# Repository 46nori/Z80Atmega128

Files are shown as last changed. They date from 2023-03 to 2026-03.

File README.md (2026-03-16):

# Z80ATmega128

[日本語版READMEはこちら](./README-ja.md)

## Overview

This project aims to build a Z80A system and run CP/M-80 natively on it.

You might be wondering why I chose the Z80 today. Well, it happened to be discovered in my collection of electronic components after being tucked away for 30 years. Moreover, it's an original Zilog Z80A from the NMOS process era, likely manufactured around 1980!  

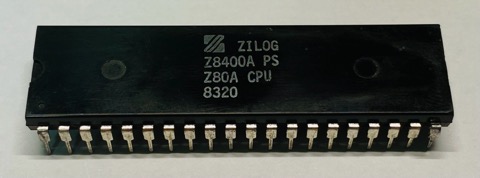
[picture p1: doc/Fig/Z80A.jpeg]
z80a
  

However, rather than simply replicating a single-board microcontroller system from the 1980s, I've decided to take a different approach. Reproducing such a system lacks novelty and excitement, not to mention the difficulty of sourcing the necessary parts.

Hence, I've devised the following design principles:

1. A hybrid configuration utilizing both [Z80A](https://www.zilog.com/docs/z80/um0080.pdf) and [ATmega128-16AU](https://www.microchip.com/en-us/product/ATmega128) (AVR) microcontrollers.
2. I won't be using ROM; instead, a 64KB SRAM will be shared between the Z80A and AVR. AVR will manage the placement of the Z80's bootstrap code.
3. AVR firmware will handle the Z80 hardware I/O and interrupt cycles completely. **Any Z80's I/O devices can, in principle, be described by software!**
4. Design circuits using components that are as easy to procure as possible. (As of 2023, mainly in the Japanese electronic parts market.)

## Achievements

* CP/M 2.2 works directly on the Z80 processor.
* The system can boot CP/M from a microSD card containing the CP/M image file.
* CP/M 3 (Non-banked memory version) works as well.
* You can enjoy playing the text adventure game ZORK I, II and III !
* The printed circuit board (PCB) is available.
* Demo Video  
  video (https://youtu.be/2_RJPk65XRE)

## Contents

```text
.
├── avr                      AVR firmware
├── z80                      Z80 software
│   ├── cpm22                CP/M-80 Ver2.2
│   │   ├── bios               BIOS
│   │   ├── sys                CPM.SYS(CCP/BDOS) and cpm.ihx(IPL+CCP/BDOS+BIOS)
│   │   └── image              CP/M 2.2 Disk image
│   └── cpm3                 CP/M 3 (CP/M Plus)
│       └── image              CP/M 3 Disk image
├── doc
│   ├── Hardware/            Hardware documents
│   ├── Software/            Software documents
│   └── README.md            Table of contents
└── schematics
    └── KiCad
        ├── *.kicad_sch      Schematic diagram
        └── *.kicad_pcb      PCB diagram
```

* [Document](doc/README.md)
  * [Z80ATmega128 Board Setup Guide](doc/SetupGuide_en.md)
  * [Hardware design document](doc/Hardware/Design.md)
* [Development log](doc/Diary.md)

## Required tools

* [Microchip Studio](https://www.microchip.com/en-us/tools-resources/develop/microchip-studio) for AVR v7.0 or later is required to build avr/.
* [AVRISP mkII](https://www.microchip.com/en-us/development-tool/ATAVRISP2) is required to program software(avr/) into ATmega128.
* Schematics and PCB are designed by [KiCad](https://www.kicad.org/) v7.0.
* [ASxxxx Cross Assemblers](https://shop-pdp.net/ashtml/asxxxx.php) to build the CP/M BIOS in z80/.
* [cpmtools](https://github.com/lipro-cpm4l/cpmtools) for creating CP/M disk images.

## Prototype

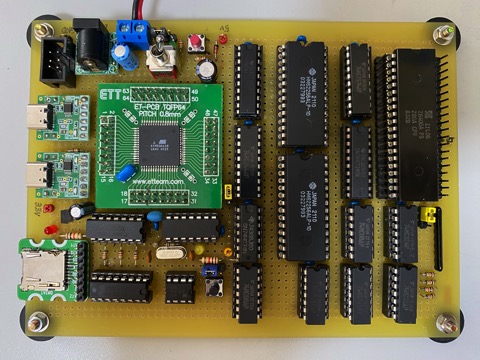
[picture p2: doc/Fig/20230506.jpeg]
prototype
  

## PCB

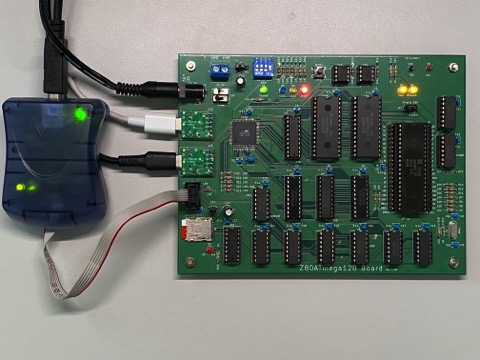
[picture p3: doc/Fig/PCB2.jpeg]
pcb2
    
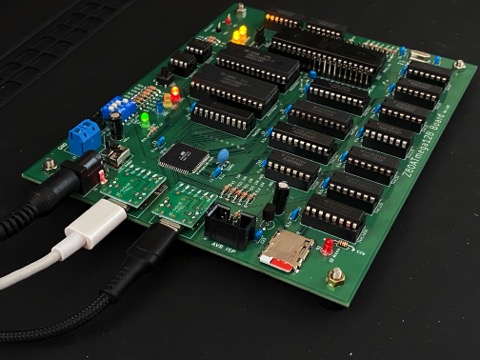
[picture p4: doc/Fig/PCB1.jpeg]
pcb1
    

## Schematic diagram

sch1
sch2
sch3
sch4

## License

GPLv3

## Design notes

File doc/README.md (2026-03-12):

# Documents

## User's Guide

- Z80ATmega128 Board Setup Guide ([English](./SetupGuide_en.md) / [Japanese](./SetupGuide.md))
- How to make CP/M2.2 disk image ([English](./DiskImage-CPM22.md) / [Japanese](./DiskImage-CPM22-ja.md))
- How to make CP/M3 (CP/M Plus) disk image ([English](../z80/cpm3/image/README.md) / [Japanese](../z80/cpm3/image/README-ja.md))
- ATmega128 Tiny Monitor Command Reference ([English](./Software/AVRTinyMonitor.md))

## Hardware Specifications

- Z80ATmega128 Board Hardware Specification ([Japanese](./Hardware/Design.md))
- Hardware Release Note ([English](./Hardware/HW-ReleaseNote.md) / [Japanese](./Hardware/HW-ReleaseNote-ja.md))

## Software Specifications

- Emulated external I/O device specification ([English](./Software/EmulatedDeviceSpec.md) / [Japanese](./Software/EmulatedDeviceSpec.md#port-japanese))
- CCP/M 2.2 BIOS design Spacification ([English](./Software/BIOSDesignSpec.md) / [Japanese](./Software/BIOSDesignSpec-ja.md))

## Design Memo

- CP/M DISK Parameters ([Japanese](./Software/DiskParameters.md))
- PCB Design memo of KiCad ([Japanese](./Hardware/PCB/KiCad-PCB.md))

## Developement Log (Japanese)

- [Summary of progress](./Progress.md)
- [2023/02/25 - 2023/07/04](./Diary.md)
- [2023/07/07 - 2023/10/22](./Diary2.md)
- [2023/10/23 - 2023/12/28](./Diary3.md)
- [2024/01/15 -](./Diary4.md)

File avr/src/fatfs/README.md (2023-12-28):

# FatFs - Generic FAT Filesystem Module
- http://elm-chan.org/fsw/ff/

## FatFs R0.15 w/patch3
- [ff15.zip](http://elm-chan.org/fsw/ff/arc/ff15.zip)
- [Patches](http://elm-chan.org/fsw/ff/patches.html)

## FatFs sample
Imported `mmc_avr.h` and `mmc_avr_spi.c` from [ffsample.zip](http://elm-chan.org/fsw/ff/ffsample.zip).

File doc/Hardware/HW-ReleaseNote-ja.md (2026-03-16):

# Hardware Release Note

----

## Rev 1.00

- Initial Release
- Errata
  - [Front Plane](./PCB/PCB1.0-FP-Errata.pdf)
    - Pattern cut 7
  - [Back Plane](./PCB/PCB1.0-BP-Errata.pdf)
    - Pattern cut 1
    - Patch 6

----

## Rev 2.00

### Schematics

- Z80ATmega128.kicad_sch
  - ATmega128に設定したラベルが、Z80のラベル`/WR`,`/RD`と衝突しており、PCB上で意図しない接続が発生していたため、以下のようにラベル名を変更。

    | PIN | Rev1.00| Rev2.00 |
    |:---:|--------|---------|
    |  33 |  /WR   | /AVR_WR |
    |  34 |  /RD   | /AVR_RD |
    |  43 |  ALE   | AVR_ALE |

- ExtIO_sch.kicad_sch
  - LED1/2/3のドライブ用素子(74HC32)の入力を10Kでプルアップ
  - /HALT,/BUSACKのドライブ用素子(74HC04, 74HC125)の入力を10Kでプルアップ
  - リセット時やATmega128のファームウェアが動作していないときの入力が不安定になるのを修正

### PCB

- R1(10K)の位置を変更。AVRICPの6pinボックスヘッダとのクリアランスが取れていなかったため。
- POWER Switch(2回路3接点トグルスイッチ)のランドピッチが間違っていたのを修正。
- USBシリアル変換基板(AE-CH340E-TYPEC)のFootprintを変更し、ピン配置を逆転させた。Rev1.00では変換基板を裏返しに設置していた。
- Errata
  - U18, U19のUARTのシルクが間違っている。
    - [誤]

      ```text
       o   o   o   o   o   o
          RX  TX  5V      GND
      ```

    - [正]

      ```text
       o   o   o   o   o   o
      GND     5V  TX  RX
      ```

----

## Rev 2.10

### PCB

- Rev 2.00のErrataの修正
- DIP SWの説明
  - SW3をSD CardのWrite Protectに割り当て
- 一部シルクを白抜き表示に変更

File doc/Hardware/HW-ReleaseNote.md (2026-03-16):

# Hardware Release Note

----

## Rev 1.00

- Initial Release
- Errata
  - [Front Plane](./PCB/PCB1.0-FP-Errata.pdf)
    - Pattern cut 7
  - [Back Plane](./PCB/PCB1.0-BP-Errata.pdf)
    - Pattern cut 1
    - Patch 6

----

## Rev 2.00

### Schematics

- Z80ATmega128.kicad_sch
  - The local labels `/WR`, `/RD` for ATmega128 conflicted with the Z80's `/WR`, `/RD`, causing unintended connections on the PCB, so the label name was changed as shown below.

    | PIN | Rev1.00| Rev2.00 |
    |:---:|--------|---------|
    |  33 |  /WR   | /AVR_WR |
    |  34 |  /RD   | /AVR_RD |
    |  43 |  ALE   | AVR_ALE |

- ExtIO_sch.kicad_sch
  - Pull up with 10K the input of 74HC32 for driving LED1/2/3.
  - Pull up with 10K the input of 74HC04 and 74HC125 for driving  LED /HALT and /BUSACK.
  - Fixed input being unstable at reset or when ATmega128 firmware is not running

### PCB

- Changed the position of R1(10K), because there are no space between the 6-pin box header of AVRICP and R1.
- Modified the land pitch of POWER Switch (2-circuit 3-contact toggle switch).
- Changed the footprint of USB serial converter board (AE-CH340E-TPPEC) and reversed the pin assignment.
- Errata
  - The silk printing of U18 and U19 are incorrect.
    - [Incorrect]

      ```text
       o   o   o   o   o   o
          RX  TX  5V      GND
      ```

    - [Correct]

      ```text
       o   o   o   o   o   o
      GND     5V  TX  RX
      ```

----

## Rev 2.10

### PCB

- Fixed Rev 2.00 Errata.
- Description of DIP SW.
  - Assigned SW3 to SD Card Write Protect.
- Changed some silk to white outline.

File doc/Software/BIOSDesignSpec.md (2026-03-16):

# CP/M BIOS Design Specification

## Overview

- 62KB BIOS
- Written in Z80 mnemonic
- Mode2 interrupt
- CON: is supported. LST:, PUN: and RDR: are not supported.
- DISK I/O
  - 5 drives (A: to E:) is supported.
  - Blocking and Deblocking is suppotred.

## Boot Sequence

AVR firmware behaves as below at power-on reset.

1. CP/M boot sequence is triggered if DIPSW-1 is ON and the microSD Card is mounted.
2. Read EntryAddress and Length from EEPROM. (1)
3. Set `JP EntryAddress` to 0x0000 of SRAM. (2)
4. Copy BIOS on EEPROM to EntryAddress. (3)
5. Resaet Z80.
6. Start TinyMonitor.

Z80 launches CP/M as follows:

1. Start BIOS.
2. BIOS BOOT routine requests DISK READ to AVR in order to download CCP+BDOS from EntryAddress.  
   AVR reads CCP+BDOS from Track 0 on the microSD Card and copies it to SRAM.
3. BIOS BOOT routine launches CCP.

boot

## BOOT and WBOOT

Both routine loads CP/M(CCP+BDOS) from A: using the DISK READ routine. If loading was a failure, then halt the system. The difference between BOOT and WBOOT is as follows.

### BOOT

- Called only at power-on reset.
- Z80 interrupt settings, Emulated I/O device initialization.
- Set initial drive to A:.
- Start CCP from CCP+3.

### WBOOT

- Restore the drive previously being utilized.
- Start CCP from CCP+0.

## DISK I/O

The logical tracks and sectors specified by BDOS are converted into absolute sector numbers. The definition of absolute sector is as follows.
`TRK` and `SEC` shall be set in advance with the BIOS calls `SETTRK` and `SETSEC`, respectively. Also, `SPT` is a value defined by DPB (Disk Parameter Block).

- Logical track number: `TRK`
- Logical sector number: `SCT`
- Number of sectors per logical track: `SPT`
- Absolute sector number: `AS` = TRK * SPT + SCT

A 512-byte buffer (`DMABUF`) is reserved on SRAM for data sharing with AVR and is used exclusively by `READ` and `WRITE` BIOS calls. Since the logical sector length of CP/M is 128 bytes, it supports Blocking/Deblocking for four sectors, that is, Blocking Factor=4.

### READ

When a READ request is received, it checks whether the specified sector exists in `DMABUF`.
If it exists, copy that sector to `DMA_ADRS`.
If it does not exist, request AVR to read 512 bytes. Copy the first 128 bytes (1 sector) to `DMA_ADRS`. The remaining three sectors are saved as a read-ahead cache.

### WRITE

Emulated DISK I/O on AVR allows writing to a disk image file by specifying an arbitrary address and data length. However, microSD cards require writing in 512-byte units from 512-byte sector boundaries, so if the boundaries do not match or the data length is not a multiple of 512, Read/Modify/Write is required.
This causes a noticeable write performance reduction, so the BIOS manages the timing of buffers and buffer flushes (write requests to AVR) to write 512 bytes from the 512-byte boundary as much as possible.

When a WRITE request is received, the data is copied to the `IDX` location defined below.

- Location of stored buffer: IDX = AS % 4

  ```text
        +----------+
  IDX=0 | 128bytes |
        +----------+
  IDX=1 | 128bytes |
        +----------+
  IDX=2 | 128bytes |
        +----------+
  IDX=3 | 128bytes |
        +----------+
  ```

If this is **the first** WRITE request after flushing the buffer, also remember `IDX` and `image file write destination address`. This will be used during the next buffer flush.

The caller of the WRITE request sets the following Deblocking Code in the C register.

- C = 0: deferred write
- C = 1: nondeferred write
- C = 2: deferred write to the first sector of a new data block

If any or both of the following conditions are met, flush the buffer. Otherwise, increment the number of cached sectors (0-3) and return.

- C=1
- IDX=3

When flushing the buffer, write `the number of cached sectors x 128 bytes` from the stored `IDX` to the `image file write destination address`.

### SELDSK

Emulated DISK I/O switches the accessed disk image to that of the specified drive.

### SETTRK

Just save the logical track number in `CURRENT_TRACK_NO`. It will be used in the next READ/WRITE.

### SETSEC

Just save the logical sector number in `CURRENT_SECTOR_NO`. It will be used in the next READ/WRITE.

### SERDMA

Just save the data transfer address in `DMA_ADRS`. It will be used in the next READ/WRITE.

### SECTRN

It is not supported since interleave is unnecessary for accessing microSD Cards.

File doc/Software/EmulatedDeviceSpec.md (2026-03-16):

# Emulated external I/O device specification

## Port (English)

| Port | Direction | Function | Value |
| ---- | --- | --- | --- |
| 0x00 | IN | Input single character from Console | Input character |
| 0x00 | OUT | Undefined | |
| 0x01 | IN | Get Console Input Buffer status | Unread characters count in Buffer |
| 0x01 | OUT | Undefined | |
| 0x02 | IN | Get Console Input Buffer size | Buffer size |
| 0x02 | OUT | Flush Console Input Buffer | |
| 0x03 | IN | Get Console input interrupt level | Interrupt level |
| 0x03 | OUT | Set Console input interrupt level | 0-127: Mode2 INT level<br>Other: No interrupt |
| 0x04 | IN | Undefined | |
| 0x04 | OUT | Undefined | |
| 0x05 | IN | Undefined | |
| 0x05 | OUT | Output single character to Console | Output character |
| 0x06 | IN | Get Console Output Buffer status | Remaining character count in Buffer  |
| 0x06 | OUT | Undefined | |
| 0x07 | IN | Get Console output Buffer size | Buffer size |
| 0x07 | OUT | Flush Console Output Buffer | |
| 0x08 | IN | Get Console Output interrupt level | Interrupt level |
| 0x08 | OUT | Set Console Output interrupt level | 0-127: Mode2 INT level<br>Other: No interrupt |
| 0x09 | IN | Undefined | |
| 0x09 | OUT | Undefined | |
| 0x0a | IN | Get selected DISK | Currently selected DISK number |
| 0x0a | OUT | Get Selected DISK status | 0: Success / 1: Error |
| 0x0b | IN | Get DISK WRITE Position | Physical WRITE position and reset sequencer |
| 0x0b | OUT | Set DISK WRITE Position | Physical WRITE position |
| 0x0c | IN | Get DISK WRITE Buffer address | Buffer address and reset sequencer |
| 0x0c | OUT | Set DISK WRITE Buffer address | Buffer address |
| 0x0d | IN | Get DISK WRITE Buffer length | Data length and reset sequencer |
| 0x0d | OUT | Set DISK WRITE Buffer length | Data length |
| 0x0e | IN | Get DISK WRITE status | Bit 0: Completed(0) / Writing(1)<br>Bit 1: Success(0) / Error(1) |
| 0x0e | OUT | Execute DISK WRITE | |
| 0x0f | IN | Get DISK WRITE interrupt level | Interrupt level |
| 0x0f | OUT | Set DISK WRITE interrupt level | 0-127: Mode2 INT level<br>Other: No interrupt |
| 0x10 | IN | Get DISK WRITE Position | Physical READ position and reset sequencer |
| 0x10 | OUT | Set DISK WRITE Position | Physical READ position |
| 0x11 | IN | Get DISK READ Buffer address | Buffer addreess and reset sequencer  |
| 0x11 | OUT | Set DISK READ Buffer address | Buffer addreess |
| 0x12 | IN | Get DISK READ Buffer length | Data length and reset sequencer |
| 0x12 | OUT | Set DISK READ Buffer length | Data length |
| 0x13 | IN | Get DISK READ status | Bit 0: Completed(0) / Reading(1)<br>Bit 1: Success(0) / Error(1) |
| 0x13 | OUT | Execute DISK READ | 0-127: Mode2 INT level<br>Other: No interrupt |
| 0x14 | IN | Get DISK READ interrupt level | Interrupt level |
| 0x14 | OUT | Set DISK READ interrupt level | 0-127: Mode2 INT level<br>Other: No interrupt |
| 0x15 | IN | Undefined | |
| 0x15 | OUT | Undefined | |
| 0x16 | IN | Undefined | |
| 0x16 | OUT | Undefined | |
| 0x17 | IN | Undefined | |
| 0x17 | OUT | Undefined | |
| 0x18 | IN | Undefined | |
| 0x18 | OUT | Undefined | |
| 0x19 | IN | Undefined | |
| 0x19 | OUT | Undefined | |
| 0x1a | IN | Undefined | |
| 0x1a | OUT | Undefined | |
| 0x1b | IN | Undefined | |
| 0x1b | OUT | Undefined | |
| 0x1c | IN | Undefined | |
| 0x1c | OUT | Undefined | |
| 0x1d | IN | Get interrupt level for resumption from the breakpoint | Interrupt level |
| 0x1d | OUT | Set interrupt level for resumption from the breakpoint | 0-127: Mode2 INT level<br>Other: No interrupt |
| 0x1e | IN | Reset sequencer | Reset sequencer and wait 1st byte |
| 0x1e | OUT | Send debug info | Send debug info(breakpoint, registers and stack data) |
| 0x1f | IN | Get LED Status | bit 0: LED0 OFF(0) / ON(1)<br>bit 1: LED1 OFF(0) / ON(1)<br>bit 2: LED2 OFF(0) / ON(1) |
| 0x1f | OUT | Set LED | bit 0: LED0 OFF(0) / ON(1)<br>bit 1: LED1 OFF(0) / ON(1)<br>bit 2: LED2 OFF(0) / ON(1) |

From 0x20 onwards, it becomes a shadow area for 0x00-0x1f.

---

## Port (Japanese)

|Port|Direction|Function|Value|
|:----|:----|:----|:----|
|0x00|IN |コンソール1文字入力|入力文字|
|0x00|OUT|未定義||
|0x01|IN |コンソール入力バッファステータス取得|未入力文字数|
|0x01|OUT|未定義||
|0x02|IN |コンソールバッファサイズ取得|バッファサイズ|
|0x02|OUT|コンソール入力バッファフラッシュ||
|0x03|IN |コンソール入力割り込みレベル取得|割り込みレベル|
|0x03|OUT|コンソール入力割り込みレベル設定|0-127: Mode2割り込みレベル<br>それ以外: 割り込み禁止|
|0x04|IN |未定義||
|0x04|OUT|未定義||
|0x05|IN |未定義||
|0x05|OUT|コンソール1文字出力|出力文字|
|0x06|IN |コンソール出力バッファステータス取得|未出力文字数|
|0x06|OUT|未定義||
|0x07|IN |コンソール出力バッファサイズ取得|バッファサイズ|
|0x07|OUT|コンソール出力バッファフラッシュ||
|0x08|IN |コンソール出力エンプティ割り込みレベル設定|0-127: Mode2割り込みレベル<br>それ以外: 割り込み禁止|
|0x08|OUT|コンソール出力エンプティ割り込みレベル取得|割り込みレベル|
|0x09|IN |未定義||
|0x09|OUT|未定義||
|0x0a|IN|DISK選択ステータス|成功(0) / エラー(1)|
|0x0a|OUT|DISK選択|0-15: DISK番号|
|0x0b|IN|DISKライト物理位置参照・シーケンサーリセット|ライト位置|
|0x0b|OUT|DISKライト物理位置指定|ライト位置|
|0x0c|IN|DISKライトバッファアドレス参照・シーケンサーリセット|バッファアドレス|
|0x0c|OUT|DISKライトバッファアドレス設定|バッファアドレス|
|0x0d|IN|DISKライトバッファ長参照・シーケンサーリセット|長さ|
|0x0d|OUT|DISKライトバッファ長設定|長さ|
|0x0e|IN|DISKライトステータス|Bit0: 完了(0) / ライト中(1)<br>Bit1: 成功(0) / エラー(1)|
|0x0e|OUT|DISKライト実行||
|0x0f|IN |DISKライト完了割り込みレベル設定|0-127: Mode2割り込みレベル<br>それ以外: 割り込み禁止|
|0x0f|OUT|DISKライト完了割り込みレベル取得|割り込みレベル|
|0x10|IN|DISKリード物理位置参照・シーケンサーリセット|リード位置|
|0x10|OUT|DISKリード物理位置指定|リード位置|
|0x11|IN|DISKリードバッファアドレス参照・シーケンサーリセット|バッファアドレス|
|0x11|OUT|DISKリードバッファアドレス設定|バッファアドレス|
|0x12|IN|DISKリードバッファ長参照・シーケンサーリセット|長さ|
|0x12|OUT|DISKリードバッファ長設定|長さ|
|0x13|IN|DISKリードステータス|Bit0: 完了(0) / リード中(1)<br>Bit1: 成功(0) / エラー(1)|
|0x13|OUT|DISKリード実行||
|0x14|IN |DISKリード完了割り込みレベル取得|割り込みレベル|
|0x14|OUT|DISKリード完了割り込みレベル設定|0-127: Mode2割り込みレベル<br>それ以外: 割り込み禁止|
|0x15|IN |未定義||
|0x15|OUT|未定義||
|0x16|IN |未定義||
|0x16|OUT|未定義||
|0x17|IN |未定義||
|0x17|OUT|未定義||
|0x18|IN |未定義||
|0x18|OUT|未定義||
|0x19|IN |未定義||
|0x19|OUT|未定義||
|0x1a|IN |未定義||
|0x1a|OUT|未定義||
|0x1b|IN |未定義||
|0x1b|OUT|未定義||
|0x1c|IN |未定義||
|0x1c|OUT|未定義||
|0x1d|IN|ブレークポイント復帰割り込みレベル取得|割り込みレベル|
|0x1d|OUT|ブレークポイント復帰割り込みレベル設定|0-127: Mode2割り込みレベル<br>それ以外: 割り込み禁止|
|0x1e|IN|デバッグ情報通知シーケンスリセット|シーケンサーをリセットする。|
|0x1e|OUT|デバッグ情報通知|デバッグ情報(ブレークアドレス/Z80レジスタ/スタックデータ)の通知。デバッグ領域の値を逆順に送る。|
|0x1f|IN |LED点灯状態取得| bit 0: LED0 OFF(0) / ON(1)<br>bit 1: LED1 OFF(0) / ON(1)<br>bit 2: LED2 OFF(0) / ON(1) |
|0x1f|OUT|LED点灯設定| bit 0: LED0 OFF(0) / ON(1)<br>bit 1: LED1 OFF(0) / ON(1)<br>bit 2: LED2 OFF(0) / ON(1) |

- 0x20以降は0x00-0x1fのシャドウエリアとなる。
- 複数バイトが設定できるPORTはシーケンサーを持つ。値をセットする前にシーケンサーをリセットすること。

## Console I/O

### Console Input

AVRはUART1の入力をリングバッファに値を保存しており、Z80からの1文字入力要求があると、このバッファから値を返す。
割り込み設定を行うことで、リングバッファに文字がキューイングされると同時にZ80に割り込みをかけることができる。

- PORT 0x00 コンソール1文字入力
  - **[IN]** バッファリングされている文字を返す。バッファが空の場合は0x00を返す。
- PORT 0x01 コンソール入力バッファステータス取得
  - **[IN]** 入力バッファに残っている文字数を返す。
- PORT 0x02 コンソールバッファサイズ取得
  - **[IN]** 入力バッファのサイズを返す。
- PORT 0x02 コンソール入力バッファフラッシュ
  - **[OUT]** 入力バッファを空にする。
- PORT 0x03 コンソール入力割り込み設定
  - **[OUT]** コンソール入力発生時にZ80にMode2割り込みをかけることができる。0-127を設定するとそのレベルでの割り込みが発生する。128-255に設定すると割り込みは発生しない。デフォルト値は128。
  - **[IN]** 現在の割り込みレベルの値を返す。

### Console Output

- PORT 0x05 コンソール1文字出力
  - **[OUT]** 文字する出力をセットする。
- PORT 0x06 コンソール出力バッファステータス取得
  - **[IN]** まだ出力されずバッファに残っている文字数を返す。
- PORT 0x07
  - **[IN]** 出力バッファのサイズを返す。
  - **[OUT]** 出力バッファを空にする。
- PORT 0x08 コンソール出力割り込み設定
  - **[OUT]** 出力バッファが以下の状態になった時にZ80にMode2割り込みをかけることができる。0-127を設定するとそのレベルでの割り込みが発生する。128-255に設定すると割り込みは発生しない。デフォルト値は128。
    - 未出力データ数が出力バッファサイズの1/2に達した
    - 未出力データ数が出力バッファサイズの1/4に達した
    - 未出力データ数が0になった
  - **[IN]** 現在の割り込みレベルの値を返す。

## DISK I/O

### DISK選択

- PORT 0x0a DISK選択
  - **[IN]** DISK選択結果　成功(0) / エラー(1)
  - **[OUT]** DISK番号(0-15)を選択しアクセス可能にする。指定したDISK番号のイメージファイルDISKxx.IMG (xxはDISK番号)があらかじめ存在していること。

### DISK WRITE

- PORT 0x0b
  - **[IN]** DISKライト位置参照・シーケンサーリセット
  - **[OUT]** DISKライト位置を指定する。Highアドレスの値から4バイト書き込む。
- PORT 0x0c
  - **[IN]** DISKライトバッファアドレス参照・シーケンサーリセット
  - **[OUT]** DISKライトバッファアドレスを指定する。Highアドレスから2バイト書き込む。
- PORT 0x0d
  - **[IN]** DISKライトバッファ長参照・シーケンサーリセット
  - **[OUT]** DISKライトバッファ長を指定する。Highアドレスから2バイト書き込む。
- PORT 0x0e
  - **[OUT]** DISKライト実行
  - **[IN]** DISKライト状態を返す。
    - Bit0: 完了(0) / 実行中(1)
    - Bit1: 成功(0) / エラー(1)
- PORT 0x0f　DISKライト完了割り込み設定
  - **[OUT]** DISKライト完了時にZ80にMode2割り込みをかけることができる。0-127を設定するとそのレベルでの割り込みが発生する。128-255に設定すると割り込みは発生しない。デフォルト値は128。

### DISK READ

- PORT 0x10
  - **[OUT]** DISKリード位置を指定する。Highアドレスから4バイト書き込む。
  - **[IN]** DISKリード位置参照・シーケンサーリセット
- PORT 0x11
  - **[OUT]** DISKリードバッファアドレスを指定する。Highアドレスから2バイト書き込む。
  - **[IN]** DISKリードバッファアドレス参照・シーケンサーリセット
- PORT 0x12
  - **[OUT]** DISKリードバッファ長を指定する。Highアドレスから2バイト書き込む。
  - **[IN]** DISKリードバッファ長参照・シーケンサーリセット
- PORT 0x13
  - **[OUT]** DISKリード実行
  - **[IN]** DISKリード状態を返す。
    - Bit0: 完了(0) / 実行中(1)
    - Bit1: 成功(0) / エラー(1)
- PORT 0x14 DISKリード完了割り込み設定
  - **[OUT]** DISKリード完了時にZ80にMode2割り込みをかけることができる。0-127を設定するとそのレベルでの割り込みが発生する。128-255に設定すると割り込みは発生しない。デフォルト値は128。
  - **[IN]** 現在の割り込みレベルの値を返す。

DISK READ/WRITEの起動はOUT命令の割り込みハンドラで受理される。その起動イベントをREQとする。この割り込みハンドラ内では外部SRAMへのアクセスができないため、SD Cardのアクセスは実行しない。(外部SRAMのアクセスには/BUSREQを有効にする必要があるが、割り込みサイクルでの処理は両立できない。) SD CardへのアクセスおよびSRAMとのデータ転送は、10msの周期割り込みハンドラ内で行う。ここではREAD/WRITE用のステートマシンが順番に実行される。READとWRITEは同時に実行されることはない。

rd.DOINGおよびwr.DOINGでSD CardのアクセスとSRAMとのデータ転送が行われる。エラーでも正常終了でもIDLEに戻る(DONEイベント)。
リードライト要求は、IDLEおよびREJECTED状態で受理される。

- イベント

    |Event| READ          | WRITE          |
    |-----|---------------|----------------|
    | REQ | READ実行(0x13) | WRITE実行(0x0e)|
    | DONE| READ完了       | WRITE完了      |
    | INT | 周期割り込み    | 周期割り込み     |

- 状態

    |State     | READ                    | WRITE 　　　　　　　　　　　|
    |----------|-------------------------|-------------------------|
    |IDLE      | READ要求待ち。           | WRITE要求待ち。            |
    |REQUESTING| READ実行待ち。           | WRITE実行待ち。            |
    |DOING     | READ実行中。             | WRITE実行中。             |
    |REJECTED  | 要求拒否。次のREAD要求待ち。| 要求拒否。次のWRITE要求待ち。|

- ステートチャート

    ```mermaid
    stateDiagram-v2
        state READ {
            [*]            --> rd.IDLE
            rd.IDLE　      --> rd.REQUESTING: REQ
            rd.IDLE　      --> rd.IDLE: INT
            rd.REQUESTING  --> rd.DOING : INT
            rd.REQUESTING  --> rd.REJECTED : REQ
            rd.REQUESTING  --> rd.REQUESTING : INT
            rd.DOING       --> rd.REJECTED : REQ
            rd.DOING       --> rd.DOING : INT
            rd.DOING       --> rd.IDLE : DONE
            rd.REJECTED    --> rd.REJECTED : INT
            rd.REJECTED    --> rd.DOING : REQ
        }

        state WRITE {
            [*]         --> wr.IDLE
            wr.IDLE        --> wr.REQUESTING: REQ
            wr.IDLE　      --> wr.IDLE: INT
            wr.REQUESTING  --> wr.DOING : INT
            wr.REQUESTING  --> wr.REJECTED : REQ
            wr.REQUESTING  --> wr.REQUESTING : INT
            wr.DOING       --> wr.REJECTED : REQ
            wr.DOING       --> wr.DOING : INT
            wr.DOING       --> wr.IDLE : DONE
            wr.REJECTED    --> wr.REJECTED : INT
            wr.REJECTED    --> wr.DOING : REQ
        }
    ```

## Debug

Z80のデバッグを支援する機能。

以下のようなステップで、ブレークポイント機能を実現できる。
Z80側の実装例は[CP/M 2.2のBIOS](../../z80/cpm22/bios/bios.asm)の`DEBUGGER:`を参照。

1. ブレークポイントの設定: Z80のメモリ空間上でブレークさせたいアドレスに、AVRから0xff(RST7)を書き込んでおく。
2. ブレークポイントに到達すると、RST7割り込みが発生する。割り込みハンドラではデバッグ情報を退避し、Debugポートにそれらを転送する。Z80はHALT命令で実行を停止しておく。
3. AVRは受け取ったデバッグ情報を表示する。
4. AVRで以前の命令をブレークポイントに書き戻し、外部割り込み(INT4)を与えることで実行を継続できる。

デバッグ情報は以下の順に0x1eに出力すること。

1.  ブレークポイントアドレス (High)
2.  ブレークポイントアドレス (Low)
3.  レジスタ SP (High)
4.  レジスタ SP (Low)
5.  レジスタ IY (High)
6.  レジスタ IY (Low)
7.  レジスタ IX (High)
8.  レジスタ IX (Low)
9.  レジスタ I
10. レジスタ H
11. レジスタ L
12. レジスタ D
13. レジスタ E
14. レジスタ B
15. レジスタ C
16. レジスタ A
17. レジスタ F
18. レジスタ A'
19. レジスタ F'
20. レジスタ H'
21. レジスタ L'
22. レジスタ D'
23. レジスタ E'
24. レジスタ B'
25. レジスタ C'
26. SP + 0 のアドレスの値
27. SP + 1 のアドレスの値
28. SP + 2 のアドレスの値
29. SP + 3 のアドレスの値
30. SP + 4 のアドレスの値
31. SP + 5 のアドレスの値

- Port 0x1d
  - **[IN]** ブレークポイント復帰割り込みレベル取得
  - **[OUT]** ブレークポイント復帰割り込みレベル設定
- Port 0x1e
  - **[IN]** デバッグ情報通知シーケンスリセット
  - **[OUT]** デバッグ情報(ブレークアドレス/Z80レジスタ/スタックデータ)の通知。デバッグ領域の値を逆順に送る。

## LED

LEDの点灯制御。0x1fに出力した下位3bitのLED設定は、AVRで10msごとにサンプル・反映される。

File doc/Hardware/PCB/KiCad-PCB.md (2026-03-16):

# KiCadによるPCBの製作

## 全体の流れ

### 1. 回路図の作成

1. 回路図エディタで回路を作成。
2. `ツール > 回路図をアノテーション`で部品のリファレンス番号をリセットする。
3. `検査 > エレクトリカル ルール チェッカー(ERC)`でエラーがないことを確認する。
4. `ツール > フットプリントを割り当て`で、部品のフットプリントをすべて定義する。

### 2. PCBの作成

1. 回路図エディタの`ツール > 回路図から基板を更新`でPCBを生成。フットプリントが不足している場合は定義する。
2. PCBエディタの`検査 > デザインルール チェッカー(DRC)`でエラーがないことを確認する。
3. 部品の位置決め
   - フットプリントを配置する。
   - おおよその位置が決まったら基板外形を決め、以後は、この中に収まるように作業する。
4. 基板設定
5. ベタの設定
   - In2.CuをVCCに、F.CU, In1.Cu, B.CuをGNDベタに設定する。
6. 手配線
   - 電源、パスコンなど自動配線だと支障があるものは手配線する。ロックしておくと良い。
   - シルクの文字の調整
7. 自動配線
   - Freeroutingのプラグインを使用。
   - それなりに賢く配線してくれるが、気に食わないところは手配線で直す。
8. DRCで確認。問題があれば4,5, 6に戻る。
    - 基本、これを何度も繰り返す。
    - 回路図の修正が必要になることもある。この場合は基板への反映を忘れないこと。
9. GNDビア打ち
    - 配線が完成し、もう大修正を行わないことが前提。
    - GNDの貫通ビアを打ってGNDのインピーダンスを下げる。

### 3. 基板メーカーへの発注

1. `ファイル > 製造用出力 > ガーバー` : ガーバーデータ出力
2. `ファイル > 製造用出力 > ドリル出力` : ドリルデータ出力
3. 1, 2を.zipで固めてPCBメーカーに発注

## はじめにやっておくこと

### 自動配線の設定

- `プラグイン&コンテンツ マネージャー`でFreeroutingプラグインをインストールする。

### ユーザーグリッドの設定

- 0.1mmのグリッドを定義しておく。基板外形やネジ位置などmm指定したい場合、この設定に切り替えると作業がしやすい。
- フットプリントや配線作業ではmilに切り替えて作業する。

## 各種設定の詳細

### 基板の設定

`ファイル > 基板の設定`

- `物理スタックアップ`
  - `導体レイヤー`で4層基板に設定
  - 使用するレイヤー

    | レイヤー      | 用途         |
    | ------------ | ----------- |
    | F.Cu         | 表面 配線     |
    | In1.Cu       | ベタ配線(GND) |
    | In2.Cu       | ベタ配線(VCC) |
    | B.Cu         | 裏面 配線     |
    | F.Silkscreed | 表面シルク    |
    | B.Silkscreed | 裏面シルク    |
    | Edge.Cuts    | 基板の外形定義 |
    | User.Drawings| 基板の外形寸法 |

- `デザインルール＞制約`
  - 最小クリアランス: 0.1524 (6mil)
  - 最小配線幅: 0.2mm
  - 最小アニューラ幅: 0.2mm
  - 最小ビア直径: 0.4mm
  - 導体から穴のクリアランス: 0.25mm
  - 導体から基板端クリアランス: 1mm
  - 最小スルーホール: 0.3mm
  - 穴から穴へのクリアランス: 0.25mm
  - 最小サーマルリーフスポーク数: 1  
    デフォルトは2。ベタのGND接続がスポーク1本で繋がってしまう場合が結構あり、以下のエラーが発生する。

    ```text
    エラー: ゾーンへのサーマルリーフ接続が不完全...塗りつぶし方法の制約 最小スポーク数: 2; 現状1)
    ```

### 基板外形の設定

- Edge.Cutsレイヤに基板の外形を描く。
- ネジ穴の配置
  - 銅箔付きのM3のPadを選択 `MountingHole_3mm_M3_ISO7380_Pad`
  - 周辺の領域をキープアウトに設定し、VCCレイヤーでベタ塗りを禁止する。

### ベタの設定

- 設定
  `配置 > 塗りつぶしゾーンを追加`で、ベタを設定する領域を指定する。複数のレイヤーがまとめて指定できるので、ベタGNDの設定はこれが便利。
- 除外
  - `ルールアウト(キープアウト)を追加`で、ベタを設定しない領域を指定できる。
- 一時的な削除
  - DRCをかけるとデフォルトでベタを生成してくれるが、配線や目視チェックで邪魔になるので、一時的にベタを着したい場合がある。
  - `編集 > 全てのゾーンの塗りつぶしを削除`で消える。

### パスコンの配線

- パスコンからICのVCCに直接接続しないと意味がない。しかしVCCのベタを設定すると勝手に配線されてしまう。これを避けるため、ICのVCC端子周辺にベータのキープアウトエリアを配置する。ICのVCC端子は表面または裏面層でパスコンに接続する。

### 配線のやり直し

- 自動配線をやり直したい場合がある。配線を全消しすることもできるが、手配線は残したい。`編集>広域削除`で削除したいものを選択する。残しておきたい要素はロックをかけ、それ以外のものを削除するようにすると手戻りを減らせる。

### GNDビア

- 10mm程度の間隔で打つ
- 基板端にぐるっと等間隔に打つ
- 島になっているところはアンテナになるので、端に打って解放端の島にしない。
- まんべんなく打つ

### ティアドロップ

- `ツール > ティアドロップの追加`
- KiCad V7から入った機能。ビアやランドの付け根に涙のようなランドが付加される。

### 製造データ

- ドリルの原点の設定
  - `配置 > ドリル/配置ファイルの原点`で、基板左下に原点をセットする。
- ガーバー出力
  - `ドリル/配置ファイルの原点を使用`にチェックする。
- ドリル出力
  - `ドリル単位`を`mm`にする。

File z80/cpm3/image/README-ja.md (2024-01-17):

# CP/M 3 on Z80ATmega128 Board
## 概要
CP/M 3はCP/M 2.2から起動させることができる。  
ただしZ80ATmega128 Boardは64KBのメモリしかないため、Non bank memory版CP/M 3として動作する。このドキュメントでは、その仕組みと必要なファイルの生成方法、および起動方法について説明する。

### 起動の仕組み
システムディスク(A:)のイメージはCP/M2.2と同等で、ディレクトリには以下のファイルが存在することを前提としている。
- CPM3.SYS : CP/M 3のBDOSとBIOS
- CPMLDR.COM : CPM3.SYSのLOADER
- CCP.COM : トランジェントコマンド化されたCP/M 3のCCP
```
        +------------+
Track 0 | CPM2.SYS   |
        |------------|
Track 1 |    ...     |
        | CPMLDR.COM |
  ...   | CPM3.SYS   |
        | CCP.COM    |
        |    ...     |
        +------------+
```
起動は以下の手順
1. `z80/cpm2`で構築したCP/M2.2でシステム起動。
2. コマンドラインから`CPMLDR.COM`を実行。
3. `CPM3.SYS`がロード・実行される。ここからCP/M 3の世界に移行。
4. `CCP.COM`がロード・実行される。

`CPMLDR.COM`と`CPM3.SYS`は、CP/M 2.2上でアセンブル、リンクして生成する。(生成方法は後述。)  
以下のメモリマップになるように構成されている。
### メモリマップ
```
       CP/M 2.2           CP/M 3
0000H +--------+         +--------+
0100H |--------|         |--------|
      |  TPA   |         |  TPA   |  
      | (55K)  |         | (52K)  |
      |        |   D000H |--------|
DC00H |--------|         |        |
      |  CCP   |         | BDOS3  |
      | (800H) |         | (1D00H)|
E400H |--------|         |        |
      | BODS2  |   ED00H |--------|
      | (800H) |         | BIOS3  |
      |        |         | (400H) |
F200H |--------| - - - - |--------|
      | BIOS2  |         | BIOS2  |
      | (E00H) |         | (E00H) |
FFFFH +--------+ - - - - +--------+
```
BIOS3は、CP/M 2.2のBIOS2をそのまま使用する。

## イメージの作成方法
1. `z80/cpm3/image`で`make`を実行。  
    `DISK00.IMG`が生成される。CP/M2.2の起動DISKになっており、CP/M 3を生成するのに必要なファイル群と、CP/M 3のトランジェントコマンドが含まれる。(ただしSUBMIT.COMは2.2のものなので注意)
2. `DISK00.IMG`をmicroSD Cardにコピーしシステムを起動する。
3. CP/M 2.2が立ち上がる。
4. バッチファイル`GEN.SUB`を実行すると、`CPMLDR.COM`と`CPM3.SYS`が生成される。  
   `GENCPM.COM`でパラメータ入力を促されるので以下の通り入力。(パラメータの詳細は[こちら](#gencpmcomによるcpm3sysの構成))
    ```
    A>submit gen

    Reload CCP+BDOS.

    A>RMAC LDRBIOS
    CP/M RMAC ASSEM 1.1
    0084
    006H USE FACTOR
    END OF ASSEMBLY

    Reload CCP+BDOS.

    A>LINK CPMLDR,SCB,LDRBIOS
    LINK 1.3

    @CIVEC   FE22   @COVEC   FE24   @AIVEC   FE26   @AOVEC   FE28
    @LOVEC   FE2A   @BNKBF   FE35   @CRDMA   FE3C   @CRDSK   FE3E
    @FX      FE43   @RESEL   FE41   @VINFO   FE3F   @USRCD   FE44
    @ERMDE   FE4B   @DATE    FE58   @HOUR    FE5A   @MIN     FE5B
    @SEC     FE5C   @MXTPA   FE62

    ABSOLUTE     0000
    CODE SIZE    0BEA (0100-0CE9)
    DATA SIZE    0084 (0CEA-0D6D)
    COMMON SIZE  0000
    USE FACTOR     23

    Reload CCP+BDOS.

    A>RMAC GBIOS
    CP/M RMAC ASSEM 1.1
    0144
    006H USE FACTOR
    END OF ASSEMBLY

    Reload CCP+BDOS.

    A>LINK BIOS3[OS]=GBIOS,SCB
    LINK 1.3

    @CIVEC   FE22   @COVEC   FE24   @AOVEC   FE28   @LOVEC   FE2A
    @BNKBF   FE35   @CRDMA   FE3C   @CRDSK   FE3E   @FX      FE43
    @RESEL   FE41   @VINFO   FE3F   @USRCD   FE44   @ERMDE   FE4B
    @DATE    FE58   @HOUR    FE5A   @MIN     FE5B   @SEC     FE5C
    @MXTPA   FE62   @AIVEC   FE26

    ABSOLUTE     0000
    CODE SIZE    01D3 (0000-01D2)
    DATA SIZE    0144 (01D3-0316)
    COMMON SIZE  0000
    USE FACTOR     05

    Reload CCP+BDOS.

    A>GENCPM

    CP/M 3.0 System Generation
    Copyright (C) 1982, Digital Research

    Default entries are shown in (parens).
    Default base is Hex, precede entry with # for decimal

    Create a new GENCPM.DAT file (N) ?

    Display Load Map at Cold Boot (Y) ?

    Number of console columns (#80) ?
    Number of lines in console page (#24) ?
    Backspace echoes erased character (N) ?
    Rubout echoes erased character (Y) ?

    Initial default drive (A:) ?

    Top page of memory (FF) ? F0
    Bank switched memory (Y) ? N

    Double allocation vectors (Y) ?

    Accept new system definition (Y) ?

    BIOS3    SPR  ED00H  0400H
    BDOS3    SPR  CE00H  1F00H

    *** CP/M 3.0 SYSTEM GENERATION DONE ***
    ```

## CP/M 3の起動方法
```
A>cpmldr

CP/M V3.0 Loader
Copyright (C) 1982, Digital Research

 BIOS3    SPR  EE00  0400
 BDOS3    SPR  D100  1D00

 52K TPA

A>
```

-----
## 詳細
`CPMLDR.COM`と`CPM3.SYS`の生成は、Makefileにより自動化されているが、ここではその詳細を解説する。

### CPMLDR.COMの生成
* LDRBIOS.ASM の変更  
  [メモリマップ](#メモリマップ)の構成になるよう`bios`のみ変更する。(元の値は`0e900h`)  
  `CPMLDR.COM`は`CPM3.SYS`をロードするためだけに使われるので、`drives`は2のままで構わない。
  ```
  drives	equ	2		;number of drives supported
  bios	equ	0f200h		;address of your bios
  ```

* LDRBIOS.RELの生成
   ```
  C>rmac ldrbios.asm
  CP/M RMAC ASSEM 1.1
  0084
  006H USE FACTOR
  END OF ASSEMBLY
  ```

* CPMLDR.COMの生成  
  `LDRBIOS.REL`から`CPMLDR.COM`を生成する。  
  `CPMLDR.REL`と`SCB.REL`はCP/M 3で提供される。
    ```
    C>link cpmldr,scb,ldrbios
    LINK 1.3

    @CIVEC   FE22   @COVEC   FE24   @AIVEC   FE26   @AOVEC   FE28
    @LOVEC   FE2A   @BNKBF   FE35   @CRDMA   FE3C   @CRDSK   FE3E
    @FX      FE43   @RESEL   FE41   @VINFO   FE3F   @USRCD   FE44
    @ERMDE   FE4B   @DATE    FE58   @HOUR    FE5A   @MIN     FE5B
    @SEC     FE5C   @MXTPA   FE62

    ABSOLUTE     0000
    CODE SIZE    0BEA (0100-0CE9)
    DATA SIZE    0084 (0CEA-0D6D)
    COMMON SIZE  0000
    USE FACTOR     23
    ```

### CPM3.SYSの生成
`GENCPM.COM`を使用して生成する。以下のファイルが必要。
- `BDOS3.SPR` : CP/M 3で提供される
- `BIOS3.REL` : このステップで生成する

#### `BIOS3.REL`の生成
1. GBIOS.ASMの修正  
  62K CP/M 2.2のBIOSをそのまま使用する。BIOS2の先頭アドレスは`F200H`である。([メモリマップ](#メモリマップ)参照)  
  また5台のドライブ(A:-E:)をサポートしている。  
  たまたま同じ設定なので修正不要のはずだが、もしも異なっている場合は以下のように設定する。
    ```
    drives	equ	5		;number of drives supported
    bios	equ	0f200h		;address of your bios
    ```
2. アセンブル
    ```
    C>rmac gbios
    CP/M RMAC ASSEM 1.1
    0144
    006H USE FACTOR
    END OF ASSEMBLY
    ```
3. リンク  
  `SCB.REL`はCP/M 3で提供されるものをそのまま使用する。
    ```
    C>link bios3[os]=gbios,scb
    LINK 1.3

    @CIVEC   FE22   @COVEC   FE24   @AOVEC   FE28   @LOVEC   FE2A
    @BNKBF   FE35   @CRDMA   FE3C   @CRDSK   FE3E   @FX      FE43
    @RESEL   FE41   @VINFO   FE3F   @USRCD   FE44   @ERMDE   FE4B
    @DATE    FE58   @HOUR    FE5A   @MIN     FE5B   @SEC     FE5C
    @MXTPA   FE62   @AIVEC   FE26

    ABSOLUTE     0000
    CODE SIZE    01D3 (0000-01D2)
    DATA SIZE    0144 (01D3-0316)
    COMMON SIZE  0000
    USE FACTOR     05
    ```

#### GENCPM.COMによるCPM3.SYSの構成
[メモリマップ](#メモリマップ)に合うように、`GENCPM.COM`のパラメータを以下のように設定する。  
Top page of memoryは512byte単位でしか指定できない。
```
C>gencpm

CP/M 3.0 System Generation
Copyright (C) 1982, Digital Research

Default entries are shown in (parens).
Default base is Hex, precede entry with # for decimal

Create a new GENCPM.DAT file (N) ?         設定を保存するか?

Display Load Map at Cold Boot (Y) ?

Number of console columns (#80) ?          コンソールの設定
Number of lines in console page (#24) ?
Backspace echoes erased character (N) ?
Rubout echoes erased character (Y) ?

Initial default drive (A:) ?               デフォルトドライブ

Top page of memory (FF) ? F0               メモリアロケーション(512byte単位)
Bank switched memory (Y) ? N               Non bank memory

Accept new system definition (Y) ?

 BIOS3    SPR  ED00H  0400H
 BDOS3    SPR  D000H  1D00H

*** CP/M 3.0 SYSTEM GENERATION DONE ***
```

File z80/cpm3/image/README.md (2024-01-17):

# CP/M 3 on Z80ATmega128 Board
## Overview
It is able to make CP/M 3 work on CP/M 2.2 system.
However, due to its limited 64KB of memory, it works as the non-bank memory version of CP/M 3. This document provides an explanation of its operation, instructions on generating the required files, and guidance on initiating the system.

### How it works
It is assumed that the image of the system disk (A:) is equivalent to CP/M2.2, and that the following files exist in the directory.
- `CPM3.SYS` : CP/M 3 BDOS and BIOS
- `CPMLDR.COM` : CPM3.SYS Loader
- `CCP.COM` : CCP as a Transient command
```
        +------------+
Track 0 | CPM2.SYS   |
        |------------|
Track 1 |    ...     |
        | CPMLDR.COM |
  ...   | CPM3.SYS   |
        | CCP.COM    |
        |    ...     |
        +------------+
```
Initiation steps for CP/M 3
1. Boot CP/M2.2 built according with `z80/cpm2`.
2. Execute `CPMLDR.COM` from the command line.
3. `CPM3.SYS` is loaded and executed. (From here, CP/M 3 is working.)
4. `CCP.COM` is loaded and executed.

`CPMLDR.COM` and `CPM3.SYS` are generated on the CP/M 2.2 system. (The procedure is explained later.)  
The memory map is configured as shown below.
### Memory Map
```
       CP/M 2.2           CP/M 3
0000H +--------+         +--------+
0100H |--------|         |--------|
      |  TPA   |         |  TPA   |  
      | (55K)  |         | (52K)  |
      |        |   D000H |--------|
DC00H |--------|         |        |
      |  CCP   |         | BDOS3  |
      | (800H) |         | (1D00H)|
E400H |--------|         |        |
      | BODS2  |   ED00H |--------|
      | (800H) |         | BIOS3  |
      |        |         | (400H) |
F200H |--------| - - - - |--------|
      | BIOS2  |         | BIOS2  |
      | (E00H) |         | (E00H) |
FFFFH +--------+ - - - - +--------+
```
BIOS3 reuses BIOS2 of CP/M 2.2 as is.

## How to create a DISK image
1. Execute `make` on `z80/cpm3/image`.
     `DISK00.IMG` will be generated. This system disk for CP/M 2.2 includes the files necessary to generate CP/M 3 and the CP/M 3 transient commands. (However, please note that SUBMIT.COM is of CP/M 2.2's, not CP/M 3's.)
2. Copy `DISK00.IMG` to the microSD Card and boot the system.
3. CP/M 2.2 starts up.
4. Execute batch file `GEN.SUB` so that  `CPMLDR.COM` and `CP/M3.SYS` are generated.
    You will be prompted to enter parameters on `GENCPM.COM`, so enter them as follows.(See [here](#gencpmcomによるcpm3sysの構成) in details of parametrs)
    ```
    A>submit gen

    Reload CCP+BDOS.

    A>RMAC LDRBIOS
    CP/M RMAC ASSEM 1.1
    0084
    006H USE FACTOR
    END OF ASSEMBLY

    Reload CCP+BDOS.

    A>LINK CPMLDR,SCB,LDRBIOS
    LINK 1.3

    @CIVEC   FE22   @COVEC   FE24   @AIVEC   FE26   @AOVEC   FE28
    @LOVEC   FE2A   @BNKBF   FE35   @CRDMA   FE3C   @CRDSK   FE3E
    @FX      FE43   @RESEL   FE41   @VINFO   FE3F   @USRCD   FE44
    @ERMDE   FE4B   @DATE    FE58   @HOUR    FE5A   @MIN     FE5B
    @SEC     FE5C   @MXTPA   FE62

    ABSOLUTE     0000
    CODE SIZE    0BEA (0100-0CE9)
    DATA SIZE    0084 (0CEA-0D6D)
    COMMON SIZE  0000
    USE FACTOR     23

    Reload CCP+BDOS.

    A>RMAC GBIOS
    CP/M RMAC ASSEM 1.1
    0144
    006H USE FACTOR
    END OF ASSEMBLY

    Reload CCP+BDOS.

    A>LINK BIOS3[OS]=GBIOS,SCB
    LINK 1.3

    @CIVEC   FE22   @COVEC   FE24   @AOVEC   FE28   @LOVEC   FE2A
    @BNKBF   FE35   @CRDMA   FE3C   @CRDSK   FE3E   @FX      FE43
    @RESEL   FE41   @VINFO   FE3F   @USRCD   FE44   @ERMDE   FE4B
    @DATE    FE58   @HOUR    FE5A   @MIN     FE5B   @SEC     FE5C
    @MXTPA   FE62   @AIVEC   FE26

    ABSOLUTE     0000
    CODE SIZE    01D3 (0000-01D2)
    DATA SIZE    0144 (01D3-0316)
    COMMON SIZE  0000
    USE FACTOR     05

    Reload CCP+BDOS.

    A>GENCPM

    CP/M 3.0 System Generation
    Copyright (C) 1982, Digital Research

    Default entries are shown in (parens).
    Default base is Hex, precede entry with # for decimal

    Create a new GENCPM.DAT file (N) ?

    Display Load Map at Cold Boot (Y) ?

    Number of console columns (#80) ?
    Number of lines in console page (#24) ?
    Backspace echoes erased character (N) ?
    Rubout echoes erased character (Y) ?

    Initial default drive (A:) ?

    Top page of memory (FF) ? F0
    Bank switched memory (Y) ? N

    Double allocation vectors (Y) ?

    Accept new system definition (Y) ?

    BIOS3    SPR  ED00H  0400H
    BDOS3    SPR  CE00H  1F00H

    *** CP/M 3.0 SYSTEM GENERATION DONE ***
    ```

## How to launch CP/M 3
```
A>cpmldr

CP/M V3.0 Loader
Copyright (C) 1982, Digital Research

 BIOS3    SPR  EE00  0400
 BDOS3    SPR  D100  1D00

 52K TPA

A>
```

-----
## Technical detail
The generation of `CPMLDR.COM` and `CPM3.SYS` is automated by Makefile, but we will explain the details here.

### How to generate CPMLDR.COM
* Modify LDRBIOS.ASM   
  Modify `bios` to have the configuration of [Memory Map](#memory-map). (Original value is `0e900h`)
   `CPMLDR.COM` is used only to load `CPM3.SYS`, so `drives` can be left at 2.
  ```
  drives	equ	2		;number of drives supported
  bios	equ	0f200h		;address of your bios
  ```

* Generate LDRBIOS.REL  
   ```
  C>rmac ldrbios.asm
  CP/M RMAC ASSEM 1.1
  0084
  006H USE FACTOR
  END OF ASSEMBLY
  ```

* Generate CPMLDR.COM    
  Generate `CPMLDR.COM` from `LDRBIOS.REL`.  
  `CPMLDR.REL` and `SCB.REL` are provided with CP/M 3.
    ```
    C>link cpmldr,scb,ldrbios
    LINK 1.3

    @CIVEC   FE22   @COVEC   FE24   @AIVEC   FE26   @AOVEC   FE28
    @LOVEC   FE2A   @BNKBF   FE35   @CRDMA   FE3C   @CRDSK   FE3E
    @FX      FE43   @RESEL   FE41   @VINFO   FE3F   @USRCD   FE44
    @ERMDE   FE4B   @DATE    FE58   @HOUR    FE5A   @MIN     FE5B
    @SEC     FE5C   @MXTPA   FE62

    ABSOLUTE     0000
    CODE SIZE    0BEA (0100-0CE9)
    DATA SIZE    0084 (0CEA-0D6D)
    COMMON SIZE  0000
    USE FACTOR     23
    ```

### How to generate CPM3.SYS
Generate using `GENCPM.COM`. The following files are required.
- `BDOS3.SPR` : Provided by CP/M 3
- `BIOS3.REL` : Generated in this step

#### Generate `BIOS3.REL`
1. Modify GBIOS.ASM  
  Modify the file for reusing 62K CP/M 2.2 BIOS as is. The start address of BIOS2 is `F200H`. (Refer to [Memory Map](#memory-map))  
  5 drives (A:-E:) are supported.  
  Since the settings happen to be the same, there should be no need to modify them, but if they are different, set them as follows.
    ```
    drives	equ	5		;number of drives supported
    bios	equ	0f200h		;address of your bios
    ```
2. Assembling  
    ```
    C>rmac gbios
    CP/M RMAC ASSEM 1.1
    0144
    006H USE FACTOR
    END OF ASSEMBLY
    ```
3. Linking  
   `SCB.REL` is provided by CP/M 3.    
   ```
    C>link bios3[os]=gbios,scb
    LINK 1.3

    @CIVEC   FE22   @COVEC   FE24   @AOVEC   FE28   @LOVEC   FE2A
    @BNKBF   FE35   @CRDMA   FE3C   @CRDSK   FE3E   @FX      FE43
    @RESEL   FE41   @VINFO   FE3F   @USRCD   FE44   @ERMDE   FE4B
    @DATE    FE58   @HOUR    FE5A   @MIN     FE5B   @SEC     FE5C
    @MXTPA   FE62   @AIVEC   FE26

    ABSOLUTE     0000
    CODE SIZE    01D3 (0000-01D2)
    DATA SIZE    0144 (01D3-0316)
    COMMON SIZE  0000
    USE FACTOR     05
    ```

#### Generate CPM3.SYS using GENCPM.COM
Set the parameters of `GENCPM.COM` as follows to match the [Memory Map](#memory-map).
The top page of memory can only be specified in units of 512 bytes.
```
C>gencpm

CP/M 3.0 System Generation
Copyright (C) 1982, Digital Research

Default entries are shown in (parens).
Default base is Hex, precede entry with # for decimal

Create a new GENCPM.DAT file (N) ?         Preserve settings?

Display Load Map at Cold Boot (Y) ?

Number of console columns (#80) ?          Console settings
Number of lines in console page (#24) ?
Backspace echoes erased character (N) ?
Rubout echoes erased character (Y) ?

Initial default drive (A:) ?               

Top page of memory (FF) ? F0               Memory allocation (512byte units)
Bank switched memory (Y) ? N               Non bank memory

Accept new system definition (Y) ?

 BIOS3    SPR  ED00H  0400H
 BDOS3    SPR  D000H  1D00H

*** CP/M 3.0 SYSTEM GENERATION DONE ***
```

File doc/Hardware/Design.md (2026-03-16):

# Z80ATmega128 Board

## ハードウェア

- Z80A 4MHz (以下Z80)
- 共有メモリ 64KB (256Kbit SRAM x 2)
- AVR ATmega128-16AU 16MHz (以下AVR)
  - Z80のI/Oサブシステムとして使用
  - 2CH シリアルインターフェース
  - SPI接続のmicroSD Cardインターフェース

## 基本方針

- Z80上でプログラムをネイティブ動作させる。CP/M 2.2が動作するのが目標。
- SRAMをAVRとZ80で共有する。
- ROMは使用しない。Z80のブートストラップコードは、AVRが事前にSRAM上に配置する。
- SRAM以外のZ80の周辺I/OデバイスはAVRでエミュレートする。
- DISK I/OはmicroSDカードでエミュレートする。

## 電源

外部から5Vを供給する。
microSD Cardインターフェースは、5Vから三端子レギュレータで生成した3.3Vを使用する。それ以外はすべて5Vで動作する。

## CPUクロック

### Z80 clock

Z80Aのクロック規定は以下。

 |$\phi$||Min|Max|
 |-|-|-|-|
 |Lowレベル|$V_{ILC}$|$0.3V$|$0.45V$|
 |Highレベル|$V_{IHC}$|$V_{CC}-0.6=4.4V$|$V_{CC}+0.3=5.3V$|
 |周期|$t_C$|$250ns$|$t_{W(\phi H)}+t_{W(\phi L)}+t_r+t_f$|
 |Highパルス幅|$t_{W(\phi H)}$|$110ns$||
 |Lowパルス幅|$t_{W(\phi L)}$|$110ns$|$2000ns$|
 |立ち上がり, 立ち下がり|$t_r$, $t_f$||$30ns$|

8MHzのコルピッツ発振回路をD-FF(74HC74)で2分周したDuty 50%の $\phi=4MHz$のクロックが供給される。  
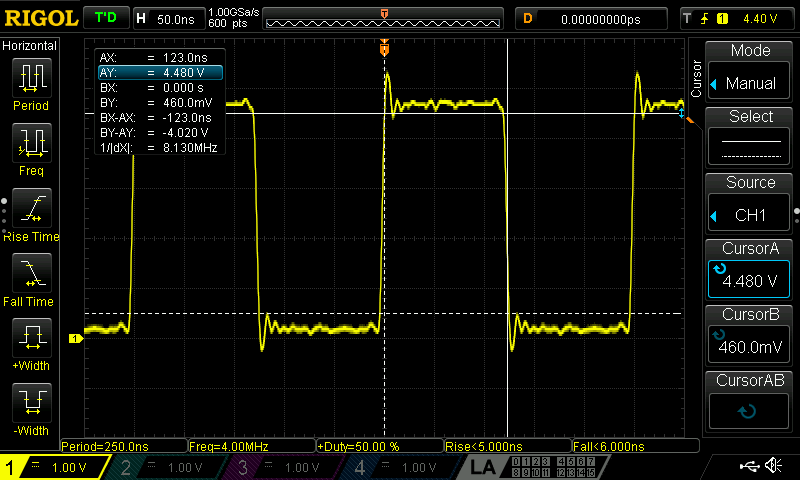
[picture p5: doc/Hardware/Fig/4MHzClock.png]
4MHz Masterclock
  

### AVR clock

セラミック振動子で16MHzのクロックを供給する。  
有効にするには以下のFuse設定が必要。

- CKSEL0, SUT1-0  
  - 外部セラミック振動子、低速上昇電源
  - CKSEL0=1, SUT1-0=00 : リセットからの付加遅延時間65ms
- CKSEL3-1
  - 外部セラミック振動子を使用するので値は111

詳細は[Fuse Bits](#fuse-bits)を参照。

## リセット回路

以下をサポートする。

- パワーオンリセット、リセットボタンによるマニュアルリセット。AVR、Z80の両方に適用される。
- ISPによるAVRのリプログラム時に駆動されるリセット。AVRのみに適用される。
- AVRのGPIO操作によるZ80のリセット。

Z80にはROMがないため、リセット時、SRAMの0番地にはブートストラップコードが存在している必要がある。このコードの配置はAVRが行う。パワーオンおよびマニュアルリセット時に、Z80をAVRよりも遅れて起動させるため、Z80にはAVRよりも長いリセット信号を与えている。
/RESETがLowの時、Z80の制御信号を含むバスは無効(ハイインピーダンス)になるので、AVRはバスを占有できる。この期間を利用してブートストラップコードを配置する。ただし/BUSACKはプルアップされているのでHighになってしまいバスが解放されない。このため/BUSACKはそのまま使わずに、/RESETとANDを取ってから使用するようにしている。

回路簡略化のため、パワーオンリセットと、マニュアルリセットを同時にサポート可能な[DS1232N](https://akizukidenshi.com/catalog/g/gI-15313/)を利用している。生成するリセットパルスは250ms(min)で、AVRはこれをそのまま使用し、Z80はカスケード接続で得られる500ms(min)のパルスを使用する。AVRは250msの時間差の中でペリフェラルのセットアップとZ80のプログラムの配置を終わらせる。
実際にはこの時間差はFuse bitのCKSEL0, SUT1,0の設定で変化することに注意。リセットからの付加遅延時間が設定できるからである。例えばCKSEL0=1, SUT01=00なら遅延時間は65msでなので、時間差は185msになる。([Fuse Bits](#fuse-bits)参照)
ブートストラップコードの転送には時間がかかるので、実際には0番地にHALT命令を書き込んで起動直後はHALT状態にさせ、コードをゆっくり書き込んでAVRからリセットをかけるのが現実的である。

ちなみに、リセット直後/BUSRQをにする方法は使えない。その状態でもZ80は0番地の命令をフェッチ、実行してからバスを解放する。命令は不定なのでシステムの動作に影響を与えてしまう可能性がある。Z80の起動タイミングをAVRより確実に遅らせるためには、/RESETをLowに保持したまま起動を止めておく必要がある。

DS1232Nにはウォッチドックタイマー機能があり、OFFすることができない。150ms毎に/STにパルスを投入しないとリセットパルスが生成されてしまうため、Z80用の4HMzのクロック信号を入力している。

ISPによるリプログラム時には、AVRのリセット信号が駆動される。RX0,TX0,SCKを共用しているため、スリーステートゲートでリセット信号を使って排他制御を行っている。ISPのリセット信号はプルアップが必要。ただし[ISP接続時のReset Lineのプルアップ抵抗の制限](https://onlinedocs.microchip.com/pr/GUID-BEB648AA-8539-418A-9EFB-118BDC9DC77B-en-US-1/index.html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)により、4.7K以上にする必要がある。10Kでプルアップしている。

## Z80出力信号のプルアップ

本回路は全て $V_{cc}=5V$ で動作させている。Z80はTTL出力なので、CMOS標準ロジックIC入力のHレベルと合致しない。Z80からCOMSへの入力信号には基本プルアップが必要である。

| I/O |Level |  TTL |  CMOS (@5.0V) |
| --- | ---- | -----| --- |
| In  | High | >2.0 |  >0.35 (=0.7x5.0) |
| In  | Low  | <0.8 |  <1.0  (=0.2x5.0) |
| Out | High | >2.4 |  >4.2  (=5.0-0.8) |
| Out | Low  | <0.4 |  <0.4 |

AVRがバスマスタのとき、/BUSACKはLowになり、Z80のほぼ全ての入出力信号はハイインピーダンスになる。/RD, /WR, /MREQ, /IORQ, /M1, /BUSACKは標準ロジックICに接続されており、入力が不定にならないようプルアップが必要である。

## DMA

SRAMはZ80とAVRで共有されている。AVRがSRAMアクセス、すなわちDMA(Direct Memory Access)を行う場合、バスの排他制御が必要になる。本回路では、Z80の/BUSRQと/BUSACKでそれを実現している。  
AVRがDMAを行う場合、Z80に対し/BUSRQをLowにして使用権を要求する。Z80は/BUSACKをLowにすることでバスの使用権をAVRに明け渡したことを知らせる。このときZ80の入出力信号はハイインピーダンスになる。AVRはバスの使用が完了したら/BUSRQをHighにし、バスの使用権をZ80に戻す。

本回路では、Z80からAVRへのI/Oサイクル、およびAVRからZ80への割り込み要求で、AVRに割り込みを発生させる。AVRの割り込みハンドラ内では/BUSRQの要求をしてはならない。これはZ80のI/Oサイクル中、あるいは割り込みサイクル中は、AVRはSRAMにアクセスできないことを意味する。
Z80は現在実行中のマシンサイクルが終了するタイミングで/BUSRQを受け付ける。つまり、割り込みハンドラ内で自動挿入される/WAITをリセットして現在のマシンサイクルが完了させる前に/BUSRQを要求すると、永久に受け付けられずにデッドロックに陥る。

## バスの排他制御

AVRはDMAだけでなくI/Oデバイスのエミュレーションも行うため、Z80とバス信号が競合しないよう排他が必要である。

### データバス

74HCT574と74HCT245によりAVRとZ80のデータバスの排他を行う。Z80、SRAMはTTLレベルのため、74LSまたは入力がTTLトレラントな74HCTを使用する。

AVRがDMAを行う場合、すなわちZ80の/BUSACK=Lowの期間は、Z80の制御信号はハイインピーダンスになる。これらはプルアップされているため、74HCT574と74HCT245の/OE=Highとなり、データバスはZ80から切り離される。

Z80のI/O READと割り込み時は、それぞれI/Oデータと割り込みベクターのラッチが必要なため、74HCT574を使用する。ラッチのタイミングは、WAIT生成回路の生成する/WAIT信号の立ち上がりである。

Z80のメモリアクセス時は、74HCT245のゲートが開くので、Z80とSRAMのデータバスが直結する。AVR側のPortAはハイインピーダンスにしておかなければならない。



### アドレスバス

下位アドレス(A0-7)は、74AC573で排他制御を行う。
AVRがDMAを行う場合は/OE=/BUSACK=Lowなので74AC573のゲートが開き、そのラッチ出力がSRAMの下位アドレスに直結する。このときZ80のアドレスバスはハイインピーダンスである。
一方、Z80がバス使用中は、ゲートが閉じ74AC573の出力はハイインピーダンスとなる。
Z80のI/Oアクセスで、AVRはI/OアドレスのリードするためにPortFを使用する。PortFは通常はハイインピーダンスにセットされている。INT0(/IORD), INT1(/IOWR)による割り込みがAVRにかかると、割り込みハンドラ内で入力にセットしてアドレスのリードし、再びハイインピーダンスに戻す。

上位アドレス(A8-15)は、74HC244で排他制御を行う。
AVRがDMAを行う場合は/OE1=/OE2=/BUSACK=Lowなので74HC244のゲートが開き、PortC出力とSRAMの上位アドレスが直結する。このときZ80のアドレスバスはハイインピーダンスである。
一方、Z80がバス使用中は、ゲートが閉じ74HC244の出力はハイインピーダンスとなる。



## Z80のI/Oアクセス

Z80のI/O空間はAVRがソフトウェアエミュレーションする。  
I/Oサイクルが発生すると、AVRに外部割り込みをかける。同時にWAIT生成回路によってZ80のI/Oサイクルにウエイトを強制的に挿入する。AVRは割り込みハンドラでI/Oデータの入出力を行い、WAIT生成回路をリセットすることでZ80のI/Oサイクルを完了させる。

### WAIT生成回路

Z80のI/Oサイクルでは/IOREQがアクティブになってから2.5クロック程度で、また割り込みサイクルでは1.5クロック程度で、アドレスバスとデータバスのアクセスを完了させる必要がある。
I/Oサイクルでは1つのTw\* が、割り込みサイクルでは2つのTw* が自動的に挿入される。しかし、AVRのソフトウェア処理でを完結させるには不十分なので、ハードウェア的に追加のTwを挿入してAVRでの処理時間を確保する。

/WAITは、I/Oサイクル(/IORQ=Low)、または割り込みサイクル(/IORQ=Lowかつ/M1=Low)を検出したら、次のマスタークロックの立ち上がりでLowになる。
AVRが/RELWAITに5ns以上のLowパルスを出力し、D-FFをリセットするまでこれは保持される。

## Z80のI/O WRITE

AVRには/IOWRによるINT1割り込みが発生する。割り込みハンドラでは以下の処理を行う。

1. PortFでアドレスバス(A0-A7)の値(I/Oアドレス)をリードする。(PortFは入力にセットされている前提。)
2. PortAを入力にセットする。
3. PortAからI/Oデータをリードする。
4. PortAをハイインピーダンスにセットする。
5. /RELWAITにLowパルスを出力する。

割り込み発生時には、74HC244はZ80→AVR方向の出力が有効なので、アドレスもデータもリード可能な状態になっている。5.で/WAITが解除されると、Z80のI/Oサイクルが完了する。


## Z80のI/O READ

AVRには/IORDによるINT0割り込みが発生する。割り込みハンドラでは以下の処理を行う。

1. PortFでアドレスバス(A0-A7)の値(I/Oアドレス)をリードする。(PortFは入力にセットされている前提。)
2. PortAを出力にセットする。
3. PortAにI/Oデータをライトする。
4. /RELWAITにLowパルスを出力する。
5. PortAをハイインピーダンスにセットする。

4.でWAIT生成回路がリセットされると、/WAITの立ち上がりで、74HCT574が3.のデータをラッチする。このデータはZ80のT3サイクルの立ち下がりでリードされる。/IORDがLowの期間は74HCT574の/OEが有効なため、PORTAへのデータ出力の前後のデータがバスに乗ってしまうが、Z80はラッチされたデータを読むので問題はない。　　

5.でPoartAをハイインピーダンスにするタイミングはデータラッチ以後であることが必要。このため割り込みハンドラ内で適切な時間調整が必要になるかもしれない。

データのラッチは/WAITの立ち上がりで行われる。次にTwステートの立ち下がりで/WAIT=Highがセンスされ、T3ステートが始まる。このT3の立ち下がりでラッチデータをリードされる。ワーストのタイミングは、Twの立ち下がり、/WAITの立ち上がり、ラッチがほぼ同時の場合。つまりTw立ち下がりからT3の立ち下がりまでの時間で、これはちょうど1クロック分。以下の合計が250ns以内であればよい。 $t_{pLH} < 200ns$ を満たせば十分なので、74HCT574を使用している。

- /WAITの立ち上がりからラッチまでの遅延: $t_{pLH}$
- /RDのセットアップ時間 : $T_{s\bar{\phi}(D)} = 50ns$

| $t_{pHL}$| typ  | max | 電圧/温度 |
| --- | ---- | ----- | ---  |
| 74HCT574 | 17ns |  30ns | 4.5V/25℃  |
| 74AC574  |  5ns | 9.5ns | 5V/25℃  |



## Z80への割り込み

Z80のすべての割り込みモード(NMI, Mode 0/1/2)をサポートする。ただし、Mode 0では1バイト命令(オペコードのみ)しか送信できない。

Z80の割り込みサイクルでも、WAIT生成回路が強制ウエイトを挿入する。/IORQはTw* の立ち下がりと同時にLowになる。これはI/Oサイクルのときよりも半クロック遅く、/WAIT生成のラッチタイミングまでのマージンは125nsしかないが、以下の合計がこれに収まっているため問題ない。

- /IORQの $t_{DL\bar{\phi}(IR)}=85ns$
- /WAIT生成回路のD-FF前のORゲート(74HC32)の $t_{pHL}=18ns$

AVRからZ80に割り込みをかける手順は以下。

1. /XINTにLowを出力し、Z80に割り込みをかける。Low出力はキープしたまま。理由は後述。
2. /INTRQでAVRにINT4割り込みがかかるので、割り込みハンドラ内で以下を実行。
3. /XINTをHighに戻す。
4. PORTAに割り込みベクターを出力する。
5. /RELWAITにLowパルスを出力する。

1.で/XINT(PD4)をLowのままにする理由は以下。  
Z80が/INT=Lowを認識するのは実行中の命令の最終ステートの立ち上がり。したがってWAITを考慮したZ80最大命令長程度のパルス幅が必要になる。だが本回路ではZ80のIN/OUT命令で強制WAITが挿入され、その解除時間はAVRの割り込みハンドラの実行時間に依存するため、命令終了のタイミングが自明でない。このため/XINTはLowのままにしておき、AVRに割り込みが確実にかかった後、すなわち割り込みハンドラの中でHighに戻す。Z80は割り込みサイクル中に/INTを見ないので問題ない。

Z80が/INTを認識して割り込みサイクルに入ると、/IORQと/M1がLowになり74HCT574のゲートが開く。同時にAVRに割り込みがかかる。/WAIT生成回路によりZ80には強制ウエイトがかかっている。割り込みハンドラ内で割り込みベクターを出力し、/RELWAITをで強制ウェイトを解除すると、74HCT574が/WAITの立ち上がりで割り込みベクターをラッチする。Z80はT3の立ち上がりで割り込みベクターをリードする。

ラッチ動作は割り込みサイクルの最終のTwの立ち下がりで行われるのがワーストケース。下記の合計が125ns以内ならば問題ない。

- 74HCT574の $t_{pHL}/t_{pHL} = 44ns$
- Z80の $t_{s\phi(D)} > 35ns$



### Mode2割り込みの動作例

割り込みレベル0x10の場合  

1. Z80の/INT(図中のINT)が/XINTによって生成される。これが認識されるのは現在実行中の命令(1番目の/M1のサイクル)の最終ステート。2番目の/M1=Lowから割り込みサイクルが開始する。/INTはAVRのINT4 ISR(割り込みハンドラ)の中で解除される。  
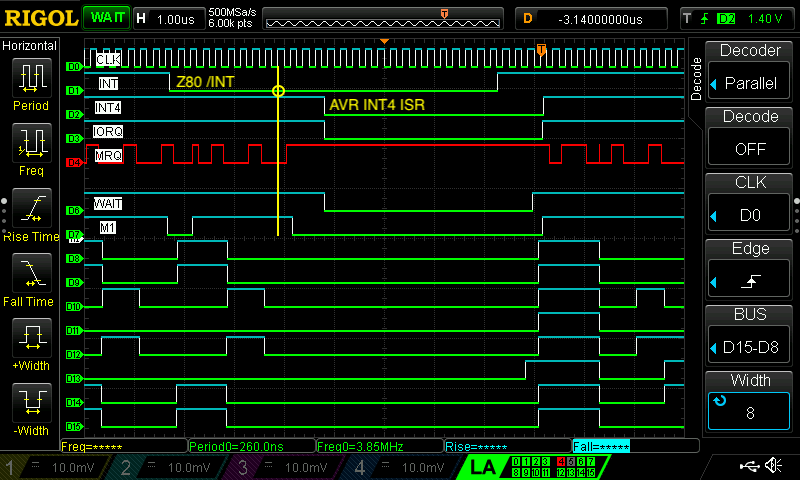
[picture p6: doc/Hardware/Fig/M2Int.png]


2. こちらはAVRのINT4 ISR終了後に引き続き実行される割り込みサイクルの様子。/WAITの立ち上がりでラッチされた割り込みベクタ(0x20)が、/IORQ直前のステートの立ち上がりでフェッチされる。割り込みレベルが0x10の場合、ベクタとして出力する値は左1ビットシフトした0x20にしなければならないことに注意。次に現在のPCの上位バイト、下位バイトがスタックに保存される。これはRETI命令での戻り先。引き続き0x20のISRのアドレスを、ベクタテーブルから下位、上位の順に取得する。この例では、割り込みレベル0x10用ISRの先頭アドレスである0x2070がPCにセットされ、実行される。  
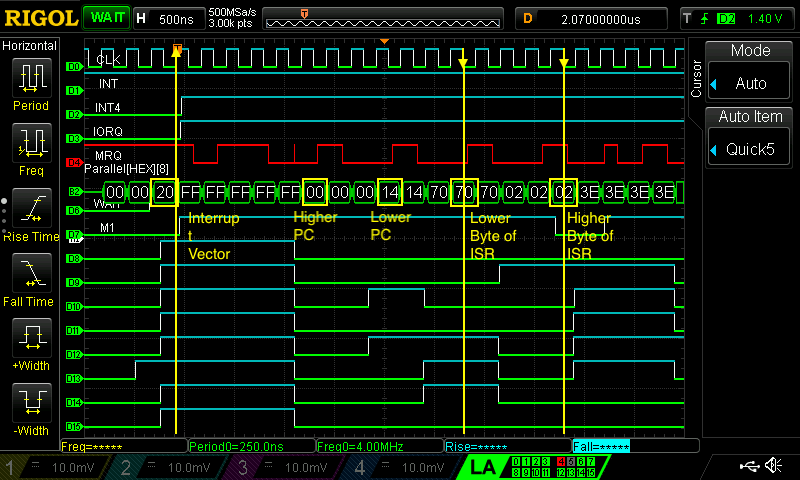
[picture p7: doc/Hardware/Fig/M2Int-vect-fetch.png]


## Z80とSRAMのインターフェース

Z80のメモリアクセスで一番厳しいタイミングはM1サイクルなので、このリードタイミングついて評価すれば十分。

M1サイクルでのデータはT3の立ち上がりでリードされる。このため以下のタイミングを満たすSRAMが必要となる。  

- $t_{OE} < 375ns - (t_{DL\bar{\phi}(RD)} + t_{S\bar{\phi}(D)}) = 245ns$
- $t_{AA} < 500ns - (t_{D(AD)} + t_{S\bar{\phi}(D)}) = 355ns$

HM62256は最も遅い品種でも $t_{OE}=70ns$, $t_{AA}=150ns$ なので、どれを使用しても問題ない。



- (1) Z80AのT1の立ち上がりからアドレスが確定するまでの最大時間 : $t_{D(AD)} = 110ns$
- (2) Z80Aの/MREQ,/RDの立ち下がりのどちらか遅い方(/RD) : $t_{DL\bar{\phi}(RD)} = 95ns$
- (3) Z80Aのデータのセットアップ時間 : $t_{S\bar{\phi}(D)} = 35ns$
- (4) SRAMの/OEからDataが出力されるまでの最大時間 : $t_{OE}$
- (5) SRAMのアドレスアクセス時間 : $t_{AA}$

### READ (M1サイクル)

- 0番地での無限ループの観測例

  ```text
  0000 C3 00 00      [10]    4     jp 0x0000
  ```

  - OE, WE, CS: SRAMの/OE, /WE, /CS
  - AB, CE: 74HCT245のA->B, CE
  

### WRITE

- 0x1234番地に0x55をライトの観測例

  ```text
  0000 3E 55         [ 7]    4     LD A, 0x55
  0002 32 34 12      [13]    5     LD (0x1234), A
  0005 76            [ 4]    6     HALT
  ```

  - OE, WE, CS: SRAMの/OE, /WE, /CS
  - AB, CE: 74HCT245のA->B, CE
  

## AVRとSRAMのインターフェース

AVRのPortA(PA0-7)は、SRAMのアドレスバスの下位8bitおよび、データバスに接続される。PortC(PC0-7)はアドレスバスの上位8bitに接続されている。



### XMEMインターフェース

AVRのXMEMインターフェースにる外部メモリアクセスでは、PortAを下位アドレスとデータアクセスで共有する。例えばライトでは下位アドレス(A0-7)、データの順に出力されるので、トランスペアレントラッチ(74AC573)で下位アドレス(A0-7)を保持しておく必要がある。ラッチはALE(PG2)の立ち下がりで行う。

AVRのアドレスA0-7のタイミング特性は、ALEの立ち下がりに対し以下となっている。

- セットアップ時間 : $t_{AVLL} = 0.5 * t_{CLCL} - 10 = 21.25ns$
- ホールド時間 : $t_{LLAX,ST} = 5ns$
- $t_{CLCL} = 1/16MHz = 62.5ns$

ラッチのホールド時間 $t_h < t_{LLAX,ST}$ を満たす必要があるが、74HC573では間に合わないので、高速な74AC573を使用する。アドレス(A0-7)はラッチの伝播遅延時間 $t_{pHL} = 10ns$ 分だけ遅れて出力される。

- 74AC573 @ 5.0V/25℃

  |                | min  |  typ  |  max  |
  | -------------- | ---- | ----- | ----- |
  | $t_{pHL}$ (D-Q)|      | 4.5ns |  10ns |
  | $t_s$          |  4ns |       |       |
  | $t_h$          |  4ns |       |       |

- 74HC573 @ 4.5V/25℃

  |                | min  |  typ  |  max  |
  | -------------- | ---- | ----- | ----- |
  | $t_{pHL}$ (D-Q)|      | 14ns  |  22ns |
  | $t_s$          | 10ns |       |       |
  | $t_h$          |  5ns |       |       |

/WR (PG0), /RD (PG1)は、Z80との排他用スリーステートバッファ(74HC125)を通るため、伝播遅延時間 $t_{pHL} = 18ns$ だけ遅れて出力される。

- 74HC125 @ 4.5V/25℃

  |                    | typ  | max  |
  | ------------------ | ---- | ---- |
  | $t_{pHL}, t_{pLH}$ | 11ns | 18ns |

### READ

SRAMのアクセスタイムにより、AVR側のWAIT設定の考慮が必要となる。

WAITを0/1/2で変化させた結果が以下。  
$t_{LLRL}$には74HC125の伝播遅延時間 $t_{pHL}=18ns$(max)が、 $t_{AA}$には74AC573の伝播遅延時間 $t_{pHL}=10ns$(max) 追加されることに注意。

- $t_{LLRL} = 0.5 * t_{CLCL} - 15 ＋ 18 = 34.25ns$
- $t_{DVRH} = 40ns$
- $t_{pHL} = 10ns$ (74AC573の伝播遅延時間)

- 0 WAITの場合
  - $t_{RLRH} = 1.0 * t_{CLCL} - 10 = 52.5ns$
  - $t_{AA} < t_{LLRL} + t_{RLRH} - t_{DVRH} - t_{pHL} = 36.75ns$
  - $t_{OE} < t_{RLDV} = 1.0 * t_{CLCL} - 50 = 12.5ns $

- 1 WAITの場合
  - $t_{RLRH} = 2.0 * t_{CLCL} - 10 = 115ns$
  - $t_{AA} < t_{LLRL} + t_{RLRH} - t_{DVRH} - t_{pHL} = 96.25ns$
  - $t_{OE} < t_{RLDV} = 2.0 * t_{CLCL} - 50 = 75ns$

- 2 WAITの場合
  - $t_{RLRH} = 3.0 * t_{CLCL} - 10 = 177.5ns$
  - $t_{AA} < t_{LLRL} + t_{RLRH} - t_{DVRH} - t_{pHL} = 161.75ns$
  - $t_{OE} < t_{RLDV} = 3.0 * t_{CLCL} - 50 = 137.5ns$

$t_{AA}$と $t_{OE}$を満たすSRAMを選択し、それに応じたXMEMインターフェースのWAIT設定を行う必要がある。  
以下にSRAM(HM62256)の品種と必要なWAITの関係を示す。

| | $t_{AA}$ | $t_{OE}$ | WAIT |
| --- | ---| --- | ---- |
| HM62256B-5  | 55ns  | 30ns | 1  |
| HM62256B-7  | 70ns  | 40ns | 1  |
| HM62256B-8  | 85ns  | 45ns | 1  |
| HM62256A-8  | 85ns  | 45ns | 1  |
| HM62256A-10 | 100ns  | 50ns | 2  |
| HM62256A-12 | 120ns  | 60ns | 2  |
| HM62256A-15 | 150ns  | 70ns | 2  |

以下はアドレス0x12をREADした時の結果。  
  AVR-SRAM-READ-Cycle

### WRITE

WRITEはタイミングに余裕があり、どの型番の組み合わせでも問題ない。SRAMの型番はREADのタイミング制約に合わせて決めればよい。

参考までに計算結果とWAITの関係を以下に示す。

- 1 WAITの場合
  - データのセットアップ時間 : $t_{DW} < t_{WHDX} = 2.0 * t_{CLCL} = 125ns$
  - データのホールド時間 : $t_{DH} < t_{WHDX} = 1.0 * t_{CLCL} - 15 = 52.5ns$
  - /WEのパルス幅 : $t_{WP} < t_{WLWH} = 2.0 * t_{CLCL} - 10 = 115.5ns$

- 2 WAITの場合
  - データのセットアップ時間 : $t_{DW} < t_{WHDX} = 3.0 * t_{CLCL} = 187.5ns$
  - データのホールド時間 : $t_{DH} < t_{WHDX} = 1.0 * t_{CLCL} - 15 = 52.5ns$
  - /WEのパルス幅 : $t_{WP} < t_{WLWH} = 3.0 * t_{CLCL} - 10 = 177.5ns$

| | $t_{DW}$ | $t_{DH}$ | $t_{WP}$ |
| --- | ---| --- | --- |
| HM62256B-5  | 25ns  | 0ns | 35ns |
| HM62256B-7  | 30ns  | 0ns | 50ns |
| HM62256B-8  | 35ns  | 0ns | 55ns |
| HM62256A-8  | 40ns  | 0ns | 55ns |
| HM62256A-10 | 40ns  | 0ns | 60ns |
| HM62256A-12 | 50ns  | 0ns | 70ns |
| HM62256A-15 | 60ns  | 0ns | 90ns |

以下はアドレス0x12に0x34をWRITEした時の結果。  
  AVR-SRAM-WRITE-Cycle

## AVRの設定

### Fuse Bits

- Extended Fuse Byte  

    |       | bit | Value |                         |
    |-------|-----|-------|-------------------------|
    | M103C |  1  |   1   |ATmega103互換モードを解除|
    | WDTON |  0  |   1   |WDT有効                  |

- Fuse High Byte

    |           | bit | Value |                              |
    |-----------|-----|-------|------------------------------|
    | OCDEN     |  7  |   1   |OFF                           |
    | JTAGEN    |  6  |   1   |JTAG OFF                      |
    | SPIEN     |  5  |   0   |SPIプログラム許可             |
    | CKOPT     |  4  |   0   |外部接続のセラロック16MHz     |
    | EESAVE    |  3  |   0   |チップ消去からEEPROMを保護    |
    | BOOTSZ1-0 | 2-1 |   00  |ブートローダー 4K             |
    | BOOTRST   |  0  |   1   |リセット時はユーザーアプリを実行|

    CP/M BIOSをEEPROMに書き込んでいる場合、AVR側のファームウェア書き換え時のチップ消去でBIOSが消えてしまうのを防ぐため、EESAVEを有効にしている。

- Fuse Low Byte

    |          | bit | Value |                       |
    |----------|-----|-------|-----------------------|
    | BODLEVEL |  7  |  0    |BOD検出電圧=4.0V       |
    | BODEN    |  6  |  0    |BOD有効                |
    | SUT1-0   | 5-4 |  00   |[AVR clock](#avr-clock)|
    | CKSEL3-1 | 3-1 |  111  |[AVR clock](#avr-clock)|
    | CKSEL0   |  0  |  1    |[AVR clock](#avr-clock)|

    [AVRの電圧が下がるとEEPROMのデータが壊れる問題](https://microchip.my.site.com/s/article/Prevent-EEPROM-corruption)の回避のためBODを有効にする。
    BODLEVELはデフォルト2.7Vだが、4.0Vでリセット状態に遷移するように変更する。

最終的な値は以下となる。  
値の変更はMicrochip StudioのDevice ProgrammingメニューからISP経由で行える。

| |  Value  |(Default)|
|---|---|---|
| Extended Fuse Byte |  0xFF | (0xFD)  |
| Fuse High Byte |  0xC1 | (0x99)  |
| Fuse Low  Byte |  0x0F | (0xE1)  |

### IO Port

#### PortA

PA0-7はデフォルトでハイインピーダンスにセットしておく。

- AVRがDMAを行うとき  
  XMEMインターフェースを有効にすることで出力にセットされる。下位アドレス(A0-7)出力、およびデータ(D0-7)出力として使用される。DMAが完了したらハイインピーダンスに戻す。
- Z80のI/O READのとき  
  AVRに/INT0割り込みがかかるので、割り込みハンドラ内で出力にセットし、I/Oデータをライトする。完了したらハイインピーダンスに戻す。
- Z80のI/O WRITEのとき  
  AVRに/INT1割り込みがかかるので、割り込みハンドラ内で入力にセットし、I/Oデータをリードする。完了したらハイインピーダンスに戻す。

#### PortB

- PB0 (/SS)  
  汎用SPIの/SSとして使用する。microSD Cardの/CSに接続する。
- PB1 (SCK)  
  SPI Programming InterfaceのSCK、および汎用SPIのSCKとして使用する。両者は74HC125のスリーステートゲートで排他制御される。ISPの/RSTがLowの時以外は汎用SPIのSCKが選択される。
- PB2 (MOSI)  
  汎用SPIのMOSIとして使用する。microSD CardのCMDに接続する。
- PB3 (MISO)  
  汎用SPIのMISOとして使用する。microSD CardのDATに接続する。
- PB4  
  常に入力にセットする。LowでmicroSD Cardが挿入されている。
- PB5  
  常に出力にセットする。初期値はHighにセットする。Z80への/RESETパルス生成用。
- PB6  
  常に出力にセットする。初期値はHighにセットする。Z80への/NMI割り込みパルス生成用。
- PB7  
  常に入力にセットする。Z80の/HALT信号のモニタ用。

#### PortC

PC0-7は常に出力にセットしておく。  
AVRがDMAを行うとき、XMEMインターフェース機能により上位アドレス(A8-15)出力として使用される。

#### PortD

- PD0 (/INT0)  
  Z80のI/O READ要求時のAVRへの割り込み信号。
- PD1 (/INT1)  
  Z80のI/O WRITE要求時のAVRへの割り込み信号。
- PD2 (RXD1)  
  UART CH1受信として使用
- PD3 (TXD1)  
  UART CH1送信として使用
- PD4  
  常に出力にセットする。初期値はHighにセットする。  
  Z80への/INT出力。Lowパルス生成でZ80に割り込みをかける。
- PD5  
  常に出力にセットする。初期値はHighにセットする。  
  /WAIT生成回路のリセット用。Lowパルス生成で/WAIT信号が解除される。
- PD6  
  常に出力にセットする。初期値はHighにセットする。  
  Z80への/BUSRQ出力。DMA要求時にLowレベルにホールドする。DMA完了時にはHighレベルに戻す。
- PD7  
  常に入力にセットする。  
  Z80の/BASACKをモニタ可能。

#### PortE

- PE0 (RXD0/MOSI)  
  UART CH0受信、およびSPI Programming InterfaceのMOSIとして使用する。両者は74HC125のスリーステートゲートで排他制御される。リセット信号がHighの時にはRXD0が選択される。
- PE1 (TXD0/MISO)  
  UART CH0送信、およびSPI Programming InterfaceのMOSIとして使用する。両者は74HC125のスリーステートゲートで排他制御される。リセット信号がHighの時にはTXD0が選択される。
- PE2
  常に入力にセットする。DIP SW3に接続されている。
- PE3
  常に入力にセットする。DIP SW4に接続されている。
- PE4 (/INT4)  
  PD4出力でZ80へ割り込み要求をかけると、Z80の割り込みサイクルにより生成されるAVRへの割り込み信号。この割り込みハンドラの中で、Z80に対し割り込みベクタを与える。
- PE5
  常に出力にセットする。LED1に接続されている。
- PE6
  常に出力にセットする。LED2に接続されている。
- PE7
  常に出力にセットする。LED3に接続されている。

#### PortF

- PF0-7  
  常に入力にセットする。Z80のI/Oアクセス時にI/Oアドレスをリードするために使用する。

#### PortG

- PG0  
  XMEMインターフェース有効時、SRAMの/WR信号として機能する。  
  XMEMインターフェース無効時は、High出力にセットする。  
- PG1  
  XMEMインターフェース有効時、SRAMの/RD信号として機能する。  
  XMEMインターフェース無効時は、High出力にセットする。  
- PG2  
  XMEMインターフェース有効時、74AC573のアドレスラッチ信号として機能する。  
  XMEMインターフェース無効時は、Low出力にセットする。  
- PG3  
  常に入力にセットする。DIP SW1に接続されている。  
- PG4  
  常に入力にセットする。DIP SW2に接続されている。

### XMEMインターフェース

SRAMアクセスのためにXMEMインターフェースを有効にするには、MCUCRのSRE(bit 7)をセットする。  
XMEMインターフェースを無効にしたら、Z80側バスとの衝突を防ぐためPORTAをハイインピーダンスにすること。これを保証するため、XMCRBのXMBK(bit 7)は0にセットされている必要がある。

#### SRAMのWAIT設定

XMCRAとMCUCRの設定で制御する。
外部メモリの全領域に対し、一括で1 or 2 WAIT設定を行うには以下のように設定する。

- WAIT設定  

  | Register |  bit      | 1 WAIT | 2 WAIT |
  |----------|-----------|--------|--------|
  | MCUCR    | SRW10 (6) |    1   |    0   |
  | XMCRA    | SRW11 (1) |    0   |    1   |

- 領域設定 (0x1100 - 0xFFFF)  

  | Register |  bit      | Value |
  |----------|-----------|-------|
  | XMCRA    | SLR0  (4) |   0   |
  | XMCRA    | SLR1  (5) |   0   |
  | XMCRA    | SLR2  (6) |   0   |

XMEMインターフェースでは外部RAM空間を2つに分けて、それぞれ異なるWAIT設定を行うことも可能である。本回路では2個の256bit SRAMを使用するので、32KBごとに領域を分割する場合の設定方法を以下に示す。

- WAIT設定  

  | Register |  bit      | 1 WAIT | 2 WAIT |                       |
  |----------|-----------|--------|--------|-----------------------|
  | MCUCR    | SRW10 (6) |    1   |    0   |上位領域(0x8000-0xFFFF)|
  | XMCRA    | SRW11 (1) |    0   |    1   |上位領域(0x8000-0xFFFF)|
  | XMCRA    | SRW00 (2) |    1   |    0   |下位領域(0x1100-0x7FFF)|
  | XMCRA    | SRW01 (3) |    0   |    1   |下位領域(0x1100-0x7FFF)|

- 領域設定　（0x1100 - 0x7FFF / 0x8000 - 0xFFFF）  
  
  | Register |  bit      | Value |
  |----------|-----------|-------|
  | XMCRA    | SLR0  (4) |   0   |
  | XMCRA    | SLR1  (5) |   0   |
  | XMCRA    | SLR2  (6) |   1   |

#### 0x0000-0x10FFのアドレス空間へのアクセス

Z80はリセット時に0番地からプログラムを実行するため、AVRはSRAMの0x0000にブートストラップコードを配置しておかなければならない。しかしAVRではSRAMは内部メモリの直後に配置されるので、0x0000-0x10FFの空間に直接アクセスすることができない。この問題は、SRAMのアドレス空間を狭めることで発生するシャドウ効果を利用した間接的なメモリアクセスで回避できる。

XMEMインターフェース有効時、PortCはアドレスバスの上位8bitにマップされるが、XMCRBのXMM0/1/2の設定で一部のピンをGPIOとして解放することが可能である。例えばPortCの上位3bitをGPIOとして強制的に0出力させることで、SRAMの0x0000-0x1FFFをAVRの0x2000-0x3FFFにマップできる。(サンプルコードは[データシート](https://ww1.microchip.com/downloads/en/DeviceDoc/doc2467.pdf)の"Using all 64 Kbyte Locations of External Memory"を参照。)

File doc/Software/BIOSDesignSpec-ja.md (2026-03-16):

# CP/M BIOS Design Specification

## Overview

- 62KB BIOS
- Z80ニーモニックで記述
- Mode2 割り込みを使用
- CON: をサポート。 LST:, PUN:, RDR: は未サポート。
- DISK I/O
  - 5 ドライブ (A: to E:) をサポート
  - Blocking and Deblocking をサポート

## Boot Sequence

AVRファームウェアは電源ONおよびリセット時に以下を実行する。

1. DIPSW-1がON、かつmicroSD CardがマウントできたらCP/Mモードで起動する。
2. EEPROMの0番地から`EntryAddress`と`Length`をリードする。 (1)
3. SRAMの0x0000番地に`JP EntryAddress`命令を書き込む。 (2)
4. EEPROM内のBIOSを`EntryAddress`に`Length`分コピーする。 (3)
5. Z80をリセットし、CP/Mを起動。
6. TinyMonitorを起動。

Z80はCP/Mを以下のように起動する。

1. 0番地のJP命令によりBIOSが起動される。
2. CCP+BDOSを`EntryAddress`にロードするために、BIOS BOOTルーチンがAVRにDISK READを要求する。  
   AVRは CCP+BDOS を microSD Card上のディスクイメージファイルのTrack 0相当から読み出し、SRAMにコピーする。
3. BIOS BOOTルーチンがCCPを起動する。

boot

## BOOT and WBOOT

BOOTとWBOOTの違いは以下。

### BOOT

- パワーオン時のみ呼ばれる。
- Z80の割り込み設定、Emulated I/O deviceの初期化
- ドライブをA:に設定
- CCP+3番地にジャンプ

### WBOOT

- ドライブは直前まで使用していたものをセット。
- CCPの先頭にジャンプ

## DISK I/O

BDOSが指定する論理トラックと論理セクタを、絶対セクタ番号に変換して扱っている。絶対セクタの定義は以下。
`TRK`と`SEC`は、それぞれ`SETTRK`、`SETSEC`のBIOSコールで事前にセットされるものとする。
`SPT`はDPB(Disk Parameter Block)で定義される値である。詳細は[BIOSのソース](../../z80/cpm22/bios/bios.asm)と[こちら](./DiskParameters.md)を参照。

- 論理トラック番号 : `TRK`
- 論理セクタ番号 : `SCT`
- 論理トラックあたりのセクタ数 : `SPT`
- 絶対セクタ番号 : `AS` = TRK * SPT + SCT

AVRとのデータ共有用に、SRAM上に512bytesのバッファ(`DMABUF`)を確保しており、`READ`,`WRITE`のBIOSコールで排他使用する。CP/Mの論理セクタ長は128byteなので、4セクタ分、すなわちBlocking Factor=4のBlocking/Deblockingをサポートする。

### READ

READ要求を受けると、指定されたセクタが`DMABUF`に存在するかチェックする。
存在する場合は、そのセクタを`DMA_ADRS`にコピーする。
存在しない場合は、AVRに512bytesのリードを要求する。先頭128byte(1セクタ分)を`DMA_ADRS`にコピーする。残りの3セクタ分は先読みキャッシュとして保存しておく。

### WRITE

AVRのEmulated DISK I/Oは、任意のアドレスとデータ長を指定して、ディスクイメージファイルにWRITEすることができる。しかしmicroSD Cardは、512byteのセクタ境界から512byte単位でライトする必要があるため、境界が一致しなかったり、データ長が512の倍数にならない場合はRead/Modify/Writeが必要になる。
これは顕著なライト速度の低下を招くため、BIOSはなるべく512bytes境界から512bytesを書き込むように、バッファとバッファフラッシュ(AVRへのライト要求)のタイミングを管理する。

WRITE要求を受けると、以下で定義される`IDX`の位置にデータがコピーされる。

- 格納されるバッファの位置 : IDX = AS % 4

  ```text
        +----------+
  IDX=0 | 128bytes |
        +----------+
  IDX=1 | 128bytes |
        +----------+
  IDX=2 | 128bytes |
        +----------+
  IDX=3 | 128bytes |
        +----------+
  ```

これがバッファフラッシュ後の**初回の**WRITE要求であれば、あわせて`IDX`とイメージファイルの書き込み先アドレスを記憶しておく。これは次のバッファフラッシュ時に使用される。

WRITE要求元は、Cレジスタに以下のDeblocking Codeをセットする。

- C = 0: deferred write
- C = 1: nondeferred write
- C = 2: deferred write to the first sector of a new data block

もしも以下のいずれか、または両方条件を満たす場合はバッファフラッシュを行う。

- C = 1
- IDX = 3
それ以外は、キャッシュされているセクタ数(0-3)をインクリメントし、リターンする。

バッファフラッシュ時は、記憶している`IDX`から`キャッシュされているセクタ数x128byte分`を、`イメージファイルの書き込み先アドレス`にライトする。

### SELDSK

Emulated DISK I/Oは、アクセスするディスクイメージを指定されたドライブのものに切り替える。

### SETTRK

論理トラック番号を`CURRENT_TRACK_NO`に保存するだけ。次回のREAD/WRITEで使用される。

### SETSEC

論理セクタ番号を`CURRENT_SECTOR_NO`に保存するだけ。次回のREAD/WRITEで使用される。

### SERDMA

データの転送アドレスを`DMA_ADRS`に保存するだけ。次回のREAD/WRITEで使用される。

### SECTRN

microSD Cardではインターリーブが不要なため、未サポート。

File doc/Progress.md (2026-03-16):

# 進捗状況

- [x] ISP経由でのプログラムの書き込みができるか確認。
  - [x] AVRISP mkIIでデバイスの認識ができるか確認。 (2023/3/5)
  - [x] Fuse bitsの書き換え (2023/3/5)
  - [x] サンプルプログラムの焼き込みと動作確認。 (2023/3/5)
- [x] サンプルプログラムはGPIOをいじるものを作成する。
  - [x] GPIOの設定の調査 (2023/3/19)
  - [x] PORTの初期設定 (2023/3/29)
  - [x] クロック設定し、delay()が動くようにする。(2023/3/29)
- [x] UARTで文字入出力できるようにする。(2023/4/1)
- [x] 簡易モニタ作成
  - [x] メモリダンプ (2023/4/2)
  - [x] メモリセット (2023/4/2)
  - [x] XMODEM (2023/4/1)
- [x] データバス、アドレスバスの配線 (2023/4/9)
- [x] AVRの外部SRAMアクセス動作確認
  - [x] XMEMの設定 (2023/4/9)
  - [x] AVRからSRAMリードサイクルの確認 (2023/4/30)
  - [x] AVRからSRAMライトサイクルの確認 (2023/4/30)
- [x] Z80のSRAMアクセス動作確認
  - [x] Z80のM1サイクルの確認 (2023/5/1)
  - [x] Z80のメモリリードサイクルの確認 (2023/5/1)
  - [x] Z80のメモリライトサイクルの確認 (2023/5/1)
- [x] AVRの外部割り込み設定 (2023/5/6)
- [x] Z80 OUT命令用の割り込みハンドラ
  - [x] 簡易モニタから流し込んだZ80 OUT命令の実行 (2023/6/5)
  - [x] WAIT生成回路の動作確認 (2023/6/9)
  - [x] WAIT解除でZ80に処理が戻るか？ (2023/6/9)
- [x] Z80 IN命令用の割り込みハンドラ
  - [x] 簡易モニタから流し込んだZ80 IN命令の実行  (2023/6/17)
- [x] AVRからZ80への外部割り込みの動作確認
  - [x] NMI割り込み  (2023/6/12)
  - [x] モード2ベクタ割り込み  (2023/6/12)
  - [x] モード1割り込み (2023/7/2)
  - [x] モード0割り込み (2023/7/2)
- [x] 簡易モニタにクロスアセンブルしたZ80のコードを流し込めるようにする
  - [x] INTEL HEXデコーダの実装 (2023/6/18)
- [x] 汎用Z80 I/Oエミュレーションフレームワークの作成
  - [x] Z80 IN/OUT命令ハンドラの登録 (2023/7/1)
  - [x] モード2ベクタ割り込み発生API (2023/6/25)
- [x] 割り込みを使用したシリアルドライバ(Z80用)
  - [x] 非同期コンソールI/O  (2023/6/27)
    - [x] RX1からの割り込み駆動の入力バッファリングと文字取得API (2023/6/27)
    - [x] Z80への割り込み通知  (2023/6/27)
    - [x] 文字出力APIからのバッファリングとタイマ割り込み駆動のTX1出力 (2023/6/27)
  - [x] AVR→Z80→AVRのコンソールエコーバック確認 (2023/6/25)
- [x] SDカード
  - [x] ファイルシステム対応 (2023/6/27)
  - [x] CP/M DISK I/Oエミュレーション (2023/7/23)
    - [x] レコードライト
    - [x] レコードリード
- [x] Z80のIPL作成 (2023/7/8)
- [x] CP/MのBIOS作成 (2023/10/4)
  - [x] コンソールI/O
    - [x] 仮想コンソールデバイスへの繋ぎこみ (2023/7/8)
  - [x] CP/M起動確認 (DISK I/Oなし) (2023/7/11)
  - [x] DISK I/O
    - [x] DPH/DPBの設計 (2023/7/30)
    - [x] 仮想DISK Deviceへの繋ぎこみ (2023/7/23)
  - [x] CP/M起動確認 (DISK I/Oあり) (2023/8/9)
- [x] SD Cardイメージ
  - [x] イメージファイルの作成 (2023/8/2)
  - [x] CP/M CCP,BDOS/BIOSのイメージ転送
- [x] AVRからZ80ブートストラップコードの自動転送とZ80側の自律動作 (2023/10/7)
- [X] CP/M BIOSのライトのデブロッキング処理 (2023/10/21)

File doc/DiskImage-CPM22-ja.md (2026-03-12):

# CP/M DISK Imageの作成方法

## 概要

本システムでは、CP/MのディスクをmicroSD Cardでエミュレーションしている。ディスクイメージはmicroSD Card上のファイルとして管理されるため、複数のイメージファイルを置いておけば、それらは独立したディスクドライブとみなすことができる。

microSD Cardは**FAT32**でフォーマットされていること。

ディスクイメージファイルの命名規則

- DISKnn.IMG (nnは00-15で、ドライブA:-P:に対応する)

ドライブA:であるDISK00.IMGはCP/Mのシステム(CCP+BDOS)を含む必要がある。メモリの関係上、BIOSでは５ドライブまでしかサポートしていない。したがって実際に使えるのは00-04までである。

ディスクイメージは、BIOSのDPBの形式に合致していなければならない。cpmtoolsでディスクイメージを生成する際には`diskdefs`で定義した以下のフォーマットを指定する。

```text
diskdef sdcard
seclen 512
tracks 256
sectrk 64
blocksize 8192
maxdir 256
skew 0
boottrk 1
os 2.2
end
```

このフォーマットではboottrkで1トラックが予約されており、システムディスク(`IMAGE00.IMG`)では、CP/Mのシステム(CCP+BDOS)がここに格納される。

ATmega128側のファームウェアで利用しているSD Cardのアクセスライブラリは、すでに存在するファイルに対してしか書き込み操作ができない。このためイメージファイルは全データ(約8GB)が事前に生成されている必要がある。

## ディスクイメージファイルの生成方法

`z80/cpm22/image/Makefile`では以下のイメージ生成をサポートしている。

### CP/M2.2 システムディスク

[CP/M 2.2 BINARY](http://www.cpm.z80.de/download/cpm22-b.zip)
をベースに`DISK00.IMG`を生成する。

```bash
make
```

#### `z80/cpm22/sys/CPM.SYS`を使用する場合

[CP/M 2.2 ASM SOURCE](http://www.cpm.z80.de/download/cpm2-asm.zip)のソースコードをベースに構築した`CPM.SYS`を使用する場合、`z80/cpm22/image/Makefile`を以下のように変更する。

```make
CCPBDOS   = ../sys/CPM.SYS
#CCPBDOS  = $(CPM22_DIR)/CPM.SYS
```

### 空のディスクイメージ

`EMPTY.IMG`が生成されるので、`DISKnn.IMG`にコピーして使用するか、これをベースに新たなイメージを作成する。

```make
make empty
```

### ZORK I/II/III

```make
make zork
```

`ZORK.IMG`が生成されるので、`DISKnn.IMG`にコピーして使用する。

### 任意のディスクイメージ

#### cpmcpを使う方法

cpmtoolsの`cpmcp`を使用し、任意のファイルをディスクイメージ上に転送することで、任意のイメージを作成できる。

例えば[CP/M software Download site](#cpm-software-download-site)などにはたくさんのCP/Mのバイナリファイルが存在する。その中から必要なファイルをピックアップしてディスクイメージを作成することもできる。

以下の例では、`./tmp`の全ファイルを空のディスクイメージに転送し、`DISK01.IMG`として`B:`ドライブに割り当てる。

```bash
cpmcp -f sdcard EMPTY.IMG ./tmp/*.* 0:
cp EMPTY.IMG DISK01.IMG
```

#### シェルスクリプト mkimg.shを使う方法

[../z80/cpm22/image/mkimg.sh](../z80/cpm22/image/mkimg.sh)を使うと、`EMPTY.IMG`を使わなくても直接イメージの生成が可能。

- 使い方:

  ```bash
  Usage: mkimg.sh <fmt> <img> [files ...]
        <fmt>: format defined in /etc/cpmtools/diskdefs
        <img>: image file name
        [files ...]: CP/M files (optional)
  ```

- 実行例:
  
  ```bash
  $ ./mkimg.sh sdcard test.img tmp/zork/*.*
  1021+0 records in
  1021+0 records out
  8364032 bytes (8.4 MB, 8.0 MiB) copied, 0.149639 s, 55.9 MB/s
  0:
  file_id.diz
  zork1.com
  zork1.dat
  zork2.com
  zork2.dat
  zork3.com
  zork3.dat
  ```

## CP/M software Download site

- [The Unofficial CP/M Web site](http://www.cpm.z80.de/)
  - [CP/M binary](http://www.cpm.z80.de/binary.html)
  - [CP/M source](http://www.cpm.z80.de/source.html)
- [Commercial CP/M Software](http://www.retroarchive.org/cpm/)
  - [ZORK I/II/III](http://www.retroarchive.org/cpm/games/zork123_80.zip)

## トラブルシューティング

- **CP/Mが起動しない**
  - DISK00.IMGが存在しない。
  - DISK00.IMGにシステムが書き込まれていない。
    - DISK00.IMGには予約トラックにBDOS+CCPが書き込まれている必要がある。
    - EMPTY.IMGなどをベースにしたイメージファイルをDISK00.IMGにリネームしただけでは、起動ディスクにはらない。`make`で生成されるDISK00.IMGを利用すること。

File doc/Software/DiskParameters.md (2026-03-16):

# CP/M DISK Parameters

## 用語

CP/MのDISK I/Oにはさまざまな用語が出てきてややこしいので整理しておく。

#### CP/Mの構成要素

|用語  |正式名称 | 役割 |
|---|---|---|
| IPL  | Initila Program Loader | CP/Mの管理外なので実装方法は規定されないが、必要な情報をメモリ上にロードしBIOSを起動する。|
| BIOS | Basic I/O System | 物理ハードウェアを制御するAPIライブラリ。IPLから起動され、CCPを呼び出すことでCP/Mを起動する。以後、BDOSから渡される、パラメータ(論理ディスク、トラック、セクタ)を[DPB](#DPB)の内容に応じて物理トラック、セクタに変換し、実際にディスクの読み書き、およびコンソールI/Oの処理を行う。|
| CCP  | Console Command Processor | コンソール入力を解釈し、ビルトインコマンド、トランジェントコマンドを起動する。内部でBDOSを呼び出す。|
| BDOS | Basic Disk Operating System |CP/Mのコアライブラリ。CCPやトランジェントプログラムはBDOSをAPIとして呼び出す。<br>BDOSは論理ディスク番号、論理トラック番号、論理セクタ番号をパラメータとしてリード・ライト要求をBIOSに対して発行する。|

#### 物理ディスク

|用語 | |
|---|---|
|物理ディスク|実際の物理デバイス。特性は[DPB](#DPB)で定義される。 |
|物理トラック|物理ディスクのトラック。数は論理トラックと同じ。 |
|物理セクタ　|物理ディスクのセクタ。サイズは論理セクタサイズ(128バイト)の整数倍であること。|

#### 論理ディスク

|用語 | |  番号  |
|---|---|---|
|論理ディスク|CP/Mで扱う仮想的なディスク単位。16台まで管理可能。ドライブレターは A:〜P: |0-15 |
|論理トラック|論理ディスクのトラック。<br>[DPB](#DPB)のOFFが加算されているが、OFF分はBDOSからはアクセスされない。|0-65535|
|論理セクタ　|論理ディスクのセクタ。サイズは128バイト固定。 |0-65535|
|ブロック　　|論理ディスクに配置するデータを管理する最小単位。複数の論理セクタで構成される。1からシリーズに番号が振られる。サイズは1024/2048/4096/8192/16384バイトのいずれか。<br>小さなサイズのファイルは、ブロックサイズに切り上げて管理されるので無駄が多くなる。|1- |

#### ディレクトリ

CP/M-80には階層化ディレクトリ機能がなく、すべてのファイルはフラットに管理される。このためディレクトリという用語は、WindowsやLinuxなどとは異なり、全ファイルを管理する単一の領域を表す。

|用語 | | 値 |
|---|-----|----|
|ディレクトリ |ファイルの管理領域全体のこと。複数のディレクトリエントリで構成される。||
|ファイル |いわゆるファイルのこと。||
|ディレクトリエントリ|1つのファイルの管理領域。ファイル名、タイプ、ブロック番号などで構成される。32バイト。||
|論理レコード |ファイルを構成するデータの格納単位。128バイト固定。先頭からシーケンシャルな番号が振られる。|0-65535|

#### DPHとDPB

|用語 |正式名称 | |
|-----|---|---|
| DPH | DISK Parameter Header | BDOSのディスク管理領域。BDOSがBIOSのSELSDK (0x1b)で選択したディスクに対応したDPHの先頭アドレスを返す。論理ディスクごとに用意する必要がある。|
| DBP | DISK Parameter Block  | 物理ディスクの特性を定義する。|

## DPH(DISK Parameter Header)

DPHは論理ディスク1台に対して、1つ必要になる。下記で定義されるテーブルおよびバッファをBIOSが用意する。BIOSコール(0x1b)で、指定された論理ディスクのテーブル(DPH)の先頭アドレスを返す。

### テーブル

|パラメータ|Bytes|正式名称 ||
|:----:|:---:|---|---|
| XLT  |  2  | Translation Table | スキューテーブルのアドレス。スキュー[^1]が不要な場合は0をセットする。|
| SPA  |  6  | Scratch Pad Area  | BDOSのワークエリア |
| DIRB |  2  | Directory Buffer  | ディレクトリ、レコードの読み書きに使用するバッファのアドレス。 |
| DPB  |  2  | DISK Parameter Block |対応するDPBのアドレス。同一タイプのディスクの場合はDPBを共有できる。|
| CSV  |  2  | Check Vector | リムーバブルディスクの入れ替えを検知するための値を保持するためのバッファのアドレス。ディスクごとに必要。|
| ALV  |  2  | Allocation Vector | ディスク領域の使用状況を管理するビットマップのアドレス。ディスクごとに必要。|
[^1]:フロッピーディスクのように物理的に回転する媒体を読み書きする場合、物理セクタと論理セクタの対応ずらすことで平均アクセス速度を改善するテクニックをスキューと呼ぶ。物理動作の不要な媒体では不要なテクニック。

### バッファ

|パラメータ|Bytes| |
|:----:|:---:|---|
| XLT  | SPT | トラックあたりの、論理セクタと物理セクタのマッピングテーブル。スキューテーブルともいう。|
| DIRB | 128 | 固定値 |
| CSV  | CKS | [DPB](#DPB)のCKSを参照 |
| ALV  | DSM / 8 + 1 | [DPB](#DPB)のDSMから算出する。|

## DPB (Disk Parameter Block)

このテーブルの先頭アドレスが、DPHのDPBにセットされる。
|パラメータ|Bytes| |意味|
|:---:|:---:|---|---|
| SPT |  2  | Sector Per Track |論理トラックあたりの論理セクタ数。<br>物理セクタサイズが128でない場合は変換が必要。|
| BSH |  1  | Block SHift factor |ブロックサイズから決まる値。([BLS/BSH/BLM/EXMの関係](#BLS/BSH/BLM/EXMの関係)を参照)<br>BLS = 128 $\times$ $2^{BSH}$|
| BLM |  1  | BLock Mask |ブロックサイズから決まる値。([BLS/BSH/BLM/EXMの関係](#BLS/BSH/BLM/EXMの関係)を参照)<br>BLS = 128 $\times$ (BLM + 1)|
| EXM |  1  | EXtent Mask |ブロックサイズとDSMから決まる値。([BLS/BSH/BLM/EXMの関係](#BLS/BSH/BLM/EXMの関係)を参照)|
| DSM |  2  | Disk Size Max |総データブロック数 - 1|
| DRM |  2  | DiRectory entries Max |総ディレクトリエントリ数 - 1|
| AL0 |  1  | ALlocation vector for Directory |ディレクトリのアロケーションベクタ|
| AL1 |  1  | ALlocation vector for Directory |ディレクトリのアロケーションベクタ|
| CKS |  2  | ChecK vector Size |チェックベクタのサイズ|
| OFF |  2  | track OFFset |ディスクの先頭に配置される、CP/M管理外の予約トラック数。通常ここにはBDOS,CCP,BIOSなどが格納され、IPLで読み込まれてメモリに展開される。CP/Mが使用する論理ブロックはこのトラックの直後から始まる。|

### BLS/BSH/BLM/EXMの関係

|  BLS  | BSH | BLM | EXM | EXM |
|:-----:|:---:|:---:|:---:|:---:|
| | | | DSM $\le$ 255 | DSM $>$ 255 |
|  1024 |  3  | 7 | 0 | - |
|  2048 |  4  |  15 | 1 | 0 |
|  4096 |  5  |  31 | 3 | 1 |
|  8192 |  6  |  63 | 7 | 3 |
| 16384 |  7  | 127 | 15 | 7 |

### パラメータの算出方法

#### ユーザが決めるパラメータ

|パラメータ| | diskdef[^2] |
|:---:|---|---|
| BLS | ブロックサイズ | blocksize |
| TTN | 総トラック数 | tracks |
| SPT | トラックあたりのセクタ数 | sectrk $\times$ seclen / 128 |
| DRM | 総ディレクトリエントリ数 - 1 | maxdir - 1  |
| OFF | 予約トラック数 | boottrk |
| PSZ | 物理セクタサイズ(128の倍数) | seclen |

[^2]:参考までに[cpmtools](http://www.moria.de/~michael/cpmtools/)のmkfs.cpmで使用するdiskdefのパラメータとの対応関係も記載した。

#### 既定値と関係式

|パラメータ| 関係式 | |
|:----:|---|---|
| SSZ | 128 |論理セクタサイズ(固定値)  |
| BLS | (BLM + 1) $\times$ SSZ |ブロックサイズ(バイト) |
| DSZ | TTN $\times$ SPT $\times$ SSZ |総ディスクサイズ(バイト) |
| DSM | DSZ / BLS - 1 |総ブロック数 - 1 |
| BLM | BLS / SSZ - 1 |ブロックあたりの論理セクタ数 - 1|
|AL0,1| (DRM + 1) $\times$ 32 / BLS |MSBからセットするビット数|
| CKS | (DRM + 1) / 4 |リムーバブルディスクの場合|
| | 0 |ハードディスクの場合 |
| ALV | DSM / 8 + 1 |ALVテーブルサイズ(バイト)|

## 計算手順

1. BLS(ブロックサイズ)を決める。
2. BSH = 表からBLSに対応する値を求める。
3. BLM = 表からBLSに対応する値を求める。
4. DSM = TTN $\times$ SPT $\times$ SSZ / BLS - 1
5. EXM = 表からBLS, DSMに対応する値を求める。
6. AL0,AL1 = AL0のMSBから (DRM + 1) $\times$ 32 / BLS 分ビットをセットする。
7. CKS = HDDなら0, リムーバブルディスクなら(DRM + 1) / 4
8. ALV =  DSM / 8 + 1

### 計算例 (8GB SD Card)

|パラメータ| | |
|:---:|---|:----:|
| BLS |ブロックサイズ 　 | 8192 |
| TTN |総トラック数 　 |  256 |
| SPT |トラックあたりのセクタ数|  256 |
| DRM |総ファイル数 - 1 　|  255 |
| OFF |予約トラック数 　| 1 |

1. BLS = 8192
2. BSH = 6
3. BLM = 63
4. DSM = 256 $\times$ 256 $\times$ 128 / 8192 - 1 = 1023
5. EXM = 3
6. AL0, AL1 = 0x8000 <br>(255+1) $\times$ 32 / 8192 = 1 なのでAL0の最上位から1ビット分(0x8000)をセットする。
7. CKS = 0
8. ALV = 128

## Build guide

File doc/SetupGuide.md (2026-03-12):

# Z80ATmega128 Board Setup Guide

Z80Atmega128 Boardにファームウェアを焼き込み、CP/M2.2を単体動作させるまでの手順を以下に示す。

## 基板実装図

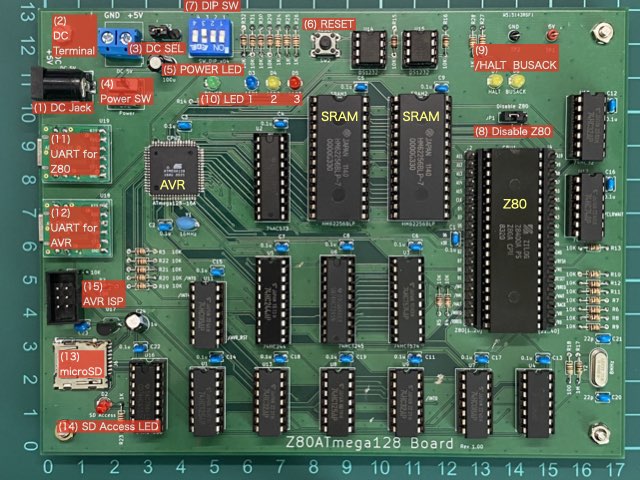
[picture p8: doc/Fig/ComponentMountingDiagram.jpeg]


| No.| | |
|:--:|---|---|
|(1) | DC Jack |+5V 外部電源(ACアダプタ用) |
|(2) | DC Terminal |+5V 外部電源ターミナル |
|(3) | DC Select |(1)/(2)切替用ジャンパーピン |
|(4) | POWER SW |外部電源SW |
|(5) | POWER LED |+5V通電時に点灯 |
|(6) | RESET |システムリセット |
|(7) | DIP SW |[詳細](#dip-sw) |
|(8) | Disable Z80 |Z80強制停止用ジャンパーピン<br>/BUSREQ=Lにする|
|(9) | /HALT BUSACK LED  |Z80 /HALT=L, /BUSACK=H で点灯 |
|(10)| LED 1 / 2 / 3 |[詳細](#led) |
|(11)| UART1 for Z80 |Z80用USB-Cシリアルインターフェース |
|(12)| UART0 for AVR |AVR用USB-Cシリアルインターフェース |
|(13)| microSD Card slot |microSDカードスロット |
|(14)| SD Access LED |microSDカードアクセス時に点灯 |
|(15)| AVR ISP Connector |AVRISP mkII接続用コネクタ |

### 電源

- 300mA以上の電流供給能力が必要。
- 5.5V以上の電圧は印加しないこと。過電圧保護は行なっていない。
- DCジャック、外部電源ターミナル、UART用USB-Cから給電できる。

### DIP SW

|  #  | 機能 | ON | OFF |
|:---:|---|---|---|
|  1  | CP/M mode | Enable | Disable  |
|  2  | UART baud rate |  19200 | 9600  |
|  3  | SD Write Protect | ReadOnly | Writable |
|  4  | SRAM Wait | 1 wait |  2 wait  |

- SW 1: CP/M BIOSがAVRのEEPROMに書き込まれている場合、ONにすることでCP/Mが起動する。
- SW 2: 接続する端末の通信速度にあわせる。
- SW 4: 外部SRAM(HM62256)のアクセスタイムが100nsよりも速い場合、ONにすることで1ウェイト動作になる。

### LED

|  #  | 色 | 状態 |
|:---:|----|---|
|  1  | 青 | microSDが未挿入、またはマウント失敗時に点灯 |
|  2  | 黄 | microSDがライトプロテクト状態で点灯 |
|  3  | 赤 | AVRのハートビート表示(2Hzで点滅) |

### 注意

- PCB Rev1.00　配線にバグがあるため、ハード改修の必要がある。
  - [表面](./Hardware/PCB/PCB1.0-FP-Errata.pdf) : パターンカット7箇所
  - [裏面](./Hardware/PCB/PCB1.0-BP-Errata.pdf) : パターンカット1箇所、パッチ配線6箇所
- PCB Rev2.00　U18, U19のUARTのシルクが間違っている。

## 1. 事前準備

- Windowsに[Microchip Studio](https://www.microchip.com/en-us/tools-resources/develop/microchip-studio)をインストールする。
  - Ver7.0.2594で動作確認
- [AVRISP mkII](https://www.microchip.com/en-us/development-tool/ATAVRISP2)を使えるようにしておく。
  - 純正品は製造中止なので、互換品でもかまわない。
  - ATmega128のFUSE設定とファームウェアの書き込みに使用する。
- シリアルインターフェースで送受信ができる端末(できれば2チャンネル分)を使えるようにしておく。
  - プロトコル: 9600 or 19200 baud, 8bit / non parity / 1stop bitの調歩同期通信
  - XMODEM: 128byte check sum 送信が行えること。
  - 端末ソフト: [TeraTerm](https://ttssh2.osdn.jp/index.html.en) (Windows)など
  - 通信速度はDIP SWの設定に合わせておく。

## 2. ファームウェアの書き込み

Z80ATmega128 Boardにファームウェアを焼き込み、モニタプログラムを動作させるまでの手順を説明する。  

### 2-1. AVRファームウェアのビルド

1. WindowsでMicrochip Studioを起動。
2. `File > Open > Project/Solution...` で、`avr/avr.atsln` を選択。
3. `Build > Build Solution` を実行。
4. エラーがないことを確認する。

### 2-2. ATmega128へのファームウェアの書き込み

1. Z80ATmega128 BoardのAVR ISPコネクタにAVRISP mkIIを接続し、電源を入れる。
2. Microchip Studioを起動。
3. `Tools > Device Programming`を選択。
4. 以下のように値をセットし`Apply`を実行。

   | 設定      | 値         |
   |-----------|------------|
   | Tool      | AVRISPmkII |
   | Device    | ATmega128  |
   | Interface | ISP        |

5. Deivce signatureの確認  
   `Read` を実行し、値が `0x1E9702` になればOK。  
   エラーになる場合は `Interface setting` を選択し、`ISP Clock` を変更してみる。  
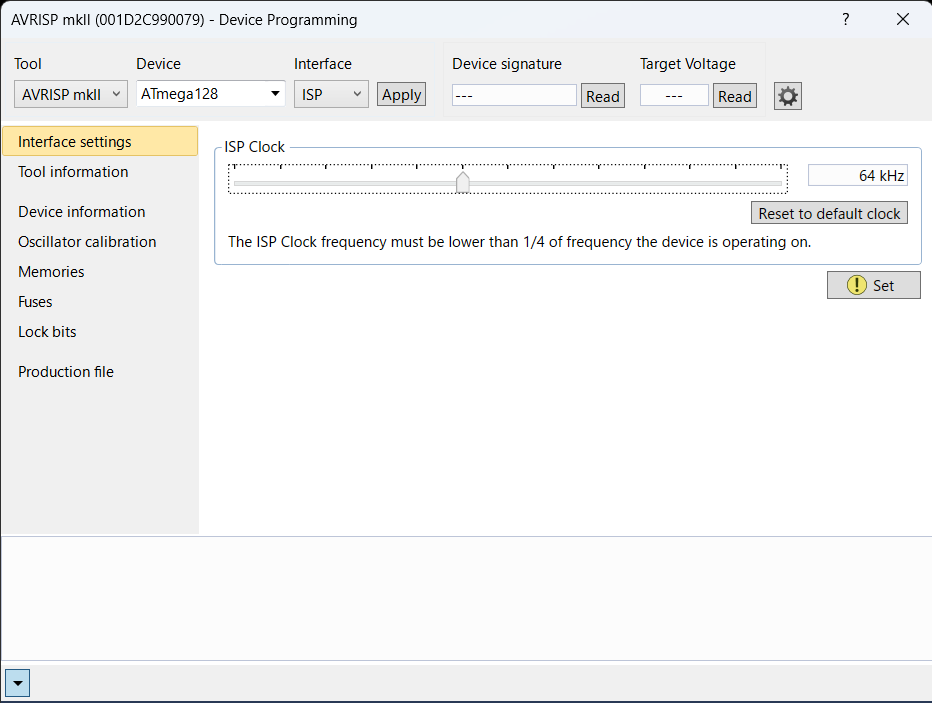
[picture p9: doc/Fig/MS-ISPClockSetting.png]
    

6. FUSEの設定  
   以下のようにセットする。(設定値の詳細は[こちら](Hardware/Design.md#fuse-bits))
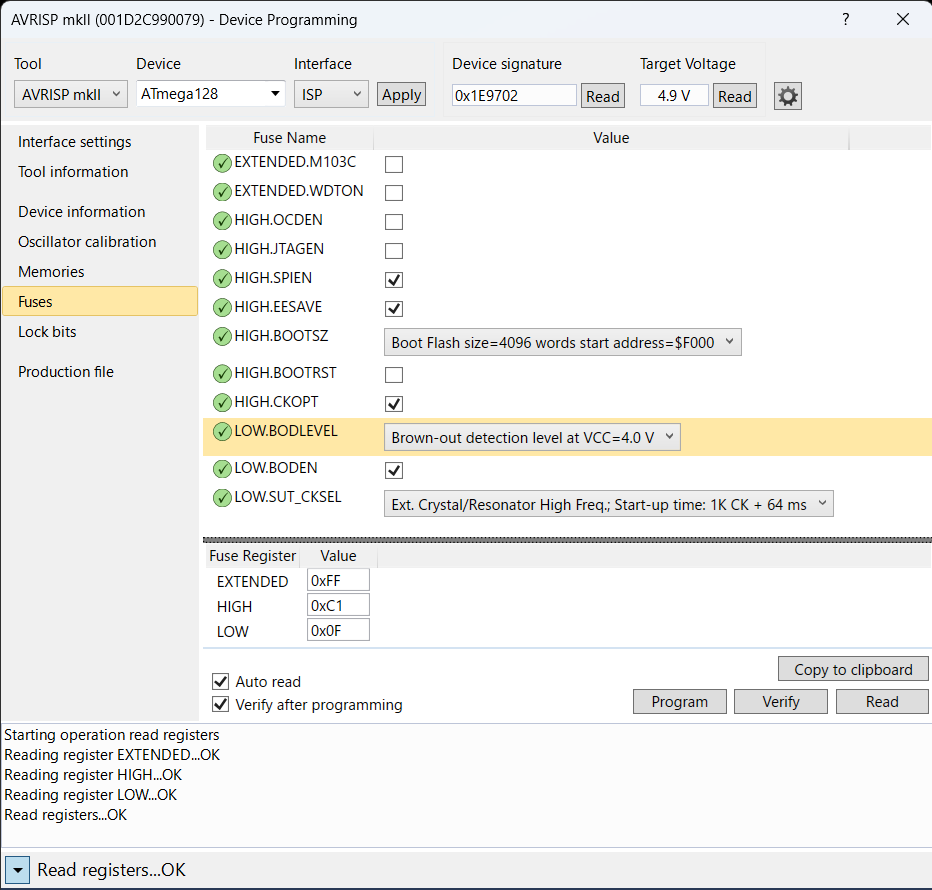
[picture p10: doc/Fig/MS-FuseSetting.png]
   

7. ファームウェアの書き込み  
   `Program` を実行。  
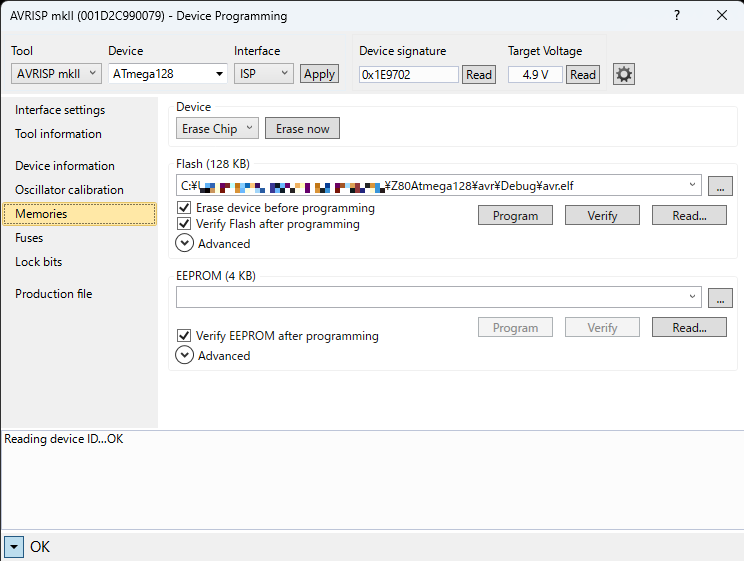
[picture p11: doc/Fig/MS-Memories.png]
   

### 2-3. 動作確認

1. DIP SW 1はOFFにし、CP/M起動を行ないようにする。
2. microSD Cardはまだセットしない。
3. AVR用シリアルインターフェースを端末ソフトに接続。
4. 電源ONまたはリセットボタン押下で、プロンプトが表示されることを確認。

    ```text
    ATmega128 Tiny Monitor
    >
    ```

5. メモリテスト

    ```text
    >test
    2000-2500
    write sum=7d80
    read  sum=7d80
    XMEM OK!
    ```

6. これでZ80ATmega128 Boardの動作確認が完了。

## 3. CP/Mの設定

Z80ATmega128 BoardでCP/M-80を動作させるための手順を説明する。  

なお、ライセンスの関係で本リポジトリにはCP/Mのソースもバイナリも置いていない。ここでは、[The Unofficial CP/M Web site](http://www.cpm.z80.de/)にある、[CP/M 2.2 BINARY](http://www.cpm.z80.de/download/cpm22-b.zip)を使用してCP/Mのディスクイメージを作成する。

### 3-1. ビルド環境の構築

BIOSのアセンブル、およびCP/Mのディスクイメージの作成はLinux環境で行う。
WindowsはWSL、macOSはVS Code + Dev Containerの環境がおすすめ。

#### Linux, WSL (Ubuntu22.04)の場合

1. 必要なツールのインストール

   ```bash
   sudo apt-get install -y wget git make unzip gcc
   ```

2. Z80のクロスアセンブラ(asxxxx)のインストール

   ```bash
   cd z80/toolchain
   make
   ```

3. cpmtoolsのインストール

   ```bash
   sudo apt-get install -y cpmtools
   ```

#### VS Code + Dev Containerの場合

**ツールのインストール**  

- [Docker Desktop](https://www.docker.com/products/docker-desktop/)
- [VS Code](https://azure.microsoft.com/ja-jp/products/visual-studio-code/)
- `Dev Containers`プラグイン

**起動方法**  

1. `Z80ATmega128/`でVS Codeを起動する
2. コマンドパレットを開き、`Dev Containers: Reopen in Container`でコンテナを起動する
3. VS Codeでターミナルを起動する。
   - `/z80`がマウントされているので、そこで作業を行う。
   - ファイルが見えない場合は、`Dev Containers: Rebuild Without Cache and Reopen in Container`でコンテナイメージをすると解消する場合がある。

### 3-2. CP/MディスクイメージとmicroSD Cardの作成

1. CP/Mディスクイメージの生成 (VSCode + Dev Container環境の場合)  
  `z80/cpm22/image` で `DISK00.IMG` を生成する。これがCP/Mのディスクイメージのバイナリファイル。

    ```bash
    vscode@Z80ATmega128:/z80/cpm22/image$ make
    mkdir -p ./tmp
    wget -P ./tmp http://www.cpm.z80.de/download/cpm22-b.zip
    --2023-10-10 16:04:18--  http://www.cpm.z80.de/download/cpm22-b.zip
    Resolving www.cpm.z80.de (www.cpm.z80.de)... 92.205.48.95, 2a00:1169:103:9b30::
    Connecting to www.cpm.z80.de (www.cpm.z80.de)|92.205.48.95|:80... connected.
    HTTP request sent, awaiting response... 200 OK
    Length: 42510 (42K) [application/zip]
    Saving to: ‘./tmp/cpm22-b.zip’

    cpm22-b.zip                  100%[============================================>]  41.51K   124KB/s    in 0.3s    

    2023-10-10 16:04:20 (124 KB/s) - ‘./tmp/cpm22-b.zip’ saved [42510/42510]

    unzip -o -d ./tmp ./tmp/cpm22-b.zip
    Archive:  ./tmp/cpm22-b.zip
    inflating: ./tmp/CPM.SYS           
    inflating: ./tmp/DDT.COM           
    inflating: ./tmp/PIP.COM           
    inflating: ./tmp/SUBMIT.COM        
    inflating: ./tmp/XSUB.COM          
    inflating: ./tmp/ED.COM            
    inflating: ./tmp/ASM.COM           
    inflating: ./tmp/LOAD.COM          
    inflating: ./tmp/STAT.COM          
    inflating: ./tmp/DUMP.COM          
    inflating: ./tmp/DUMP.ASM          
    inflating: ./tmp/BIOS.ASM          
    inflating: ./tmp/DEBLOCK.ASM       
    inflating: ./tmp/DISKDEF.LIB       
    inflating: ./tmp/DSKMAINT.COM      
    inflating: ./tmp/READ.ME           
    rm -f ./tmp/cpm22-b.zip
    mkfs.cpm -f sdcard -b ./tmp/CPM.SYS DISK00.IMG
    dd if=/dev/zero of=DISK00.IMG bs=8192 count=1021 oflag=append conv=notrunc
    1021+0 records in
    1021+0 records out
    8364032 bytes (8.4 MB, 8.0 MiB) copied, 0.139112 s, 60.1 MB/s
    cpmcp -f sdcard DISK00.IMG ./tmp/*.* 0:
    cpmls -f sdcard DISK00.IMG
    0:
    asm.com
    bios.asm
    cpm.sys
    ddt.com
    deblock.asm
    diskdef.lib
    dskmaint.com
    dump.asm
    dump.com
    ed.com
    load.com
    pip.com
    read.me
    stat.com
    submit.com
    xsub.com
    echo `wc -c < DISK00.IMG`
    8429568
    ```

2. microSD Cardの作成
   - **FAT32**でフォーマットする。
   - ルートディレクトリに `DISK00.IMG` をコピーする。これはシステムディスクで必ず存在する必要がある。
     - `00`はドライブA:に相当する。`4`(ドライブE:)まで指定可能。
     - 例えば `DISK00.IMG` を `DISK01.IMG` としてコピーし追加すれば、B:ドライブが見えるようになる。

### 3-3. CP/M自動起動のための設定

microSD CardからCP/Mが起動できるようにするための設定を行う。

1. BIOSのビルド (VSCode + Dev Container環境の場合)  
   `z80/cpm22/bios` で `bios.ihx` を生成する。これはIntel HEX formatのファイル。

    ```bash
    vscode@Z80ATmega128:/z80/cpm22/bios$ make bios.ihx
    asz80 -l -o  bios.asm
    
    aslink -i bios.ihx bios.rel
    
    ASlink >> -i
    ASlink >> bios.ihx
    ASlink >> bios.rel
    ```

2. EEPROMへのBIOSの書き込み
   1. AVR用のシリアルインターフェースを端末に接続。
   2. AVR Tiny Monitorの`xload`コマンドで、Intel HEXフォーマットのBIOSをSRAM上にバイナリ展開する。AVR用端末からXMODEMで `bios.ihx` を送信する。62K CP/M用BIOSなので、バイナリは0xf200から配置される。

        ```text
        >xload
        Start XMODEM within 90s...

        Received 2816 bytes.
        ```

   3. EEPROMにダウンロードしたBIOSイメージをATmega128のEEPROMの0番地に転送する。終了するまで少し時間がかかる。先頭4バイトにはBIOSの先頭アドレス(0xf200)と長さ(0x00b0)が書き込まれる。

        ```text
        >esave2 0 $f200 2816
        >
        ```

### 3-4. 動作確認

  1. AVR, Z80用のシリアルインターフェースを端末に接続。
  2. CP/Mイメージファイルを書き込んだmicroSD Cardをスロットに挿入する。
  3. DIP SW 1をON(CP/M起動モード), DIP SW 3をOFFにして、リセットボタンを押す。
  4. AVR側のシリアル端末には以下のプロンプトが表示される。  
     EEPROMに書き込まれたBIOSがSRAM上にコピーされ、BIOSがmicroSD Cardの予約トラックに書き込まれているCCP+BDOSを読み込んで、CP/Mを起動する。

     ```text
     === CP/M mode ===
     BIOS: 0xf200 - 0xfcff
     
     ATmega128 Tiny Monitor
     >
     ```

     Z80側のシリアル端末に以下が表示されれば成功。

     ```text
     62K CP/M-80 Ver2.2 on Z80ATmega128
     BIOS Copyright (C) 2023 by 46nori
     
     A>
     ```

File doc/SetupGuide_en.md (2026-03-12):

# Z80ATmega128 Board Setup Guide

The procedure for setting up the firmware on the Z80Atmega128 Board and booting CP/M2.2 is shown below.

## Component Mounting Diagram



| No.| | |
|:--:|---|---|
|(1) | DC Jack | +5V external power supply (for AC adapter) |
|(2) | DC Terminal | +5V external power supply terminal |
|(3) | DC Select | Jumper pin for selecting (1)/(2) |
|(4) | POWER SW | Power SW |
|(5) | POWER LED | Power LED indicator |
|(6) | RESET | System reset |
|(7) | DIP SW | [Detail](#dip-sw) |
|(8) | Disable Z80 | Jumper Pin for Z80 force suspend<br>/BUSREQ=L |
|(9) | /HALT BUSACK LED  | Z80/HALT=L,/BUSACK=H |
|(10)| LED 1 / 2 / 3 | [Detail](#led) |
|(11)| UART1 for Z80 | USB-C Serial Interface for Z80 |
|(12)| UART0 for AVR | USB-C Serial Interface for AVR |
|(13)| microSD Card slot | microSD card slot |
|(14)| SD Access LED | microSD card access LED indicator |
|(15)| AVRISP Connector  | AVRISPmkII connector |

### Power supply

- A current supply capacity of at least 300mA is necessary.
- Do not exceed 5.5V; there is no overvoltage protection circuit.
- Power can be provided through the DC Jack, External Power Terminal, or the USB-C for UART.

### DIP SW

|  #  | Function | ON | OFF |
|:---:|---|---|---|
|  1  | CP/M mode | Enable | Disable  |
|  2  | UART baud rate |  19200 | 9600  |
|  3  | SD Write Protect | ReadOnly | Writable |
|  4  | SRAM Wait | 1 wait |  2 wait  |

- SW1: If turned ON, CP/M will start automatically upon powering up, provided the BIOS has been written to the AVR EEPROM.
- SW2: Select baud rate to match the connected terminal.
- SW4: Tuen ON if SRAM(HM62256) access time is faster than 100ns.

### LED

|  #  | Color  | Status |
|:---:|---|---|
|  1  | Blue | microSD is not inserted / mount failure |
|  2  | Yellow | microSD is Write Protected |
|  3  | Red | AVR heartbeat (blinking at 2 Hz) |

### Notes

- PCB Rev1.00 has a bug in the wiring and needs to be fixed.
  - [Front Plane](./Hardware/PCB/PCB1.0-FP-Errata.pdf): 7 pattern cuts
  - [Back Plane](./Hardware/PCB/PCB1.0-BP-Errata.pdf): 1 pattern cut, 6 patch wires
- PCB Rev2.00, The silk printing of U18 and U19 are incorrect.

## 1. Preparation

- Install [Microchip Studio](https://www.microchip.com/en-us/tools-resources/develop/microchip-studio) on Windows.
  - Verified to work with version 7.0.2594.
- Ensure the [Microchip Studio](https://www.microchip.com/en-us/tools-resources/develop/microchip-studio) is ready for use.
  - Genuine device have been discontinued, so compatible alternatives are acceptable.
  - It will be used for configuring ATmega128's FUSE settings and firmware flashing.
- Prepare a terminal capable of serial communication (ideally, two channels).
  - Protocol: 9600 or 19200 baud, 8-bit / non-parity / 1-stop bit,  asynchronous
  - Set the baud rate to match the DIP switch configuration.
  - XMODEM with 128-byte checksum transmission should be supported.
  - Terminal software example: [TeraTerm](https://ttssh2.osdn.jp/index.html.en) (for Windows)

## 2. Flashing AVR Firmware

This section describes the steps to burn the firmware into the Z80ATmega128 Board and to run the monitor program.

### 2-1. Building AVR Firmware

1. Start Microchip Studio on Windows.
2. Choose `File > Open > Project/Solution ...`, select `avr/avr.atsln`.
3. Run `Build > Build Solution`.
4. Check for no error.

### 2-2. Flashing Firmware to ATmega128

1. Connect the AVRISP mkII to the AVRISP connector on the Z80ATmega128 Board and power it on.
2. Start Microchip Studio.
3. Choose `Tools > Device Programming`.
4. Set the values as follows and execute `Apply`:

   | Setting   | Value      |
   |-----------|------------|
   | Tool      | AVRISPmkII |
   | Device    | ATmega128  |
   | Interface | ISP        |

5. Check Deivce signature  
   `Read` and the check the value is `0x1E9702`.  
   If you get an error, select `Interface setting` and try changing `ISP Clock` lower.  
    

6. Configuring FUSE  
   Set as follows. (For details on the settings, see [here](./Hardware/Design.md#fuse-bits).)  
   

7. Flashing Firmware  
   Run `Program`.  
   

### 2-3. Functionality Test

1. Turn OFF the DIP SW1 to disable CP/M mode.
2. Do not insert the microSD Card into the slot.
3. Connect the serial interface for AVR to the terminal software.
4. Verified the prompt appears when the power is ON or the reset button is pressed.

    ```text
    ATmega128 Tiny Monitor
    >
    ```

5. Memory Test

    ```text
    >test
    2000-2500
    write sum=7d80
    read  sum=7d80
    XMEM OK!
    ```

6. This completes the test of the Z80ATmega128 Board.

## 3. CP/M settings

The procedure for operating the CP/M-80 on the Z80ATmega128 Board is described below.  

Due to licensing, neither the source nor the binary of the CP/M is provided in this repository. In this section, you will create a CP/M disk image using the [CP/M 2.2 BINARY](http://www.cpm.z80.de/download/cpm22-b.zip) located at [The Unofficial CP/M Web site](http://www.cpm.z80.de/).

### 3-1. Setup Build Environment

Linux is required for BIOS build and the CP/M disk image generation.
WSL for Windows and VS Code + Dev Container environment for macOS are recommended.

#### Linux, WSL (Ubuntu22.04)

1. apt install

   ```bash
   sudo apt-get install -y wget git make unzip gcc
   ```

2. Install Z80 cross assembler(asxxxx)

   ```bash
   cd z80/toolchain
   make
   ```

3. Install cpmtools

   ```bash
   sudo apt-get install -y cpmtools
   ```

#### VS Code + Dev Container

**Install**  

- [Docker Desktop](https://www.docker.com/products/docker-desktop/)
- [VS Code](https://azure.microsoft.com/ja-jp/products/visual-studio-code/)
- `Dev Containers` extension

**How to start**  

1. Launch VS Code in the `Z80ATmega128/` directory.
2. Open the Command Palette and start the container with `Dev Containers: Reopen in Container`.
3. Open a terminal in VS Code.
   - `z80/` is mounted, so work there.
   - If files are not visible, try `Dev Containers: Rebuild Without Cache and Reopen in Container` to rebuild the container image.

### 3-2. Creating a CP/M Disk Image for microSD Card

1. Generating a CP/M Disk Image (VSCode + Dev Container Environment)  
  Generate `DISK00.IMG` with `z80/cpm22/image`, which is the CP/M disk image binary file.

    ```bash
    vscode@Z80ATmega128:/z80/cpm22/image$ make
    mkdir -p ./tmp
    wget -P ./tmp http://www.cpm.z80.de/download/cpm22-b.zip
    --2023-10-10 16:04:18--  http://www.cpm.z80.de/download/cpm22-b.zip
    Resolving www.cpm.z80.de (www.cpm.z80.de)... 92.205.48.95, 2a00:1169:103:9b30::
    Connecting to www.cpm.z80.de (www.cpm.z80.de)|92.205.48.95|:80... connected.
    HTTP request sent, awaiting response... 200 OK
    Length: 42510 (42K) [application/zip]
    Saving to: ‘./tmp/cpm22-b.zip’

    cpm22-b.zip                  100%[============================================>]  41.51K   124KB/s    in 0.3s    

    2023-10-10 16:04:20 (124 KB/s) - ‘./tmp/cpm22-b.zip’ saved [42510/42510]

    unzip -o -d ./tmp ./tmp/cpm22-b.zip
    Archive:  ./tmp/cpm22-b.zip
    inflating: ./tmp/CPM.SYS           
    inflating: ./tmp/DDT.COM           
    inflating: ./tmp/PIP.COM           
    inflating: ./tmp/SUBMIT.COM        
    inflating: ./tmp/XSUB.COM          
    inflating: ./tmp/ED.COM            
    inflating: ./tmp/ASM.COM           
    inflating: ./tmp/LOAD.COM          
    inflating: ./tmp/STAT.COM          
    inflating: ./tmp/DUMP.COM          
    inflating: ./tmp/DUMP.ASM          
    inflating: ./tmp/BIOS.ASM          
    inflating: ./tmp/DEBLOCK.ASM       
    inflating: ./tmp/DISKDEF.LIB       
    inflating: ./tmp/DSKMAINT.COM      
    inflating: ./tmp/READ.ME           
    rm -f ./tmp/cpm22-b.zip
    mkfs.cpm -f sdcard -b ./tmp/CPM.SYS DISK00.IMG
    dd if=/dev/zero of=DISK00.IMG bs=8192 count=1021 oflag=append conv=notrunc
    1021+0 records in
    1021+0 records out
    8364032 bytes (8.4 MB, 8.0 MiB) copied, 0.139112 s, 60.1 MB/s
    cpmcp -f sdcard DISK00.IMG ./tmp/*.* 0:
    cpmls -f sdcard DISK00.IMG
    0:
    asm.com
    bios.asm
    cpm.sys
    ddt.com
    deblock.asm
    diskdef.lib
    dskmaint.com
    dump.asm
    dump.com
    ed.com
    load.com
    pip.com
    read.me
    stat.com
    submit.com
    xsub.com
    echo `wc -c < DISK00.IMG`
    8429568
    ```

2. Creating a microSD Card
   - Format the microSD card as **FAT32**.
   - Copy `DISK00.IMG`` to the root directory. This is a mandatory step because it is the system disk.
   - `00` corresponds to drive A:. You can specify drives up to `4`(E:).
   - For instance, if you copy `DISK00.IMG` as `DISK01.IMG`, drive B: will become visible.

### 3-3. Configuration for automatic CP/M startup

Configure settings to enable CP/M startup from the microSD Card when power on.

1. Build CP/M BIOS (VSCode + Dev Container environment)  
   Generate `bios.ihx` with `z80/cpm22/bios`. This is an Intel HEX format file.

    ```bash
    vscode@Z80ATmega128:/z80/cpm22/bios$ make bios.ihx
    asz80 -l -o  bios.asm
    
    aslink -i bios.ihx bios.rel
    
    ASlink >> -i
    ASlink >> bios.ihx
    ASlink >> bios.rel
    ```

2. Flashing BIOS to EEPROM
   1. Connect the AVR serial interface to the terminal.
   2. Utilize the AVR Tiny Monitor's xload command to deploy the BIOS in Intel HEX format to SRAM. Transmit `bios.ihx` by the XMODEM protocol using terminal software. As the BIOS is designed for a 62K CP/M, the binaries should be loaded starting from address 0xf200.

        ```text
        >xload
        Start XMODEM within 90s...

        Received 2816 bytes.
        ```

   3. Transfer the downloaded BIOS image to address 0 of the ATmega128's EEPROM. This process may take some time to complete. The first 4 bytes of the EEPROM contain the BIOS's starting address (0xf200) and its length (0x00b0).

        ```text
        >esave2 0 $f200 2816
        >
        ```

### 3-4. Functionality Test

  1. Connect the AVR and Z80 serial interfaces to the terminal.
  2. Insert a microSD card with the CP/M image file into the slot.
  3. Turn on DIP switch SW1 (CP/M start mode), turn off SW3, and press the RESET button.
  4. The AVR serial terminal will display the following prompt. The BIOS is copied from the EEPROM to SRAM, after which the BIOS reads the CCP+BDOS from the reserved track on the microSD card and initiates CP/M.

     ```text
     === CP/M mode ===
     BIOS: 0xf200 - 0xfcff
     
     ATmega128 Tiny Monitor
     >
     ```

     If the following is displayed on the Z80 serial terminal, it is successful.

     ```text
     62K CP/M-80 Ver2.2 on Z80ATmega128
     BIOS Copyright (C) 2023 by 46nori
     
     A>
     ```

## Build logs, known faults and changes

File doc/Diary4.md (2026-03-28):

#

## [以前の日記](Diary3.md)

## 2024/1/15

些細なドキュメントのバグを修正。

## 2024/1/21

CP/MのDISKイメージを操作する[cpmtools](http://www.moria.de/~michael/cpmtools/)、DISKのフォーマットが`/etc/cpmtools/diskdefs`に定義されているものしか指定できず不便。ドキュメントを読んでも任意の`diskdefs`を指定する方法がなさそうなので、いっちょ修正してやろうかとソースを読み始めた。

cpmfs.c

```c
  if ((fp=fopen("diskdefs","r"))==(FILE*)0 && (fp=fopen(DISKDEFS,"r"))==(FILE*)0)
  {
    fprintf(stderr,"%s: Neither `diskdefs' nor `" DISKDEFS "' could be opened.\n",cmd);
    exit(1);
  }
```

なんだ、カレントディレクトリに自分好みの`diskdefs`を置いとけばいいのか...。  
ということで、[Issue#13](https://github.com/46nori/Z80Atmega128/issues/13)を修正した。

## 2024/1/23

**「入門/実習/応用 CP/M」 村瀬康治 著 アスキー出版局**
この3部作は定番の参考書だった。だが1981,1982年の出版なので、もはや入手は難しい。ところが[INTERNET ARCHIVE](https://archive.org/details/cp-m-ascii-series)に収録されているのをたまたま発見した。ありがたや。

## 2024/4/20

あぁ、ついにZ80がディスコンに...。

- [Z84C00 End of Life/last Time Buy Notification](https://www.mouser.com/PCN/Littelfuse_PCN_Z84C00.pdf)
- [The legendary Zilog Z80 CPU is being discontinued after nearly 50 years](https://www.techspot.com/news/102684-zilog-discontinuing-z80-microprocessor-after-almost-50-years.html)

## 2024/8/25

CP/Mを再配布していものかはっきりしなかったので、CP/M本体は[The Unofficial CP/M Web site](http://www.cpm.z80.de/)から、オンデマンドでコピーしてビルドするようにしている。

しかし、本プロジェクト開始のわずか約半年前(2022/7/9)にClarifyされ、実はライセンス問題は解決してたことに気づいた。

- [CP/M's open-source status clarified after 21 years](https://www.theregister.com/2022/07/15/cpm_open_source/)
- [License agreement for the CP/M material presented on this site](http://www.cpm.z80.de/license.html)

## 2026/3/12

CP/M上で動くZORKを、AIで自律攻略することを思いついた。
以下のような構成で、MCPサーバー経由でZ80ATmega128を制御できるようにし、GitHub CopilotのAIエージェントがゲームを攻略させる。

```text
GitHub Copilot → MCP Server → Z80ATmega128
```

ということで、まずはシリアル経由でMCPサーバーを作った。  
GitHub: [mcp-serial-bridge](https://github.com/46nori/mcp-serial-bridge)

VSCodeのチャットからプロンプトを読み込ませ、チャットでプロンプトを読み込ませて指示を行う。

```text
#file:prompt_zork1.md を読んで、ゲームの攻略を開始してください。
```

LLMの種類によってかなり動きが異なる。

コンテキストサイズ、能力面からClaude Opus 4.6を試してみたが、プラムアムライセンスを三倍消費するくせに、シリアルデータをうまく取り込むことからおぼつかなかった。Claude Sonnet 4.6の方がだいぶましだった。GPT-5 miniは、いちいち指示待ちで、自律動作には程遠い。GPT-5.4が一番バランスがとれている印象。

### 攻略の様子

Zork攻略 (https://youtu.be/9ECWXsUKDJA)

LLMモデルがGPT-5.4のときの攻略の様子。  
最終的にCP/M側がハングアップしてしまった。(T_T)

### プロンプト: prompt_zork1.md

```text
# Zorkの自律攻略

あなたはテキストアドベンチャーゲーム「Zork I」を攻略する自律プレイヤーです。人間の力を借りずに、ゲームと対話しながら自力で攻略してください。

## ゲームの起動

MCPサーバー(mcp-serial-bridge)を使用し、シリアルポートに接続されているCP/Mマシンを遠隔操作します。

1. ポートの一覧を取得して、適切なポートに 19200bps で接続してください。
2. "DIR"コマンドでファイル一覧を取得します。十分なタイムアウトを設定し、プロンプト'>'を待つようにしてください。
3. ファイル一覧が取得できたら、"ZORK1"を実行し、ゲームを起動します。十分なタイムアウトを設定し、プロンプト'>'を待つようにしてください。
4. ゲームが起動したら、以下の指針に従い、ゲームの攻略を開始してください。

## 目的

世界を探索し、アイテムを収集し、パズルを解き、可能な限りスコアを最大化してください。
あなたには現在のゲーム状態の要約が与えられます。
その情報をもとに状況を分析し、次に実行するコマンドを決定してください。

## 重要な行動方針

1. 新しい場所やオブジェクトを発見する探索行動を優先する
2. 見えているオブジェクトには積極的にインタラクションする
3. 同じ行動を繰り返して進展がない場合は別の行動を選択する
4. 新しい出口がある場合は移動を試す
5. アイテムは可能なら取得する
6. 無意味なコマンドの繰り返しを避ける
7.人間のインタラクションを求めない。自律的に行動を繰り返す。

## コマンド制約

出力するコマンドは必ずZorkの有効なコマンド形式にしてください。
使用可能なコマンド例:
look
inventory
north
south
east
west
up
down
open <object>
take <object>
drop <object>
read <object>
attack <target>
enter <location>

## 思考プロセス

以下の手順で考えてください。
1. 現在の状況を短く分析する
2. 可能な行動候補を3つ考える
3. その中から最も有望な行動を選択する

## 行動選択のルール
- 同じコマンドが直近2回実行され進展がない場合は選ばない
- 新しい場所や情報が得られる可能性の高い行動を優先する
- 可能なら未探索の出口を試す
- 見えているオブジェクトには優先的に行動する

## 出力フォーマット（必ずこの形式で出力すること）

Thought:
現在の状況の簡潔な分析

Candidate Actions:
1. <候補コマンド>
2. <候補コマンド>
3. <候補コマンド>

Best Action:
<選択したコマンド>

Command:
<実行するコマンド>

## 追加ルール

- 出力するコマンドは必ず1つだけにする
- コマンドは短く簡潔にする
- 無効なコマンドを作らない
- 同じ行動の無限ループを避ける

```

## 2026/3/16

電源への12V印加による故障解析のメモ。

### 症状

- AE-CH340E-TYPECは死亡
- AVR側は生きているっぽい。
- AVR側モニタの`test`コマンドによるメモリテストは正常
- `reset 0`でHALT LEDが点灯しないので、Z80側のグルーロジックはどこか壊れている可能性あり。

### 切り分け手順

1. **リセット信号**
   - 故障範囲：リセットIC
   - 前提：Z80側のメモリI/Oのロジックが無傷
   - 確認方法：U15を外す。「reset 0の実行後、トグルスイッチの電源を素早くOFF/ON」 でHALTのLEDが光れば故障している。
     1. AVRからSRAMにHALT命令が書き込まれる。
     2. Z80電源レベルでリセットが掛かる。
     3. メモリの電荷が抜ける前にHALT命令をフェッチして実行、/HALT信号がアクティブになる。
   - 対応：リセットIC交換 U14,U15(DS1232)

2. **クロック信号**
   - 故障範囲：クロック回路
   - 前提：
   - 確認方法：Z80のクロックに4MHzが来ていれば問題なし。
   - 対応：U4(74HC04), U12(74HC74)の交換

3. **/WAIT信号**
   - 故障範囲：/WAIT信号生成回路
   - 確認方法：Z80の/WAIT入力がLowか？Highなら問題なし。
   - 対応：/WAIT生成回路周りを交換 U10(74HC32), U13(74HC32), U7(74HC08), U12(74HC74)

4. **制御ロジック**
   - 故障範囲：Z80側のメモリ, I/O制御ロジックIC
   - 確認方法：なし
   - 対応：U3,4,6〜12の交換

5. **バストランシーバ**
   - 故障範囲：Z80とAVRのメモリ排他を行うバストランシーバ
   - 前提：制御ロジックは生きている
   - 確認方法：なし
   - 対応：U3(74HCT574), U6(74HCT245)の交換

### 反省点

- VCC(+5V)はレギュレータで生成する。あるいは過電圧保護回路を追加する。
- VCC(+5V) → AE-CH340E-TYPECのVCC間にショットキーバリアを挿入し、VCCからの逆流による破壊を防ぐ。

### 改善点

- AE-CH340E-TYPECを切り離して直接RX/TXをプローブできるピンを追加しておく。
- HM62256はTTL互換だがプロセスはCMOSなので、74HCT574は74HC574でも問題ないはず。
- CMOS版Z80Aを使用するなら、74HCT245は74HC245でも問題ないはず。

## 2026/3/23

- 2026/3/12のハングアップの調査を探るために、Claude Opus 4.6を使ってコードレビューを行い、修正計画を作成した。プルリクエストとしてPR#19〜#32 を登録。

## 2026/3/24

- 動作確認用ブランチ `bugfix/BUG_working` で動作確認を実施。PR#19〜#31をマージした。

- `DISK00.IMG`の生成で以下のエラーが発生した。

   ```bash
   vscode@Z80ATmega128:/z80/cpm22/image$ make
   mkfs.cpm -f sdcard -b ./tmp/cpm22/CPM.SYS DISK00.IMG
   ' in line 9nvalid OS type `2.2
   make: *** [Makefile:41: DISK00.IMG] Error 1
   ```

  - 原因は`diskdefs`の改行コードが`CRLF`でパースに失敗するから。**Windows環境**での問題。
  - [Issue #33](https://github.com/46nori/Z80Atmega128/issues/33)を登録した。

## 2026/3/24

故障した基板の修理を行なった。
- **Z80, HM62256(SRAM)は完全死亡で交換。**
- **ATmega128は半死状態で交換。** AVR側モニタは動いていたが、Z80側のシリアルが壊れていた。
  - Fuseの書き換え、ファームの書き込み、EEPROMにCP/M BIOSの書き込みを実施。
- DS1232や74AC573は生きていた。
- **その他の74系標準ロジックは念の為交換。**
- レギュレータで3.3Vを供給している74HC4030やSDカード周りは問題なし。

ATmega128はQFPなので交換が大変。自動はんだ吸取機はないよりマシ程度であまり使い物にならない。
グラインダでチップの足を削ったが、一歩間違うと基板に致命的なダメージを与えるのでやめた方が良い。
さらにハンダこてでピンを温めながら力をかけてはぎとった。うまく行ったがこれは運みたいなもの。やはりヒードガンが欲しい。

## 2026/3/28

- 3/23から対応していた[バグ修正計画1](./bugfix/BugFixPlan1.md)の内容は動作確認用ブランチ `bugfix/BUG_working` にマージ済み。
- 特に問題なさそうなので、developブランチにマージし一旦完了。

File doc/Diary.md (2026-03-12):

# 開発日記

2022年の年末あたりにパーツ箱からZ80を発掘したことをきっかけに妄想を始める。冗談半分で回路図を描き始めたが、ガチで取り組んでみる気になったので、日記をつけながら進めることにした。

## ポリシー

- 面白そうだと思ったらやる。
- 納得するまでやる。
- 過程を楽しむ。
- ツラくなったら休む。

## 2023/2/25

- 回路は大体固まったので、検証用プロトタイプの仮組み検討を開始。
- KiCadの基板ツールで部品配置を検討しようとしたものの、配線が複雑すぎて気が散るので、実際の基板と部品を眺めながら感覚で配置を決定。
- 基板は手元にあった秋月の[片面ガラス・ユニバーサル基板Ａタイプ2.54mmピッチ(155x114mm)](https://akizukidenshi.com/catalog/g/gP-04708/)を使用。かなり詰め込まないと部品が乗り切らない。  
 
- 回路図にない[USBシリアル変換モジュール](https://akizukidenshi.com/catalog/g/gK-14745/)は、秋月電子のモジュール。この基板の外で信号変換するのが不便なので載せることにした。あとで回路図に反映せねば。でもKiCadの部品を追加定義しないといけないので面倒。誰か作って公開してないかな。

## 2023/2/26

- まずはAVRを動作させないことには話にならないので、以下の配線を行う。
  - ATmega128は64pinのTQFPなので、ピッチ変換基板への取り付け。
  - 電源
  - リセット回路
  - クロック回路
  - ISP接続コネクタ
- ICソケットなどの大物部品も仮配置してみた。固定しておかないと忘れそうなので、落ちない程度にハンダで仮留め。  
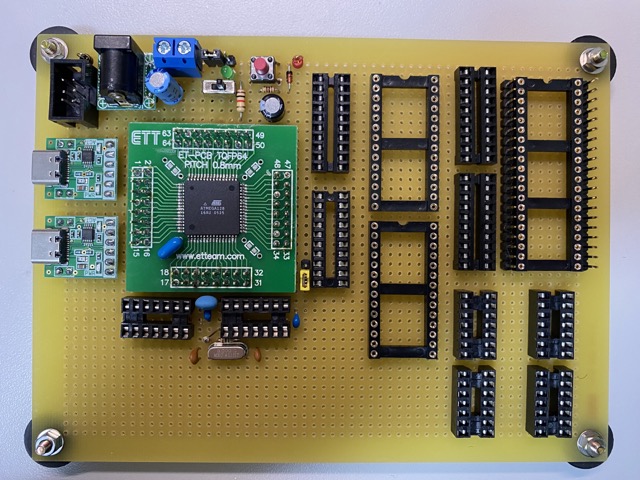
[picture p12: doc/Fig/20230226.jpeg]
  
- [実装手順](Progress.md)を書いてみた。

## 2023/2/27

- ISPまわりの配線を行っていると、微妙に74HC125や74HC04のゲートが間に挟まってることに気づく。CMOSなので未使用ゲートの入力放置はNG。ラッチアップ起こして最悪壊れる。なにこれ、もう配線しないとダメなヤツじゃん。
- ということで、AVR/Z80間の制御信号の接続、Z80のクロック回路、WAIT回路あたりの、標準ロジックを使った部分を全部配線した。これでSRAMとバスバッファ、トランシーバー以外のICを載せてデバッグできるようになった。
- ちなみにアドレスバスとデータバスについては迂闊に手を出せない。配線量が膨大なので中断すると絶対に訳がわからなくなる。やり切る時間を確保し覚悟を決めて臨まなければならない。配線面は線材でモリモリになるだろうし、あとで大きな修正が必要になったら悲惨。
- ということで、AVR側の基本動作が確認でき、簡易モニタが動いてデバッグ可能になるまで結線作業は封印しておくことにする。

## 2023/3/4

- 注文していたaitendoの[マイクロSDソケットwith基板 DM3AT-2P](https://www.aitendo.com/product/16641)と3.3Vの3端子レギュレータが届いたので、基板に搭載した。SDカード周りだけは3.3Vなので74HC4050で信号変換している。何の理由で買ったかさっぱり覚えていないのだけど、たまたま手元に持っていた。
- 実際にCP/Mが動くまではSDカードは必要ないので、確認はかなり先になるはずだけど、配線するとモチベーション上がるな。  
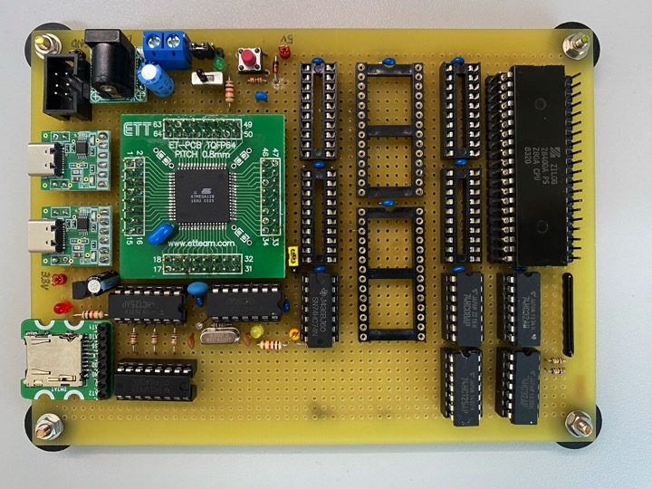
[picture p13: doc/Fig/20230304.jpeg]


## 2023/3/5

- 今日から実際にATmega128を動かしながら、ハードの動作確認を始める。
- まずはデバッグ用SWを流し込むため、SW開発環境の準備を行う。Windowsに[Microchip Studio](https://www.microchip.com/en-us/tools-resources/develop/microchip-studio)をインストールし、[AVRISP mkII](https://www.microchip.com/en-us/development-tool/ATAVRISP2)の接続の準備をする。適当にATmega128A用のProjectを作り環境を構築。
- Microchip Studio上でAVRISP mkIIが認識できたらプロトタイプ基板のコネクタに接続する。LEDが緑に点灯すれば問題ない。が、赤点滅に。RESET回路の配線が間違っていたので改修した。
- 次にAtmega103互換モードの解除とクロック設定を変更しないといけないのでFuse bitを書き換える。成功すれば、ISPの結線確認とSWの流し込みの準備ができたことになる。
- 書き換え実行でエラーも出ず、電源OFF後も書き込み値が残っているので問題なさそう。

## 2023/3/12

- 最近プライベートで使用するPCはもっぱらM2 Macbook Airになっている。爆速、ファンレスでバッテリー持ちが良く、場所を選ばず使用できる。仕事部屋に篭って作業してると家族の印象が悪いので、こいつで開発できると理想的。
- KiCadはMacOSに対応しているのでOK。問題はMicrochip Studioだ。対応がIntelのWindowsのみ。なんとかならないかと思ってた矢先、Paralles Desktop 18のニュースを思い出した。ARM版Windows11の動作環境としてマイクロソフトが公式に認めたとのこと。
- 早速お試し版をインストールしてみた。Windows自体はストレスなく動く。アクティベートなしにWindows11 Proの使用継続が認められているのも素敵。Microchip Studioもエミューレーションで動作するし、そこそこ早い。だがAVRISPmkIIがどうしても認識しない。それっぽいドライバを探してみるもインストールでエラーが出る。ちょうど確定申告でUSB接続のパソリを使いたかったので試してみたが、これも認識せず。デバイスドライバはネイティブ版が必要らしく、鬼門のようだ。
- ということで、MacでのSW開発は諦めることにした。ビルドは問題ないしシミュレータも動くので条件を選べば使えるのかもしれないが、やはり実機接続できないのは辛い。

## 2023/3/18

- 正式なAVR側のSWを書き始める。Microchip Studioを起動し、AVR 8-bit X8C application projectを作成。
  1. File>New>Projectを選択。
  2. 左のペインで"C/C++"を選択。
  3. 右のペインで"GCC Executable Project"を選択。
  4. Name, Location, Solution nameは適宜設定。
  5. Device Selectionでは"ATmega128A"を選択する。
- 便利そうなのでASF(Atmel Software Fundation)で提供されるモジュールも選択してみた。
  1. ASF>ASF Wizardを選択。
  2. 初回はBoard Selection Wizardが Pop upするので、"User Board template - megaAVR"を選択。
  3. テンプレートに従ってソースファイルが生成される。
  4. Available Modulesからモジュール選択ができるので、以下を選択すると、ソースファイルが追加される。
     - Delay routines (service)
     - Interrupt management (Common API) (service)
     - IOPORT - General purpose I/O service (service)  

- まずはGPIOの初期設定と単純なピン操作の実装から始める。
- Z80のBUSACKの状態をモニタするLEDを利用してみる。GPIOでBUSACKをアクティブにすると、Z80がBUSACKをLowにするのでLEDが消灯するはず。
- ASFのPORTIOライブラリのサンプルを真似して書いてみたが、全然動かんぞ。本当にSWの焼き込みできているのか？

## 2023/3/19

- IOPORTモジュールの機能で、PORT E, PORT F, PORT Gを指定するとコンパイルエラーが出るので、ソースを追ってみた。ASFの実装は、各ポートのPINレジスタを以下の構造体のベースアドレスにセットし、構造体メンバとしてアクセスする。つまりPIN/DDR/PORTのアドレスが連続している前提。

  ```c
  /* I/O Ports */
  typedef struct PORT_struct {
    volatile uint8_t PINCRL;         /* I/O Port PIN DATA READ ONLY */
    volatile uint8_t DIR;            /* I/O Port Data Direction Set */
    volatile uint8_t PORTDATA;       /* I/O Port DATA register */
  } PORT_t;
  ```

- 一方、PORT E,F,Gのレジスタマップを見ると、PORT Fは明らかに不連続になっている。PORTE,Gも連続しているものの、PORT A,B,C,Dとはアドレスが離れている。データシートをよく見ると、PORT E,F,Gは拡張I/Oレジスタ領域に存在する。どうもASFでサポートされるのはPORT A,B,C,Dだけのようだ。
- 釈然としないが、よく使うのはPORTDなので、まぁ良しとするか。

## 2023/3/26

- とりあえずPORT A,B,C,DだけIOPORTモジュールで操作するコードを試しているが、まだ動かない。
- ライブラリのコードを追ってみると、PORTA/B/C/Dのベースアドレスのマクロ定義がおかしいようなのでパッチを当ててみた。

## 2023/3/29

- いろいろハマっているASFのIOPORTモジュール、あきらめて削除した。動きが謎だし、生成されたアセンブリコードも無駄が多かったので。従来のマクロを使った方法でも問題ないので、こっちに切り替える。ソースの可読性や移植性は良いのかもしれないが、明らかにPORT E,F,Gに対応できていないので、一貫性のあるコードは書けないし、一品ものなので移植性はそもそも問題にならない。
- delay()が動くように調整する。クロックの設定のマクロ定義の方法がいまいちわからない。とりあえずオシロでパルス幅を測定したら、まぁまぁ期待通りの時間になっているのは確認できた。usオーダーだと誤差が多いな。
- F_CPUの値が16000000にならないので、後々時間計算で面倒なことになりそうだが、今は目を瞑って先に進むことにする。
- いまのところASFの印象悪い。

## 2023/3/31

- XMEMインターフェースのレジスタ設定をあまりよく読んでいなかったので、ATmega128のデータシートを熟読する。
- 大体理解できたので、レジスタ設定を途中まで書いたが、簡易モニタ動かすのが先だなと思って中断した。先にUARTの設定をやってしまおう。

## 2023/4/1

- USARTの入出力の動作確認を行う。リードライト共にC言語で2行で書けてしまう。8bit、非同期、ノンパリティ、1ストップビット、9600baudの設定で、CH0/1ともに動作テスト完了。瞬殺！
- ATmega128依存の低レベル入出力関数群を作成。割り込みを使用しないポーリング方式なので簡単に書ける。
- プロトタイプ基板には、回路図に記載していない秋月の[USBシリアル変換モジュール](https://akizukidenshi.com/catalog/g/gK-14745/)を2CH分搭載した。USB-CでPCのTera Termと接続して確認。
- UARTで文字が出せるようになったので、C標準ライブラリに似せたコンソール入出力関数群 x_putchar(), x_getchar(), x_puts(), x_gets()を作成。これでデバッグがダントツに楽になる。シンボル衝突を避けるために関数名には'x_'のプリフィックスをつけている。割り込みはまだ手をつけていないので、Bufferd I/Oは未サポート。
- XMODEMでタイムアウト付きの1文字入力が必要になるので、getchar_tout()という独自の関数を作成。割り込みは使わず一定時間ウエイトしながら入力をポーリングする。9600baudだとms単位のウエイトは長すぎるためdelay_us()を使用している。しかしus単位だと積算誤差が非常に大きくなってしまうので、タイムアウト値は実測して調整が必要。
- いずれZ80のコードを流し込むのに必要になるので、XMODEM送受信の関数を作成。本当はもっと後でもいいのでだけど、気が向いたので。コンソール入出力関数と組み合わせてなんとなく動いたことを確認。XMODEMは45年も前の化石みたいなプロトコルだけど、TeratermやPuTTYでもサポートされているし、こういう用途だとまだまだ現役で使えるな。
- 次に簡易モニタプログラムの雛形を作成。コマンド名とそのそのハンドラ(関数ポインタ)のペアのテーブルを用意しておき、以下のメカニズムでコマンド処理するという、至極簡単なもの。
  1. 1行入力を空白文字でトークン分割し、配列にトークンのポインタを格納。
  2. 配列の先頭要素の値でコマンド名をlookupし、マッチしたハンドラを呼び出す。
- バイト書き込み、読み込みコマンドを書き殴って今日は終了。たぶんちゃんとは動かない。
- まともにCのコードを書くのは5年ぶりくらいだけど、だいぶ勘が取り戻せた。10代の頃にマスターした言語は、体に刷り込まれている感じ。

## 2023/4/2

- gets()は簡単にバッファオーバフローして危険なので、get_s() に乗り換えることにした。バックスペース処理や、不要な文字コードを無視する処理も追加。これでモニタの入力部分がそれっぽく動くようになった。昔から疑問なんだけどgets()のバッファ溢れなんてほとんど自明なのに、何でこんな変な仕様にしたんだ？
- ヘキサダンプは比較的綺麗に書けたと思う。バイト書き込み、読み込みのデバッグもして、最低限のモニタプログラム完成。
- ヘキサダンプとバイト読み込みは、パラメータなしでもアドレスオートインクリメントで表示できるようにした。パラメータなしでも次を表示してくれるので地味に便利。
- XMODEMを使ったバイナリ転送もサポートした。
- 自前のコンソール入出力関数群は xconsoleio.[ch] に分離した。
- この2日で作った機能はハードウェアデバッグには必須。毎回書くのは無駄なので、切り出して再利用可能な形にまとめよう。

## 2023/4/3

- 簡易モニタとXMODEMのリファクタリング。
- XMODEMをxmodem.[ch]に分離した。こいつも再利用可能な部品にしよう。
- SRAM接続の確認ができる環境になってきたので、XMEMインターフェースの設定まわりを実装するか。
- ところで内蔵FlashROMと外部SRAMのアドレスってどういう関係なんだっけ？データシート確認しないと。

## 2023/4/4

- 思い出した。AVRはハーバードアーキテクチャなのだった。つまり内蔵FlashROMとRAMはアドレス空間が独立してるってことだ。簡易モニタのメモリアクセスコマンドは、RAM空間しか考慮していなかった。まぁそれでもいいのだけれど、なんか悔しいのでメモリダンプコマンドだけはFlashROMにも対応させた。
- ちなみにROM空間とRAM空間ではアクセスは命令が異なる。ROM空間へのバイトアクセスは効率が悪いため、メモリダンプの1行分16バイトをRAMに転送後、表示するように書き換えた。メモリ転送はmemcpy_P()を使用。FlashROMアクセスのためのマクロや関数を使用するには<avr/io.h>と<avr/pgmspace.h>をインクルードする必要がある。
- [この記事](https://garretlab.web.fc2.com/arduino.cc/docs/learn/programming/memory-guide/)を参考に内蔵SRAMの残量表示のコマンドを追加した。AVRベースのArduino用のコードだがたぶん使えるだろう。
- なんか寄り道してしまったな。。明日こそはXMEMインターフェース対応をやろう。

## 2023/4/5

- 内蔵RAMのメモリダンプを眺めていたら、helpコマンドの文字列リテラルがあるのに気づいた。const指定しているのになぜ？と思ったが、よく考えたらハーバードアーキテクチャなのでFlashROMにはインストラクションしか配置されない。つまりリテラルはたった4KBしかない貴重な内蔵SRAMに配置されてしまうのだ。くっそー、ハーバードアーキテクチャめんどくせーなー。。
- AVRではこんな感じでリテラルを強制的にFlashROMに配置し、使うときだけSRAMにコピーするテクニックがあるようだ。この辺のセコさは組み込みならでは。

    ```c
    #include <avr/io.h>
    #include <avr/pgmspace.h>
    const char foo[] PROGMEM = "hogehoge"; 
    a = pgm_read_byte(&foo[i]);
    ```

- やっとXMEMを整理した。こんな感じで外部SRAMの全領域にアクセスできるようになるはず。
  - 0x0000-0x10ffまでの4352bytesはATmega128の内蔵メモリが割り当てられており、外部SRAMの同エリアにはAVR側から直接アクセスできない。この領域にアクセスするためには、以下のように設定する。
    - アドレスバスの上位バイトに割り当てられているPORTCの上位数ビットをIOポートに切り替え、強制的に0をセットすることで外部SRAMのアドレス空間を狭める。
    - 無効化された空間は、外部SRAMの0番地からのシャドウとしてマップされる。内蔵SRAMは 0x0000-0x10ff なので、ここが隠れる 0x2000 以降をシャドウに割り当てる。XMCRBのXMM2/1/0を0/1/1にセットすればよい。
    - これでAVR側からは0x2000-0x30ffにアクセスすることで、外部SRAMの0x0000-0x10ffを間接的に触れるようになった。(データシートによると、この状態で0x3100-0x3fffのアクセスは非推奨なので触らないようにする。)
  - 簡易モニタでは、Z80との共有メモリ前提での操作が多いはず。外部SRAM主体の操作にして、内蔵メモリのアクセスは別コマンドを割り当てた方が使い勝手が良さそうだ。

## 2023/4/7

- 簡易モニタのhelpコマンドの文字列リテラルを配列で定義し、FlashROMに配置させるように変更した。内蔵RAMが320byteも節約できた！
- XMEMの検討結果に基づき外部SRAMのダンプ機能も実装した。メモリ境界をまたぐ際のシャドウの切り替え処理が面倒。プロトタイプ基板の外部RAM周りの結線を行っていないので、ちゃんと動いているのかは不明。
- デバッグの準備も整ったし、いよいよバスライン結線作業の封印を解くか。。。

## 2023/4/8

- バスラインの結線作業を今週末でやり切ることに決心した。
- AVR、Z80, SRAM2個、これらの間にアイソレート用の3ステートバッファやトランシーバが挟まる。結線量を計算してみると、上位アドレス40本、下位アドレス48本、データバス48本。延べ136本。(泣)
- 上位アドレス、下位アドレスの順にアドレスラインを結線を完了。ぶっ通しで6時間かかった。作業順序はこれで正解だったと思う。明日はデータバスに着手予定。
- しかし老眼が進行していて半田付けが辛い。ヘッドルーペ買おうかな。

## 2023/4/9

- データバスの結線作業も完了した。結線のチェックを一通り行い、全ICを装着して電源投入。一応起動することは確認できた。  
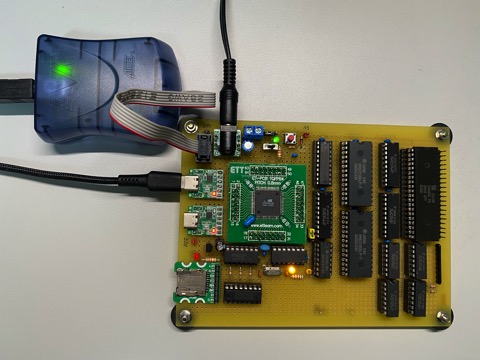
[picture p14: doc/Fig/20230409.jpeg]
  
- 回路を一部更新。NMI割り込みでコールされる0x66番地はCP/Mではシステムエリア内だし、/HALTを使うようなプログラムも書くことはないと考えていたが、Z80の動作確認やハードのデバッグに使えそうなので、余っているPORTB6,7に接続することにした。
- 外部SRAMへのバイト読み書きコマンドを簡易モニタに追加し、外部SRAMの動作確認を開始。
- なぜか外部SRAMのダンプがハングアップする。SRAMアクセス時にはZ80からバスアクセス権を取得するために/BUSREQをアクティブにし、/BUSACKがLowになるのをポーリングする。が、これが反応していない。明日以降オシロでZ80側の信号を確認してみるか。GPIOの初期化部を変更したので、バグ仕込んで単に読み取れなくなっているだけかもしれない。
- 0x1100-0xFFFFまでアクセスする場合も、DMAモードに切り替えないといけないことに気づいた。この対応も入れねば。
  
## 2023/4/10

- バスラインの配線してから、AVRISPmk II経由でのファーム書き換えに失敗するようになったのだが、理由がわからん。時々成功するのでタチが悪い。
  - シリアルモニタ用UART CH0のUSB-Cコネクタを外すと成功率が上がる気がする。でもダメな時は徹底してダメ。
  - Microchip Studioの設定(Tools>Device Programming>Interface Settings)で、AVRISP mkIIの通信速度を16.1KHzあたりまで落としても改善されない。
  - AVRISPのSCK(3pin)と、SD Card用のSPIのCLK(11pin)の衝突防止用3ステートバッファの信号の引き回しが長いので直結してみたが、症状変わらず。ロジアナでSCK/MSIO/MSIOをモニタして見るが特に問題はなさそう。
- 他にもZ80の4MHzクロックが生成されたりされなかったりと謎の動きも観測。バスラインの配線以降、全体的に何かがおかしい。

## 2023/4/11

- Z80のクロックの問題、74HC74のクロック分周回路の配線間違いが原因だった。/Sと/RをGNDに接続していたため出力が不定になっていた。/RをVccに接続し直して解決。たまたま条件が揃ったときだけクロック出力されていたのかもしれない。
- /BUSACKも正しく返るようになった。Z80にクロックがきちんと供給されていなかったのが原因だった模様。
- 相変わらずAVRISPmk IIの調子が悪い。故障を疑い、ATmega328の載った別の回路で試してみるとCPU情報がちゃんと取れる。やはりプロトタイプのハード問題か。
- 簡易モニタが立ち上がらない場合があるので、リセットボタンや電源の連続OFF/ONしてみる。シリアル出力が少し出てハングアップしたり、暴走気味に文字が出力し続けたりと不安定。AVR側のプログラムのバグの可能性もあるが、起動後にHW的な外乱が入ってるようにも思える。
- パワーオンリセット、マニュアルリセット、ISPのリセットの信号をちゃんと分離したほうが良いのかも。
- ISPコネクタをプログラムの時のみ接続するようにしたら、エラーが出なくなった(気がする)。挿抜でヘッダケーブルが壊れないか心配だ。
- XMEMインターフェースの動作確認を始める。簡易モニタから外部SRAMへのアクセスコマンドを発行し、ロジアナで、/RD, ALE、アドレスバスの下位8bitを観察した。/BACK=Lowの期間に何かしているようだが、なぜか/RDがアクティブにならない。アドレスもおかしい気がする。

## 2023/4/12

- シリアルに簡易モニターのプロンプトが出たり出なかったり。やはりリセット回路に問題があるのかなぁ。今日は頭を冷やすことにした。

## 2023/4/13

- リセット回路を眺めてたら雑に見えてきたので、以下のように修正することにした。
  - ISP書き込み不具合の原因がISP /RSTの取り回しにあるのではないかと考え、他の信号と分離することにした。具体的にはパワーオン/マニュアルリセット信号とISP /RSTを分離し、ANDをとってからAVRのRESETに入力するように変更。
  - ISP /RSTがZ80のRESETをトリガしないように変更。
  - パワーオン/マニュアルリセット信号を安定させるため、CR積分回路の出力をシュミットトリガで受けるように変更。
- AND1個とシュミットトリガインバータ2個が必要なので、74HC132を使うことにした。手元に在庫がないのでを秋月に発注。動作確認は届いてから。
- 回路図を更新したが1枚に収まらなくなってしまった。リセット回路とSD Cardインターフェースは階層シートで分離した。[こういうビデオ](https://www.youtube.com/watch?v=HxMtFFiYV-E)があるのはとてもありがたい。
- KiCad 7.0がリリースされていたのに気づいた。Apple Siliconにネイティブ対応されてたので早速バージョンアップしたが、速度的な体感差はないような。

## 2023/4/14

- 今日は回路図を眺めただけ。よーわからん。寝た。

## 2023/4/15

- リセット回路、ブレッドボードの試作で波形観察して問題なさそうなので変更した。
- AVISPImk IIの接続すると橙点灯エラーに。/RSTへのプルアップ抵抗の接続忘れが原因だった。10Kを接続して解消。[マニュアル](https://ww1.microchip.com/downloads/en/DeviceDoc/Atmel-42093-AVR-ISP-mkII_UserGuide.pdf)によると、4.7K以下にしてはいけない。
- SCKのプルアップが必要な場合は820Ω以上にしろと書いてある。この信号はSD CardインターフェースのSPIクロックと共用で、10Kでプルダウンされている。一応外しておいた。あとでまた検証せねば。
- 依然としてISPリプログラムが不安定。リセット信号の問題ではないのかなぁ。
- ところでリセット回路のCR積分回路のコンデンサが1uFだと遅延時間が短すぎて、パワーオン時に電源が安定しているか不安なので、47uFに変更した。ちょっと長すぎるかもしれないが500msくらいのLowパルス保証されるようになった。本当は22uFあたりがちょうどよさそうだが、あいにく手元にない。
- 秋月で[DS1232N](https://akizukidenshi.com/catalog/g/gI-15313/)というリセットIC(60円)を購入しておいたのでこちらも試してみた。外付け部品はスイッチと抵抗1本だけ。パワーオン/マニュアルリセット両対応で、安定して700msのパルスが生成される。ただウォッチドックタイマーがOFFできないので、定期的に信号を入れてやらないとリセットが発動してしまう。これは4MHzクロックをぶちこんでおいた。部品点数少ないし、こっちに変更しようかなぁ。
- AVR、Z80にもリセットがかかっているはずなのだが、まだ何か動きがおかしい。特にZ80が不安定。なんか嫌な感じにハマったな。

## 2023/4/16

- 昨晩はZ80のリセット入力が発振しているようだったが、今日測定してみると問題ない。
- ISPは少し安定した気がする。リセットラインを分離した効果はありそう。今までは機嫌が良くなるまで赤点灯が解除されなかったが、Tools>Tools>Device ProgrammingでApplyを押せば緑点灯するようになった。
- それでもDevice Signatureの取得、FlashROMのEraseなどでエラーは出まくる。しかし一度安定すると問題なくリプログラムできるようになる。そのトリガがよくわからない。
- 簡易モニタの動作不安定はまた別。リセット後に起動しなかったり、ハングアップしたり、コマンド入力していないのでリターン入力でメモリダンプが起動したり。機嫌よく動いたと思っても外部メモリにアクセスでハングしたり。インストラクションとデータは内蔵のFlashとSRAMにあるので実行に影響があるとは思えないのだが。

## 2023/4/17

- ダメ元でZ80を止めAVRだけを動作させてみた。ジャンパピンを追加し、/BUSRQをGNDに落とす。すると簡易モニタが安定して起動するようになった。ISPのエラーも嘘のように消えた。Deive signatureの読み込みもリプログラムも問題ない！
- だが釈然としない。/BUSRQがHighのときは、Z80は裏で暴走しまくってるのでバスは滅茶苦茶なのだが、どんな状態であれ影響を受けないよう設計したつもりなので、AVR側が不安定になるはずないのだけれど。。どこかにバグがあるのかなぁ。
- AVRのリプログラムが安定して動くようになったので、以下の簡易モニタのバグを直した。これでやっと外部SRAMのデバッグができるようになった。
  - 単にリターンを入力したときdumpコマンドが実行されてしまう問題。入力がヌルの場合はトークン数が0になるが、exec_command()でこのチェックを行わずにコマンド評価をしていた。
  - 外部SRAMのR/Wコマンドがシャドウエリアをアクセスしない問題。内蔵SRAM境界の計算にマクロINTERNAL_RAM_SIZE(0x1100)ではなく、EXTERNAL_RAM_SIZE(0x10000)を使用していたのが原因。
- (備忘録) 4/15に外したSD CardインターフェースのSCKのプルダウン抵抗、元に戻しても問題ないか確認する。

## 2023/4/19

- SD CardインターフェースのSCKのプルダウン抵抗を無効にしていたが、ISPのリプログラムに影響なさそうだったので元に戻した。
- 外部SRAMのREADを行うと、アドレスの下位8bitがデータとして読めてくる？つまり0x00-0xffの連続値が繰り返し現れる。SRAMの信号を確認すると、XMEMインターフェースの/WR(PG0)と/RD(PG1)が逆に接続されており、リードで/OEがアクティブになっていなかった。改修を最小限にするため回路図の3ステートゲートの入れ替えおよび、PG0とPG1の接続を変更。
- これでREAD値がランダムになった。念の為ロジアナでPA0-PA8をモニタしてみると、まだおかしい。PA1がHighに張り付いているように見える。明日以降、配線をチェックすることにする。

## 2023/4/20

- 寝る前に30分くらいいじってみた。
- PA1がHighに張り付く問題、アホみたいな測定ミスだった。間違えて隣のVcc(52pin)をプローブしていた。(泣)
- バイト単位でWRITE/READすると動いている？インクリメント値,0x55, 0xaa, 0x00, 0xffを書き込み、リードしてチェックサム比較したが正しい？昨日から何も変えていないぞ。でもdumpするとまたインクリメント値しか出てこなくなった。
- 電源OFFで実験していたのが原因か？
- PA3(bit3)がHighにならない。アドレスもデータも。
- ロジアナの観測では、ライトは正しい信号が出ている。
- リードの問題か？

## 2023/4/21

- 使用しているデジタルオシロ(RIGOL DS1104Z Plus)のファームウェアが2022/5/30にリリースされていたので更新した。バージョンが 00.04.04 SP4 から 00.04.05 SP2 になった。手順がどこにもなかったが、downloadしたzipを展開し、DS1000ZUpdate.GELをコピーした、USBメモリをスロットに突っ込んだら認識した。更新終了後、再起動しないとバージョン番号は反映されないようだ。

## 2023/4/22

- 外部SRAMのリードの問題「アドレス下位8bitがデータとして読めてくる。」の解析を始める。
- XMEMインターフェースでは下位アドレスとデータが時分割共有されるので、PA0-7, ALE, /WR, /RDをロジアナでモニタした。
  - ライトは問題なさそう。ALEの立ち下がりでアドレスは正しく出ている。/WRの立ち上がりでのデータも期待値が出ている。
  - リードは問題あり。ALE立ち下がりでのアドレスは正しく出ている。しかし/RDの立ち上がりでのバス波形が下位アドレスのまま関わらない。(つまり簡易モニタでの表示との辻褄は合っている。)
- 74HC574と74HC245のバスラインがPA0-7とハード的に接続されているため、切り分けのため両方とも外して測定するも変化なし。これでSRAMからデータが出力されていないのがほぼ確定。
- SRAMの上位下位を物理的に入れ替えたが変化なし。チップ不良ではなさそう。
- /RD(PG1)とSRAMの/OEの接続は問題なし。
- アドレスA15をSRAMの/CSに接続しているので観測対象の下位32KB側は常にLowになる。測定結果も問題なし。
- /OE(/RD)の立ち下がり時点でアドレスは確定している。よってタイミング的に問題になりそうなのは、/OEの立ち下がりからデータが出力されるまでの時間が十分に確保されているかどうか。使用しているHM62256BLP-7のスペックだと $T_{OE}=40ns$ (max)。/RDパルス幅(/OEの立ち下がりから/RDの立ち上がり)の実測値は70ns程度あるので問題ない。1 WAITで動作させているが、2 WAITにしても変化なし。
- ソフトのシャドウ設定に問題があったので修正。AVRのXMEM関連のレジスタ設定も、何度も見直した。さらにデータシートのサンプルプログラム相当で動かしてみるも、状況変わらず。
- うーむ、、さっぱりわからんなぁ。。。別のSRAMと交換して実験してみるか？

## 2023/4/26

- おかしな現象1

  ```text
  >r
  $0000 (2000): 00
  >w 0 $55
  >r 0
  $0000 (2000): 55
  >w 1 $23
  >r
  ```

  1. リセット直後。
  2. 外部SRAMの0番地をリードする。\$0が読めた。
  3. 外部SRAMの0番地に\$55を書き込む。そこをリードする。\$55が読めた！
  4. 外部SRAMの1番地に\$23を書き込む。そこをリードする。ハングアップ。同時に/BUSACK がHighになる。リセットボタンが効かない。

- おかしな現象2

  ```text
  >w 0 $55
  >r 1
  $0000 (2000): ca
  >r 0
  $0000 (2000): 55
  >r 1
  ```

  1. リセット直後。
  2. 外部SRAMの0番地に\$55を書き込む。
  3. 外部SRAMの1番地をリードする。\$caが読めた！何の値か知らんけど。
  4. 外部SRAMの0番地をリードする。\$55が読めた！  
     2.で別アドレスを挟んでいるので、0番地のデータ残骸を見ているということはない。またALE=Low後にD8-15が0→\$55に変化しているので、SRAMからデータが出力されたと解釈できる。だが/RDの立ち下がりよりも前にデータが\$55に変化しているのが気になる。SRAMは先に/CS(D6)=Lowになっているので、データは/RD(/OE)=Low以後に出力がされるはずだからだ。
     
  5. 外部SRAMの1番地をリードする。ハングアップ。同時に/BUSACKがHighになる。リセットボタンが効かない。

## 2023/4/29

- HM62256BLP-7をHM62256ALP-10に載せ替えたが変化なし。
- Z80側のデータバス分離用の74HC574, 245だが、Z80もSRAMもTTLレベルなので入力がTTLトレラントな74HCTにしないとまずい。回路図を修正した。
- 手元に在庫がないので、千石電商に発注した。数少ないHCTの品揃えの中に両方ともあったのは幸運なのか、まだ需要があるからなのか。
  
## 2023/4/30

- 外部SRAMのリード問題解決。**原因は/RDの接触不良** だった(泣)。ロジアナでプローブしていた箇所は問題なかったが、その先の接触が不安定だった。早期に/RDまわりの配線を徹底的に見直さなかったのかが悔やまれる。
- 0x12番地へのWRITE/READ動作確認

  ```text
  >w $12 $34
  >r $12
  $0012 (2012): 34
  ```

  - ライト  
    
  - リード  
    
- AVRの起動時に、Z80を止めるために以下を実行するようにした。
  - AVRの割り込み禁止。
  - /BUSREQをLowにしてDMAモードにする。
  - 0番地にHALT命令(0x76)をセットし、HALT状態にする。
  - Z80にリセットをかける。
- Z80の/RESETのHigh後、1.5us程度で/HALTがアクティブになるのをロジアナで確認済み。命令のフェッチはできているようだ。
- 動作確認
  - Z80の/HALT信号は、AVRのPORTB(0x36番地)のPB7でモニタできる。

    ```text
    >ri $36
    $0036: 61
    ```

    MSBが0なのでHALT状態になっている。
  - 0番地で無限ループするプログラムでHALTが解除されているか確認する。

    ```text
    C3 00 00    ; jp 0
    ```

    簡易モニタで0番地から上記を書き込んでリセットする。

    ```text
    >w 0 $c3
    >w 1 0
    >w 2 0
    >reset
    >ri $36
    $0036: e1
    ```

    MSBが1なのでHALTは解除されている。
  - ということで、Z80側のプログラムを送り込んで動作確認を開始できるようになった。

## 2023/5/1

- せんごくネット通販から74HCT574と245が届いたので載せ替え。土曜日の深夜に発注して月曜日の午前中に届くなんてえらい。(日曜日定休日だと思ってんだけど。)
- Z80のリセット直後のM1サイクルを観測。/RDの立ち上がり直前のCLKの立ち上がりで0x76(HALT命令)がフェッチできている。Z80のデータバスを直接観測している。  
  
- 0番地での無限ループの実行状態。  
  
- 以上よりメモリリードは問題ない(はず)。
- USB-Cを接続していると、電源が入りっぱなしなので、結線を変更した。回路図も秋月電子の[USBシリアル変換モジュール](https://akizukidenshi.com/catalog/g/gK-14745/)への接続を想定したコネクタに変更。

## 2023/5/2

- パーツ全載せで動かしているので、安定化電源で消費電力を測定してみた。目視で最大294mA。USB-Aでは最大2.5W、5Vなので500mAまで取れるので、USB給電でも問題ない。使用している秋月電子の[USBシリアル変換モジュール](https://akizukidenshi.com/catalog/g/gK-14745/)は350mAでリミットがかかるがまだ少し余裕がある。  
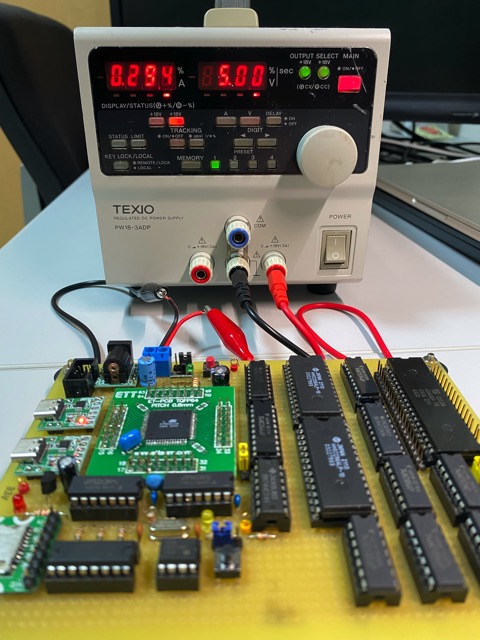
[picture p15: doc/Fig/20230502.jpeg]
  
- プロト基板に追加した回路とKiCadの回路図に少し乖離が出てきたので、忘れないように更新した。冗長な部分もあるが、動作確認完了後に最適化することにし、今はデバッグで混乱しないようにする。
  - 秋月電子の[USBシリアル変換モジュール](https://akizukidenshi.com/catalog/g/gK-14745/)のシンボルを作成し回路図に反映。
  - リセットIC(DS1232N)のシンボルを作成し、リセット回路に追加。
  - +3.3V系の電源回路はSD Card Interfaceに移動。
- ハンドアセンブルが面倒なので、Z80のアセンブラ[ASZ80](https://shop-pdp.net/ashtml/asz80.htm)を使用することにした。[ここ](https://shop-pdp.net/ashtml/asxget.php)からDownloadできる。マルチプラットフォーム対応だがとりあえずWindows版でお試し。
- 次は以下のコードでZ80メモリライトを確認する。AVRの簡易モニタから0x1234に0x55が書かれていればOK。
  - 0番地のHALT命令を0(NOP)で上書きし、resetコマンド1番地以降を実行する。resetコマンドごとに信号をモニタする。

    ```text
                               1     .AREA   CODE(ABS)
    0000                       2     .ORG    0x0000
                               3
    0000 76            [ 4]    4     HALT
    0001 3E 55         [ 7]    5     LD A, 0x55
    0003 32 34 12      [13]    6     LD (0x1234), A
    0006 76            [ 4]    7     HALT
    ```

  - ロジアナの接続

    ```text
    PIN    Z80       SRAM      74HCT245
    D0:    CLK(6)  
    D1:              /OE(22)
    D2:              /WE(27)
    D3:              /CS(20)
    D4:                       AB(1)
    D5:                       CE(19)
    D6:    /BREQ(25)
    D7:    /BACK(23)
           AVR(=SRAMのデータバス)
    D8-15: PA0(51)-PA7(44)
    ```

- reset後に、SRAMの/WEがトリガされずハングアップする。

## 2023/5/3

- 動作が不安定。
  - 0x1234に0x55が書き込まれているのが観測できたこともある。
  - 0x0000に0x76(HALT)が書き込まれず、全メモリが0に見えるときもある。
  - リセットが効かない場合がある。Z80はOK。AVRにリセットがかからないことがあるっぽい。
  - リセット信号自体が出てこないときもある。
  - どこかに接触不良があるかもしれない。AVR側のハンダを舐め直した方がいいかも。
- ASFのDelay routinesを削除した。いい加減delay()のウエイトの不正確さが許容できなくなってきた。また中身のない関数が定義されビルド時のワーニングが出るため。ますますASFの存在意義が見出せない。今後は_delay_xx()マクロを使用する。
  - util/delay.hを使用するためには、F_CPUマクロを定義するかビルドオプションで渡す必要がある。user_board.hで#defineするようにした。

    ```text
    #define 16000000UL
    #include <util/delay.h>
    ```

## 2023/5/4

- Z80のメモリライトの問題、SRAMの/WEがアクティブにならないのが原因。/WRと/MREQのOR出力(74HC32 pin3)と、74HC125の入力(pin 2)の接続不良だった。ハンダ不良を改修し、上位下位両方のSRAM空間(0x1234, 0x8034)にZ80からライトして期待値が得られるようになった。  

- なぜか電源OFFでもクロックが出力されているのに気づいた。よく見るとLEDも微かに点灯している。どこかがショートしているということだ。不安定の原因はこれか？
- ATmega128のTQFP-64パッケージのピン、変換基板のピンヘッダのハンダを舐め直したが治らず。

## 2023/5/5

- USB-Cが接続されていると電源が落ち切らない問題。[USBシリアル変換モジュール](https://akizukidenshi.com/catalog/g/gK-14745/)はUSB側から常に給電されるので、本体の電源がOFFでもRXD, TXDには電圧がかかっている。このため接続されている74HC125とAVR側から電流が漏れてしまうようだ。
- 回路の致命的なバグに気づいた。SRAMの/CSをアドレスバスのA15で選択していたが、/CSがLowだとSRAMのデータバスがハイインピーダンスにならないのでZ80のI/Oサイクルと競合してしまう。AVRの外部メモリアクセスとZ80のメモリサイクルの時のみ/CSをアクティブにする必要がある。
  - $/CS = /RD \cdot /WR \cdot /MREQ$とし、SRAMの上位・下位の選択をA15で行うような回路を追加した。ブレッドボードで確認した限りは良さそう。
  - ORゲートが1つ足りないので、I/Oアドレスを制約していたものを利用する。
  - ANDゲートも足りないので74HC08を追加する。  
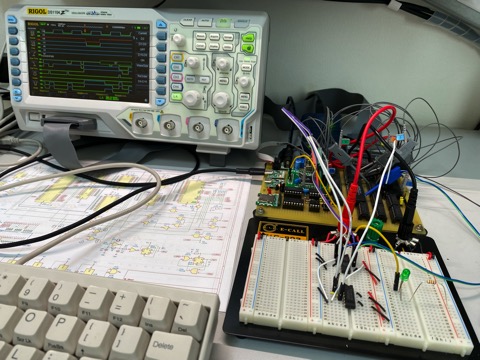
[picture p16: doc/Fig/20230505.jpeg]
  

## 2023/5/6

- 昨日のSRAMの/CS設定回路を組み込んだ。基板がてんこ盛りになってしまった。。。  
  
- 相変わらずAVR側が不安定。リセットをかけても簡易モニタが起動しない場合が頻発する。
  - ATmega128にリセット信号は入っている。
  - SWの暴走？ アセンブリレベルのコードが出力されている avr/Debug/avr.lss を調査した。
    - リセットと割り込みベクタテーブルは0番地から配置されている。
    - 0番地のリセットベクタのシンボルは__ctors_end。この中からmain()が呼ばれる。
    - main()→init_board()の先頭でcli()を実行しているので割り込みは禁止はできているはず。
  - 0番地からリセットと割り込みベクタを配置するには以下の設定が必要。が、デフォルトのままなので問題なし。
    - FUSE bit : BOOTRST = 0
    - MCUCR bit 1 : IVSEL = 0
- INT0, INT1, INT4の外部割り込みハンドラを定義し、その中でLED点灯(青、黄、赤)させるようにした。
  - 簡易モニタでメモリダンプ中にハングアップ。そのタイミングで点灯。
    - ダンプできているので冒頭のcli()の実行は確実。にもかかわらず割り込みがかかっているのは何故か？
    - 割り込みがかかる要因は？おそらくZ80が暴走してin/out命令が実行され、それがトリガになっている?
    - リセットかけても、LEDが消灯しない。main()の先頭で消灯しているので、リセット信号は20pinに入っている。しかしソフト的に再起動がかからないように見える。
  - 強制DMAモード(BREQ=Low/)でZ80を止めておくと、100%ではないが問題が改善される。
  - 割り込みハンドラを未定義にするとハングアップの確率は下がるような気がする。
  - 電源ON後にシリアルに出力されず、INT1割り込み(黄点灯)した。リセットが効かない。電源OFF/ONでも変わらず。
  - 以下の実行でLED全点灯。INT0,1,4すべての割り込みがかかるってどういうことだ？特にINT4は、AVR→Z80への外部割り込みの時にしか発生しないはず。

    ```text
                                    1     .AREA  CODE(ABS)
    0000                       2     .ORG  0x0000
    0000 3E 12         [ 7]    3     LD A, 0x12
    0002 D3 34         [11]    4     OUT (0x34), A
    0004 76            [ 4]    5     HALT
    ```

    - SRAMの/OE, /CSを観測すると、このコードでアクティブになる。

## 2023/5/8

- なぜかGoogleのサジェストで、Arduino互換機でISPの/RST入力にコンデンサを直列に入れないとスケッチの書き込みに失敗するという[記事](https://burariweb.info/electronic-work/atmega328p-sketch-wrinting.html)が現れた。行動を見張られてるようで気持ち悪い。が、リプログラムに失敗する理由かも。AVRISPmkIIの/RSTの信号だけでは不足で、一定時間内のHighレベルへの信号変化も必要ということらしい。[もう少し詳しい記事](http://kutsushita-neko.cocolog-nifty.com/blog/2013/09/arduino-e10d.html)も。

## 2023/5/13

- どう考えても割り込みハンドラが呼ばれる原因がわからないので、実機ではなくSimulatorで動作させてみた。結果、簡易モニタの入力待ちループで待機のまま。割り込みハンドラが実行されることはなかった。やはりハード的が関係しているのか。
- INT0,1,4のハード的な入力カットして確認してみるか？

## 2023/5/14

- ISPの/RSTに直列にコンデンサを入れる件、結論から言うとNG。AVRISPmkIIの橙点滅になる。元に戻した(涙)。

## 2023/5/28

- しばらく忙しかったのと、動作不安定でモチベだだ下がりだったのだが、気を取り直してデバッグ再開。
- AVRの起動不安定問題、/BREQ=GNDで起動すると症状が消えるので、Z80のリセット後の動作を考え直してみた。起動時に/BREQをLowにしてZ80を止めている隙に、AVRからSRAMにHALT命令を書き込んだつもりになっていたが、タイミング的には全然間に合っていなかった。
- Z80はリセット信号がHighになった後、2,3クロックでM1サイクルに入ってしまう。このとき/BREQがLowでもその命令は実行され、その後に/BACKを返して停止する。初回のM1サイクル前にAVRの動作を保証するためには、Z80のリセット信号をHighにするタイミングを十分に遅らせるしかない。
- 以下、Z80のリセット直後の挙動の観測結果。
  1. /BREQを強制的にGNDにしてリセットした場合。1命令フェッチ、実行後に/BACKを返している。  
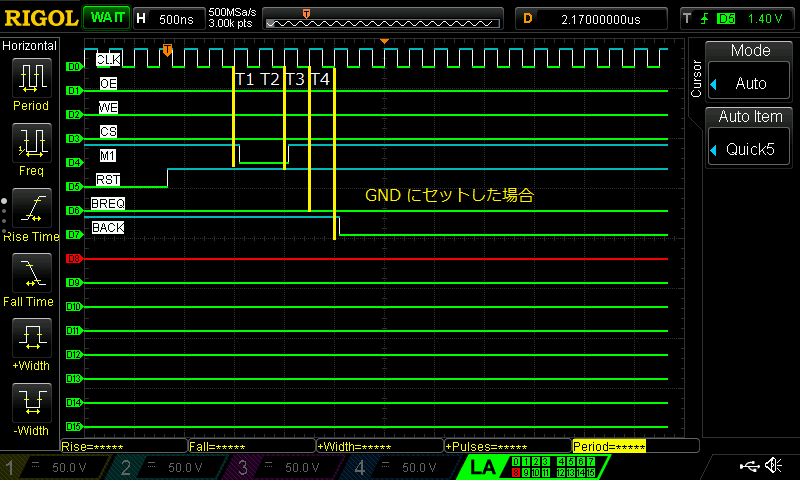
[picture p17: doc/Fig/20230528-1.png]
     
  2. /BREQをAVRのPD6に接続した場合。プルダウンはしているもののAVRの初期状態でバタつくのかLowになるまで時間がかかっている。1命令実行している。(7ステートの命令)  
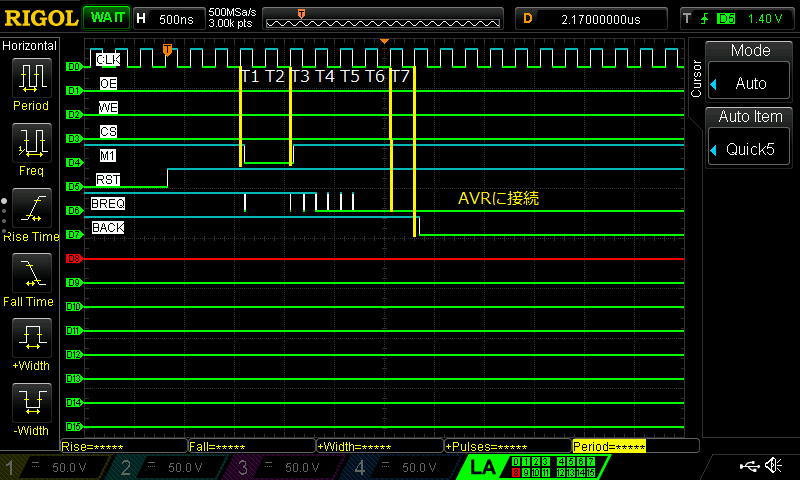
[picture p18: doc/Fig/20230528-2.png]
     
  3. 2.と同様だが、2命令実行してしまっている。(4ステートの命令x2)  
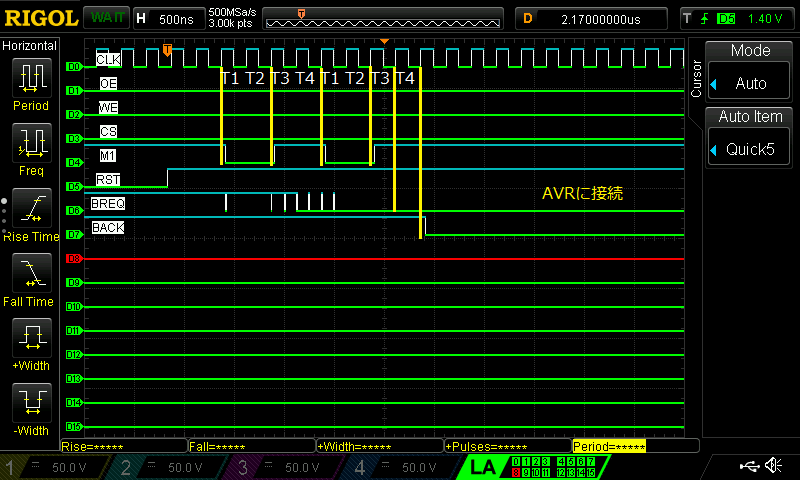
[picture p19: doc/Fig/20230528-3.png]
    

## 2023/6/3

- Z80のリセットをAVRより遅らせるための回路を検討した。リセットパルスを同時にLowにし、HighになるタイミングをZ80がAVRよりも十分後になるようにしたい。色々考えた挙句、[DS1232N](https://akizukidenshi.com/catalog/g/gI-15313/)をカスケード接続することにした。部品点数最小でコストも安く確実に動作するので。一般的な部品でないので秋月が売らなくなったら入手は絶望的かもしれないけど。(追記:DigiKeyやAliExpressなど探せば入手はできそう。値段はともかく。)
- ブレッドボードで実験してみた。
  - 1つ目のDS1232Nの/PBRSTにはManual Resetボタンを接続し、/RST出力をAVRのリセットに使用する。タイムチャートのCH1。
  - 2つ目のDS1232Nの/PBRSTには1つ目の/RST出力を接続し、/RST出力をZ80のリセットに使用する。タイムチャートのCH2。
  - スペック上の/RSTの最小値は250msだが実測では480ms。AVRが0番地に命令を書き込むには十分な時間。
  - **(2023/6/17追記)** Fuse bitのCKSEL0, SUT1,0で、リセットからの付加遅延時間が設定できる。CKSEL0=1, SUT01=00で運用しているため遅延時間は65msである。したがってAVR側のマージンはこの時間を差し引いた値になる。
    - Power ON リセット  
      
    - Manual リセット  
      
- 回路図を見直し、CR積分を使ったリセット回路は削除した。74HC132も不要になった。
- 改修したところ、確実にAVRの簡易モニタが起動するようになった。ISPのリプログラムも安定した。回路変更の効果はありそう。

## 2023/6/4

- ロジアナで全体の信号を確認しつつAVRの初期化コードを見直す。GPIOの初期化でPB5のZ80のリセット信号をLowにしていたのをやめ、DS1232Nのリセット信号に任せるようにしたら、安定して0番地にHALT命令が書き込まれ、Z80がHALTするようになった。起動時の不安定問題はこれで解消された。長かった。。。

- 結局、不安定な原因は以下だった。
  - 結線ミス  
    - クロック回路の74HC74の結線ミスによる発振不良
    - /RDの接触不良
  - リセット問題  
    Z80の実行前に、AVRがブートストラップコードを配置する時間が確保できず、Z80が暴走する。
  - WAIT問題  
    Z80が暴走状態でI/O命令を実行してしまう。/WAITが解除されないのでバスが握りっぱなしになり、AVRからSRAMをアクセスするとバスが衝突する。

- Z80のメモリライトの検証から再開。以下のコードで0x1234に0x55を書き込む。

  ```text
  .AREA   CODE(ABS)
  0000                       2     .ORG    0x0000
                             3
  0000 3E 55         [ 7]    4     LD A, 0x55
  0002 32 34 12      [13]    5     LD (0x1234), A
  0005 76            [ 4]    6     HALT
  ```

  簡易モニタの入力。
  問題なし。0xabが0x55に書き変わった。0xaaにしても正しく書き変わったので、全ビット問題なし。

  ```text
  >r $1234
  $1234 (1234): ab
  >w 0 $3e
  >w 1 $55
  >w 2 $32
  >w 3 $34
  >w 4 $12
  >w 5 $76
  >reset
  >r $1234
  $1234 (1234): 55
  ```

- これで、Z80からのSRAMリード・ライトの検証完了。明日以降、AVRの割り込みまわりを設定して、Z80のI/Oに対応させる。
  
## 2023/6/5

- 以下のプログラムでZ80のOUT命令の確認を行う。/IOWR(= $/IOREQ \cdot /WR$ )でINT1の外部割り込みが発生するはず。

  ```text
                             1     .AREA   CODE(ABS)
  0000                       2     .ORG    0x0000
                             3 
  0000 3E 12         [ 7]    4     LD A, 0x12
  0002 D3 34         [11]    5     OUT (0x34), A
  0004 76            [ 4]    6     HALT
  ```

  簡易モニタの入力。

  ```text
  >w 0 $3E
  >w 1 $12
  >w 2 $D3
  >w 3 $34
  >w 4 $76
  >reset
  ```

- /IOWR(= $/IOREQ \cdot /WR$ )=Lowの次のクロックの立ち上がりで/WAITがトリガされている。WAIT生成回路は正しく動作しているようだ。データバスにも0x12が出ているので期待動作になっている。  
  
- まだAVR側のINT1の割り込みハンドラの動作確認ができていない。このためWAITが解除ができず、Z80はデータバスを握ったままWAITしている。この状態ではAVRからのメモリアクセスも正しく動かない。とっとと割り込みハンドラを実装しないことには先に進めない。

## 2023/6/6

- なぜか外部割り込みがかからない。PD0,PD1,PE4へのハード的な接続は問題ない。  
  トリガ条件と割り込みマスクくらいしか設定項目がないのだが。

  ```c
  EICRA = 0b10101010;　　　　　　　　　　　　　// Falling edge sense
  EICRB = 0b10101010;　　　　　　　　　　　　　// Falling edge sense
  EIMSK = _BV(INT0)|_BV(INT1)|_BV(INT4);　 // Enable INT0,1 and 4
  ```

  ```c
  ISR(INT0_vect) {}
  ISR(INT1_vect) {}
  ISR(INT4_vect) {}
  ```

- 理由がさっぱりわからないのでタイマーによる周期割り込みを実装してみた。
  8bitのTimer0を使用。CTCモードのコンペアマッチで10ms毎に割り込みかける。クロック入力はF_CPU(16MHz)を1024分周している。sei()するだけでハンドラが呼び出された。

  ```c
  OCR0  = 10 * F_CPU/1024000UL;           // 1024/16MHz x Count (every 10msec)
  TCCR0 = _BV(WGM01)|                     // CTC mode
          _BV(CS02)|_BV(CS01)|_BV(CS00);　// start with 1/1024 pre-scaler
  TIFR |= _BV(OCF0);                      // Interrupt every compare match
  TIMSK|= _BV(OCIE0);                     // Enable interrupt
  ```

  ```c
  ISR(TIMER0_COMP_vect) {
  }
  ```

  割り込みプログラミングのスタイルは間違っていないようだ。やはり外部割り込みの設定が何か足りないのか。

## 2023/6/7

- 以下のプログラムを実行したら、なぜかINT1割り込みがかかった!　が、理由が不明。
  IN命令だから $/IORD=/IOREQ \cdot /RD$ になるはずで、INT0が発生するのが筋だ。

  ```text
                             1     .AREA  CODE(ABS)
  0000                       2     .ORG  0x0000
  0000 DB 34         [11]    3     IN A, (0x34)
  0002 76            [ 4]    4     HALT
  ```

## 2023/6/8

- 信号を取り直してみた。  
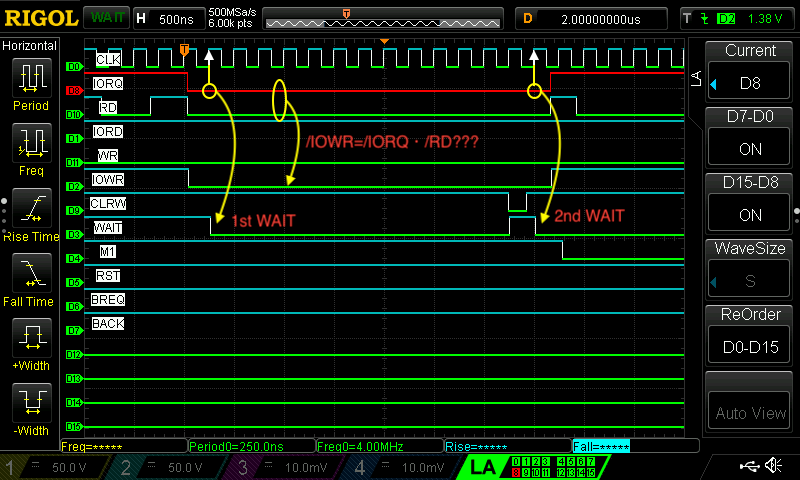
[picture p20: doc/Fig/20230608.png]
  
  以下の問題発見。
  1. /IORD, /IOWRが逆転している。
  2. WAIT回路の不具合。1st WAITは想定通り。2nd WAITが想定外。
     - 現在の/WAIT出力と/IOREQのORを取ったものを最終的な/WAITとすればよさそう。/IOREQがHighになるまでヒゲが残るが認識されないので良いだろう。しかし、、もう余分なORゲートがないんだよな。

## 2023/6/9

- /IORD, /IOWRの逆転問題、原因は単純な結線ミス。AVRのINT0(PD0), INT1(PD1)の接続があべこべだった。
- 2nd WAIT問題は、74HC32を1つ追加して対処。リセット回路の見直しで不要になった74HC132の跡地を再利用した。
- 以下のIN/OUTを繰り返すプログラムで動作検証した。

  ```text
                             1     .AREA   CODE(ABS)
  0000                       2     .ORG    0x0000
                             3 
  0000                       4 loop:
  0000 DB 34         [11]    5     IN A, (0x34)
  0002 D3 34         [11]    6     OUT (0x34), A
  0004 C3 00 00      [10]    7     JP loop
  ```

  直った！  
    
- だが、AVRの簡易モニターの動作がおかくなってしまった。↑のプログラムを走らせると暴走する？割り込み処理のバグか？3歩進んで2歩下がった感じだなぁ。

## 2023/6/11

- 何も変えずに6/9のプログラムを走らせたら、なぜか/WRがLowに張り付く。だがしばらく動かしていると正常に戻っている。どの状態でも簡易モニタは暴走するので、これが原因というわけではなさそう。  
    
- パワーオンリセットだとHALTが書き込まれるが、マニュアルリセットだと書き込まれない現象がある。

## 2023/6/12

- 昨日の問題はとりあえず横に置いておいて、Z80の外部割り込みの確認。

  ```text
                             1     .AREA  CODE(ABS)
  0000                       2     .ORG  0x0000
                             3 
  0000 31 00 02      [10]    4     LD SP, 0x200
  0003 3E 01         [ 7]    5     LD A, 0x01
  0005 ED 47         [ 9]    6     LD I, A
  0007 ED 5E         [ 8]    7     IM 2
  0009 FB            [ 4]    8     EI
  000A 76            [ 4]    9     HALT
                            10 
  000B                      11 int0:
  000B ED 4D         [14]   12     RETI
                            13 
  0100                      14     .ORG 0x0100
  0100 0B 00                15     .DW  int0
  ```

  Z80の/INTのパルス幅は80ns以上あれば良いはずだが、今は1usと長めに取っている。/IOREQと/M1がLowになり、Z80の割り込みサイクルになっている。AVRにはINT4割り込みがかかっており、割り込みベクタの出力、CLRWのLowパルスで/WAIT解除と、I/O READと同様の処理が実行されている。期待通りに動いているようだ。  
    

## 2023/6/14

- 6/9の簡易モニタが暴走する件、Z80のIN命令発行がトリがになっているようだ。OUT命令だけ無限ループさせたときは問題ない。
- 考察
  - IN命令に対するAVRのINT0割り込みハンドラはちょっとタイミングがシビアなので注意が必要。PortAにI/Oデータを出力したら、/CLRWAITを駆動して/WAITを解除する。このタイミングで出力データは74HCT574にラッチされる。これが読み取られるのがT3の立ち下がり。~~読み取りの時にはPortAがハイインピーダンスになっていないとバスが衝突する。~~ しかし、/WAITの立ち上がりからT3の立ち下がりまでは最悪で1クロック=250nsしかない。
  - INT0割り込みハンドラの出口ではこんなことをやる必要があるが、~~(*)部の合計<250nsじゃないとまずいってことだ。~~

    ```c
    ISR(INT0_vect) {
      ...
      PORTA = データ出力
      ---ここからがクリティカルセクション---
      PORTD &= ~_BV(PORTD5);  // /CLRWAIT=low
      (*) asm("NOP");         // このあたりで/WAITが立ち上がり、データをラッチ。
      (*) DDRA  = 0x00;       // PortAをHigh-Zに。
      (*) PORTA = 0xff;       // PortAを入力に。
      ---ここまでをT3の立ち下がりまでにやらないといけない。---
      PORTD != _BV(PORTD5);   // /CLRWAIT=High
    }
    ```

    明日以降、このプログラムで実測してみる。

    ```text
                               1     .AREA  CODE(ABS)
    0000                       2     .ORG  0x0000
    0000 DB 34         [11]    3     IN A, (0x34)
    0002 76            [ 4]    4     HALT
    ```

## 2023/6/16

- 2023/6/15の考察の間違いに気づいた。
- /WAITの立ち上がりでデータは74HC574にラッチされている。PortAに接続されていない74HCT574の出力側からZ80は値を読むので何の問題もない。
- もちろん、Z80が次にデータバスにアクセスするまでには、PortAはハイインピーダンスになっていなければならない。それはいつか？次のM1サイクル中のT2の立ち上がりでの命令フェッチまでだ。つまりZ80が/WAIT=Highをセンスしてから3.5クロック後。したがって、`(*)` 部の合計 < 250 * 3.5 = 875ns でよい。時間的には十分余裕がある。
- うーん、だとするとAVRが暴走する理由は何だ？
- この単発動作だと問題ない(ように見える)。

  ```text
                             1     .AREA  CODE(ABS)
  0000                       2     .ORG  0x0000
  0000 DB 34         [11]    3     IN A, (0x34)
  0002 76            [ 4]    4     HALT
  ```

- 連続動作だと暴走する。

  ```text
                             1     .AREA   CODE(ABS)
  0000                       2     .ORG    0x0000
                             3 
  0000                       4 loop:
  0000 DB 34         [11]    5     IN A, (0x34)
  0002 C3 00 00      [10]    6     JP loop
  ```

## 2023/6/17

- 念のため単発動作で観測してみた。
  1. 74HCT574は/WAITの立ち上がりでが0ｘ55をラッチする。セットアップタイム $t_{SU}=18$ ns(min)、ホールドタイム $t_H=5$ ns(min)ともに問題なさげ。
  2. その直後にAVRはPortAをハイインピーダンスにしている。Z80のM1サイクル前までに余裕で間に合っている。
  3. Z80はT3の立ち下がりで74HCT574のQ1-Q7側から0x55を読み出す。

  タイミング的におかしなところは見当たらない。  
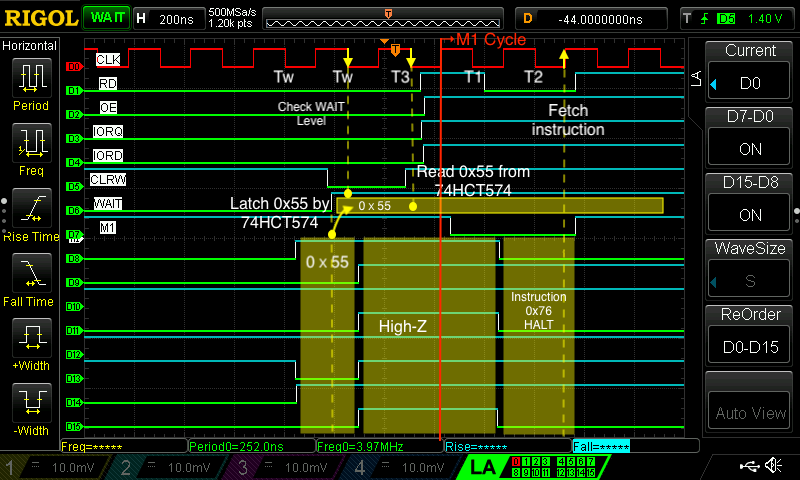
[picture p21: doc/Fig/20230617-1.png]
    

- AVRの暴走の原因、さっぱりわからず目を閉じて途方に暮れていた。するとなぜか突然Fuse bitが気になり出した。現在の設定は以下。
  - EXTEND: 0xFF
  - HIGH: 0xD1
  - LOW: 0xCF
- よくみるとHIGH byteのCKOPTが0になっている。これはAVRのクロック設定で、16MHzセラロック接続の場合は1にしないといけないはず。
- 試しに1に変更すると暴走しなくなった? 0に戻すと暴走する。確かに有意差がある。これが原因か！  
  連続動作でも問題が出なくなった。直ったようだ。  
  
- しかし、こういうひらめきはどこから来るのだろう。なぜFuseに思い至った理由が自分でもさっぱりわからない。試行錯誤の果てに斜め上から解決方法が降ってきた経験は初めてではないが、これは単に自分の洞察力が足りないだけなのか、あるいは悩み抜く過程で脳内に湧き起こるモノなのか。

- **Z80→AVRの疎通実験**
  - Z80はOUT命令でポート番号1に'Hello'を送信する。AVRはINT1の割り込みハンドラでそれを受け取り、UART1に出力する。  
  - Z80のプログラム

    ```text
                                1     .AREA   CODE(ABS)
     0000                       2     .ORG    0x0000
                                3 
     0000 06 05         [ 7]    4     LD B, 5
     0002 0E 01         [ 7]    5     LD C, 1
     0004 21 0A 00      [10]    6     LD HL, str
     0007 ED B3         [21]    7     OTIR
     0009 76            [ 4]    8     HALT
                                9 
     000A                      10 str:
     000A 48                   11     .DB "H"
     000B 65                   12     .DB "e"
     000C 6C                   13     .DB "l"
     000D 6C                   14     .DB "l"
     000E 6F                   15     .DB "o"
    ```

    以下を簡易モニタから入力。

    ```text
    w 0 $06
    w 1 $05
    w 2 $0E
    w 3 $01
    w 4 $21
    w 5 $0A
    w 6 $00
    w 7 $ED
    w 8 $B3
    w 9 $76
    w $a $48
    w $b $65
    w $c $6C
    w $d $6C
    w $e $6F 
    reset
    ```

  - **動いた！**

    ```text
    Hello
    ```

- **これでAVRでZ80のI/Oをエミュレーションできる環境が整った！**
- 直近のTODOは以下。
  1. クロスアセンブルしたZ80のコードを送れるように、INTEL HEX/バイナリ変換プログラムを作る。
  2. 任意のポートのIN/OUT命令に対応したハンドラを扱える枠組みを作る。
  3. これを使って、USART1のコンソールI/Oを作る。
  4. まずはエコーバックできるようにする。
       - [AVR] RX1から1文字入力
       - [AVR] Z80に割り込みで通知(まずはNMI)
       - [Z80] IN命令で入力文字を受信
         - [AVR] INT1ハンドラで文字を送信
       - [Z80] OUT命令で文字を送信
       - [AVR] INT0ハンドラで文字を受信
       - [AVR] TX1に文字出力
  5. コンソールのBuffered I/O化。割り込みハンドラでBlocking I/Oを使うのはレイテンシがデカすぎて辛いので。

## 2023/6/18

- INTEL HEX/バイナリ変換を簡易モニタに組み込んだ。コンソールからXMODEMでINTEL HEXファイルを転送すると、外部SRAMの所定のアドレスにプログラムが展開される。これで簡易モニタの1バイト書き込みコマンド(w)で、ちまちまとコードを入力する必要がなくなった。
- INTEL HEXのフォーマットはシンプルなので、メモリに展開された前提ならパーサーは楽勝で書ける。しかしAVRの内蔵SRAMはわずか4KBなので、その前提は置けない。ファイルはXMODEMで受信するので128byte毎にバッファリングするが、それでも繋ぎ目の処理は面倒。そこでパーサーはステートマシン形式にして、文字列ストリームを1文字ずつ突っ込むとバイナリ変換＆メモリへの書き込みを行う設計とした。
- 既に実装済みのXMODE受信と外部SRAMアクセスのコードと組み合わせ、やや無謀とは思いつつも、昨日の疎通実験のプログラムのHEXファイルをTeraTermからXMODEMで流し込んだところ、なんと一発で動いた！昨日から調子いいなー。
- これでZ80側のプログラムをバリバリ書けるようになった。

### ステートマシン

- 64KBのアドレス空間をサポートできれば十分なので、レコードタイプは00と01のみサポート。
- 参考: [INTEL HEX](https://ja.wikipedia.org/wiki/Intel_HEX)

ステートマシン

## 2023/6/19

- 本腰を入れてZ80のソフト開発を行うためのクロスアセンブル環境を構築した。
- Windows/Macで同じ使い勝手にしたいので、VSCode + Docker + Dev Containerにすることにした。([この記事](https://zenn.dev/harurow/articles/c903de5f479a57)を参考にした。)
- アセンブラは[ASxxxx Cross Assemblers](https://shop-pdp.net/ashtml/asxxxx.php)のasz80を使用する。wgetで[ソースコードのzip](https://shop-pdp.net/_ftp/asxxxx/asxs5p40.zip)をdownloadし、必要なコマンドだけコンパイルして取り出すMakefileを書いた。Dev Containerを使いたくない場合も考え、Dockerfileでは行わないことにした。

### Dev Containerの使い方

VS CodeにDev Containersプラグインをあらかじめインストールしておく。

1. Z80ATmega/の直下でVSCodeを起動する。
2. "コンテナで再度開く"というダイアログが出るので選択。  
   (初回はコンテナ構築が行われ、以後はそのコンテナが再利用される。)
3. 起動に成功すると、/z80以下がホストにマウントされる。
4. VSCodeでbashを開くと、そこでアセンブルできるようになる。

## 2023/6/20

- GitHubに間違ったアカウントで何度かコミットしてしまったことに気づいたので、禁じ手ではあるがコミット履歴を強制的に書き換えた。
  - 再発防止策？
    - 間違ったアカウントをブロックしてみた。これでコミットが抑止できるのかは試していない。
- Z80の開発環境まわりのリファクタリング
  - コンテナのベースイメージを`debian:11-slim`に変更した。
  - クロスアセンブラの生成方法や、test用のZ80コードのMakefileを修正。

### コミット履歴の強制変更手順

1. 最終的に強制pushされるので、 ローカルに変更が残っていない状態にしておく。
2. 以下をコマンドラインから入力。  

    ```bash
    git filter-branch --env-filter '
    if [ $GIT_AUTHOR_NAME = "変更したいアカウント名" ]
    then
        export GIT_AUTHOR_NAME="46nori"
        export GIT_AUTHOR_EMAIL="46nori@users.noreply.github.com"
        export GIT_COMMITTER_NAME="46nori"
        export GIT_COMMITTER_EMAIL="46nori@users.noreply.github.com"
    fi'
    ```

3. 以下のようなメッセージが出る。  

    ```bash
    WARNING: git-filter-branch has a glut of gotchas generating mangled history
      rewrites.  Hit Ctrl-C before proceeding to abort, then use an
      alternative filtering tool such as 'git filter-repo'
      (https://github.com/newren/git-filter-repo/) instead.  See the
      filter-branch manual page for more details; to squelch this warning,
      set FILTER_BRANCH_SQUELCH_WARNING=1.
    Proceeding with filter-branch...

    Rewrite 8f56cebc1c0230d5fbfc522531d0d64bbfbcd58a (1/73) (0 seconds passed, remaining 0 predicted)
    Rewrite d482d49add8ea6341497e7d7f006c71f0f99090b (2/73) (0 seconds passed, remaining 0 predicted)
    ...
    ...
    Rewrite 0be7c1b74f456dfd4dca7f6c257fb7cb10d0d623 (59/73) (2 seconds passed, remaining 0 predicted)    
    Ref 'refs/heads/main' was rewritten
    ```

4. コミットログを確認。変更したいアカウント名が消えていればOK。  

    ```bash
    git log --pretty=full
    ```

5. リモートに反映させる。GitHub DesktopならRepositoryメニューに`Force Push`が現れるのでこれを選択。(普段は`Push`)

   ```bash
   git push -f
   ```

6. ブランチ名を一旦変更して元に戻す。
   - GitHubでブランチの選択メニューを出し、View all branchesをクリック。鉛筆ボタンを押すとブランチ名が変更できる。`main` → `main2` → `main`のように変更する。

- 参考記事
  - [過去のコミットの Author と Committer 情報を書き換える](https://qiita.com/mokuo/items/f48ed7a3628fbb67692f)
  - [GitHubに意図しないアカウントでコミットしてしまった時の対処法](https://blog.yotiosoft.com/2021/12/07/GitHub%E3%81%AB%E6%84%8F%E5%9B%B3%E3%81%97%E3%81%AA%E3%81%84%E3%82%A2%E3%82%AB%E3%82%A6%E3%83%B3%E3%83%88%E3%81%A7%E3%82%B3%E3%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)

## 2023/6/23

- [ハードウェア仕様書の割り込み仕様](Hardware/Design.md#z80への割り込み)が間違っていたので訂正。
  - NMIはPB6から叩けるようなっている。
  - Z80に割り込みをかける際に、AVRは必ずデータバスに1バイト出力する。
    - Mode 0は、データを命令と解釈する。ただしハード的に2バイト以上の出力はサポートしていないので、厳密には複数バイト命令を送れるMode 0の仕様を満たせない。
    - Mode 1は、データを無視して0x38にジャンプする。
    - Mode 2は、データをベクタと解釈する。
  - 最終的にCP/Mを動かすことを考えると、0-0xffはシステムエリアなので、実質Mode2しか使えないのだけれど。
- パワーオン時の挙動がおかしいことがある。
  - AVRのコマンドプロンプトが出ない。
  - /BUSACK=Highで点灯する点灯するLEDが消えたまま。
  - AVRISP mkIIの電源OFFのままでISPコネクタを接続してると発症するようだ。ISPコネクタを抜くと直る。ISPの/RSTラインの問題か？プルアップしているのでLowにはならないはずなんだけどなぁ。。

## 2023/6/24

- Z80側の開発環境を検討した。
  - [ASxxxx](https://shop-pdp.net/ashtml/asxxxx.php) : アセンブラ
  - [sdcc](https://sdcc.sourceforge.net/) : Cコンパイラ
  - [z88dk](https://z88dk.org/site/) : Cコンパイラ + アセンブラ
  - 参考情報
    - [sdccとz88dkの比較](https://mixi.jp/view_diary.pl?id=1957001872&owner_id=358658)
    - [sdccによるクロスビルド](https://ashitani.jp/g850/docs/05_sdcc.html)
- 正直まだどれを使うか決めきれていない。が、とりあえず全部Dev Containerで使えるようにした。z88dkのビルドは[ここ](https://github.com/z88dk/z88dk/wiki/Docker-Usage)の情報と[Dockerfile](https://github.com/z88dk/z88dk/blob/master/z88dk.Dockerfile)を参考にした。

## 2023/6/25

- z88dk-z80asmは同一ソース内に複数のORGを許してくれない。ORGを分けたい時にはファイルを分けてアセンブル、リンクする必要がある。割り込み関連の確認時はベクタテーブルやエントリポイントを分けたいので、当面はasz80を使用した方が楽そうだ。
- 簡易モニタでihxファイルをロードすると、XMODEMで2ブロック以上転送できない問題を修正。INTEL HEXパーサーのチェックサム計算のバグだった。コマンド名をxloadに変更。
- XMODEMでバイナリを外部SRAMにダウンロードするbloadコマンドを追加した。
- **UART1を使ったAVR → Z80 → AVRのコンソールエコーバックが動いた！**
  - Z80側には[echoback.asm](https://github.com/46nori/Z80Atmega128/blob/main/z80/test/echoback.asm)をasz80でアセンブルした.ihxファイルを、簡易モニタのxloadコマンドでロードし、resetをかけておく。
  - UART1側のコンソールから1文字入力。
  - AVRはUART RX1の割り込みハンドラで1文字受信。グローバル変数(port_dat)に記憶後、Mode2のベクタ0でZ80に割り込み発行。
  - Z80はベクタ0の割り込みハンドラでポート0にIN命令発行。
    - AVRはINT0割り込みハンドラでport_datの値を返す。
  - Z80はその値をIN命令の結果として受信。
  - Z80はポート1にOUT命令でそれを出力。
  - AVRはINT1割り込みでその値をTX1に出力。
  - UART1側のコンソールに入力と同じ文字が表示される。

## 2023/6/27

- UART1のBuffered I/Oをサポートした。RX1側は受信と同時にZ80に割り込みをかけるので、緩衝材程度の役割。数バイトのバッファがあればよい。TX1側はZ80から受信したデータをINT1の割り込みハンドラでバッファリングするだけ。なるべく早く処理を終わらせる。バッファされたデータは、TIMER0の周期割り込みハンドラで空き時間にTX1に出力される。
- SD Cardまわりを調査していたら、Microchipが[Petit Fat FS](http://elm-chan.org/fsw/ff/00index_p.html)を使用したサンプルを提供しているのを発見。([これ](https://avr.jp/user/AN/PDF/AVR42776.pdf)とか[これ](https://ww1.microchip.com/downloads/en/Appnotes/Petit-Fat-File-System-00002799A.pdf)とか。)
  - デフォルト設定は、FAT16、Read/Write/Seek対応、ディレクトリ非対応。これでROM 3106bytes, RAM 43bytes。十分小さい。
  - ライセンスは[ここ](http://elm-chan.org/fsw/ff/pf/appnote.html)に記載がある。確認したが特に問題ない。Microchipもサンプルとして引用しているので安心。
- SD Cardはよく知らないし、面倒臭そうなので後回しの予定だったけど、勢いでやってみたら意外と簡単に移植できてしまった。まだいろいろ繋ぎ込みが必要だけど、**これでCP/MのBIOS作成に必要な大物部品は揃ったな。**

### Petit FAT File Systemの移植

- ソースの取得
  - [Atmel Start](https://start.atmel.com/)でBROWSE EXAMPLEボタン押し、Search boxに`AVR42776 Petit FatFs Example`を入力して検索。1件だけヒットするはず。
  - DOWNLOAD SELECTED EXAMPLEボタンでダウンロードする。`.atzip`形式なので選択するとMicrochip Studioが開く。
  - `petitfs`以下をまるっとコピーして、自分のプロジェクトのツリーに追加する。
  - ちなみにPetit Fat FSのバージョンはR0.03がベースになっているようだ。最新版は2019年にR0.03aがリリースされている。
- 方針と構成
  - Petit Fat FSは既存のファイルの読み書きが前提。事前に決め打ちのファイルをカード上に作成しておく運用とする。
  - FAT32を採用する。理由はSDHCカードの入手性。FAT16だと2GB以下のカードが必要で、調達困難。
  - 使用可能なファイル名は大文字のみとする。コンフィグを小文字とロケール非対応`_USE_LCC=0`にすることで、貴重な内部メモリを128byteケチる。
  - `petitfs/pffconf.h`の設定

    ```c
    _USE_READ = 1
    _USE_DIR = 0
    _USE_LSEEK = 1
    _USE_WRITE = 1
    _FS_FAT12 = 0
    _FS_FAT16 = 0
    _FS_FAT32 = 1
    _USE_LCC = 0
    ```

  - 移植
    - `petitfs/diskio_avr.c`が移植層。
    - 以下のATtiny817の実装をATmega128用に書き換えた。試しにChatGPTに頼んだら、割と筋の良いコードを吐いた。手直しは必要だったが、データーシートを読み込む箇所が絞れて助かった。
  
      ```c
      /*-------------------------------------------------------------------------*/
      /* Platform dependent macros and functions MODIFY FOR YOUR DEVICE           */
      /*-------------------------------------------------------------------------*/

      #include <avr/io.h> /* Device specific include files */

      #define SPIPORT PORTC
      #define SPI_SCK (1 << 0)  /* PC0 */
      #define SPI_MISO (1 << 1) /* PC1 SD card DO */
      #define SPI_MOSI (1 << 2) /* PC2 SD card DI */
      #define SPI_CS (1 << 3)   /* PC3 */

      /* Port controls  (Platform dependent) */
      #define SELECT() SPIPORT.OUTCLR = SPI_CS   /* CS = L */
      #define DESELECT() SPIPORT.OUTSET = SPI_CS /* CS = H */
      #define SELECTING ((SPIPORT.DIR & SPI_CS) && !(SPIPORT.OUT & SPI_CS))

      static void init_spi(void)
      {
        ...
      }

      static BYTE spi(BYTE d)
      {
        ...
      }
      ```

    - delay()まわりで`F_CPU`が見つからないというWarningが出たが、適宜`#define`を挿入して回避している。ASF絡みでなぜうまく設定できないのか不明のままの状態が続いている。整理せねば。
- 動作確認
  - 元コードのmain()関数を手直ししてテストした。
  - カード上に`EXAMPLE.TXT`(ファイル名大文字)を作成。中身は適当な文字を書き込んで大きめのサイズにしておく。
  - カードのmount、`EXAMPLE.TXT`のopen、`Hello SD！\r\n`のwrite、readして正しくwriteできたか比較し、すべて問題がないことを確認した。
  - Macで`EXAMPLE.TXT`を開いてみると、先頭に`Hello SD！\r\n`が書き込まれていた！

## 2023/7/1

- [エミュレーションデバイス仕様書](Software/EmulatedDeviceSpec.md)を書いた。
- Z80のポートIN/OUT要求をAVR側でエミュレーションするためのフレームワークを作成した。
  - IN/OUT命令でAVRのINT0/1割り込みハンドラが起動したらポート番号を取得し、対応するハンドラ関数をテーブルから取り出してして呼び出す構造。IN/OUTそれぞれ0-31の32ポートに対応。32以上のポート番号が指定されたらシャドウアクセスされる。
  - ソースは`avr/emudrv/`以下に分離した。emudrv.[ch]で関数テーブルを管理し、配下のモジュール(em_consoleio, em_diskio)を束ねる構造。
  - エミュレーションデバイス仕様に合わせたハンドラもとりあえず書き殴った。
- DISK I/O
  - パラメータのSetter/Getterと、ファイルオープンのあたりは書いた。
  - **DISK I/Oのリード/ライトは、OUT命令のハンドラ(INT1)の中で完結できないことに注意。** SDカードは外部SRAM上にあるZ80側のバッファとの間でデータ転送を行うが、Z80がバスマスタ状態なのでAVRは外部SRAMにアクセスできないのが理由。Z80のOUT命令を完了、つまり**データ転送は割り込みハンドラを抜けた後に実行する必要がある。**
  - しかしAVRのメインループは簡易モニタが握っているので、周期割り込みハンドラ内で実行するしかない。そうなると簡易モニタと同時動作できてしまうので、リソース管理しないと競合してXMEM設定状態がずれてしまう可能性がある。また周期割り込みハンドラではUART1のTX処理も行うので、SDカードアクセスが遅いとコンソール出力が遅延する。その場合はもう一つタイマ割り込みを用意するか？うーむ、RTOSが欲しくなってきたなぁ。書くか？
  - 並列処理の設計はちゃんとやっておかないと後でハマるので、DISK I/Oはペンディング。
- コンソールI/O
  - Timer0割り込みの周期を10msから1msに変更した。TX1のバッファに溜まったデータを、この割り込みで吐き出すが、10msでは遅すぎてオーバーランしてしまうから。
  - RX1入力を**NMIで**Z80で通知し、IN/OUT命令でAVRにエコーバックし、コンソールに出力させるのには成功した。
  - だが**Mode2割り込みの通知だと動かない。** 割り込みの直後にZ80がリセットがかかっているように見える。暴走？ロジアナで確認したが、割り込みベクタはデータバスに正しく出力されているように見える。
  - Z80に/INT割り込みがかからないことがあるので、調べていたが自分で書いた[仕様書](Hardware/Design.md#z80への割り込み)を読み直したらちゃんと書いてあった。過去の自分えらい。やっぱドキュメント残すのは大事だ。
  - /XINTのパルスの生成方式が正しくなかったのが原因。Z80が/INT=Lowを認識するのは実行中の命令の最終ステートの立ち上がり。確実に認識するための/XINTのパルス幅はWAITを考慮したZ80最大命令長になるが、本回路ではZ80のIN/OUT命令で強制WAITが挿入され、その解除時間はAVRの割り込みハンドラの実行時間に依存する。よって命令終了のタイミングは自明でない。このため/XINTはLowのままにしておき、AVRの割り込みが確実にかかった後、すなわちINT4割り込みハンドラの中でHighに戻す。Z80は割り込みサイクル中に/INTを見ないので問題ない。見落としがちなので仕様書を更新した。
  - Mode2割り込み問題の解析の続きは明日以降。

## 2023/7/2

### Mode2割り込みの解析

- データバスに出力するベクタの値を間違えていた。モードの2の割り込みレベルは0-127が指定できる。これをそのままデータバスに出力していたのは間違いで、実際には左1bitシフトした値をセットしなければならない。Z80はIレジスタの値を上位、ベクタ値を下位としたアドレスから1ワードリードする。これが指定した割り込みレベルに対応する割り込みハンドラのアドレスとなる。
  - 解析結果を[Mode2割り込みの動作例](Hardware/Design.md#mode2割り込みの動作例)として仕様書に反映した。
- Z80が割り込みを認識しない問題
  - コンソールI/Oのデバッグ中に、1文字しかエコーバックされない現象に悩まされた。
  - 1回目は以下のシーケンスがパスする。
    1. AVRがRX1受信割り込みを受ける。データをRX1のコンソールバッファに追加し、Z80の/INTをLowにして割り込みをかける。
    2. Z80が割り込みを認識し割り込みサイクルに入る。/M1と/IORQがLowになりAVRにINT4が発生する。この中で割り込みベクタを出力。Z80の/INTをHighに戻す。
    3. Z80はベクタを読み取って、割り込みハンドラを起動し、以下を実行。
    4. IN命令でRX1バッファのデータを1文字取得。AVRのINT0割り込みハンドラでデータ返す。
    5. OUT命令でそのまま返す。AVRのINT1割り込みハンドラでデータを受け取り、TX1バッファに追加。
    6. AVRが周期割り込みハンドラでTX1に文字を出力。
  - 2回目以降、Z80が割り込みを認識してくれないので2.から先が進まない。Z80の/INTは2.で解除される仕様なので、Lowに張り付きっぱなしになってしまう。
  - 試しにZ80の割り込みハンドラの出口でEI命令を実行したら、割り込みがかかるようになった。そう、すっかり忘れていたのだが、**マスカブル割り込みからの復帰時は明示的に割り込み許可しないといけない**のだった。
  - でも、Z80でEIの実行を忘れると/INTがLowに張り付くというのは、ハードを完全エミュレーションさせるというプロジェクトの趣旨からするとちょっと悔しい。AVRで張り付きを監視して解除することもできなくはないが、タイミングによってはややこしいバグの原因になりそうなので、目を瞑ることにする。
- とりあえず、これで**Z80用のコンソールI/Oデバイスのエミュレータは完成。**
- Mode2のベクタのデバッグが済んだタイミングで、**Mode0, Mode1が動作することも確認した。**
  - Mode1はベクタが無視されるだけなので問題無し。
  - Mode0はMode2と違ってZ80のオペコードをデータバスに出力するので、左シフト操作はしてはいけない。

#### CP/M DISK I/O BIOSの設計検討

- CP/M内で扱う論理DISKと、物理DISK(SDカード)間で位置情報の変換テーブルをBIOS内に持つ必要がある。これはDPHやDPBなどで規定されているが、設定方法が複雑で整理が必要。30年くらい前にHD64180のシステムを作った時に調べたことがあるが、もうすっかり忘れてしまった。以下の記事を参考にした。8番目のBIOSコール(SELDISK)のリターンで、HLレジスタにDPHのアドレスをセットするのか。
  - 「マイコンピュータ No.16 CP/M活用テクノロジー(CQ出版1985年)」
    - 唯一手元に残しておいたCP/Mの文献
  - [BIOSのディスクパラメータ](https://userweb.alles.or.jp/chunichidenko/cpm_mycom12.html)
  - [CP／Mディスクイメージ作成手順メモ](http://star.gmobb.jp/koji/cgi/wiki.cgi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)
- CP/Mイメージの作成方法も併せて考えておかないといけないので、以下も。
  - [バイナリイメージの入手先](http://www.cpm.z80.de/binary.html#operating)
  - [CP/Mディスク作成](https://www.rikachann.jp/blog/pinecone/2020/03/17/z80tmpz84c015に萌えたい%E3%80%82cp-m%E3%80%80ディスク作成/)

- 色々考えて、BIOS側は最初はシンプルに実装することにした。AVR側ならC言語が使えるので、面倒な処理はこちら側で引き受ける。データ転送が128byte単位なので遅いかもしれないけれど、まずは一通り動かしてから考えよう。
- ちなみにXMEMのシャドウ領域にバッファがあると転送が面倒なので、BIOS側にバッファを持たせた方がいいかも。将来デブロッキング対応する時にはどうせ必要だし。
- Timer0はコンソールI/O用に使ってしまったので、Timer2の周期ハンドラ(10ms)を追加した。

## 2023/7/3

- 今日は忙しくて何も触らないかったが、寝る前に風呂に浸かっていたらなぜか回路のバグに気づいた。忘れないうちにメモ。
- 問題
  - システムリセット時のリセットパルスは、Z80の方が500msくらい長い。先に動き出すAVRが0番地にHALT命令を書き込んでおくことで、Z80起動時にHALTするようにしている。このHALTが微妙にかからないことがある。ずっと理由がわからずモヤモヤしていた。
- 原因
  - Z80は/RESETがLowのとき/BUSACKをハイインピーダンスにする。/BUSACKはプルアップされているので、この期間の信号レベルはHighだ！
  - AVRはまさにこの期間にHALT命令を書き込む。だが/BUSACKがHighのとき、外部SRAMの/WEはZ80側で駆動されているため、AVRからの書き込みは保証されない。
- 対策
  - /BUSACKと/RESETのANDをとり、Z80の起動前にAVRに確実にバスの使用権を確保させる。
  - /BUSACKは多くのゲートが使用するので、Z80のファンアウトの関係で74HC125でバッファリングしている。これをやめ、ちょうど1つ余っている74HC08で/RESETと/BUSACKのANDを取った結果を使うようにする。

## 2023/7/4

- 昨日の問題、改修して動作確認した。安定してHALT命令が書き込まれるようになったので、回路図も更新した。
- avr/z80io.cのZ80_BUSREQ()での、BUSACKのポーリングの判定ロジックのミスを修正。

## [続き](Diary2.md)

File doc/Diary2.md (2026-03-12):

#

## [以前の日記](Diary.md)

## 2023/7/7

- CP/Mの移植方針を決めた。
  - CP/M本体(CCP, BDOS)
    - 最初はどこかからCP/Mバイナリを持ってきて、PCであれこれ加工してメモリイメージを作成し、何らかの方法でSRAMに転送して起動させようと考えていた。と考えるだけでも面倒臭いので、他の方法を探していたが、[The Unofficial CP/M Web site](http://www.cpm.z80.de/)で[CP/M2.2のソース](http://www.cpm.z80.de/download/cpm2-asm.zip)があるのに気づいた。根性のあるおっさんがメモリイメージをディスアセンブルして、Z80のニーモニックで書き起こしたものらしい。これをそのままアセンブルできれば、前後にIPLとBIOSをリンクしてINTEL HEX出力するだけで良くなるので相当楽。実機への転送も簡易モニタでロードするだけだ。
  - BIOS
    - 最低限の初期化、Cold Boot, Warm Boot, コンソール入出力のみ作成し、起動メッセージが出るところまでを確認することにした。DISK I/Oはそのあとじっくり取り組む。
  - IPL
    - 起動時に0番地からBIOSのCold Bootを呼ぶだけ。
- まずはこの方針で行けそうか、CP/Mのソースコードのアセンブルを試金石とした。アセンブラはasz80で乗り切れそうな気がしたので、トライ&エラーでソースを修正してたら、あっさりアセンブルできてしまった。BIOSを書くためのアセンブラを最終的にどれにするか悩んでいたけど、もうこれでいいや。変更箇所は以下。
  - 16進表記の変更(例: 1AH → 0x1A)
  - 文字リテラルのシングルクオート('A') → ダブルクオート("A")に変更
  - ディレクティブの変更
    - `EQU`,`DEFB`,`DEFW` → `.equ`,`.db`,`.dw`
    - `ORG` → `.org`、さらに`.area`でセグメントの属性の指定。
    - 文字列("...")は`.str`
  - `EQU $`をその位置の示すアドレスラベルで置き換え。
    - (2023/7/12追記) `$`と同等の表現は`#.`であることがわかった。
- 修正したCP/Mのソースコードをリポジトリに取り込むのは、ライセンスのリスクがありそうなので、パッチを作成して管理することにした。ソースをダウンロードしてパッチを当て、アセンブルするMakefileを書いた。
- ちなみに62K CP/Mの設定になっている。

## 2023/7/8

- [エミュレーションデバイス仕様書](Software/EmulatedDeviceSpec.md)を更新した。
  - CONOUTの未出力データ、Console Bufferのサイズ取得機能追加。
  - 割り込み周りのレジスタ変更。
  - デバッグ用にLEDを操作できる仮想デバイスを追加。
- エミュレーションデバイス仕様に合わせて、コンソール入出力だけ対応したBIOSを記述した。しかしxloadコマンドで読み込んで実行すると暴走する？
  - BIOSの先頭アドレスである0xf200からのメモリイメージをINTEL HEXと比較してみると、正しく展開されていない。ダミーデータをbloadで読み込ませるとやはり正しく展開されていない。これが暴走の原因のようだ。
  - XMODEMの読み込みがXMEMアドレスの位置によってうまくいっていないようだ。AVR側のXMEMの書き込みルーチンを見直す必要あり。

## 2023/7/9

- INTEL HEXをメモリに展開しながらアドレスと書き込みデータをTX1に出力して確認したが問題なかった。
- しかし、メモリイメージを見直すと128byte境界でおかしなデータが紛れ込んでいる。さらにデータを書き込むと128byte先に同じデータが書き込まれことに気づいた。指定メモリブロックのR/Wチェックを行うプログラムを組み込んで測定すると上位側SRAM(0x8000-0xffff)で問題が発生する。ほぼハードの問題で確定。
- 配線を確認するとSRAMの1pinと14pinがGNDに落ちている。ポリウレタン線の被覆が剥がれてGNDラインに接触していたたのが原因。該当部分をセロテープで絶縁した。ポリウレタン線はコンパクトに配線できて便利だが、被覆の破損が目視ではわかりにくいのが辛い。もともと手配線量が多いので、デバッグ時の配線のズラしや経時変化で微妙に壊れることがある。早くプリント基板を起こしたいが、動作確認が終わらないとそれができないジレンマ。。
- ところが、これを直すとさらに悪化した。上位側SRAMへの書き込みが全くできなくなった。なぜだ？？？

## 2023/7/11

- なぜか今日はメモリ問題が発生しない。やはりどこかの接触不良なのか？
- 「マイコンピュータ No.16 CP/M活用テクノロジー(CQ出版1985年)」をじっくり読みながら、CP/M BIOSのCBOOT、WBOOT、SELDSKの実装を見直した。
  - CBOOTでブートメッセージを表示するようにした。
  - WBOOTで0x006番地にセットするBDOSのエントリポイントが6Byteずれてたバグを修正。
  - SELDSKにではHL=0で返すようにした。
- **これでやっとCP/Mが起動するようになった！**
  - ただしSELDSKでエラーを返すので、CP/Mの再起動のループになってしまう。
  - ダミーのDPHは追加したので、パラメータを見直して、SELDSKで返すようにし、DISK I/Oの繋ぎこみ実装を行えばまともに動き出すはず。

## 2023/7/12

- BIOSのDISK READ/WRITEを書き殴った。AVR側のSD CardのR/Wがまだ実装されていないので、まだデバッグはできない。
  - DISK READ
    - 512byteつまり4レコード分のリードキャッシュをサポートしている。
    - SD Cardのセクタサイズが512byteなので、セクタ境界から512byteリードする。こうしないとリードの効率が悪くなるので。BDOSから指定されるレコードは必ずしもこの境界に乗らないがリードデータには必ず含まれる。当該レコードの先頭はブロッキングファクタから計算できる。ブロッキングファクタはレコード番号を4で割った余り。
  - DISK WRITE
    - ライトキャッシュは真面目にやると大変なので、毎回書き込みを行う。
    - ライトが発生したら、リードキャッシュの状態を無効にする。

## 2023/7/13

- AVR側のSD CardのR/Wを書き殴った。INT0, INT1割り込みハンドラ内では外部SRAMアクセスができないため、R/W処理はTIMER2の周期割り込みハンドラ内で実行している。これでZ80側のBIOSとつながったはずなのだが。。。

## 2023/7/14

- BIOSのデバッグが進まなくなった。以下の現象からハードの問題っぽい。
  - 0x8000以降のメモリアクセスがうまくいっていない。簡易モニタのtestコマンドでメモリチェックを行うとチェックサムエラーが出る。
  - Z80側のプログラムが実行されていない？
  - なぜか外部SRAMアクセス時、/BUSREQに対する/BUSACKが返らない。AVR側が無限ループにハマる。
  - どうも/WAITがLowに張り付いているように見える。これが原因でZ80が割り込みサイクルから抜けられていない？BUSACKの問題もこれが原因か？
  - ロジアナで観測すると、4MHzクロックの立ち上がりとは無関係なタイミングでLowに引き戻されているように見える。
- ということで、Z80の制御線まわりの総点検を行った。
- 7/3のBUSACK問題の改修ミスを発見。/BUSACKのモニタ用LEDの接続が、74HC08の出力につながっていた。別に問題はないが、回路図上はZ80の/BUSACKにつながっているべきなので改修。
- /BUSREQをプルダウンにしていたがプルアップに変更。リセット時などAVR出力が不定になる期間にZ80を止める目的でプルダウンとしたが、リセット回路の修正でこれは不要になったので。
- WAIT生成回路の修正
  - 6/8の2nd WAIT対策で、WAIT生成回路の74HC74の出力と/IOREQのORを取った結果を/WAITとした。しかし74HCT754のCP入力には使えないことに気づいた。ここはORを取る前の74HC74の出力を使わないといけない。理由は以下。
  - 74HCT574のラッチは、Z80のIN命令(IORD)、および外部割り込みのベクタリード時に使用される。ラッチタイミングは/WAITの立ち上がりである。Z80がデータを読み込むのは/WAIT解除を認識した後のT3のタイミング。
  - 2nd WAIT対策の結果として/WAIT信号にヒゲが出るようになった。つまり/WAITの立ち上がりは2回発生する。しかし2回目のラッチは、AVRは割り込みハンドラの出口でPortAをハイインピーダンスに切り替えた後なので値は不定。また/OEもイネーブル状態なのでこの変化がそのままZ80のデータバスに現れてしまう。結果間違った値が読み込まれる可能性がある。
  - これを回避するにはヒゲのない74HC74の出力をそのまま利用する。この信号を/WAIT_0とし、回路図を修正した。

## 2023/7/18

- OUT命令のINT1ハンドラの/CLRWのパルス幅が短かったのを修正した。/CLRWがLowの期間、74HC74のQ出力はHighをキープできる。Z80が確実にWAIT解除を認識するよう、1クロック以上Highになるよう調整。時々WAITが解除されない問題に随分悩まされたが、結局原因はこれだった。
  - /CLRWAITのパルス幅 = 5CLK x 62.5ns(@AVR 16MHz) = 312.5ns > 250ns(@Z80 4MHz)

## 2023/7/19

- BIOS 起動時のエントリポイントを、WBOOTに変更。

## 2023/7/23

- BIOSのDISK I/Oまわりのデバッグ。
- CP/Mのディスクイメージをちゃんと作成してやらないと、うまく起動できなさそうなので。DPBとイメージの作成を整理することにした。

## 2023/7/30

- [cpmtools](http://www.moria.de/~michael/cpmtools/)の`mkfs.cpm`を使えば、CP/Mのイメージの作成ができるようだ。
  - GitHubの[フォーク版](https://github.com/lipro-cpm4l/cpmtools)もあるみたい。
- Debianでパッケージが用意されているので、Dev ContainerのDockerfileでデフォルトでインストールするようにした。

  ```bash
  apt-get install cpmtools
  ```

- 生成するイメージのDISKフォーマットは、mkfs.cpmコマンドの`-f`オプション指定する。
- DISKフォーマットは`/etc/cpmtools/diskdefs`に書かれている。別ファイルを指定することはできないっぽい。自前の設定を使うにはこのファイルに追記する必要がある。不便。
- CP/MのDPHやDPBを[ドキュメント](Software/DiskParameters.md)に整理した。
  - 参考文献
    - マイコンピュータ No.16 CP/M活用テクノロジー(CQ出版 1985年)
    - 応用CP/M 村瀬康治 (アスキー出版局 1982年)
    - [CP／Mディスクイメージ作成手順メモ](http://star.gmobb.jp/koji/cgi/wiki.cgi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)
    - [AVR CPMフディスクパラメタブロックの設定変更](https://blog.goo.ne.jp/ishihara-h/e/4603e30b56557b824f237faa9f2ee29e)

## 2023/8/2

### CP/Mディスクイメージの作成

- 8GB SD CARDの定義があったので、とりあえずこれを利用して、イメージを作成してみる。

  ```bash
  diskdef sdcard
    seclen 512        # 物理セクタ長
    tracks 256        # 物理トラック数
    sectrk 64         # 1トラックあたりのセクタ数 SPTとは異なるので注意
    blocksize 8192    # ブロックサイズ
    maxdir 256        # ディレクトリエントリ数(最大ファイル数)
    skew 0            # スキューファクター
    boottrk 1         # 予約トラック OFF相当
    os 2.2            # CP/M2.2
  end
  ```

- イメージファイル(DISK00.BIN)を生成する。65536バイトになった。最低限のサイズしか生成されないようだ。

  ```bash
  mkfs.cpm -f sdcard DISK00.IMG`
  wc -c < DISK00.IMG
  65536
  ```

- peti Fat FSは追加のライトができないので、ダミーを含む全サイズ(約8GB)をあらかじめ生成しておく必要がある。そこで`dd`を使用してダミーデータを後ろに追加する。

  ```bash
  dd if=/dev/zero of=DISK00.IMG oflag=append conv=notrunc bs=8192 count=1021
  ```

  - ブロックサイズ: blocksize = 8192 より、`bs=8192`
  - 総トラック数: tracks + boottrk = 256 + 1 = 257
  - SPT: seclen / 128 * sectrk = 256。
  - 論理セクタ長は128バイト(固定値)。
  - 生成されたDISK00.IMGのサイズは65536バイト。
  - 以上より追加ブロック数は、  
    `count = (257 * 256 * 128 - 65536) / 8192 + 1 = 1021`
  - `conv=notrunc`を指定しないとappendがうまく動かない。
- 次に、CP/Mの基本コマンド類をイメージに追加する。
  - [CP/M 2.2 BINARY](http://www.cpm.z80.de/download/cpm22-b.zip)をダウンロードして展開すると、CP/Mの基本ファイルのバイナリが得られる。おぉ、懐かしいファイル名だ。

    ```text
    % ls cpm22-b
    ASM.COM   DEBLOCK.ASM   DUMP.COM  READ.ME
    BIOS.ASM  DISKDEF.LIB   ED.COM    STAT.COM
    CPM.SYS   DSKMAINT.COM  LOAD.COM  SUBMIT.COM
    DDT.COM   DUMP.ASM      PIP.COM   XSUB.COM
    ```
  
  - `cpmcp`コマンドでイメージに追加する。`0:`はユーザー番号。
  
    ```bash
    cpmcp -f sdcard DISK00.IMG cpm22-b/*.* 0:
    ```
  
  - 中身を確認。

    ```bash
    % cpmls -f sdcard dummy.img 
    0:
    asm.com
    bios.asm
    cpm.sys
    ddt.com
    deblock.asm
    diskdef.lib
    dskmaint.com
    dump.asm
    dump.com
    ed.com
    load.com
    pip.com
    read.me
    stat.com
    submit.com
    xsub.com
    ```

- 完成したイメージ
  - 0x0000-0x7fffまではboottrk用。いまは何も書かれていないが、最終的にはmkfs.cpm実行時に`-b`オプションでCCP+BDOSのイメージを追加しておき、BIOSのWBOOTでここからCP/Mをリロードできるようにする。
  - 0x8000からディレクトリが始まる。

  ```bash
  00000000  e5 e5 e5 e5 e5 e5 e5 e5  e5 e5 e5 e5 e5 e5 e5 e5  |................|
  00000010  e5 e5 e5 e5 e5 e5 e5 e5  e5 e5 e5 e5 e5 e5 e5 e5  |................|
  ...
  00007ff0  e5 e5 e5 e5 e5 e5 e5 e5  e5 e5 e5 e5 e5 e5 e5 e5  |................|
  00008000  00 41 53 4d 20 20 20 20  20 43 4f 4d 00 00 00 40  |.ASM     COM...@|
  00008010  01 00 00 00 00 00 00 00  00 00 00 00 00 00 00 00  |................|
  00008020  00 42 49 4f 53 20 20 20  20 41 53 4d 00 00 00 60  |.BIOS    ASM...`|
  00008030  02 00 03 00 00 00 00 00  00 00 00 00 00 00 00 00  |................|
  00008040  00 43 50 4d 20 20 20 20  20 53 59 53 00 00 00 3c  |.CPM     SYS...<|
  00008050  04 00 00 00 00 00 00 00  00 00 00 00 00 00 00 00  |................|
  00008060  00 44 44 54 20 20 20 20  20 43 4f 4d 00 00 00 26  |.DDT     COM...&|
  00008070  05 00 00 00 00 00 00 00  00 00 00 00 00 00 00 00  |................|
  00008080  00 44 45 42 4c 4f 43 4b  20 41 53 4d 00 00 00 50  |.DEBLOCK ASM...P|
  00008090  06 00 07 00 00 00 00 00  00 00 00 00 00 00 00 00  |................|
  000080a0  00 44 49 53 4b 44 45 46  20 4c 49 42 00 00 00 31  |.DISKDEF LIB...1|
  000080b0  08 00 00 00 00 00 00 00  00 00 00 00 00 00 00 00  |................|
  000080c0  00 44 53 4b 4d 41 49 4e  54 43 4f 4d 00 00 00 12  |.DSKMAINTCOM....|
  000080d0  09 00 00 00 00 00 00 00  00 00 00 00 00 00 00 00  |................|
  000080e0  00 44 55 4d 50 20 20 20  20 41 53 4d 00 00 00 21  |.DUMP    ASM...!|
  000080f0  0a 00 00 00 00 00 00 00  00 00 00 00 00 00 00 00  |................|
  00008100  00 44 55 4d 50 20 20 20  20 43 4f 4d 00 00 00 04  |.DUMP    COM....|
  00008110  0b 00 00 00 00 00 00 00  00 00 00 00 00 00 00 00  |................|
  00008120  00 45 44 20 20 20 20 20  20 43 4f 4d 00 00 00 34  |.ED      COM...4|
  00008130  0c 00 00 00 00 00 00 00  00 00 00 00 00 00 00 00  |................|
  00008140  00 4c 4f 41 44 20 20 20  20 43 4f 4d 00 00 00 0e  |.LOAD    COM....|
  00008150  0d 00 00 00 00 00 00 00  00 00 00 00 00 00 00 00  |................|
  00008160  00 50 49 50 20 20 20 20  20 43 4f 4d 00 00 00 3a  |.PIP     COM...:|
  00008170  0e 00 00 00 00 00 00 00  00 00 00 00 00 00 00 00  |................|
  00008180  00 52 45 41 44 20 20 20  20 4d 45 20 00 6b 00 01  |.READ    ME .k..|
  00008190  0f 00 00 00 00 00 00 00  00 00 00 00 00 00 00 00  |................|
  000081a0  00 53 54 41 54 20 20 20  20 43 4f 4d 00 00 00 29  |.STAT    COM...)|
  000081b0  10 00 00 00 00 00 00 00  00 00 00 00 00 00 00 00  |................|
  000081c0  00 53 55 42 4d 49 54 20  20 43 4f 4d 00 00 00 0a  |.SUBMIT  COM....|
  000081d0  11 00 00 00 00 00 00 00  00 00 00 00 00 00 00 00  |................|
  000081e0  00 58 53 55 42 20 20 20  20 43 4f 4d 00 00 00 06  |.XSUB    COM....|
  000081f0  12 00 00 00 00 00 00 00  00 00 00 00 00 00 00 00  |................|
  00008200  e5 e5 e5 e5 e5 e5 e5 e5  e5 e5 e5 e5 e5 e5 e5 e5  |................|
  00008210  e5 e5 e5 e5 e5 e5 e5 e5  e5 e5 e5 e5 e5 e5 e5 e5  |................|
  ...
  00809fe0  00 00 00 00 00 00 00 00  00 00 00 00 00 00 00 00  |................|
  00809ff0  00 00 00 00 00 00 00 00  00 00 00 00 00 00 00 00  |................|
  ```

## 2023/8/6

- SD CardをFAT32でフォーマットし、イメージファイルを`DISK00.IMG`としてコピーしておく。
- WBOOTで、トラック1からCCP+BDOSをリロードできるようにした。
- DPBを定義しDISK READに関しては一通りの機能を実装したつもりなのだが、、、
- BIOSのBOOTからCCPを起動(CCPのエントリ+3にジャンプ)するが、ディレクトリの読み込み後に、コンソール出力に`^@`(制御コード)が延々と表示される。この原因がさっぱりわからない。Z80側のデバッグはOUT命令くらいしか使えないので、AVR側からZ80にブレークポイントを張れるようにした。

### ブレークポイント機能の追加

- 簡易モニタに以下のコマンドを追加した。
  - `brk <adr>` : adrに0xff(RST 7)を書き込む。Z80がそのadrを実行すると0x38にトラップし、HALT状態になる。BIOS起動時に38番地にはBIOS内のハンドラへのJP命令をセットしてある。ハンドラ内ではスタック上の戻り先を1命令前に戻し、ブレークポイント達したことをOUT命令でAVRに通知し、HALT状態で待機する。
  - `del <adr>` : adrに書き込んだ命令を元に戻し、ブレークポイントを削除する。
  - `cont` : AVRからZ80に割り込みをかけることで、HALTを解除し、ブレークポイント位置に復帰する。~~復帰先の命令は0xffのままなので、実行前に`del`で命令の復帰とブレークポイント削除を行っておかないと、再度ブレークがかかってしまうので注意。~~ (2023/8/8 ブレークポイントを消すことなくcontできるようにした。)
  - `ib` : ブレークポイントの一覧(アドレスと0xffセット前の命令)を表示する。
- ブレークするとAVRのコンソールに以下が表示される。(2023/8/8 ブレークアドレスは、下位だけでなく上位アドレスも表示するようにした。)
  - `>>>Break! at ブレークアドレス` → 登録したブレークポイントにヒットした
  - `>>>Break! at ブレークアドレス (unexpected)` → 暴走などでRST 7(0xff)を実行

## 2023/8/8

- [エミュレーションデバイス仕様書](Software/EmulatedDeviceSpec.md)を更新。ブレークポイント機能のためのポート0x1d, 0x1eを追加。これで余剰ポートがなくなってしまった。まぁ、足りなくなったらもう1ビット増やせばいいのだけど。
- ブレークポイントの振る舞いを少し賢くしたので、本格的にデバッグすることにしよう。

## 2023/8/9

- ブレークポイント機能を使って、CCP/BDOSの動きを追っていった。
- まず、DDA1の`CALL ENTRY`の前後にブレークを張って観察する。この呼び出しで`^@`が大量表示された。ここはBDOS 10番コール(RDBUFF)で、コンソールからの1行入力。

  ```bash
  DC06 7F                   53 INBUFF:  .db 127   ;length of input buffer.
  DC07 00                   54          .db 0     ;current length of contents.
  DC08 43 6F 70 79 72 69    55     .str    "Copyright"
  ```

  ```bash
                            292 ;
                            293 ;   Get here for normal keyboard input. Delete the submit file
                            294 ; incase there was one.
                            295 ;
   DD96 CD DD DD      [17]  296 GETINP1:CALL    DELBATCH    ;delete file ($$$.sub).
   DD99 CD 1A DD      [17]  297     CALL    SETCDRV        ;reset active disk.
   DD9C 0E 0A         [ 7]  298     LD    C,10        ;get line from console device.
   DD9E 11 06 DC      [10]  299     LD    DE,INBUFF
   DDA1 CD 05 00      [17]  300     CALL    ENTRY
   DDA4 CD 29 DD      [17]  301     CALL    MOVECD        ;reset current drive (again).
  ```
  
  - コンソール入力がないのに、なぜかリターンしてきてDDA4でブレークする。入力文字数がセットされるDC07の値は127になっている。そして確かに127個の`^@`が表示されている。(ちなみにこの値はバッファサイズに連動している。INBUFFの127を3に変えると、DC07の値も3になった。)  
  - DC08からの文字列バッファは0で埋められている。初期値の`Copyright`が消えているので、確かに上書きされている。
- 以上より、コンソール入力周りが怪しい。無入力にも関わらず、入力として受け取ったダミー値をバッファに目一杯書き込んでいるように見える。この条件ではAVRはIN命令で0を返すので辻褄があう。BDOSのバグとは考えにくいので、BIOSの入力チェック(CONSTS)がおかしいのかも？
- DDA1のCALL ENTRYはBDOSのRDBUFFの呼び出しなので、ここを読み進める。
  
  ```bash
                          1512 ;
                          1513 ;   Function to execute a buffered read.
                          1514 ;
  E5E1 3A 0C E7      [13] 1515 RDBUFF:    LD    A,(CURPOS)    ;use present location as starting one.
  E5E4 32 0B E7      [13] 1516     LD    (STARTING),A
  E5E7 2A 43 E7      [16] 1517     LD    HL,(PARAMS)    ;get the maximum buffer space.
  E5EA 4E            [ 7] 1518     LD    C,(HL)
  E5EB 23            [ 6] 1519     INC    HL        ;point to first available space.
  E5EC E5            [11] 1520     PUSH    HL        ;and save.
  E5ED 06 00         [ 7] 1521     LD    B,0        ;keep a character count.
  E5EF C5            [11] 1522 RDBUF1:    PUSH    BC
  E5F0 E5            [11] 1523     PUSH    HL
  E5F1 CD FB E4      [17] 1524 RDBUF2:    CALL    GETCHAR        ;get the next input character.
  ```

  - E5F1の`CALL GETCHAR`(1文字入力)で以下につながる。バッファはまだ空なので`JP CONIN`が呼ばれる。これはBIOSのCONIN(1文字入力)呼び出しのことだ。

  ```bash
                          1345 ;
                          1346 ;   Get an input character. We will check our 1 character
                          1347 ; buffer first. This may be set by the console status routine.
                          1348 ;
  E4FB 21 0E E7      [10] 1349 GETCHAR:LD    HL,CHARBUF    ;check character buffer.
  E4FE 7E            [ 7] 1350     LD    A,(HL)        ;anything present already?
  E4FF 36 00         [10] 1351     LD    (HL),0        ;...either case clear it.
  E501 B7            [ 4] 1352     OR    A
  E502 C0            [11] 1353     RET    NZ        ;yes, use it.
  E503 C3 09 F2      [10] 1354     JP    CONIN        ;nope, go get a character responce.
  ```

  - おい？ちょっと待て。BIOSのキー入力チェック(CONSTS)で入力チェックしてから呼ばれるんじゃないのか？まさかCONINてブロッキングAPIだったの？
    - 答え：　応用CP/M P.11のCONINの説明:「このルーチンは、入力がない場合は内部で入力があるまでループさせること。」
- **原因判明。CONINはブロッキングAPIだった。**
- ということでBIOSのCONINを入力があるまで待つように書き換えたところ、、、**動いた！**

  ```text
  CP/M-80 Ver2.2 on Z80ATmega128

  a>dir
  A: ASM      COM : BIOS     ASM : CPM      SYS : DDT      COM
  A: DEBLOCK  ASM : DISKDEF  LIB : DSKMAINT COM : DUMP     ASM
  A: DUMP     COM : ED       COM : LOAD     COM : PIP      COM
  A: READ     ME  : STAT     COM : SUBMIT   COM : XSUB     COM
  A: ZORK1    COM : ZORK1    DAT
  a>stat
  A: R/W, Space: 0k
  ```

- だが、まだ動作が不安定。`dir`表示が糞づまったりするし、トランジェントコマンドが起動できたりできなかったり。`stat`の結果も怪しい。SD Card上のDISKイメージや、DISK IOにまだバグがありそう。いずれにしても、ブレークポイントをサポートしたことで、デバッグが相当楽になった。

## 2023/8/12

- ブレーク時にZ80レジスタも見れるようにした。やはりスタックとレジスタが見られないのは辛いので。復帰動作に影響が出ないよう、レジスタやスタックを壊さず保存するのは神経を使う。

## 2023/8/13

- DISK I/OのエミュレーションデバイスのI/Oポート数が多いので見直すことにした。DISK位置に3ポート、バッファ、長さの設定に2ポート分確保していたが、それぞれ1ポートにする代わりにシーケンサーを用意し、Highバイトから複数回OUTして設定するようにした。同一ポートをINするとシーケンサーがリセットされる。[エミュレーションデバイス仕様書](Software/EmulatedDeviceSpec.md)を更新した。
- 変更量が多いので [feature/refactoring-portio](https://github.com/46nori/Z80Atmega128/tree/feature/refactoring_portio) ブランチで作業する。

## 2023/8/14

- 動作が不安定な原因が割り込みまわりにあるところまでは見えてきたが、まだよくわからない。
  - DISK READの割り込みがZ80かからない時がある。
  - DISK READ終了を監視するループでの暴走(実際にはRST7のハンドラが呼ばれてブレイクする)。このループはDISK READ完了割り込みのハンドラ内でメモリにセットするフラグをLD命令で監視するだけのコード。ブレイクアドレスをメモリダンプしても0xffになっていない。

## 2023/8/15

- Z80側の割り込みをHALTで受けるように変更したら動作が安定した。だがHALTでの待ち合わせはMode2割り込みによる個別処理を否定する実装なので、この変更は不本意。あとで原因を追求したい。
  - 変更前
    - [Z80] ステータスレジスタを確認。機能実行中であれば割り込みフラグがセットされるのをループで監視。
    - [AVR] 機能の実行が完了したら、あらかじめ指定された割り込みレベルでZ80に割り込みをかける。
    - [Z80] 割り込みがかかったらフラグをセットする。監視ループでフラグを認識したら、再度ステータスレジスタを確認してエラーチェックしリターンする。
  - 変更後
    - [Z80] ステータスレジスタを確認。機能実行中であれば**HALTする。**
    - [AVR] 機能の実行が完了したら、あらかじめ指定された割り込みレベルでZ80に割り込みをかける。
    - [Z80] **割り込みがかかるとHALTが解除される**。再度ステータスレジスタを確認してエラーチェックしリターンする。
  - ちなみにステータスレジスタをIN命令でポーリングすることで、機能の実行完了を確認することもできるが、多数の割り込みがかりAVRに異常な負荷がかかる。このため割り込みを待ってからステータスを確認するようにしている。
- この変更によりREADの途中で暴走する頻度は極端に減った。しかし画面出力の糞詰まりはまだ時々発生する。
- `^C`によるWBOOTの動きが謎。以下のCCP+BDOSのリロードを何度も繰り返して戻ってこない。SELSDKとREADの両方が呼ばれているのが意味不明。

  ```text
  ###SELSDK: DISK00.IMG
  DSK_ReadPos=00000000
  DSK_ReadBuf=dc00
  DSK_ReadLen=1600
  READ:0->1
  >>>READ:000000 : 00

  ###SELSDK: DISK00.IMG
  DSK_ReadPos=00000000
  DSK_ReadBuf=dc00
  DSK_ReadLen=1600
  READ:0->1
  >>>READ:000000 : 00

  ...
  ```
  
  - 他のBIOS実装を眺めてみたら、SETDMAでDMAアドレスの初期値を0x80にセットしているので真似してみた。一瞬良くなったようにも見えたがまだダメみたいだ。
- 気分転換に[Commercial CP/M Software](http://www.retroarchive.org/cpm/)にあるソフトを組み込んだイメージを作成した。ZORK I,II,IIIも入れてみた。

  ```text
  62K CP/M-80 Ver2.2 on Z80ATmega128
  BIOS Copyright (C) 2023 by 46nori

  a>dir
  A: -CCSCPM  251 : ASM      COM : BIOS     ASM : CBIOS    ASM
  A: CCBIOS   ASM : CCBOOT   ASM : CCSINIT  COM : CCSYSGEN COM
  A: CPM24CCS COM : DDT      COM : DEBLOCK  ASM : DISKDEF  LIB
  A: DUMP     ASM : DUMP     COM : ED       COM : FILE_ID  DIZ
  A: GENMOD   COM : LOAD     COM : MOVCPM   COM : PIP      COM
  A: RLOCBIOS COM : STAT     COM : STDBIOS  ASM : SUBMIT   COM
  A: SYSGEN   COM : XSUB     COM : ZORK1    COM : ZORK1    DAT
  A: ZORK2    COM : ZORK2    DAT : ZORK3    COM : ZORK3    DAT
  a>
  ```
  
  ためしにZork Iを起動してみる。
  
  ```text
  a>zork1
  ZORK I: The Great Underground Empire
  Copyright (c) 1981, 1982, 1983 Infocom, Inc. All rights
  reserved.
  ZORK is a registered trademark of Infocom, Inc.
  Revision 88 / Serial number 840726

  West of House
  You are standing in an open field west of a white house, with
  a boarded front door.
  There is a small mailbox here.

  >

  ```

  うぉおおおおーーー。動いた!!

  ```text
  a>zork1
  ZORK I: The Great Underground Empire
  Copyright (c) 1981, 1982, 1983 Infocom, Inc. All rights
  reserved.
  ZORK is a registered trademark of Infocom, Inc.
  Revision 88 / Serial number 840726

  West of House
  You are standing in an open field west of a white house, with
  a boarded front door.
  There is a small mailbox here.

  >take mailbox
  It is securely anchored.

  >look around
  West of House
  You are standing in an open field west of a white house, with
  a boarded front door.
  There is a small mailbox here.

  >open door
  Opening the small mailbox reveals a leaflet.

  >read leaflet
  How does one read a door?

  >quit
  Your score is 0 (total of 350 points), in 5 moves.
  This gives you the rank of Beginner.
  Do you wish to leave the game? (Y is affirmative): >Y
  ```

  CP/Mのプログラムなので 終了時にWBOOTが呼び出されるが、例のCCP+BDOS reloadの無限ループから戻ってこない。(謎に戻ってくるときもあるのだが...)  
  でもモチベーションが爆上がりした。
- しばらくZork Iで遊んでみたが、途中で暴走した(泣)。やはりまだ不安定。

  ```text
  >>>>Break! at $2acc (unexpected)
  AF=$c384 [Z:0 C:0] I=$f3
  BC=$00c1 DE=$0000 HL=$0034
  IX=$efff IY=$fd77 SP=$e734
  (SP+0)=$2acc
  (SP+2)=$2200
  (SP+4)=$2155
  ```

## 2023/8/16

- CONOUTの糞詰まり問題を片づけることにした。
  - AVR側のTX1への出力は9600bpsなので1文字出力には時間は0.83msかかる。そこで1msの周期割り込みハンドラでリングバッファからデキューして出力することとした。つまり1ms毎に出力される。
  - Z80側からのオーバーランを防ぐため、出力リングバッファがfullになったときにZ80に割り込みをかける。Z80は割り込みがかかったらフラグをセットする。1文字出力ルーチンでは、初めにフラグをチェックし、セットされていればバッファに空きが出るまでループ後、1文字出力を行う。
- **突然AVR側が以下のエラーでリプログラムができなくなった。**  
  Error

  ```text
  Failed to enter programming mode. ispEnterProgMode: Error status received: Got 0xc0, expected 0x00 (Command has failed to execute on the tool)

  Unable to enter programming mode. Verify device selection, interface settings, target power, security bit, and connections to the target device.
  ```

  Details

  ```text
  Timestamp:    2023-08-16 17:09:06.826
  Severity:        ERROR
  ComponentId:    20100
  StatusCode:    1
  ModuleName:    TCF (TCF command: Device:startSession failed.)

  Failed to enter programming mode. ispEnterProgMode: Error status received: Got 0xc0, expected 0x00 (Command has failed to execute on the tool)
  ```

## 2023/8/18

- エラーの原因がさっぱりわからん。ライターの故障を疑って別のライターで試してみたが、基本、状況は変わらなかった。以下のエラーになることもあった。

  ```text
  Unable to enter programming mode. The read device ID does not match the selected device or any other supported devices.

  Please verify device selection, interface settings, target power and connections to the target device.
  ```

  Details

  ```text
  Timestamp:    2023-08-18 21:25:25.701
  Severity:        ERROR
  ComponentId:    20100
  StatusCode:    131101
  ModuleName:    TCF (TCF command: Device:startSession failed.)

  Unexpected signature 0x00000102 (expected 0x001e9702).
  ```

  - ちなみにAVRISPmkIIの純正品は2016年にディスコンになっていた。純正の代替品は[ATMEL-ICE](https://www.microchip.com/en-us/development-tool/atatmel-ice)しかないようだ。しかし機能も価格もオーバースペックなので、ちょっと怪しいが[互換品(2699円)](https://www.amazon.co.jp/gp/product/B07L3DT86R/ref=ppx_yo_dt_b_asin_title_o00_s00?ie=UTF8&psc=1)をAmazonで購入した。

- AVRのGPIOの空きに、以下を割り当てた。
  - PE5,6,7を出力に設定し、74HC32のORをバッファにしてLED1,2,3を接続。
  - PG3,4/PE2,3を入力に設定し、DIP SW1,2,3,4を接続。(プロトタイプは基板に4連DIP SWを乗せるスペースが取れなかったので、スライドSWを4つ接続した。)
- Z80のHALTを74HC125のバッファを介してLEDを接続。

## 2023/8/19

- ISP周りに接続されているICの故障も疑い、関係する74HC125, 74HC04を交換したが状況は変わらず。
- FUSE bitの変更で治ったという[StackOverflowの記事](https://stackoverflow.com/questions/54942770/avr-studio-error-got-0xc0-expected-0x00)を見つけた。
  - セラロックの配線を外し、ブレッドボードで4MHzクロックから1MHzを生成してXTAL1に供給してみたが、ISP接続は改善されなかった。
  - たまたま認識したタイミングを使って以下のFUSE設定(0xf7)に変更したが、かえって状況が悪化してしまった。
  
    |          | bit |現在値(0xcf)|推奨値(0x7f)|
    |----------|-----|------------|------------|
    | BODLEVEL |  7  | 1          | 1          |
    | BODEN    |  6  | 1          | 1          |
    | SUT1-0   | 5-4 | 00         | 11         |
    | CKSEL3-1 | 3-1 | 111        | 011        |
    | CKSEL0   |  0  | 1          | 1          |

## 2023/8/20

- 最後の手段でATmega128の交換を実施。  
  が、認識されない。Microchip Studioの再インストールも関係なし。MOSIの接続も確認済み。  
  詰んだなぁ... ハードもAVRのFuse設定も変えていなかったのに、なぜ突然こんな状況になってしまったのだろう。8/16までは非常に安定して認識やリプログラムができていたのに。

  ```text
  Failed to enter programming mode. Error received from tool: 
  Connection failed on the data line (MOSI) 

  Unable to enter programming mode. Verify device selection, interface settings, target power, security bit, and connections to the target device.
  ```

  Details:

  ```text
  Timestamp:    2023-08-20 22:14:56.550
  Severity:        ERROR
  ComponentId:    20100
  StatusCode:    1
  ModuleName:    TCF (TCF command: Device:startSession failed.)

  Failed to enter programming mode. Error received from tool: 
  Connection failed on the data line (MOSI) 
  ```

  Microchip StudioのOutput:

  ```log
  22:14:56: [ERROR] Failed to enter programming mode. Error received from tool: 
  Connection failed on the data line (MOSI) 
  , ModuleName: TCF (TCF command: Device:startSession failed.)
  22:14:56: [ERROR] Failed to enter programming mode. Error received from tool: 
  Connection failed on the data line (MOSI) 
  , ModuleName: TCF (TCF command: Device:startSession failed.)
  22:14:56: [ERROR] Failed to enter programming mode. Error received from tool: 
  Connection failed on the data line (MOSI) 
  , ModuleName: TCF (TCF command: Device:startSession failed.)
  ```

- 上記のエラーを検索したら、Microchipのknowledge baseで ["Unable to enter programming mode" while using ISP interface](https://microchip.my.site.com/s/article/Unable-to-enter-programming-mode-while-using-ISP-interface) という記事を見つけた。クロックに言及されている。[Using crystals and ceramic resonators](https://microchip.my.site.com/s/article/Using-crystals-and-ceramic-resonators) あたりの記事も確認してヒントを探してみるか。ちなみにセラロックの出力をオシロで確認したが、きれいな16MHzの正弦波が出力されていたので信号自体は問題ないと思われる。
- あるいは[AVR042: AVR Hardware Design Considerations](https://ww1.microchip.com/downloads/en/Appnotes/atmel-2521-avr-hardware-design-considerations_applicationnote_avr042.pdf)も読んでISPの共存方法を見直してみるか。
- 高電圧プログラミング([How to perform High Voltage Programming on AVR devices](https://microchip.my.site.com/s/article/How-to-perform-High-Voltage-Programming-on-AVR-devices))というのもあるみたいだが、パラレル書き込みのようなので他の信号との共存が難しそう。そもそもATmega128では使えるのか?

## 2023/8/26

- 以下の実験を行ったが、どれも効果なし。全く改善しない。
  - AVRISP mkIIを互換品に交換。
  - Microchip Studioで、Interface setting>ISP ClockでAVRISP mkIIのクロックを下げた。
  - MISO/MOSI/CLKを3ステートゲートで切り替えているが、[AVR042: AVR Hardware Design Considerations](https://ww1.microchip.com/downloads/en/Appnotes/atmel-2521-avr-hardware-design-considerations_applicationnote_avr042.pdf)の4.1.1に抵抗でMISO/MOSIを共存させる方法が載っていた。5V電源なので510オームで実験した。
  - Windows11をクリーンインストールし、Microchip Studioを入れ直した。

## 2023/8/27

- ライターの問題か切り分けるため以下を実施。
  - 新品のATmega128をTQFP変換基板にマウント。
  - 電源とISPだけ接続して認識できるか確認する。
  - 結果、ATMEL純正AVRISP mkIIはNG。**互換機では認識できた。**
- ISPのCLK出力が74HC125に入力されているが、もしかしてCMOSトレラントでないかもしれないので、10Kの抵抗でプルアップしてみたところ、微妙に間違ったDevice signatureが取れるようになった？
- そこでISP Clockを64KHz以下に落としてみたところ、何とか認識するようになった。デフォルトの128KHzに戻すとエラーになる。
- すかさずFUSEを以下に設定。
  - EXTENDED: 0xFF
  - HIGH: 0xC1
  - LOW: 0x7F
- 約二週間ぶりにリプログラムも成功した。
- **AVRISP mkII互換機かつISP Clockを64KHz**であれば動くようなので、これでしばらく様子を見ることにしよう。

## 2023/9/10

- 久しぶりにデバッグに復帰。CONOUTの見直しを行った。
- TX1出力を1msのタイマ割り込みで実行するのは間に合わない場合がありそう。2ms周期に変更した。
- DISKIOを実行するTIMER2の割り込みハンドラは時間がかかる。デフォルトのISRの設定だと割り込み禁止時間が長くなるため、ISR_NOBLOCKオプションで多重割り込みを許すようにした。

  ```c
  ISR(TIMER2_COMP_vect, ISR_NOBLOCK) {
  ```

- CONOUT出力は改善されたが、まだ糞詰まる場合がある。

## 2023/9/12

- なんか煮詰まってきたので、気分転換にPCBに手をつけ始めた。回路の致命的なバグがあるとものすごい手戻りになりそうな気がするが大丈だろう。気分転換だし。
- さっそく配線のミスを見つけた。動作に支障はないがZ80の外部ピンの対応付けが一部間違っていた。
- さらにAVRの電源未接続も発見。KiCadのATmega128のシンボルライブラリが、なぜかPin52,63Pが定義されているにもかかわらず非表示にされていた。64pinの割に電源とGNDが一対しかないのが気になっていたが、KiCadのシンボルを信じてデーターシートをちゃんと確認していなかった。リプログラムが不安定になるのは、もしかしてこれが原因だったのかも。(2023/9/30: あまり関係なさそう。)

## 2023/9/18

- 9/16からの連休を使って基板を完成させた。
- 基板製造の発注
  - PCB製造メーカーを比較した。国産は5万円弱かかるのに対し中国勢は$100程度。
  - [PCBway](https://www.pcbway.jp/)にした。初回クーポン($5)適用で、送料込み$111.81。中国だがオンラインサイトはしっかりしてとてもわかりやすい。ガーバーデータをアップロードするとオンラインレビューが実行され、承認されると購入手続きになる。非常に簡単。

## 2023/9/22

- PCB製作作業を[こちら](KiCad-PCB.md)にまとめた。
  - 出荷までは3日だった。

    ```text
    2023/09/18 21:25:26 発注
    2023/09/19 15:59:37 製造指示
    2023/09/21 18:05:44 出荷
    ```

  - 中国本土からDHLによる輸送、通関で手元に着荷するのは9/26の予定。

## 2023/9/23

- なんと午前中に基板が到着。発注から5日で手元に届いた。
- さっそくパーツを実装し動作確認を行った。
- 実装手順は以下。背の低いパーツから実装する。
  1. ATmega128
  2. microSD Adopter
  3. カーボン抵抗
  4. 積層セラミックコンデンサ
  5. テスト端子
  6. ICソケット
  7. LED
  8. DIP SW
  9. タクトスイッチ(RESETボタン)
  10. 水晶発振器、セラミック発振子
  11. DCジャック、電源ターミナル
  12. ショートピン
  13. 電解コンデンサ
  14. USBシリアル変換モジュール

- 動作確認手順
  1. 電源のショートをテスターで確認
  2. 全ICのVCC/GNDの接続をテスターで確認
  3. DC5Vを接続し、POWER LEDが点灯すること、テストピンで+5Vが生成されていることを確認。
  4. 以下を装着し、AVRISP mkIIを使用してATmega128のデバイスが認識できるか確認。
     - U1(74HC125), U4(74HC04), U11(74HC08)
     - Microchip StudioからFUSEの設定を行う。
  5. AVRのファームウェアを焼き込み。
  6. 簡易モニタ起動の確認。
  7. `test`コマンドでメモリチェック。
  8. `xload`でCP/Mの読み込み。
  9. `reset`でCP/M起動確認。
  - 6.まで確認できた。外部メモリ、microSDへのアクセスがうまくいっていない。

- 発見したPCBのバグと対策
  - 電源用の2回路２接点トグルスイッチの端子のピッチが異なる -> 小型スライドスイッチを2つ並べて実装
  - R1とAVR ISP用ボックスヘッダのクリアランスがない -> R1は裏面に実装することで回避
  - C23とAVR ISP用ボックスヘッダのクリアランス不足 -> 実装可能だがもう少し離したい
  - C23に1uのシルクがない
  - AE-CH340E-TYPEC(USBシリアル変換モジュール)のフットプリントの上下配置が逆 -> モジュールを裏返しに実装する
  - AE-CH340E-TYPECを実装するとUART CH0/1のシルクが隠れてしまう。モジュールの外形線の外にも記載する

## 2023/9/24

- 外部メモリアクセスとmicroSDのアクセス問題は、ATmega128のハンダ不良が原因だった。
- Z80の動きがおかしい
  - 0番値にHALT命令が書き込まれているにもかかわらず、HALTのLEDが点灯しない。
  - 結線をテスターで確認したが、問題なさそう。
  - オシロでZ80の制御信号をあたってみると、/MREQや/M1は出力されているが、/RDがHのまま変わらない。/HALTもHのまま。つまりメモリからHALT命令がフェッチできていない。なぜこんなことが起こる？
  - 暴走しているのに、/WRがHのまま変化しないのも怪しい。
- PCBのパターンを調べてみたところ、**AVRのPortGの/RD,/WRと、Z80の/RD,/WRが接続されている！**
  - なぜこんなことが起こったか？
  - おそらく回路図エディタのローカルラベルとグローバルラベルの振る舞いについて誤解していたのが原因。
    - AVR側のSRAMアクセス用のXMEM信号PG0, PG1にそれぞれ`/WR`, `/RD`の**ローカルラベル**をつけていた。GPIOと共用ピンなので回路図で見やすいようにするため。
    - 一方、Z80のメモリ信号にも`/WR`, `/RD`の**グローバルラベル**をつけていた。
    - ローカル、グローバルラベルは個別に扱われるものと思い込んでいたが、ネット上は同一信号とみなされてしまうようだ。
    - 回路図上は、ATmega128のシンボル設定でPG0,1のピン属性は双方向になっている。このためERCでは出力同士の衝突検出はされない。電気的に問題なければDRCも当然パスしてしまう。
    - 手配線していれば気づいたのだろうけど、配線量が多く自動配線したこと。それを信じ込んで目視で配線チェックサボったのが流出原因。もちろん自分が悪いのだが、ツールの使い方の誤解が原因なので、気づくのは難しかったなぁ。配線面は表と裏だけなので、パターンカットと手配線で修正できないこともないが、ちょっとこれはショックだ。

## 2023/9/27

- 気を取り直してプリント基板の版下とにらめっこ。8箇所のパターンカットと、6本のパッチで回避可能なことがわかったので、寝た。
- [表面の改修方法](Hardware/PCB/PCB1.0-FP-Errata.pdf)
- [裏面の改修方法](Hardware/PCB/PCB1.0-BP-Errata.pdf)

## 2023/9/28

- プリント基板を改修し、無事、動作することを確認した。
- `/RD`,`/WR`以外の結線エラーはなかったようで一安心。
- 動作が全体的に安定している気がする。なぜかコンソール出力の糞詰まり現象が発生しなくなっている？
- 当初は純正AVRISP mkIIが使えるようになった。が、使っているうちにまたダメになった。互換品はクロックを下げれば使えるようになる。これは試作基板の時と同じ。ISPまわりの挙動は相変わらず謎だ。



## 2023/09/30

- プリント基板でソフトのデバッグ再開。
- CP/Mのシステムリロード(`^C`入力)でCCP+BDOSのロードが無限ループしてしまう問題があった。`Reloaded CPP+BDOS.`のメッセージ出力後にDISK READするとこの問題が回避ができた。だが理由がわからない。(2023/10/02 問題の回避にはなっていなかった。たまたま動いていただけ。根本原因は後述。)
- DISK WRITEで問題が発生しているようだ。B:ドライブのファイル削除やファイルコピーでエラーが発生し、ディスクイメージが壊れる。WRITE系のデバッグはほとんどやってないので、まぁ仕方がない。

## 2023/10/01

- DISK WRITEのデバッグを行った。
  - 書き込みが成功する場合と失敗する場合があるので、Peti Fat FSのマニュアルを読み直すと、こんな制限があった。つまり両者共に512バイトのセクタ境界に合うように書き込まないといけない。
  - [Write operation can start/stop on the sector boundary only.](http://elm-chan.org/fsw/ff/pf/write.html)
  - 書き込み位置直前のセクタ境界までlseekし、先頭と終端のセクタはリード・モディファイ・ライトするようにAVR側のファームを書き換えた。リードの後にポジションを巻き戻すことを忘れないこと。これで、ファイル削除、`SAVE`コマンドなどが動くようになった。
  - `era *.*`で全ファイル削除もできたが、再起動後に`dir`するとファイルの残骸が表示されるので、まだ詰めが甘いかも。
  - 全体的にアクセスが遅い。BIOS側で遅延書き込みをサポートするか、セクタサイズを512bytesに変更した方がいいかもしれない。
- BIOSの`SELDSK`の修正
  - エラー発生時にはにはHL=0でリターンするのが仕様だが、0004Hに書き込まれているカレントディスクも変更しておく必要がありそう。例えば未サポートディスクへのアクセスでエラーになると、カレントドライブが同じままなので、そのディスクをアクセスし続けて正常復帰できなくなる。
  - これはundocumentedと思われる仕様。

## 2023/10/02

- CP/Mのシステムリロード(`^C`入力)で暴走することがあった。(例えば`ZORK1.COM`終了時には`JP 0`しているはずで`WBOOT`が呼ばれる。この時に暴走していた。)
  - 原因はスタックポインタを安全な値にセットしていなかったから。ユーザブログラムはCCP+BDOSを書き潰して良いので、この領域をSPが指している状態でCCP+BDOSをロードすると確実に暴走する。対策は、SPをCCPの先頭アドレスにセットすること。`WBOOT`の先頭でSPをセットするように変更。
- AVRのDISK I/Oの高速化
  - Peti Fat FSは、`file_system.fptr`に現在位置を保持している。R/Wの際に、アクセス位置がfile_system.fptrと異なる時だけ`pf_lseek()`するようにした。これで連続アクセス時のオーバーヘッドが軽減されるはず。
  - SelectDisk()で行っていた`pf_lseek(0)`をやめた。実際にR/Wする時に必要に応じて`pf_lseek()`するから。CP/M BIOSの`SELDSK`のオーバーヘッドを減らしたかったのだが、あまり効果はなかった。
- DISK WRITEはだいぶ安定したが、以下の問題がある。

  ```text
  a>b:
  b>era *.*
  ALL (y/n)?y
  b>dir
  No file
  b>^C
  Reload CCP+BDOS.

  b>dir
  ゴミが表示される
  ```

  もう一度`era *.*`した後に`^C`すると、以後はNo fileになる。
- ファイルコピーにすごく時間がかかる。たぶん、ドライブを跨ぐとSELDSKが発生し、その度にPeti Fat FSで`pf_open()`を行うことになる。ここがボトルネックになっていると思われる。

  ```text
  a>pip b:=zork?.*

  COPYING -
  ZORK1.COM
  ZORK1.DAT
  ```

## 2023/10/03

- セクタ境界で`pf_write(0,0,&bw)`で書き込み終了を行なっていなかったので追加。

## 2023/10/04

- ライトデータの残量計算(len)が間違っていたので修正。
- 2023/10/02のゴミ問題は解決。PIPのファイルコピーも安定して動くようになった。
- ライト操作はまだ遅い。CP/M側からは128byte単位でライト要求が来るのが原因。リードと同様BIOS側で512バイトのブロッキング・デブロッキングをサポートすべきか。

## 2023/10/05

- DISK WRITEの確認継続。ZORK1で、SAVE/RESTOREコマンド動作した。生成されるZORK1.SAVも問題なし。ゴミファイルなどの生成も見られない。かなり安定したと思われる。
- CP/MはBIOSのSELDSKを頻繁に発行する。AVR側は`pf_open()`を実行するが、これに時間がかかる。無駄なSELDSKも見られるので、同じDISK番号を指定されたら`pf_open()`を実行しないようにした。A:での`^C`は速くなった。

## 2023/10/06

- 46nori以外は、Pull Requestなしでmainブランチにpushできないようにした。
  1. .gthub/CODEOWNERSに以下の設定し、mainにpushする。

     ```bash
     * @46nori
     ```
  
  2. GitHub settings/branchesでBranch Protection ruleを`main`で作成し、以下にチェックを入れておく。
     - [x] Require a pull request before merging
       - [x] Require approvals
       - [x] Dismiss stale pull request approvals when new commits are pushed
       - [x] Require review from Code Owners
- Dockerfileからz88dkのコンパイルを外した。結局、今のところ使っていないし、最近MACのDev Containerの起動時にエラーが出るようになってしまったので。必要になったら原因追及する。
- SD Cardに置くイメージファイル(IMAGE00.IMG)を、[cpm22-b.zip](http://www.cpm.z80.de/download/cpm22-b.zip)から生成するように変更した。
  - この中に入っているCPM.SYSは62K CP/Mなので、そのまま使用できる。`mkfs.cpm`コマンドでイメージファイルの予約トラックに書き込む。
  - それ以外のファイルは`cpmcp`コマンドでイメージファイルに埋め込む。

## 2023/10/07

- CP/Mの自律起動をサポートした。仕組みは以下。
  - AVRのEEPROMにCP/M BIOSを置き、起動時にSRAMにロードし、`BOOT:`を呼び出す。
  - `BOOT:`はmicroSD CardからCCP+BDOSを読み込んでCCPを起動するようにする。(`WBOOT:`でやることと同じ。)
- CP/M BIOSの変更
  - `BOOT:`でCCP+BDOSをmicroSD Cardから読み込むようにする。
- BIOSのINTEL HEXファイル生成
  - Makefileに`bios.ihx`ターゲットを追加。
- AVRの簡易モニタへの機能追加
  - EEPROMのダンプ機能(`de`コマンド)
  - SRAMからEEPROMへのSAVE機能(`esave`コマンド)
  - EEPROMからSRAMへのLOAD機能(`eload`コマンド) さらに外から使えるようにする。
- AVRのシステム起動時に、`eload`相当の関数を呼び出して、メモリにロードし、0x0000に`JP 0xf200`を書き込み、Z80にリセットをかける。
- 準備1 (EEPROMへのBIOS書き込み)
  1. `z80/cpm22`でmakeして`bios.ihx`を生成。
  2. `xload`コマンドで`bios.ihx`をXMODEM転送。0xf200にロードされる。
  3. `esave`コマンドでBIOSをEEPROMに書き込む。

    ```text
    >xload
    Start XMODEM within 90s...
    
    Received 2816 bytes.
    >esave 0 $f200 2816
    >
    ```

- 準備2 (microSD Card)
  1. ~~FAT16~~FAT32でフォーマットする。
  2. `z80/cpm22/image`でmakeして生成される`DISK00.IMG`を、ルートディレクトリにコピーしておく。(00を01にするとB:ドライブとして認識される。以後、P:ドライブまで追加可能。)
- microSD Cardを入れて、本体をリセットするとCP/Mが起動するようになる。

## 2023/10/08

- [AVRの電圧が下がるとEEPROMのデータが壊れる問題](https://microchip.my.site.com/s/article/Prevent-EEPROM-corruption)があるらしい。([こちらも参考](https://gaje.jp/2022/05/09/4164/))
  - FUSEでBODを有効にし、LOW.BODLEVELを4.0Vでリセット状態になるように変更した。
  これにより現在のFUSEの設定は以下。
    - EXTENDED: 0xFF
    - HIGH: 0xC1
    - LOW: 0x0F  (旧 0xCF)
  - [仕様書](Hardware/Design.md#fuse-bits)も更新した。
- CP/Mの自律起動の改良
  - システムリセット時にDIPSW4がONならCP/Mの自動起動を、OFFなら簡易モニタのみ起動するようにした。
  - EEPROMに記録するのがBIOSのバイナリだけだと、ロード時にアドレスと長さが決め打ち実装になってしまう。ロードアドレスと長さ情報もEEPROMに記録できるよう、`esave2`コマンドを追加した。以下のフォーマットで記録される。  
    `esave2 <dst> <src> <length>`

    |アドレス  |データ                        |
    |----------|------------------------------|
    |dst       |address                       |
    |dst+2     |length                        |
    |dst+4以降 |srcから始まるlength分のデータ |

  - 以下が改良後の設定手順。

    ```text
    >xload
    Start XMODEM within 90s...    ここでbios.ihxを転送

    Received 2816 bytes.
    >esave2 0 $f200 2816
    >de
    $0000 00 f2 00 0b c3 39 f3 c3 db f3 c3 7c f4 c3 83 f4  .....9.....|....
          ^^^^^ ^^^^^ エントリポイント, 長さ
    >

    ここでDIPSW1 ONにしてリセットボタンを押す

    === CP/M mode ===
    BIOS: 0xf200 - 0xfcff

    ATmega128 Tiny Monitor
    >
    ```

- z80/以下のMakefileのリファクタリングを行った。
- DIPSWでシステムの挙動を変更できるようにした。

  |DIP SW|機能|OFF|ON|PORT|
  |:----:|--------|---|---|----|
  |1     |CP/M起動|しない|する|PORTG3|
  |2     |UART 0/1|9600bps|192000bps|PORTG4|
  |3     ||||PORTE2|
  |4     |外部SRAM wait|1 wait|2 wait|PORTE3|

さて、、これで最低限の必要なことはすべてやりつくしたかな。  
**本プロジェクトのサクセスクライテリアである　「CP/M-80が単独起動し、ZORK Iが遊べる環境の構築」　は達成されたといってよいだろう。**

今後は以下をちまちま行っていく予定。リファクタリングをどこまでやるかはモチベーション次第。

- TODO
  - AVR側
    - [手順書] ファームウェアのビルド、ターゲットへのダウンロード
    - [設計書] 簡易モニタの概要
    - [リファクタリング] F_CPUを再定義しているところがある
    - [リファクタリング] ASFへの無駄な依存の排除
    - [リファクタリング] pf_open()の高速化。DISK I/Oのボトルネックになっている
    - [リファクタリング] DISK WRITEが遅い。[Petit Fat FS](http://elm-chan.org/fsw/ff/00index_p.html)をやめて、ほかの方法を探す。
  - Z80側
    - [手順書] 簡易モニタからコンソール経由でINTEL HEXイメージをダウンロードさせて起動する方法
      - IPL+CCP/BDOS+BIOSのINTEL HEXの生成
    - [手順書] EEPROMにBIOSを書き込んで自動起動させる方法
      - BIOSのINTEL HEXの生成と、EEPROMへの書き込み方法
    - [設計書] BIOSの設計書
    - CP/Mイメージの概要
      - [手順書] イメージの生成方法
        - いろいろなイメージを作れるような環境も整備したほうがいいかも。
        - ZORKの取り込み方などはまだ自動化など。
      - [設計書] microSD CardでのDISKエミュレーションの仕組み
      - [設計書] イメージの構造
    - [リファクタリング] BIOSのDISK WITE高速化のためのブロッキング・デブロッキングサポート
  - システム全体
    - ~~[手順書] 基板、DIPSW、LEDの説明。必要な電源容量など。これは設計書か？~~ (2023/10/11)
    - [設計書] [ハード仕様書](Hardware/Design.md)の見直し
    - ~~トップのREADME.mdで、実現できたことの説明を追記~~ (2023/10/11)
    - ~~[手順書] PCB Rev1.0の改修方法~~ (2023/10/11)
    - PCBの作り直しはどうしようかなぁ

## 2023/10/10

- 不要なファイル削除、いろいろリファクタリングした。

## 2023/10/11

- [SetupGuide](./SetupGuide.md)を追加

## 2023/10/12

- `avr/src/main.c`でPORTB4をチェックし、CP/M modeでSD Cardの挿入状態を確認するようにした。
- z80/cpm以下のディレクトリ構成を変更し、`bios/`と`sys/`にファイルを分離した。

## 2023/10/14

- デモビデオを作成し、README.mdにリンクした。実体はYouTubeの[ここ](https://youtu.be/2_RJPk65XRE)にある。
- とりあえずここまでで一旦、開発終了。
- ~~コミット `1b330e465dc1f0a77b62a91e1d17c844d12498b4`に`v1.0`のタグを打った。~~(2023/10/22 でかいバグが見つかったので削除した)

## 2023/10/17

- CP/M BIOSに致命的なバグ発見。DPHは論理ディスクごとに必要なのにもかかわらず、A:ドライブ用しか用意していなかった。残メモリとの兼ね合いで、E:までの５台分の領域を確保した。0xf200-0xfe1fまで使用しているので、残メモリは481bytes。

## 2023/10/21

- CP/M BIOSのDISK WRITEのデブロッキング対応を行った。
  - AVRでの無駄なリードモディファイライトが減って、ライトが高速になった。
  - AVRへのライト要求を行う条件を以下とした。
    - BDOSがWRITEを呼ぶときCレジスタにセットするBlocking CodeがImmediate Writeのとき(C=1)。
    - BIOSの4セクタ分のデータバッファ(512byte)の最終ブロックに書き込まれたとき。
  - それ以外はなるべくSD Cardのクラスタサイズ(512byte)単位でライトできるよう、最大連続4セクタまでキャッシュする。
  - DSKSELとREADの前にPending Writeのフラグをチェックして書き出すようにした。Blocking Codeだけでは信用できないことがあったので。
  - ライトは高速化されたものの、SELDSKで呼ばれるPetit FatFSのpf_open()が処理時間の多くを占めている。Z80からの割り込みハンドラでブロッキング処理していることもあり、ここはもっと高速化させたいところ。しかしファイルが同時に１つしかopenできない仕様に制約されている。本システムの使い方は限定的なので、pf_open()のロジックに手を入れて、あらかじめ特定ファイルを複数同時オープンしておくように改造すればよいかもしれない。
- AVRのDISK WRITE(`em_disk_write()`)のバグを修正。
  - SDカードのクラスタ(512バイト境界)にアラインしてないデータをライトさせる場合、当該クラスタをリードモディファイライトする必要がある。ライトするデータ長が512バイト未満の場合が考慮されていなかった。このため未書き込みのデータ量の計算が０でなく、大量に残っている状態になってしまい、無駄な書き込みを行っていた。これがディレクトリを壊していた。

## 2023/10/22

- 簡易モニタ(ATmega128 Tiny Monitor)のコマンドリファレンスのドキュメントを追加。
- `develop`から`main`にマージし`v1.0`のタグを打ち直し。

## [続き](Diary3.md)

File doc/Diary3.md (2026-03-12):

#

## [以前の日記](Diary2.md)

## 2023/10/24

- PCB Rev2.00の更新。

## 2023/10/26

- PCB Rev2.00をPCBWayに発注。

## 2023/11/01

- PCB Rev2.00入荷。

## 2023/11/02

- Rev1.00のバグ修正したfeature-PCB2ブランチをdevelopにマージした。
  - PCB Rev2.00にパーツをマウントし動作確認できた。
  - 配線、パーツ間のクリアランスも問題なし。
  - 残念ながらUSB-Cシリアル変換モジュールの信号名のシルクが間違っている。修正忘れ。
  - [Hardware Release Note](./Hardware/HW-ReleaseNote-ja.md)などのドキュメントも更新。

## 2023/11/03

- CP/Mのディスクイメージを作りやすくするとともに、ドキュメントを追加した。
  - システムディスク、空ディスク、ZORK I/II/IIIのイメージ作成をMakefileのターゲット指定でできるようにした。
  - developブランチにマージ済み。

## 2023/11/04

- CP/M BIOSのドキュメント追加。
- Boot sequenceのドキュメント追加。

## 2023/11/05

- `z80/cpm22/image/mkimg.sh`で引数チェックのバグを修正。DiskImage-CPM22.mdも更新。
- v2.0をリリースした。

## 2023/11/11

10/24にeBayで購入した、旧東ドイツ製 Z80互換CPU(デッドコピー)の`U880`がウクライナから届いた。
パッケージのシルクは`80A-CPU MME`となっているが、[Wikipedia](https://en.wikipedia.org/wiki/U880)によるとこれはピン間隔2.54mmの輸出版らしい。
換装して動作確認したところ、あっさり動いた。あたりまえか。

以下が[eBay](https://www.ebay.com/itm/324007899221)にあったスペックだが、Soviet cloneってのはちょっと違うんじゃないか？

```text
80A CPU MME Soviet Clone Z80A IC 4MHz NMOS MCPU logic 8-bit microprocessor NEW

MME 80A-CPU

Soviet Clone Z80A
Manufacturer: MME Erfurt
Type: Microprocessor
Introduced: 198х
Name (codename): Z80A clone
Code (Copyright): 80A-CPU (no)
Specification number: no
Core speed: 4MHz
BUS: 4MHz, 8-bit
Transistors хх
Technology: 3.0-micron NMOS
L1/L2 cache: no / no
Can address: 64 kB of physical memory
V core: 5V
Power dissipation (max.): х W
Operating temperature (min./max.): 0 — 70°C
Package (Socket): Plastic DIP 40-pin (40-pin DIL)
Dimensions: 52 x 15 x 8mm
```

[こんな文書](https://datasheet.datasheetarchive.com/originals/scans/Scans-048/DSAGER000639.pdf)にUA880の記載がある。

## 2023/11/12

- CP/M Plusの対応を始めた。
- [これ](http://www.cpm.z80.de/download/cpm3on2.zip)を利用すれば、CP/M 2.2からCP/M 3が起動できるみたいだ。まずCP/M 2.2を起動し、二段ロケット方式でCP/M3を起動する。
- 62K CP/M 2.2 BIOSがそのまま再利用できる。BIOSのジャンプテーブルを参照可能なシンボルファイルをリンクすることで、CPM3.SYSとCPMLDR.COMを生成する。(CP/M2.2上アセンブラ、リンカを動かして生成する。)
- このイメージになるように、LDRBIOS.ASMの`bios`を値を、BIOS2の先頭アドレス`f200h`に変更する。

  ```text
        CP/M 2.2           CP/M 3
  0000H +--------+         +--------+
  0100H |--------|         |--------|
        |  TPA   |         |  TPA   |  
        | (55K)  |         | (52K)  |
        |        |   D000H |--------|
  DC00H |--------|         |        |
        |  CCP   |         | BDOS3  |
        | (800H) |         | (1D00H)|
  E400H |--------|         |        |
        | BODS2  |   ED00H |--------|
        | (800H) |         | BIOS3  |
        |        |         | (400H) |
  F200H |--------| - - - - |--------|
        | BIOS2  |         | BIOS2  |
        | (E00H) |         | (E00H) |
  FFFFH +--------+ - - - - +--------+
  ```

- `gencpm.com`でCPM3.SYSを生成するが、このメモリマップになるようにするには、以下のようにパラメータをセットする。ノンバンクメモリバージョンで生成。

  ```text
  Top page of memory (FF) ? F0
  Bank switched memory (Y) ? N
  ```

## 2023/11/13

- CP/M 3が動いた。
- BIOSとCPMLDR.COMの生成は、`gen.sub`のバッチファイルを使うのが便利だが、A:ドライブに置かないといけない。また、CP/M2.2用のsubmit.comを使う必要がある。
- A:に、CPMLDR.COM, CPM3.SYS, CCP.COMをコピーして、CPMLDR.COMを起動すると、CP/M3が立ち上がった。なんかリターンがたくさん入るけど。。

  ```text
  62K CP/M-80 Ver2.2 on Z80ATmega128
  BIOS Copyright (C) 2023 by 46nori

  A>cpmldr

  CP/M V3.0 Loader
  Copyright (C) 1998, Caldera Inc.

  BIOS3    SPR  ED00  0400
  BDOS3    SPR  CE00  1F00

  51K TPA
  A>
  ```

- PC-8801mkIIでCP/M 2.2を使っていた頃は、CP/M Plusに憧れがあったのだけど、いまのところありがたみも凄みも感じられないなぁ。。
- DIRコマンドとか？
  
  ```text
  A>dir.com

  Scanning Directory...

  Sorting  Directory...

  Directory For Drive A:  User  0

      Name     Bytes   Recs   Attributes      Name     Bytes   Recs   Attributes
  ------------ ------ ------ ------------ ------------ ------ ------ ------------
  BDOS3    SPR    16k     77 Dir RW       BIOS3    SPR     8k      9 Dir RW
  BIOS3    SYM     8k      2 Dir RW       BNKBDOS3 SPR    16k    106 Dir RW
  CCP      COM     8k     25 Dir RW       COPYSYS  COM     8k     15 Dir RW
  CPM3     SYS    16k     72 Dir RW       CPMLDR   COM     8k     25 Dir RW
  CPMLDR   REL     8k     23 Dir RW       CPMLDR   SYM     8k      2 Dir RW
  DATE     COM     8k     26 Dir RW       DEVICE   COM     8k     57 Dir RW
  DIR      COM    16k    114 Dir RW       DUMP     COM     8k      8 Dir RW
  ED       COM    16k     73 Dir RW       ERASE    COM     8k     30 Dir RW
  GBIOS    ASM    16k    103 Dir RW       GBIOS    PRN    24k    164 Dir RW
  GBIOS    REL     8k      6 Dir RW       GBIOS    SYM     8k      9 Dir RW
  GEN      SUB     8k      1 Dir RW       GENCOM   COM    16k    115 Dir RW
  GENCPM   COM    24k    166 Dir RW       GET      COM     8k     51 Dir RW
  HELP     COM     8k     55 Dir RW       HELP     HLP    64k    496 Dir RW
  HEXCOM   CPM     8k      9 Dir RW       LDRBIOS  ASM    16k    103 Dir RW
  LDRBIOS  PRN    24k    164 Dir RW       LDRBIOS  REL     8k      6 Dir RW
  LDRBIOS  SYM     8k      9 Dir RW       LINK     COM    16k    122 Dir RW
  PATCH    COM     8k     19 Dir RW       PIP      COM    16k     68 Dir RW
  PUT      COM     8k     55 Dir RW       README   1ST     8k      9 Dir RW
  Press RETURN to Continue

  Directory For Drive A:  User  0

      Name     Bytes   Recs   Attributes      Name     Bytes   Recs   Attributes
  ------------ ------ ------ ------------ ------------ ------ ------ ------------
  RENAME   COM     8k     23 Dir RW       RESBDOS3 SPR     8k     16 Dir RW
  RMAC     COM    16k    106 Dir RW       SAVE     COM     8k     14 Dir RW
  SCB      REL     8k      3 Dir RW       SET      COM    16k     81 Dir RW
  SETDEF   COM     8k     34 Dir RW       SHOW     COM    16k     66 Dir RW
  SUBMIT   COM     8k     10 Dir RW       TYPE     COM     8k     24 Dir RW

  Total Bytes     =    576k  Total Records =    2771  Files Found =   46
  Total 1k Blocks =    370   Used/Max Dir Entries For Drive A:   46/ 256

  ```

## 2023/11/16

- 以下のパッチをあてるときにエラーになる場合があるので、Issueを上げた。([Issue 10](https://github.com/46nori/Z80Atmega128/issues/10), [Issue 12](https://github.com/46nori/Z80Atmega128/issues/12))
  - z80/cpm22/sys/CPM22-asz80.patch
  - z80/cpm3/image/CPM3-LDRBIOS.patch

  ```bash
  vscode@Z80ATmega128:/z80/cpm3/image$ make

  ...

  patch -i CPM3-LDRBIOS.patch ./tmp/cpm3on2/LDRBIOS.ASM
  patching file ./tmp/cpm3on2/LDRBIOS.ASM
  Hunk #1 FAILED at 110 (different line endings).
  1 out of 1 hunk FAILED -- saving rejects to file ./tmp/cpm3on2/LDRBIOS.ASM.rej
  make: *** [Makefile:89: tmp/cpm3on2] Error 1
  ```

  - 原因
    - checkout時にファイルの改行コードがLFになるから。パッチ適用先のCP/MのファイルはCRLFなので、Gitで勝手にLFに変換されてしまうと行が一致しないのでエラーになる。
  - 対策
    - `.gitattributes`に以下を追加して、強制的に改行コードをCRLFにする。

      ```bash
      *.patch text eol=crlf
      ```

    - さらにpatchコマンドにバイナリ比較オプション`--binary`を追加したら解決した。(だが、なぜこれが必要なのかよくわからない。。)
- Ubuntu 22.04上で`mkfs.cpm`でディスクイメージ作るとエラーになる。`apt install cpmtool`した`/etc/cpmtools/diskdefs`に`sdcard`の定義が存在しないのが原因。コマンドラインで指定できないのでdiskdefsに定義を追加するしかない。wontfix扱いで[Issue 13](https://github.com/46nori/Z80Atmega128/issues/13)を登録した。

## 2023/11/18

10/24に[eBay](https://www.ebay.com/itm/165487756685)で発注した`Z8400APS`(5個セット)が届いた。深圳からだけどEconomy International Shipping($2USD)だったので時間かかった。

## 2023/11/24

- [樫木総業](https://www.kashinoki.shop)に発注していたNECのuPD780C-1が届いた。
- いまのところZ80Aのコレクションはこんな感じ。

  |Manufacturer|型番          |ロット?|その他                            |
  |------------|--------------|-------|----------------------------------|
  |Zilog       |Z8400APS      |8320   |中学生の頃入手                    |
  |Zilog       |Z8400APS      |9013   |eBayで購入                        |
  |SHARP       |LH0080A       |9640   |SHARP MZ-80Bで採用                |
  | NEC        |uPD780C-1     |8338X5 |NEC PC-8001で採用                 |
  | MME        |80A-CPU (U880)|       |eBayで購入。旧東ドイツ製。輸出版。|

## 2023/11/25

- Z80を何度も挿抜しているとチップもソケットも傷がつくので、評価用にゼロプレッシャーソケットの基板を1枚作った。
- eBayで購入した5個セットのZ8400APS、全数チェックしたら1個故障していた。(泣)

### 基板の動作確認時に地味にハマったことのメモ

1. TinyMonitorの`test`コマンドがハングアップする。  
   Z80を載せておかないといけない。/BUSACKによるZ80のバス解放をAVRのPD6で確認しているため。
2. `Insert microSD Card`が表示される。  
   microSD Card slotの挿入状態が正しく取れていない。以下を確認。  
   - PB6のハンダ不良
   - microSD Card slotの9番ピン、10番ピン(GND)のハンダ不良

## 2023/12/26

冬休みに入ったので、([Issue #11](https://github.com/46nori/Z80Atmega128/issues/11))に手をつけることにした。

SELDSKが遅いため、ファイルコピーなどドライブの切り替えが発生するとパフォーマンスが著しく低下する問題。ストレスフルなので何とかしたい。

Petit FatFsではファイルが同時に1つしかオープンできない制約があるため、SELDSKでDISKイメージファイルを切り替えるたびにpf_open()を実行する必要がある。ここに2,3秒かかっている。すべてのDISKイメージファイルがあらかじめオープンしておけるなら、pf_open()が不要になるので相当早くなるはずだ。

複数ファイルの同時オープンは[FatFs](http://elm-chan.org/fsw/ff/)を使用すれば可能。そもそもPetit FatFsを採用したのは以下の理由なので、フットプリントの懸念がなければFatFsに乗り換えられる。

- CP/Mでは同時に複数のディスク(イメージファイル)にアクセスする必要がない。(が、まさかpf_open()がこんなに遅いとは思わなかった。)
- AVRのRAMが4KBしかない。当初は全体でどのくらいメモリを食うか正確に見積もるのは難しかったため、フットプリントはなるべく小さくしたかった。

改めて[FatFsのフットプリント](http://elm-chan.org/fsw/ff/doc/appnote.html#memory)を調べてみた。

- 条件
  - $V=1$ : 1物理ドライブ
  - $F=5$ : 5ファイル (A: - E:の5 DISKイメージ分)
- 必要なSRAMサイズ
  - .bss = $V \times 4 + 2$ = 6
  - `FF_FS_TINY==0`の場合
    - .bss + Work area $= 6 + V \times 560 + F \times 546 = 3296$
  - `FF_FS_TINY==1`の場合
    - .bss + Work area $= 6 + V \times 560 + F \times 34 = 736$

現在の残SRAMサイズは2048bytesなので、**`FF_FS_TINY == 1`なら問題ない。**

ということで、ブランチ`feature-FatFs`で作業することにした。

- FatFsのソース管理用に`avr/src/fatfs/`を作成。(`avr/src/petitfs/`の代替)
- FatFs本体(R0.15)とパッチを入手し、patch3まで適用してコミット。
  - [ff15.zip](http://elm-chan.org/fsw/ff/arc/ff15.zip) : FatFs本体(R0.15)
  - [Patches](http://elm-chan.org/fsw/ff/patches.html) : パッチ
  - `ffsystem.c`と`ffunicode.c`は不要
- サンプルをダウンロードしてAVR用のソースを取り出す。
  - [ffsample.zip](http://elm-chan.org/fsw/ff/ffsample.zip) : サンプル
  - `diskio.h`,`mmc_avr.h`,`mmc_avr_spi.c`をカスタマイズして使用する。
  他は不要。

## 2023/12/27

Petit FatFsからFatFsへの乗り換え作業を実施。意外と簡単に移行できた。  
非常に速くなった！特にPIPのファイルコピーが劇的に改善された。  
現在のメモリ残量は1265bytes。

### 変更点

- Microchip StudioのSolution Explorerで、`petitfs/`を削除、`fatfs/`を追加。
- `petitfs/`は削除。
- `ffconf.h`
  - ディレクトリ関連のAPIは不要。RTCはハード的に存在しないので不要。LFNも使用しない。文字列処理やUNICODE対応も不要。
  - 以下のようにコンフィグレーションを変更する。

    ```c
    #define FF_FS_MINIMIZE  2
    #define FF_FS_TINY      1
    #define FF_FS_NORTC     1
    ```

- `diskio.c`
  - MMCの実装以外は削除。
- `diskio.h`
  - `mmc_avr_spi.c`に合うように、サンプルから中身をほぼコピー。
- `mmc_avr_spi.c`
  - Platform依存のSPIやポートのマクロ定義を`petitfs/diskio_avr.c`の実装からコピぺ。
  - `power_on()`に、SPIの初期化コードを`petitfs/diskio_avr.c`の実装からコピぺ。
  - `FCLK_SLOW()` 16MHzの1/64に設定。
  - `FCLK_FAST()` 16MHzの1/2に設定。
  - `MMC_CD` Card検出をサポート。
  - `MMC_WP` WRITE PROTECTサポート。未使用だったDIPSW3がON時にプロテクト状態とした。
  - `disk_timerproc()`で以下をチェック。
    - MMC_WPなら、YELLOW LEDを点灯させる。
    - MMC_CD未挿入なら、BLUE LEDを点灯させる。
  - タイムアウト処理を行っているので`disk_timerproc()`を10msごとに呼び出す必要がある。isr.cのTIMER2の10msの周期割り込みハンドラ内で呼び出す。
- `em_diskio.c`
  - FatFSのAPIに乗り換え。
  - `init_em_diskio()`でDISKイメージファイル5つをすべてオープン。
  - `OUT_0A_DSK_SelectDisk()`でのオープン処理を削除し、カレントDISKイメージのポインタだけ切り替えるように変更。
  - Writeのフラッシュ処理を`f_sync()`に変更。

## 2023/12/28

- CP/M起動後にmicroSDをWRITE PROTECT ON/OFFしたときに復帰できるよう、以下の変更を実施。現在のメモリ残量は1151bytes。
  - `OUT_0A_DSK_SelectDisk()`で、指定されたDISKイメージファイルがエラー状態だったら、再openし、エラー状態をリセット。
  - エラー発生で全滅しないよう、ドライブごとに状態を独立管理させた。

- v3.0リリース

## [続き](Diary4.md)

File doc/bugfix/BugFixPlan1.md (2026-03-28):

# Z80ATmega128 バグ修正計画書

## 概要

Z80ATmega128 システムのコードレビューで発見されたバグの修正計画を策定する。本報告書は以下を含む。

1. バグ一覧と各バグの詳細
2. バグ間の依存関係
3. 修正の優先順位
4. 修正ステップと各ステップの詳細（修正方法を含む）

### 対象ソースコード

- AVR 側: `avr/src/` 以下
- Z80 BIOS: `z80/cpm22/bios/bios.asm`

### 運用条件

- シリアル通信速度: 9600 bps または 19200 bps

---

## 1. バグ一覧

| ID | 重大度 | 概要 |
|---|---|---|
| BUG #1  | CRITICAL  | `z80_int_vector` のレースコンディション |
| BUG #2  | CRITICAL  | `cli()` 後の `ExtMem_attach()` によるデッドロック |
| BUG #4  | MODERATE  | `x_enqueue()`/`x_dequeue()` の ISR 内 `sei()` 問題 |
| BUG #5  | LOW | `Transmit_TX1_Buf()` に `z80_int_num_tx1 < 128` ガードがない |
| BUG #6  | CRITICAL  | `LOAD_CCP_BDOS` にリジェクション・リトライがない |
| BUG #7  | CRITICAL  | `SELDSK` が AVR 側の進行中ディスク操作を強制リセット |
| BUG #8  | IMPORTANT | Timer2 ISR (`ISR_NOBLOCK`) の再入リスク |
| BUG #9  | IMPORTANT | DEBUGGER の HALT が DI 状態で実行される |
| BUG #10 | MODERATE  | `int_level_write`/`int_level_read` に `volatile` がない |
| BUG #11 | MODERATE  | `IN_0E_DSK_WriteStatus()`/`IN_13_DSK_ReadStatus()` の `sei()` 問題 |
| BUG #12 | MODERATE  | `Enqueue_RX1_Buf()` バッファ満杯時のデータロストと偽割り込み |
| BUG #13 | MODERATE  | `ConsoleBuffer` の `count`/`head`/`tail` に `volatile` がない |
| BUG #14 | LOW | `USART1_Transmit()` の Timer0 ISR 内ビジーウェイト（9600/19200bps） |
| BUG #15 | LOW | CONOUT フロー制御の閾値ギャップ |

> BUG #3 は欠番。

---

## 2. 各バグの詳細

### BUG #1 [CRITICAL]: `z80_int_vector` のレースコンディション

**ファイル**: `avr/src/z80io.c` (L138-142), `avr/src/isr.c` (L64-80)

**問題のコード**:

```c
// z80io.c L138
void Z80_EXTINT_low(uint8_t vector)
{
    z80_int_vector = vector;
    CLR_BIT(PORTD, PORTD4);     // /INT = Low
}
```

**原因**: `Z80_EXTINT_low()` は以下の 4 つの ISR コンテキストから呼ばれ、単一のグローバル変数 `z80_int_vector` を排他制御なしに書き換える。

| 呼び出し元 | ISR コンテキスト | ベクタ値 |
|---|---|---|
| `em_disk_read()` 完了/reject | Timer2 (`ISR_NOBLOCK`) | 0x00 |
| `em_disk_write()` 完了/reject | Timer2 (`ISR_NOBLOCK`) | 0x02 |
| `Transmit_TX1_Buf()` | Timer0 (1ms 周期) | 0x04 |
| `Enqueue_RX1_Buf()` | USART1_RX | 0x06 |

Timer2 ISR は `ISR_NOBLOCK` のため実行中に割り込みが再許可される。`Z80_EXTINT_low()` が `/INT=Low` にした後、Z80 が INTA サイクルを開始するまでの約 2〜8µs の間に Timer0 または USART1_RX が割り込むと、`z80_int_vector` が上書きされる。`/INT` は既に Low のため 2 回目の `CLR_BIT` では Z80 側に変化が通知されず、上書き前のベクタに対応する割り込みが消失する。

**競合シナリオの詳細**:

1. Timer2 ISR 内で `em_disk_read()` が完了 → `Z80_EXTINT_low(0)` 呼び出し
2. `z80_int_vector = 0`、`/INT = LOW`
3. Z80 が `/INT` を検知、割り込みアクノレッジサイクル開始
4. **この瞬間** Timer0 ISR がプリエンプト（Timer2 は `ISR_NOBLOCK` のため可能）
5. `Transmit_TX1_Buf()` がバッファ状態変化を検知 → `Z80_EXTINT_low(4)` 呼び出し
6. **`z80_int_vector = 4` に上書き!** `/INT` は既に LOW なので変化なし
7. Timer0 ISR 復帰、AVR `ISR(INT4_vect)` が発火
8. INT4 は上書きされた `z80_int_vector = 4`（CONOUT ベクタ）を Z80 に提供
9. Z80 は **ISR_02（CONOUT handler）** に飛ぶ — 本来は ISR_00（DISK READ 完了）に飛ぶべき
10. `IS_READ_DONE` は**永久にセットされない**

**衝突確率の推定**: `Z80_EXTINT_low()` 呼び出しから INT4 発火までの時間窓は約 3〜10µs。Timer0 は 1ms 毎に発火するため、各ディスク操作での衝突確率は約 0.3〜1%。Zork I のような長時間ゲームプレイ中の多数のディスク I/O では、1 時間以内に少なくとも 1 回の衝突が発生する確率は極めて高い。

**影響**: ディスク I/O 完了割り込みが消失した場合、Z80 が以下のポーリングループに永久滞留する：

```asm
WAIT_READ_COMPLETE:
        LD A, (IS_READ_DONE)
        OR A
        JR Z, WAIT_READ_COMPLETE    ; 無限ループ
```

---

### BUG #2 [CRITICAL]: `cli()` 後の `ExtMem_attach()` によるデッドロック

**ファイル**: `avr/src/emuldev/em_diskio.c` (L339-343, L376-380, L425-429, L564-568, L575-579)

**問題のコード** (em_disk_read の例):

```c
// em_diskio.c L564
cli();
ExtMem_attach();
memcpy(dst, tmpbuf, sizeof(tmpbuf));
ExtMem_detach();
sei();
```

`ExtMem_attach()` → `Z80_BUSREQ(1)` → `/BUSACK` を無限待ちする。

**`Z80_BUSREQ()` の実装** (`z80io.c`):

```c
void Z80_BUSREQ(int st)
{
    if (st) {
        CLR_BIT(PORTD, PORTD6);       // /BUSREQ = Low
        while (PIND & _BV(PORTD7)) {  // /BUSACK を待つ（無限ループ）
        }
    }
}
```

**デッドロックシナリオの詳細**:

1. Timer2 ISR（`ISR_NOBLOCK`）実行中
2. `cli()` で全割り込み無効化
3. **この瞬間** Z80 が IN/OUT 命令実行中 → ハードウェア WAIT 回路が `/WAIT = LOW` に
4. Z80 は WAIT 状態で停止（マシンサイクル未完了）
5. AVR が `Z80_BUSREQ(1)` → `/BUSREQ = LOW`
6. Z80 は **WAIT が解除されるまで** `/BUSACK` を応答不可
7. WAIT の解除には INT0/INT1 ハンドラの実行が必要 → **`cli()` で不可能**
8. **デッドロック**: AVR は `/BUSACK` を永久に待ち、Z80 は WAIT 状態で永久停止

**影響**: AVR と Z80 の相互デッドロック。

---

### BUG #4 [MODERATE]: `x_enqueue()`/`x_dequeue()` の ISR 内 `sei()` 問題

**ファイル**: `avr/src/xconsoleio.c` (L149-153, L170-174)

**問題のコード**:

```c
// xconsoleio.c L149
cli();
cb->buffer[cb->tail] = data;
cb->tail = (cb->tail + 1) % cb->size;
cb->count++;
sei();          // ← 呼び出し元の割り込み状態を無視
```

ISR 内から呼ばれた場合、ISR 完了前に `sei()` が割り込みを再有効化する。これにより Timer0/Timer2/USART1_RX 間の予期しないプリエンプションが発生し、BUG #1 のレース窓が広がる。

**影響**: BUG #1 のレース発生確率の増大。

---

### BUG #5 [LOW]: `Transmit_TX1_Buf()` に `z80_int_num_tx1 < 128` ガードがない

**ファイル**: `avr/src/emuldev/em_consoleio.c` (L52-64)

**問題のコード**:

```c
// em_consoleio.c L58
if (cb_tx1.count == 0 ||
    cb_tx1.count == cb_tx1.size / 4 ||
    cb_tx1.count == cb_tx1.size / 2) {
    Z80_EXTINT_low(z80_int_num_tx1 << 1);   // ← ガードなし
}
```

`Enqueue_RX1_Buf()` には `z80_int_num_rx1 < 128` のガードがあるが、`Transmit_TX1_Buf()` にはない。BOOT で `z80_int_num_tx1 = 2` に設定されるため CP/M 通常動作時には実害はないが、設計上の非対称性であり、初期化前に呼ばれた場合のリスクがある。

**影響**: 初期化前の意図しない割り込み送信。低リスク。

---

### BUG #6 [CRITICAL]: `LOAD_CCP_BDOS` にリジェクション・リトライがない

**ファイル**: `z80/cpm22/bios/bios.asm` (L341-344)

**問題のコード**:

```asm
; bios.asm L342
        CALL DISK_READ_SUB
        OR A
        RET Z                   ; Success
        ; ↓ A≠0 → 全てエラー扱い → BOOT_ERROR_HALT
```

通常の READ パス (`RETRY_READ`, L665) では `CP 4` によりリジェクト(4)をリトライするが、`LOAD_CCP_BDOS` では `OR A` で非ゼロをすべてエラーとして `BOOT_ERROR_HALT` に到達する。

**`DISK_READ_SUB` の返すステータス**:

| 値 | 意味 | 通常 READ (MISHIT_CACHE) の処理 | LOAD_CCP_BDOS の処理 |
|----|---|---|---|
| 0 | 成功 | 成功 | 成功 |
| 1 | 読み込み中 | （通常到達しない） | **HALT!** |
| 2 | エラー | READ_ERROR | **HALT!** |
| 4 | リジェクト | **リトライ** | **HALT!** |

**AVR 側でリジェクトが発生する条件** (`em_diskio.c`, `OUT_13_DSK_Read()`):

```c
void OUT_13_DSK_Read(uint8_t data)
{
    // WRITE が進行中なら REJECT
    if (cfd->write.state == DOING || cfd->write.state == REQUESTING) {
        cfd->read.state = REJECTED;
    } else {
        switch (cfd->read.state) {
        case REQUESTING:  // 前回の READ が未完了
        case DOING:
            cfd->read.state = REJECTED;
            break;
        ...
        }
    }
}
```

**BOOT_ERROR_HALT への到達シナリオ**:

- **シナリオ 1: SD カードのトランジェントエラー** — 多数のディスクアクセス中に SD カードに一時的なエラー（CRC エラー、タイムアウト等）が発生。BDOS がエラー検出後にウォームブートを実行するが、`LOAD_CCP_BDOS` では SD カードエラーが継続するとステータス 2 を受けて即 HALT に到達する。
- **シナリオ 2: BUG #1 → BUG #7 → BUG #6 の連鎖** — 割り込み消失による BDOS エラー → WBOOT → SELDSK が進行中操作を強制リセット → FatFs 状態不整合 → HALT。後述「3.2 最も可能性の高い障害シナリオ」を参照。

**影響**: WBOOT 時のリジェクト発生でシステムが HALT する。

---

### BUG #7 [CRITICAL]: `SELDSK` が AVR 側の進行中ディスク操作を強制リセット

**ファイル**: `avr/src/emuldev/em_diskio.c` (L94-119)

**問題のコード**:

```c
// em_diskio.c L114
cfd->read.state   = IDLE;
cfd->read.result  = FR_OK;
cfd->write.state  = IDLE;
cfd->write.result = FR_OK;
```

`OUT_0A_DSK_SelectDisk()` は I/O 完了確認なしに read/write 状態を IDLE にリセットする。Timer2 ISR で `em_disk_write()` が `f_write()` 実行中であっても、状態だけが IDLE に戻り FatFs オブジェクトが不整合状態になる。

**影響**: FatFs 状態破壊、後続のディスク操作でのエラーまたはデータ破損。

**競合の具体的タイムライン** (BUG #1 起因の WBOOT 発生時):

```text
時刻    Z80 側                    AVR 側
──────────────────────────────────────────────────
T+0ms   Zork I: WRITE 要求       em_disk_write: state=REQUESTING
T+10ms                            Timer2: em_disk_write 開始
                                  state=DOING, f_write() 実行中...
T+12ms  BDOS エラー →
        WBOOT 開始
T+15ms  SELDSK(A:) →
        OUT(PORT_SELDSK)          OUT_0A_DSK_SelectDisk:
                                  write.state = IDLE (★強制リセット!)
                                  ※ f_write() はまだ実行中!
T+16ms  LOAD_CCP_BDOS:
        OUT(PORT_DSKRD)           OUT_13_DSK_Read:
                                  write.state=IDLE → read.state=REQUESTING
T+20ms                            Timer2: em_disk_read 開始
                                  state=REQUESTING → DOING → f_read()
                                  ※ 同じ FIL オブジェクトで f_write() と並行実行!
                                  ※ FatFs は非リエントラント → 破損!
T+25ms                            f_read() エラー or ゴミデータ返却
                                  → 割り込み送信
T+26ms  DISK_READ_SUB:
        ステータス=2(エラー)
        LOAD_CCP_BDOS: OR A → NZ
        → BOOT_ERROR_HALT!        ★ Z80 HALT
```

この競合は `OUT_0A_DSK_SelectDisk()` が `write.state` を強制的に IDLE にリセットする（実際の SD カード書き込みの完了を待たない）ことに起因する。FatFs は非リエントラントであるため、同一の FIL オブジェクトに対する `f_read()` と `f_write()` の並行実行はファイルシステムの状態破壊を引き起こす。

---

### BUG #8 [IMPORTANT]: Timer2 ISR (`ISR_NOBLOCK`) の再入リスク

**ファイル**: `avr/src/isr.c` (L93-99)

**問題のコード**:

```c
// isr.c L93
ISR(TIMER2_COMP_vect, ISR_NOBLOCK)
{
    disk_timerproc();
    em_disk_read();
    em_disk_write();
    em_led_heartbeat(2);
}
```

`ISR_NOBLOCK` により ISR 突入直後に `sei()` が挿入される。SD カード操作が 10ms 以上かかると次の Timer2 割り込みで再入が発生する。状態マシンにより二重処理は抑止されるが、ISR ネストによるスタック消費は蓄積する。

**影響**: AVR スタックオーバーフロー（SRAM 4KB 制約下）。

**具体例**: SD カードが一時的に 100ms の応答遅延を生じた場合、Timer2（10ms 周期）が最大 10 回再入し、各 ISR フレームのスタック消費が蓄積する。ATmega128 の SRAM は 4KB であり、グローバル変数・ヒープと共有するため、スタック余裕は限られる。

---

### BUG #9 [IMPORTANT]: DEBUGGER の HALT が DI 状態で実行される

**ファイル**: `z80/cpm22/bios/bios.asm` (L92-95)

**問題のコード**:

```asm
; bios.asm L92
        LD SP, (SP_ADR)         ; Restore SP
;        EI                      ; ★ コメントアウト
        HALT                    ; Wait for INT 4
        RET                     ; Resume
```

Z80 が DI 状態で HALT に入ると、INT による HALT 解除が不可能。NMI またはリセットでしか復帰できない。`dbg_Continue()` は `Z80_EXTINT_low()` で INT を送るが、DI 状態では Z80 に届かない。

**影響**: デバッガの continue 機能が動作しない。

**到達経路**: RST 7（オペコード 0xFF）により `DEBUGGER` に到達する。BIOS のベクタ設定:

```asm
0x0038: JP DEBUGGER          ; RST 7 ハンドラ
```

通常のコード実行では RST 7 は発生しないが、以下の場合に到達し得る:

1. メモリ破損（DMA 書き込みの不整合、FatFs 競合等）により TPA のコードが破壊され、Z80 の PC が不正なアドレスに飛ぶ
2. メモリ上の 0xFF バイトをオペコードとして実行 → RST 7 → DEBUGGER
3. DI → HALT → **永久停止**（NMI またはリセットでしか復帰不可）

---

### BUG #10 [MODERATE]: `int_level_write`/`int_level_read` に `volatile` がない

**ファイル**: `avr/src/emuldev/em_diskio.c` (L22-23)

**問題のコード**:

```c
// em_diskio.c L22
static uint8_t int_level_write = 128;
static uint8_t int_level_read  = 128;
```

INT1 コンテキスト（OUT ハンドラ `OUT_0F_DSK_WriteIntLevel` / `OUT_14_DSK_ReadIntLevel`）で書き込まれ、Timer2 コンテキスト（`em_disk_read()` / `em_disk_write()`）で読み込まれる。`volatile` がなくコンパイラ最適化でレジスタキャッシュされるリスクがある。

同ファイル内の他の `em_consoleio.c` では `z80_int_num_rx1` / `z80_int_num_tx1` が `volatile` 宣言されており、非対称。

**影響**: コンパイラ最適化条件下で割り込み通知の欠落。

---

### BUG #11 [MODERATE]: `IN_0E_DSK_WriteStatus()`/`IN_13_DSK_ReadStatus()` の `sei()` 問題

**ファイル**: `avr/src/emuldev/em_diskio.c` (L202-223, L468-489)

**問題のコード**:

```c
// em_diskio.c L202
uint8_t IN_0E_DSK_WriteStatus()
{
    cli();
    uint8_t st = 0x00;
    switch (cfd->write.state) {
    ...
    }
    sei();          // ← INT0 ISR コンテキストで sei() を呼ぶ
    return st;
}
```

この関数は INT0 ISR（Z80 IN 命令ハンドラ）から呼ばれる。INT0 ISR は通常 ISR（割り込み無効）であるため、内部の `cli()`/`sei()` は不要であり、かつ `sei()` が ISR 完了前に割り込みを再有効化する。BUG #4 と同じパターン。

**影響**: INT0 ISR 内での予期しない割り込み再有効化。BUG #1 のレース窓を間接的に広げる可能性がある。

---

### BUG #12 [MODERATE]: `Enqueue_RX1_Buf()` — バッファ満杯時のデータロストと偽割り込み

**ファイル**: `avr/src/emuldev/em_consoleio.c` (L43-53)

**問題のコード**:

```c
// em_consoleio.c L43
void Enqueue_RX1_Buf()
{
    while (UCSR1A & _BV(RXC1)) {
        x_enqueue(&cb_rx1, UDR1);          // ← 戻り値を無視
        if (z80_int_num_rx1 < 128) {
            Z80_EXTINT_low(z80_int_num_rx1 << 1);  // ← 失敗時も実行
        }
    }
}
```

**原因**: `cb_rx1` が満杯（8 バイト）のとき、`x_enqueue()` は 3 を返してデータを破棄する。しかし `UDR1` は引数渡しの時点で既に UART レジスタから読み出されており、受信データは失われる。さらに `Z80_EXTINT_low()` が呼ばれ、Z80 に ISR_03（CONIN 通知）が送られるが、新規データはバッファに入っていないため偽の割り込み通知となる。

**影響**:

- 受信文字のロスト。RX バッファが 8 バイトと小さいため、Z80 が CONIN 読み出しに遅延がある場合に発生しうる。
- 偽割り込みが BUG #1 のレース窓を広げる。

**補足 — RX バッファサイズの問題**: `RX1_BUF_SIZE` が 8 バイトしかないため、高速タイピングやペースト操作で Z80 側の CONIN 読み出しが追いつかない場合にバッファ満杯が頻発し、本バグの影響が拡大する。戻り値チェック（偽割り込み防止）に加え、`RX1_BUF_SIZE` を 32〜64 バイトに拡大することでバッファ溢れ自体の発生頻度を低減すべきである。修正方法は Step 6 を参照。

---

### BUG #13 [MODERATE]: `ConsoleBuffer` の `count`/`head`/`tail` に `volatile` がない

**ファイル**: `avr/src/xconsoleio.h`

**問題のコード**:

```c
typedef struct {
    char* buffer;
    int size;
    int head;    // ← volatile なし
    int tail;    // ← volatile なし
    int count;   // ← volatile なし
} ConsoleBuffer;
```

**原因**: `cb_rx1` は USART1_RX ISR（`Enqueue_RX1_Buf` → `x_enqueue`）と INT0 ISR（`IN_00_CONIN` → `x_dequeue`、`IN_01_CONIN_GetStatus` → `count` 直読み）の複数コンテキストから参照される。`cb_tx1` は INT1 ISR（`OUT_05_CONOUT` → `x_enqueue`）と Timer0 ISR（`Transmit_TX1_Buf` → `x_dequeue`）から参照される。

`IN_01_CONIN_GetStatus()` / `IN_06_CONOUT_GetStatus()` は `count` を `cli()` なしで直接読む：

```c
uint8_t IN_01_CONIN_GetStatus() {
    return cb_rx1.count & 0xff;
}
```

`volatile` がないため、コンパイラが `count` をレジスタにキャッシュし、ISR からの更新が反映されない可能性がある。BUG #10（`int_level_read/write`）と同じパターン。

**補足**: 現在のバッファサイズ（8, 128）は 8 ビット幅に収まるが、`count` は `int` 型（16 ビット）であるため、AVR の 8 ビットアーキテクチャでは非アトミック読み出しとなる。現行サイズでは上位バイトが常に 0 のため torn read の実害は出にくい。

**影響**: コンパイラ最適化条件下で、Z80 へのバッファステータス報告が不正確になる。

---

### BUG #14 [LOW]: `USART1_Transmit()` の Timer0 ISR 内ビジーウェイト

**ファイル**: `avr/src/usart.c` (`USART1_Transmit`), `avr/src/emuldev/em_consoleio.c` (`Transmit_TX1_Buf`), `avr/src/isr.c` (Timer0 ISR)

**問題のコード**:

```c
// usart.c
void USART1_Transmit(uint8_t data)
{
    while (!(UCSR1A & _BV(UDRE1)));   // ← UART TX バッファ空き待ち
    UDR1 = data;
}
```

**原因**: `Transmit_TX1_Buf()` は Timer0 ISR（1ms 周期、通常 ISR）から呼ばれ、`USART1_Transmit()` を通じて UART TX バッファ空きをビジーウェイトする。Timer0 は通常 ISR のため、実行中は全割り込みが無効になる。

ATmega128 の USART はダブルバッファリング構造（UDR + シフトレジスタ）を持つため、実際のブロック時間は 1 文字送信時間より大幅に短い。UDR へ書き込まれたデータは前のシフトレジスタ送信完了後にすぐ転送され、UDR が空になる。9600 bps（1 文字 ≈ 1.04ms）で Timer0 周期（1ms）とのずれが蓄積し、約 52 文字に 1 回、~40µs のブロックが発生する。19200 bps では文字送信時間（~0.52ms）が Timer0 周期より十分短いためブロックは発生しない。

| ボーレート | 最大ブロック時間 | 発生頻度 |
|---|---|---|
| 9600 bps  | ~40µs | ~52 文字に 1 回 |
| 19200 bps | 0 | なし |

**影響**: ブロック中は全割り込みが遅延するが、ダブルバッファリングにより実際のブロック時間は短い。ただし ISR 内でのビジーウェイトは原則として避けるべき設計パターンであり、非ブロッキング化が望ましい。

---

### BUG #15 [LOW]: CONOUT フロー制御の閾値ギャップ

**ファイル**: `avr/src/emuldev/em_consoleio.c` (`Transmit_TX1_Buf`), `z80/cpm22/bios/bios.asm` (`CONOUT`)

**問題のコード**:

Z80 CONOUT（bios.asm）:

```asm
CONOUT:
        PUSH AF
        DI
        IN A, (PORT_CONOUT_STS)     ; cb_tx1.count を取得
        CP 64                        ; count >= 64 で待機開始
        JR C, CONOUT2
        XOR A
        LD (IS_CONOUT_FREE), A       ; フラグクリア
        EI
CONOUT1:
        LD A, (IS_CONOUT_FREE)       ; INT 2 通知を待つ
        OR A
        JR Z, CONOUT1
```

AVR Transmit_TX1_Buf（em_consoleio.c）:

```c
if (cb_tx1.count == 0 ||
    cb_tx1.count == cb_tx1.size / 4 ||    //  32
    cb_tx1.count == cb_tx1.size / 2) {    //  64
    Z80_EXTINT_low(z80_int_num_tx1 << 1); // INT 2
}
```

**原因**: Z80 は `count >= 64` で送信待ちに入るが、AVR の通知は `count` が**ちょうど** 0, 32, 64 に一致したときのみ送られる。`count` が 64 から 63 に減少した瞬間には通知が発生しない。Z80 が `count = 64` を読み取り待機に入った場合、`count` が 32 に到達するまで通知を受けられず、32ms（9600 bps 運用時）の不要な待ちが発生する。

**影響**: バースト出力（DIR, TYPE 等）時のスループット低下。インタラクティブ操作（1 文字エコー）では影響軽微。

---

## 3. バグ間の依存関係

```text
BUG #4  ────拡大────→ BUG #1 のレース窓
BUG #11 ────拡大────→ BUG #1 のレース窓
BUG #5  ────拡大────→ BUG #1 のレース窓（軽微）
BUG #12 ────拡大────→ BUG #1 のレース窓（偽割り込み）
BUG #10 ────────────→ 割り込み通知欠落 → BUG #1 と類似の影響
BUG #13 ────────────→ ステータス不正 → BUG #1 と類似の影響

BUG #1  ────────────→ 割り込み消失 → Z80 ポーリング永久滞留
BUG #1  ────連鎖────→ BUG #7 → BUG #6 → HALT（仮説）

BUG #8  ────────────→ AVR スタックオーバーフロー → 未定義動作
BUG #8  ────増幅────→ BUG #2 のデッドロック発生条件（Timer2 再入で cli() 区間に到達）

BUG #2  ────────────→ AVR/Z80 デッドロック

BUG #6  ────────────→ BOOT_ERROR_HALT（直接到達）
BUG #7  ────────────→ FatFs 状態破壊 → BUG #6 のトリガー

BUG #14 ────────────→ ISR 内ビジーウェイト（軽微、ダブルバッファで緩和）
BUG #15 ────────────→ CONOUT スループット低下

BUG #9  ────────────→ デバッガ復帰不能（独立）
```

### 依存グループの整理

**グループ A: 割り込みレース関連**

- 根本: BUG #1
- 窓拡大: BUG #4, BUG #11, BUG #5, BUG #12
- 補足: BUG #10, BUG #13

**グループ B: ディスク I/O 信頼性関連**

- BUG #6（リトライ欠如）
- BUG #7（SELDSK 状態破壊）
- BUG #8（Timer2 再入）

**グループ C: デッドロック関連**

- BUG #2（`cli()` + `ExtMem_attach()`）
- BUG #8 が増幅因子

**グループ D: コンソール I/O 性能関連**

- BUG #14（Timer0 ISR ブロッキング）
- BUG #15（閾値ギャップ）

**グループ E: 独立**

- BUG #9（デバッガ）

### 3.2 最も可能性の高い障害シナリオ

Z80 の `/HALT` ピン（PB7）が LOW になる（Z80 が真の HALT 命令を実行する）最も可能性の高いシナリオを以下に示す。

#### BIOS 内の HALT 命令の所在

| アドレス | コンテキスト | 割り込み状態 | 到達条件 |
|---|---|---|---|
| 0xF292 | DEBUGGER ハンドラ | DI（無効） | RST 7 (0x0038 → JP DEBUGGER) が実行された場合 |
| 0xF436 | BOOT_ERROR_HALT | EI（有効） | LOAD_CCP_BDOS 内の DISK_READ_SUB が失敗した場合 |

BIOS コードに他の HALT 命令は存在しない。CCP/BDOS は標準 CP/M 2.2 であり通常 HALT を含まない。

#### 推定される障害連鎖

```text
 ① BUG #1 (z80_int_vector レースコンディション)
    により DISK I/O 完了割り込みが消失
         ↓
 ② Z80 が WAIT_READ_COMPLETE ビジーループに滞留
    （この時点では HALT ではない）
         ↓
 ③ ユーザーから見るとシステムは無応答
    一定時間後、何らかの割り込みイベントにより
    Z80 が IS_READ_DONE=1 を誤検知するか、
    または BDOS レベルのタイムアウト/エラー発生
         ↓
 ④ BDOS がディスクエラーを検出し、
    ウォームブート(WBOOT)を実行
         ↓
 ⑤ WBOOT → LOAD_CCP_BDOS →
    SELDSK(A:) が AVR 側の進行中操作を強制リセット (BUG #7)
         ↓
 ⑥ DISK_READ_SUB が リジェクト(4) または エラー(2) を返す
    (SD カードの一時的エラー、または FatFs 状態不整合)
         ↓
 ⑦ LOAD_CCP_BDOS にリトライがないため (BUG #6)
    即座に BOOT_ERROR_HALT (0xF436) に到達
         ↓
 ⑧ Z80 が HALT 命令を実行 → /HALT = LOW
    "System HALT due to CCP+BDOS load error." をコンソールに出力
    （バッファリングのため表示が見えない可能性あり）
```

この連鎖は依存関係グラフの `BUG #1 ────連鎖────→ BUG #7 → BUG #6 → HALT` に対応する。BUG #8（Timer2 再入）が AVR スタックオーバーフローを引き起こした場合も、同様の経路で HALT に到達し得る。

#### 代替経路: TPA 内の 0x76 バイト実行

Z80 の PC が何らかの原因（スタック破壊、DMA によるコード領域の部分的上書き等）で不正なアドレスに飛び、メモリ上のデータバイト 0x76（HALT のオペコード）を命令として実行する可能性もある。ただし、Mode 2 割り込みベクタテーブル（0xF300 ページ）の正規ベクタバイトは 0, 2, 4, 6, 8 のいずれかであり、BUG #1 のレースコンディションではこれらの値間の入れ替わりしか発生しないため、不正なアドレスへのジャンプは BUG #1 単独では起きにくい。FatFs 競合によるメモリ破損（BUG #7）が主要な要因と考えられる。

---

## 4. 修正の優先順位

| 優先度 | BUG ID | 修正難易度 | Phase | 根拠 |
|---|---|---|---|---|
| 1 | BUG #4 | 低 | Phase 1 | レース窓を即座に縮小。BUG #1 修正の前提 |
| 2 | BUG #11 | 低 | Phase 1 | BUG #4 と同じパターン。同時に修正可能 |
| 3 | BUG #10 | 低 | Phase 1 | 宣言の修正のみ。割り込み通知欠落を防止 |
| 4 | BUG #13 | 低 | Phase 1 | BUG #10 と同パターン。コンソール側の volatile 追加 |
| 5 | BUG #5 | 低 | Phase 1 | 1 行のガード追加。設計の一貫性を確保 |
| 6 | BUG #12 | 低 | Phase 1 | 戻り値チェック追加。偽割り込み防止 |
| 7 | BUG #6 | 低 | Phase 1 | HALT 到達を直接防止。Z80 側 3 行の追加 |
| 8 | BUG #8 | 低 | Phase 1 | スタックオーバーフロー防止。BUG #2 修正の前提 |
| 9 | BUG #9 | 低 | Phase 1 | コメント解除のみ |
| 10 | BUG #14 | 低 | Phase 1 | ISR 内ビジーウェイト除去 |
| 11 | BUG #15 | 低 | Phase 1 | 通知閾値修正。CONOUT スループット改善 |
| 12 | BUG #1 | 中 | Phase 2 | 割り込み消失の根本対策 |
| 13 | BUG #2 | 中 | Phase 2 | デッドロック防止 |
| 14 | BUG #7 | 高 | Phase 3 | アーキテクチャの見直しを伴う |

---

## 5. 修正ステップ

### Phase 1: 低リスク・独立した修正（Step 1〜11）

Phase 1 の各ステップは互いに独立しており、任意の順で適用可能。ただし Step 5（BUG #5）、Step 7（BUG #14）、Step 8（BUG #15）は同一関数 `Transmit_TX1_Buf()` を修正するため、すべて適用する場合は統合コードを確認すること。

---

#### Step 1: BUG #4 — `x_enqueue()`/`x_dequeue()` の SREG 保存/復元

**対象ファイル**: `avr/src/xconsoleio.c`

**修正方針**: `cli()`/`sei()` を `SREG` 保存/復元に変更し、呼び出し元の割り込み状態を破壊しないようにする。

**現行コード** (L143-161):

```c
int x_enqueue(ConsoleBuffer* cb, char data)
{
    if (cb->count == cb->size) {
        return 3;
    }

    cli();
    cb->buffer[cb->tail] = data;
    cb->tail = (cb->tail + 1) % cb->size;
    cb->count++;
    sei();
    ...
}
```

**修正後コード**:

```c
int x_enqueue(ConsoleBuffer* cb, char data)
{
    if (cb->count == cb->size) {
        return 3;
    }

    uint8_t sreg = SREG;
    cli();
    cb->buffer[cb->tail] = data;
    cb->tail = (cb->tail + 1) % cb->size;
    cb->count++;
    SREG = sreg;
    ...
}
```

**同様に `x_dequeue()`** (L164-176):

```c
char x_dequeue(ConsoleBuffer* cb)
{
    if (cb->count == 0) {
        return '\0';
    }

    uint8_t sreg = SREG;
    cli();
    char data = cb->buffer[cb->head];
    cb->head = (cb->head + 1) % cb->size;
    cb->count--;
    SREG = sreg;
    return data;
}
```

**同様に `x_flush()`** にも同じパターンを適用する。`initConsoleBuffer()` は初期化時のみ呼ばれるため `sei()` のままでもよいが、統一する場合は同様に修正する。

**検証方法**: コンパイル確認。既存動作に影響しないことを確認（通常コンテキストでは `SREG` 復元は事実上 `sei()` と同等）。

---

#### Step 2: BUG #11 — `IN_0E_DSK_WriteStatus()`/`IN_13_DSK_ReadStatus()` の SREG 保存/復元

**対象ファイル**: `avr/src/emuldev/em_diskio.c`

**修正方針**: Step 1 と同じパターンで `cli()`/`sei()` を SREG 保存/復元に変更する。

**修正対象 1** — `IN_0E_DSK_WriteStatus()` (L202-223):

```c
uint8_t IN_0E_DSK_WriteStatus()
{
    uint8_t sreg = SREG;
    cli();
    uint8_t st = 0x00;
    switch (cfd->write.state) {
        case IDLE:
            if (cfd->write.result != FR_OK) {
                st = 0x02;
            }
            break;
        case REQUESTING:
        case DOING:
            st = 0x01;
            break;
        case REJECTED:
            st = 0x04;
            break;
    }
    SREG = sreg;
    return st;
}
```

**修正対象 2** — `IN_13_DSK_ReadStatus()` (L468-489):

```c
uint8_t IN_13_DSK_ReadStatus()
{
    uint8_t sreg = SREG;
    cli();
    uint8_t st = 0x00;
    switch (cfd->read.state) {
    case IDLE:
        if (cfd->read.result != FR_OK) {
            st = 0x02;
        }
        break;
    case REQUESTING:
    case DOING:
        st = 0x01;
        break;
    case REJECTED:
        st = 0x04;
        break;
    }
    SREG = sreg;
    return st;
}
```

**検証方法**: コンパイル確認。

---
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

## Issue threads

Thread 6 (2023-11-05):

Bugfix of PCB Rev1.00

46nori, 2023-11-05:
The local labels `/WR`, `/RD` for ATmega128 conflicted with the Z80's `/WR`, `/RD`, causing unintended connections on the PCB.

Closed 2023-11-05.

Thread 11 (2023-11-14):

SELDSK of CP/M 2.2 BIOS is very slow.

46nori, 2023-11-14:
SELDSK of CP/M 2.2 BIOS is very slow. It causes significant performance reduction at file access across disks.
The root cause is that pf_open() of [Petit FatFS](http://elm-chan.org/fsw/ff/00index_p.html) takes 2 or 3 seconds.

The AVR Firmware DISK I/O emulation function; OUT_0A_DSK_SelectDisk(), calls it.
This function is executed in an interrupt handler that triggers the Z80's OUT instruction, which causes the Z80 to stop completely.

46nori, 2023-12-27:
The microSD FAT File system library is switched fromt 'Petit FatFs' to [FatFs](http://elm-chan.org/fsw/ff/) for supporting multiple file open.
OUT_0A_DSK_SelectDisk() got much faster because the disk image file is switched without open().

Fixed in d1210c628d760994b61eb40249075ff1c59ec8d0

Closed 2023-12-28.

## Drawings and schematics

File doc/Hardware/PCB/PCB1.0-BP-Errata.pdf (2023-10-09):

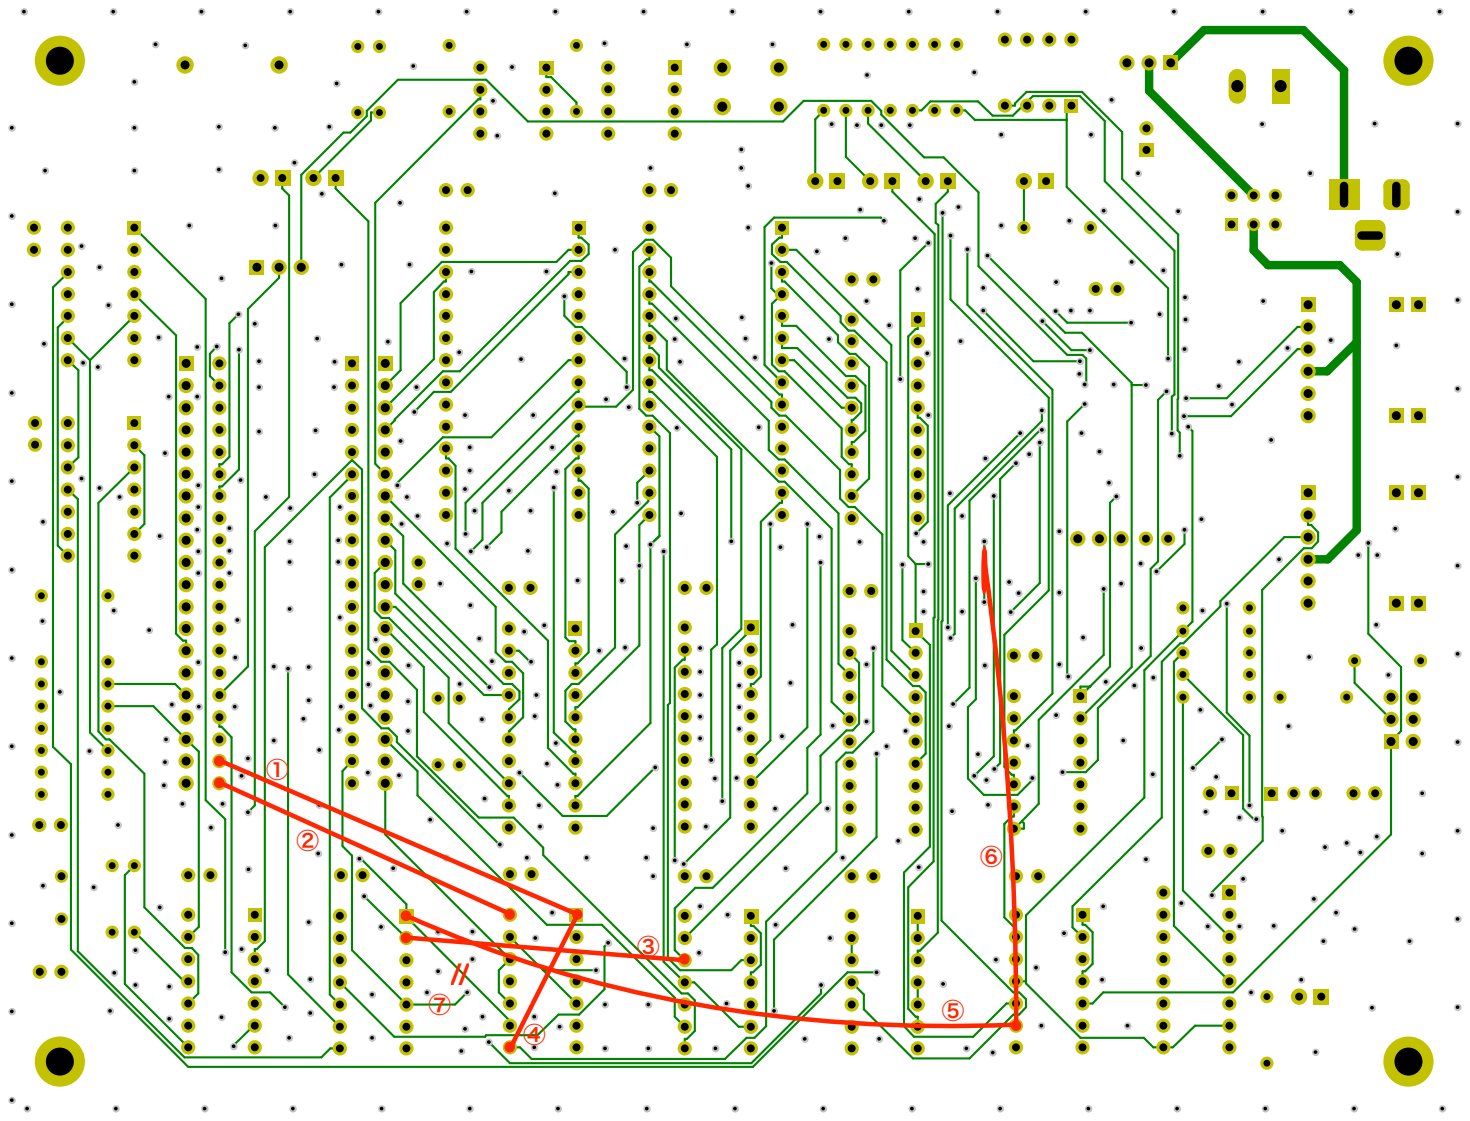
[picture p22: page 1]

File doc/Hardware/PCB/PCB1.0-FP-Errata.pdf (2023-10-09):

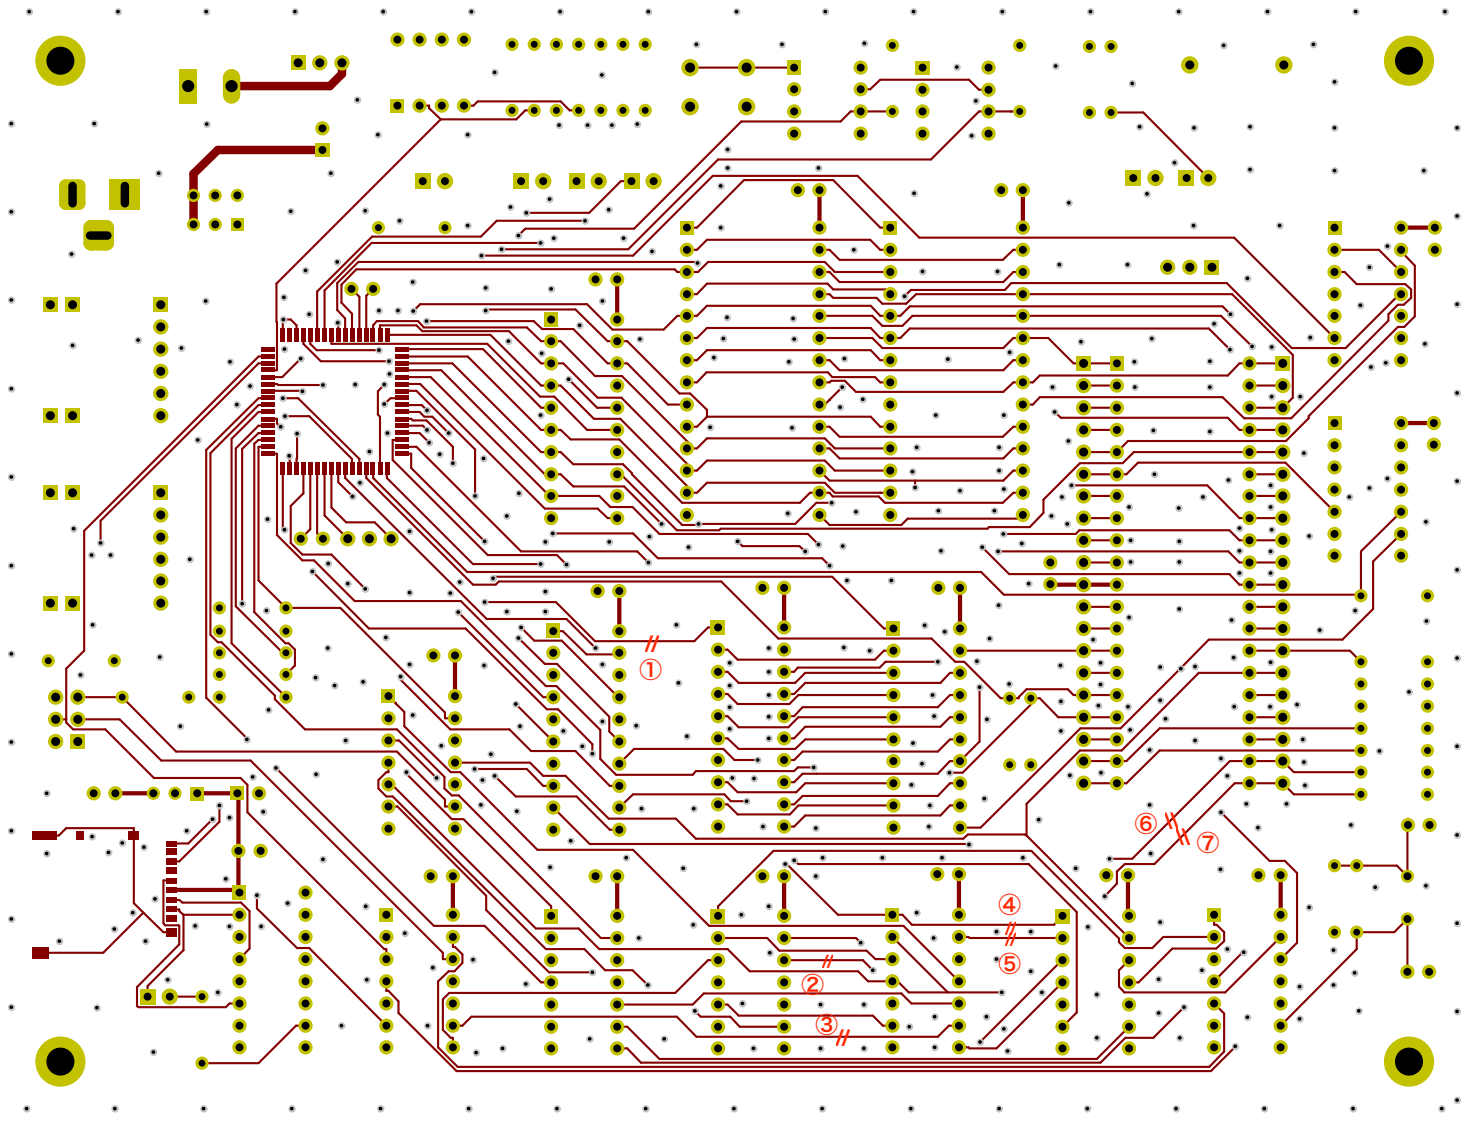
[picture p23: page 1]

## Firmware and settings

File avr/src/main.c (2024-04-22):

/*
 * main.c
 *
 * Created: 2023/03/05 11:29:23
 *  Author: 46nori
 */
#include <asf.h>
#include <avr/eeprom.h>
#include "z80io.h"
#include "usart.h"
#include "timer.h"
#include "isr.h"
#include "xconsoleio.h"
#include "emuldev/emuldev.h"
#include "fatfs/diskio.h"
#include "monitor.h"

int main (void)
{
    // See ASF/common/boards/user_board/init.c
    board_init();

    // DIPSW2(PG4) - UART baud rate
    if (bit_is_clear(PING, PORTG4)) {
        // ON
        USART0_Init(19200);			// UART0 for ATmega128 Monitor
        USART1_Init(19200);			// UART1 for Z80 console
        Timer0_Init(1);				// UART1 console out every 1ms
    } else {
        // OFF
        USART0_Init(9600);			// UART0 for ATmega128 Monitor
        USART1_Init(9600);			// UART1 for Z80 console
        Timer0_Init(2);				// UART1 console out every 2ms
    }

    Timer2_Init(10);				// R/W SD Card every 10ms
    ExtInt_Init();					// Initialize INT0,1,4
    init_emuldev();					// Initialize emulated devices

    sei();							// Enable interrupt

    // Check if DIPSW1(PG3) is ON - CP/M launch control
    if (bit_is_clear(PING, PORTG3)) {
        // Check if SD Card is inserted
        DSTATUS st = disk_status(0);
        if (st & STA_NODISK) {
            x_puts("Insert microSDHC card.");
        } else {
            if (st & STA_PROTECT) {
                x_puts("microSDHC card is WRITE PROTECTED.");
            }
            // Load 62K CP/M BIOS from EEPROM
            const uint16_t *src = 0;
            eeprom_busy_wait();
            uint8_t *dst = (uint8_t *)eeprom_read_word(src++);
            eeprom_busy_wait();
            size_t len = eeprom_read_word(src++);
            load_eeprom_extmem(dst, (const uint8_t *)src, len);
            Z80_RESET_GO(dst);		// Start CP/M
            x_puts("\n=== CP/M mode ===");
            x_printf("BIOS: 0x%04x - 0x%04x\n", dst, dst + len - 1);
        }
    }

    monitor();						// Start Tiny Monitor
}

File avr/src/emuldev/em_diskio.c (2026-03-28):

/*
 * em_diskio.c
 *
 * Created: 2023/06/28 22:31:49
 *  Author: 46nori
 */ 
#include <stdio.h>
#include <string.h>
#include <ctype.h>
#include "em_diskio.h"
#include "fatfs/ff.h"
#include "fatfs/diskio.h"
#include "xconsoleio.h"
#include "z80io.h"

#define DEBUG_PRINT_STATE		0
#define DEBUG_PRINT_OPEN		0
#define DEBUG_PRINT_WR			0
#define DEBUG_PRINT_WR_DATA		0
#define DEBUG_PRINT_RD			0

//=================================================================
// DISK I/O emulated device
//=================================================================
// Disk parameters
static volatile uint8_t int_level_write = 128;
static volatile uint8_t int_level_read  = 128;

static uint8_t tmpbuf[512];

// FatFs
static FATFS file_system;

enum DISKIO_STATUS {IDLE, REQUESTING, DOING, REJECTED};
struct diskio {
	enum DISKIO_STATUS state;
	DWORD	position;
	void	*buffer;
	UINT	length;
	FRESULT	result;
};

struct FD {
	FIL fil;
	FRESULT open_result;
	char name[16];
	struct diskio read;
	struct diskio write;
};

#define MAX_FILES	5			// Max number of disk images (A: - E:)
static struct FD fd[MAX_FILES];	// List of disk image files
static struct FD *cfd;			// Current selected disk image file

///////////////////////////////////////////////////////////////////
// Initialize emulated device
///////////////////////////////////////////////////////////////////
void init_em_diskio(void)
{
	/* Initialize physical drive */
	DSTATUS status = disk_initialize(0);
	if (status == 0) {
		/* Set SPI clock faster after initialization */
		SPSR |= _BV(SPI2X);		// 1/32 With 16MHz F_CPU
	}
	
	/* Mount volume */
	PORTE &= ~_BV(PORTE5);			// BLUE LED ON PE5
	if (f_mount(&file_system, "", 1) != FR_OK) {
		x_puts("SDHC mount error");
	} else {
		/* open all disk images file in advance */
		for (int i = MAX_FILES-1; i >= 0; i--) {
			cfd = &fd[i];
			sprintf(cfd->name, "DISK%02d.IMG", i);
			cfd->open_result = f_open(&cfd->fil, (const char *)&cfd->name, FA_READ | FA_WRITE);
#if DEBUG_PRINT_OPEN
			if (cfd->open_result != FR_OK) {
				x_printf("%s open error : %d\n", cfd->name, cfd->open_result);
			}
#endif
			cfd->read.state   = IDLE;
			cfd->read.result  = FR_OK;
			cfd->write.state  = IDLE;
			cfd->write.result = FR_OK;
		}
		PORTE |= _BV(PORTE5);		// BLUE LED OFF PE5
	}
}

//!!!!!!!!!!!!!!!!!!!!!!!!!!!!!!!!!!!!!!!!!!
// CAUTION: Followings are PROHIBITED here
//  * XMEM external SRAM R/W
//  * invoke /BUSREQ
//!!!!!!!!!!!!!!!!!!!!!!!!!!!!!!!!!!!!!!!!!!

void OUT_0A_DSK_SelectDisk(uint8_t data)
{
#if DEBUG_PRINT_OPEN
	x_printf("###SELSDK: %d\n", data);
#endif
	if (data < MAX_FILES) {
		cfd = &fd[data];
#if DEBUG_PRINT_STATE
		if (cfd->read.state == DOING || cfd->write.state == DOING) {
			x_printf("!!! SELDSK while I/O active: rd=%d wr=%d\n",
			         cfd->read.state, cfd->write.state);
		}
#endif
		// Re-open if previous operation was failure.
		if (cfd->open_result  != FR_OK ||
		    cfd->write.result != FR_OK ||
			cfd->read.result  != FR_OK) {
#if DEBUG_PRINT_OPEN
			x_printf("   Result op:%d/rd:%d/wr:%d\n", cfd->open_result, cfd->read.result, cfd->write.result);
#endif
			f_close(&cfd->fil);
			cfd->open_result = f_open(&cfd->fil, (const char *)&cfd->name, FA_READ | FA_WRITE);
#if DEBUG_PRINT_OPEN
			x_printf("   Re-open: %d\n", cfd->open_result);
#endif
		}
		cfd->read.state   = IDLE;
		cfd->read.result  = FR_OK;
		cfd->write.state  = IDLE;
		cfd->write.result = FR_OK;
	}
}

uint8_t IN_0A_DSK_GetDiskStatus()
{
	if (cfd->open_result != FR_OK) {
		return 1;	// error
	}
	return 0;		// success
}

//
//	Setter/Getter of DISK I/O parameters
//
#define QSTRING(str) #str
#define TEMPLATE_IN_OUT_4BYTES(INTNUM,FUNC) \
static int		st_##FUNC = 0;\
static uint32_t	dt_##FUNC = 0;\
uint8_t IN_##INTNUM##_##FUNC(void)\
{\
	st_##FUNC = 0;\
	return dt_##FUNC;\
}\
void OUT_##INTNUM##_##FUNC(uint8_t data)\
{\
	switch (st_##FUNC) {\
	case 0:\
		dt_##FUNC = (uint32_t)data << 24;\
		st_##FUNC = 1;\
		break;\
	case 1:\
		dt_##FUNC |= (uint32_t)data << 16;\
		st_##FUNC = 2;\
		break;\
	case 2:\
		dt_##FUNC |= (uint32_t)data << 8;\
		st_##FUNC = 3;\
		break;\
	case 3:\
		dt_##FUNC |= data;\
	default:\
		st_##FUNC = 0;\
		/*x_printf("   %s=%08lx\n", QSTRING(FUNC), dt_##FUNC);*/ \
		break;\
	}\
}

#define TEMPLATE_IN_OUT_2BYTES(INTNUM,FUNC) \
static int		st_##FUNC = 0;\
static uint16_t	dt_##FUNC = 0;\
uint8_t IN_##INTNUM##_##FUNC(void)\
{\
	st_##FUNC = 0;\
	return dt_##FUNC;\
}\
void OUT_##INTNUM##_##FUNC(uint8_t data)\
{\
	switch (st_##FUNC) {\
	case 0:\
		dt_##FUNC = (uint16_t)data << 8;\
		st_##FUNC = 1;\
		break;\
	case 1:\
		dt_##FUNC |= data;\
	default:\
		st_##FUNC = 0;\
		/*x_printf("   %s=%04x\n", QSTRING(FUNC), dt_##FUNC);*/ \
		break;\
	}\
}

TEMPLATE_IN_OUT_4BYTES(0B,DSK_WritePos)
TEMPLATE_IN_OUT_2BYTES(0C,DSK_WriteBuf)
TEMPLATE_IN_OUT_2BYTES(0D,DSK_WriteLen)
TEMPLATE_IN_OUT_4BYTES(10,DSK_ReadPos)
TEMPLATE_IN_OUT_2BYTES(11,DSK_ReadBuf)
TEMPLATE_IN_OUT_2BYTES(12,DSK_ReadLen)

///////////////////////////////////////////////////////////////////
// DISK WRITE
///////////////////////////////////////////////////////////////////
uint8_t IN_0E_DSK_WriteStatus()
{
	// CAUTION: don't consume long time
	uint8_t sreg = SREG;
	cli();
	uint8_t st = 0x00;
	switch (cfd->write.state) {
		case IDLE:
			if (cfd->write.result != FR_OK) {
				st = 0x02;		// error
			}
			break;
		case REQUESTING:
		case DOING:
			st = 0x01;			// writing
			break;
		case REJECTED:
			st = 0x04;			// rejected
			break;
	}
	SREG = sreg;
	return st;
}

void OUT_0E_DSK_Write(uint8_t data)
{
#if DEBUG_PRINT_STATE
	x_printf("WRITE:%d->", cfd->write.state);
#endif
	// Reject if READ is on going
	if (cfd->read.state == DOING || cfd->read.state == REQUESTING) {
		cfd->write.state = REJECTED;
	} else {
		switch (cfd->write.state) {
		case IDLE:								// 0
		case REJECTED:							// 3
			cfd->write.buffer   = (void *)dt_DSK_WriteBuf;
			cfd->write.length   = dt_DSK_WriteLen;
			cfd->write.position = dt_DSK_WritePos;
			cfd->write.state    = REQUESTING;	// 1
			break;
		case REQUESTING:						// 1
		case DOING:								// 2
			cfd->write.state = REJECTED;		// 3
			break;
		default:
			break;
		}
	}
#if DEBUG_PRINT_STATE
	x_printf("%d\n", cfd->write.state);
#endif
}

uint8_t IN_0F_DSK_WriteIntlevel(void)
{
	return int_level_write;
}

void OUT_0F_DSK_WriteIntLevel(uint8_t data)
{
	int_level_write = data;
}
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

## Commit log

2023-03-18 Initial schematics
    [Z80ATmega128.kicad_pcb, Z80ATmega128.kicad_sch]
2023-03-22 Explained about Fuse bit setting for external clock.
2023-04-01 Add UART I/O
    x_putchar, x_getcgar and XMODEM are implemented but not debug.
2023-04-01 UART I/O and XMODEM have been tested.
2023-04-03 Add picture of prototype board layout
2023-04-09 Update schematics for Z80 /HALT and /NMI.
    [Z80ATmega128.kicad_pcb, Z80ATmega128.kicad_sch]
2023-04-19 Update schematics.
    Separate reset and SD card interface as different layer.
    Power on/manual reset are isolated from ISP /RST for stability.
    XMEM /RD(PG1) and /WR(PG0) were swapped.
    [Reset.kicad_sch, SD_Card.kicad_sch, Z80ATmega128.kicad_pcb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]
2023-04-29 74HC574 and 245 are changed to 74HCT.
    [Z80ATmega128.kicad_pcb, Z80ATmega128.kicad_sch]
2023-04-30 Verified XMEM interface.
    Bugfix and update tiny monitor.
    Make Z80 halt at reset.
    [init.c, z80io.c]
2023-05-01 Changed USB power line connection.
    [Reset.kicad_sch, SD_Card.kicad_sch, Z80ATmega128.kicad_pcb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]
2023-05-02 Update Reset circuit and Serial interface
    [Reset.kicad_sch, SD_Card.kicad_sch, Z80ATmega128.kicad_pcb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]
2023-05-03 Update schematics.
    [Reset.kicad_sch, SD_Card.kicad_sch, Z80ATmega128.kicad_pcb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]
2023-06-03 Update initial sequence and added debug LED handling.
2023-06-04 Update RESET circuit using DS1232N.
    [Reset.kicad_sch, SD_Card.kicad_sch, Z80ATmega128.kicad_pcb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]
2023-06-04 Update description of RESET circuit
2023-06-06 Added periodic interrupt by Timer0
2023-06-09 Fixed bug of WAIT generator circuit
    Clock circuit is moved to 2nd layer.
    [Reset.kicad_sch, SD_Card.kicad_sch, Z80ATmega128.kicad_sch]
2023-06-19 Setup Z80 cross-assemble environment using Dev Container
2023-06-26 Support buffered I/O for UART1
2023-07-01 Support emulated device
2023-07-01 Added emulated device specification
2023-07-02 Support emulated console I/O device with Z80 Mode2 interrupt.
2023-07-02 Support Timer2 interrupt every 10ms.
2023-07-02 Update development log and Design document regarding Z80 Mode2 interrupt.
2023-07-04 Bugfix of /BUSACK check
    [z80io.c]
2023-07-04 Bug fix of /BUSACK handling during Z80 /RESET is low at power on/manual reset.
    [Reset.kicad_sch, SD_Card.kicad_sch, Z80ATmega128.kicad_sch]
2023-07-08 Reimplemented console I/O emulated device based on updated spec.
2023-07-08 Add LED device and update DISK I/O interrupt of EmulatedDeviceSpec
2023-07-18 Update BIOS and bugfix of /WAIT clear in ISR.
    [em_diskio.c, init.c, isr.c]
2023-07-18 Define /WAIT_0 for IOREAD and INT
    [Reset.kicad_sch, SD_Card.kicad_sch, Z80ATmega128.kicad_sch]
2023-08-13 Fixed the comment about the pull up register of ISP RST.
    [Z80ATmega128.kicad_sch]
2023-08-15 Changed Z80 interrupt handling using HALT, and ZORK I got worked!!!
2023-08-20 Update schematics to support LED and DIP SW.
    [ExtIO_sch.kicad_sch, Reset.kicad_sch, SD_Card.kicad_sch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]
2023-08-20 Trial of new CONOUT scheme (still buggy).
    [isr.c]
2023-08-27 Pull up ISP CLK by 10K ohm resistor.
    [ExtIO_sch.kicad_sch, Reset.kicad_sch, SD_Card.kicad_sch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]
2023-09-14 Update schematics
    [ExtIO_sch.kicad_sch, Reset.kicad_sch, SD_Card.kicad_sch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]
2023-09-15 Swap R4 and R5, Change min_resolved_spokes 2 to 1.
    [Z80ATmega128.kicad_sch]
2023-09-18 Update for PCB design
    [ExtIO_sch.kicad_sch, Reset.kicad_sch, SD_Card.kicad_sch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]
2023-09-22 Update document and BOM of schematics.
    [ExtIO_sch.kicad_sch, Reset.kicad_sch, SD_Card.kicad_sch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]
2023-09-27 PCB Rev1.00
2023-10-01 Bugfix of disk write.
    [em_diskio.c]
2023-10-01 Change the default drive in case of an error in SELDSK..
2023-10-01 Bugfix: lseek to the sector boundary before write disk.
    Also rewind after read before modify and write.
    [em_diskio.c]
2023-10-01 Update schematics and document.
    [ExtIO_sch.kicad_sch, SD_Card.kicad_sch, Z80ATmega128.kicad_sch]
2023-10-04 bugfix of incorrect length in disk write.
    [em_diskio.c]
2023-10-08 Change DIP SW assignment
    DIPSW1: CP/M launch control
    DIPSW2: UART baud rate
    DIPSW3: N/A
    DIPSW4: SRAM wait
2023-10-12 Check if SD Card is inserted in CP/M mode.
2023-10-14 Update schematic and pcb.
2023-10-21 bugfix of disk write
    In the case that the length of the unaligned sector is less than sizeof(tmpbuf) was not considered.
    [em_diskio.c]
2023-10-24 Update PCB, add HW release note
2023-10-26 Update the date of schematics.
    [ExtIO_sch.kicad_sch, Reset.kicad_sch, SD_Card.kicad_sch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]
2023-10-31 Update symbol library setting and property value of schematics diagram.
    [ExtIO_sch.kicad_sch, Z80ATmega128.kicad_sch]
2023-10-31 Update for MountingHole_Pad.
    [ExtIO_sch.kicad_sch]
2023-11-26 Update BOM info and bugfix of PCB2.0
    [ExtIO_sch.kicad_sch, Reset.kicad_sch, SD_Card.kicad_sch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]
2023-12-26 Add mmc_avr sample in ffsample.
2023-12-28 Support error recovery of disk I/O.
    [em_diskio.c]
2023-12-28 Update PCB silk
2026-03-22 BUG #4: Replace cli()/sei() with SREG save/restore in x_enqueue/x_dequeue/x_flush
    Replace unconditional sei() with SREG save/restore pattern in
    x_enqueue(), x_dequeue(), and x_flush() to preserve the caller's
    interrupt state. When called from ISR context, sei() would
    prematurely re-enable interrupts before the ISR completes,
    widening the race window for BUG #1.
    Severity: MODERATE
    Files: avr/src/xconsoleio.c
2026-03-22 BUG #11: Replace cli()/sei() with SREG save/restore in disk status functions
    IN_0E_DSK_WriteStatus() and IN_13_DSK_ReadStatus(). These functions
    are called from INT0 ISR (Z80 IN instruction handler), which is a
    normal ISR with interrupts disabled. The sei() call prematurely
    re-enables interrupts before the ISR completes, same pattern as BUG #4.
    Files: avr/src/emuldev/em_diskio.c
    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
    [em_diskio.c]
2026-03-22 BUG #10: Add volatile to int_level_write/int_level_read
    These variables are written by INT1 ISR (OUT handler) and read by
    Timer2 ISR (em_disk_read/em_disk_write). Without volatile, the
    compiler may cache the values in registers, causing Timer2 to use
    stale interrupt level values and miss interrupt notifications.
    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
    [em_diskio.c]
2026-03-22 BUG #13: Add volatile to ConsoleBuffer head/tail/count fields
    ConsoleBuffer's head, tail, and count fields are accessed from
    multiple ISR contexts (USART1_RX, INT0, INT1, Timer0). Without
    volatile, the compiler may cache these values in registers,
    causing stale buffer status reports to Z80.
    Files: avr/src/xconsoleio.h
    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
2026-03-22 BUG #5: Add z80_int_num_tx1 < 128 guard to Transmit_TX1_Buf()
    Add the same guard check that Enqueue_RX1_Buf() already has, to
    prevent Z80_EXTINT_low() from being called before the interrupt
    number is initialized (z80_int_num_tx1 defaults to 128 until BOOT
    sets it to 2).
    Severity: LOW
    Files: avr/src/emuldev/em_consoleio.c
2026-03-22 BUG #12: Check x_enqueue return value in Enqueue_RX1_Buf and expand RX buffer
    1. Check x_enqueue() return value: when buffer is full (returns 3),
    skip Z80_EXTINT_low() to prevent spurious interrupt notification.
    UDR1 is already consumed at this point so data loss is unavoidable,
    but at least we avoid sending a false CONIN interrupt to Z80.
    2. Increase RX1_BUF_SIZE from 8 to 64 bytes to reduce buffer overflow
    frequency during fast typing or paste operations. SRAM cost: +56 bytes.
    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
2026-03-22 BUG #14: Make Transmit_TX1_Buf() non-blocking
    Replace USART1_Transmit() (busy-wait on UDRE1) with a pre-check of
    UDRE1 flag. If UART TX buffer is busy, skip this Timer0 cycle and
    try again next millisecond. This eliminates ISR-internal busy-wait
    that blocks all interrupts.
    At 9600 bps, approximately 1 in 52 characters will be deferred by
    1ms. At 19200 bps, no change in behavior.
    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
2026-03-22 BUG #15: Fix CONOUT flow control threshold gap
    Z80 CONOUT enters wait state when cb_tx1.count >= 64 (size/2), but
    AVR notification was sent at count == 64 (exactly half). When Z80
    reads count=64 and starts waiting, the notification at count==64
    has already fired. Next notification comes at count==32, causing
    up to 32ms unnecessary wait.
    Change threshold from size/2 (64) to size/2-1 (63) so notification
    fires at the first moment the buffer drops below the Z80 wait
    threshold.
    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
2026-03-22 BUG #8: Add re-entry guard to Timer2 ISR (ISR_NOBLOCK)
    Timer2 ISR uses ISR_NOBLOCK which re-enables interrupts immediately.
    If SD card operations take >10ms, the next Timer2 interrupt causes
    re-entry, accumulating stack frames and risking stack overflow
    (ATmega128 has only 4KB SRAM).
    Add a static volatile bool guard that prevents re-entry of the
    disk I/O and heartbeat sections. disk_timerproc() is kept outside
    the guard to maintain FatFs timer accuracy.
    Severity: IMPORTANT
    Files: avr/src/isr.c
    [isr.c]
2026-03-22 BUG #9: Uncomment EI before HALT in DEBUGGER handler
    With EI commented out, Z80 enters HALT in DI (interrupts disabled)
    state, making it impossible to resume via INT from dbg_Continue().
    Only NMI or reset can recover.
    Uncomment EI so that HALT can be released by the INT 4 interrupt
    sent by the AVR debugger.
    Files: z80/cpm22/bios/bios.asm
    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
2026-03-22 BUG #1: Replace z80_int_vector with FIFO interrupt queue
    - Add ring buffer (8 entries) for interrupt vectors in z80io.c
    - Add Z80_EXTINT_enqueue(): enqueue vector, assert /INT only on
    empty-to-non-empty transition
    - Add Z80_EXTINT_dequeue(): consume from queue, called by INT4 ISR
    - Modify ISR(INT4_vect) to dequeue and re-assert /INT if queue
    has remaining entries
    - Replace all Z80_EXTINT_low() calls with Z80_EXTINT_enqueue() in
    em_consoleio.c (2 sites) and em_diskio.c (4 sites)
    - Keep Z80_EXTINT_low() for debugger (direct send, not queued)
    Root cause fix for interrupt vector overwrites that caused Z80
    to receive wrong vector and miss disk I/O completion notifications.
    [em_diskio.c, isr.c, z80io.c]
2026-03-22 BUG #2: Reorder cli()/ExtMem_attach() in em_diskio.c
    - Move ExtMem_attach() before cli() so bus acquisition happens
    with interrupts enabled (allows INT0/INT1 to be serviced)
    - Limit cli() scope to memcpy only (SREG save/restore pattern)
    - Replace sei() with SREG restore for safer interrupt state handling
    - Applied to all 5 cli/ExtMem_attach blocks:
    - em_disk_write: unaligned head (L339)
    - em_disk_write: aligned blocks (L377)
    - em_disk_write: unaligned tail (L426)
    - em_disk_read: aligned blocks (L564)
    - em_disk_read: remainder (L576)
    Fixes potential deadlock where cli() before ExtMem_attach()
    blocks Z80 I/O interrupts during BUSREQ wait.
    [em_diskio.c]
2026-03-22 BUG #7: Add debug assertion for SELDSK during active I/O
    Add DEBUG_PRINT_STATE conditional check in OUT_0A_DSK_SelectDisk()
    to detect if SELDSK is called while disk I/O is still in DOING state.
    This is an observation-only change (debug log output) to determine
    if BUG #7 manifests after BUG #1 and BUG #8 fixes are applied.
    When DEBUG_PRINT_STATE is set to 1, a warning message is printed
    if read or write state is DOING at SELDSK entry.
    [em_diskio.c]
